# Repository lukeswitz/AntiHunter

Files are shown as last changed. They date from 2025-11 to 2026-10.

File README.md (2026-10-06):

<p align="center">
  AntiHunter Command Center Logo
</p>

<div align="center">





</br>






</div>

<div align="center">
  <h3 align="center">DIGI Detection Node Firmware</h3>
  <h4><a href="https://lectronz.com/stores/antihunter">Get one</a> • <a href="https://lukeswitz.github.io/AntiHunter/">Flash from your browser</a> • <a href="#quick-start">Quick start</a> • <a href="#hardware">DIY</a> • <a href="docs/README.md">Docs</a></h4>
  
  <strong>Companion C2: <a href="https://github.com/TheRealSirHaXalot/AntiHunter-Command-Control-PRO">Command Center</a></strong>

  
  
  [Website](https://rootdowndigital.com/antihunter)  • [Privacy Policy](https://rootdowndigital.com/privacy)

</div>

---

## What is AntiHunter?

***A digital and physical tripwire for your perimeter and RF environment. No subscription, data is yours.***

The name comes from counter-surveillance: phones, trackers, and drones give themselves away by transmitting, and AntiHunter listens for them. It doesn't jam or send attack frames.

Use it at home, on a fence line, at an event, or off the grid on battery and LoRa. It needs no internet, and scan results and detections save to its SD card. One node works on its own. Add more and they share alerts over the mesh, control all at once from the AHCC, and can locate a device together.

<p align="center">
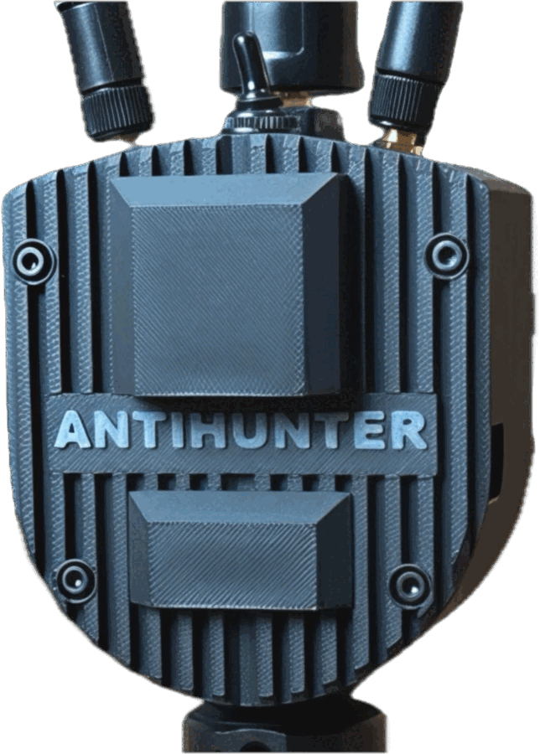
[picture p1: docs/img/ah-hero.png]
AntiHunter node
  
</p>

<p align="center"><i>Featured in Seeed Studio <a href="https://www.seeedstudio.com/blog/2026/01/29/best-xiao-projects/">Best 20 XIAO Projects in 2025</a>.</i></p>

> [!TIP]
> **New to AntiHunter?** [Start Here](docs/README.md) has setup order, decisions, troubleshooting, and every guide and manual.

---

## Table of Contents

1. [Quick start](#quick-start)
2. [What it detects](#what-it-detects)
3. [Using a node](#using-a-node)
4. [Mesh networking](#mesh-networking)
5. [Hardware](#hardware)
6. [Build & flash](#build--flash)
7. [Configuration](#configuration)
8. [System architecture](#system-architecture)
9. [Reference](#reference)
10. [Legal](#license)

---

## Quick start

> The **[Assembly Manual](hw/Prototype_STL_Files/Antihunter-DIGINODE-AssemblyManual.pdf)** covers the full build. The **[Operator's Guide](docs/AntiHunter-Operators-Guide.pdf)** walks through each step in more detail

**1. Attach all three antennas before powering on.**
- SMA or U.FL, see [how to attach depending on tier](#deployment-steps-by-tier)

**2. Flash AntiHunter.**
- Open the [Web Flasher](https://lukeswitz.github.io/AntiHunter/) in Chrome or Edge on a desktop.
- Pick **Full** or **Headless** ([which one?](#full-vs-headless)), pick **Stable** or **Beta**, plug in the ESP32-S3, and select **Connect & Flash**.

The flasher asks whether to erase the device first. Erase to clear saved settings. To flash from a terminal, see [Build & flash](#build--flash).

**3. Connect to the node.**
- Full: join the `Antihunter` Wi-Fi network (password `antihunt3r123`) and open http://192.168.4.1.
- Headless: open a serial monitor at 115200 baud.

**4. Set up the Meshtastic radio.**
- Set the LoRa region, and check the serial settings. See [Radio setup](#radio-setup).

**5. Lock it down.**

- Change the AP name and password under RF Settings. Every unit ships with the same published defaults, so anyone can join an unchanged node.
- Set the node ID in the web UI, or with `CONFIG_NODEID` over mesh.
- On the radio, set the region and a new BLE pairing pin: `python3 scripts/meshtastic_config.py --region US --pin 481920` (use your region and your own 6-digit pin). Then in the Meshtastic app, under Channels, make your own encrypted channel primary and turn the public channel off.
- Set your erase key. Wipe is off until you do. See [Secure data destruction](#secure-data-destruction).
- For covert work, run Headless, which has no access point, and turn off the radio's screen, LED, and Bluetooth with the radio plugged in on its own USB: `python3 scripts/meshtastic_config.py --screen off --led off --ble off`
- Privacy Mode hides MACs, SSIDs, and GPS in the web UI only. Exported logs and SD files still contain them, and GPS coordinates identify places. Check files before posting them.
- Passive reception differs from interception, and the rules differ by country. Scan only where you have authority. See the [legal disclaimer](#legal-disclaimer).

**6. Run a scan.**
Pick a feature from [What it detects](#what-it-detects). Each one shows how to start it.

---

## What it detects

| Feature | What it does | Start it over mesh |
|---|---|---|
| [**Target scan**](#target-scan) | Alerts when the node hears a MAC, vendor prefix, or SSID on the watchlist | `SCAN_START:2:300` |
| [**Baseline anomaly**](#detection-baseline-anomaly) | Learns which devices are normally present, then reports new, gone, returning, and changed ones | `BASELINE_START:300` |
| [**Device discovery**](#recon-device-discovery) | Lists nearby access points and BLE devices with RSSI, channel, and name | `DEVICE_SCAN_START:2:300` |
| [**Probe request scanner**](#recon-probe-request-scanner) | Lists the network names Wi-Fi devices ask for | `PROBE_START:2:300` |
| [**Randomized MAC tracer**](#recon-randomized-mac-tracer-experimental) *(experimental)* | Groups a device's changing MACs into one identity | `RANDOMIZATION_START:2:300` |
| [**Drone Remote ID**](#recon-drone-remote-id) | Drone ID, position, flight data, and operator location | `DRONE_START:300` |
| [**Deauth detection**](#detection-deauth) | Logs deauth and disassociation frames and flags floods | `DEAUTH_START:300` |
| [**Sentinel**](#detection-sentinel-beta) *(Beta)* | Detects Wi-Fi attacks in progress and names the tool when it recognizes one | `SENTINEL_ON` |
| [**CSI motion**](#detection-csi-motion-beta) *(Beta)* | Detects movement from changes in Wi-Fi signals between nearby devices and the node | `CSI_MOTION_START:0:FOREVER` |
| [**Packet capture**](#capture-packet-capture) | Writes Wi-Fi or BLE to SD as a pcap that Wireshark opens | `PCAP_START:0:300:0` |
| [**Triangulation**](#locate-triangulation-experimental) *(experimental)* | Three or more nodes with a GPS fix estimate a device's location from RSSI | `TRIANGULATE_START:<MAC>:60` |
| [**Tamper response**](#field-controls) | Starts a scan, or wipes the node, when someone moves it | `VIBSCAN_SET` |
| [**Scheduling**](#field-controls) | Runs any Scan tab scan at a set time, once or repeating, up to 8 entries | `SCHED_ADD` |

Put `@ALL ` in front of a command for every node, or `@AH01 ` for one node. **(Beta)** features exist only in the Beta firmware. **(experimental)** features exist in every firmware but may give inaccurate results.

> [!NOTE]
> **Shared mesh parameters**
> - Mode: `0` Wi-Fi, `1` BLE, `2` both. Duration is in seconds. Add `:FOREVER` to run until `@ALL STOP`
> - RSSI floor: default −95 dBm, set with `@ALL CONFIG_RSSI:-80`. Baseline uses its own RSSI setting. Triangulation and packet capture ignore the floor
> - Channels: scans that hop use the channel list (`@ALL CONFIG_CHANNELS:1..11`). Drone detection stays on channel 6. Target scan on Full scans all channels

---

### Target scan

Keep a watchlist of MAC addresses (full or vendor prefix) and SSIDs. On each scan pass, the node checks what it heard against the list and alerts on a match, in the web UI and over the mesh.

<p align="center">
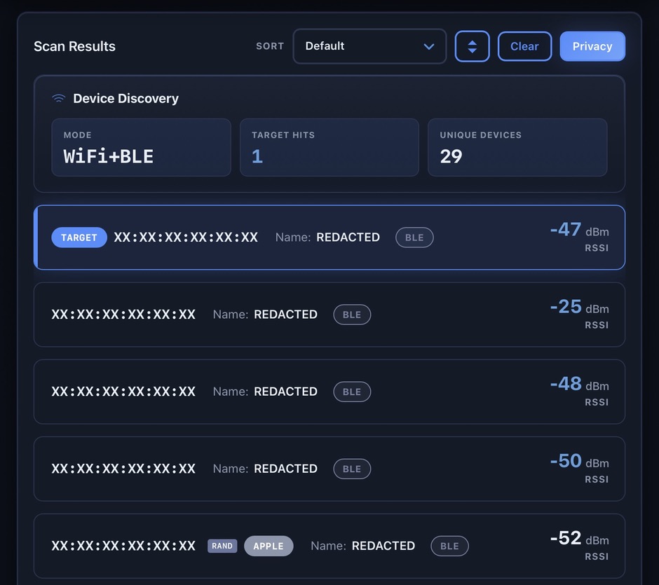
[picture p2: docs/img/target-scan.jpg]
Target Scan
  
</p>

**Start**
- Web UI: add entries under Targets, then Scan tab → Target Scan → **Start Scan**
- Mesh: `@ALL SCAN_START:2:300` scans Wi-Fi + BLE for 300 s
- Mesh: `@ALL CONFIG_TARGETS:AA:BB:CC:DD:EE:FF|T-00A3|MyNetwork` replaces the watchlist with those three entries

**Operational notes**
- Full matches access points (BSSID or SSID) from active Wi-Fi scans, and BLE devices. Headless also sniffs Wi-Fi frames while hopping channels
- It ignores devices on the [allowlist](#field-controls)
- Each hit is logged to SD with radio, MAC, RSSI, channel, name, and GPS
- Each target gets at most one mesh alert per 30 s, unless its RSSI changes by 5 dB or more or the node's GPS position moves

---

### Recon: Device discovery

Lists nearby Wi-Fi access points and BLE devices (up to 200 of each): MAC, SSID, signal strength, name, and channel.

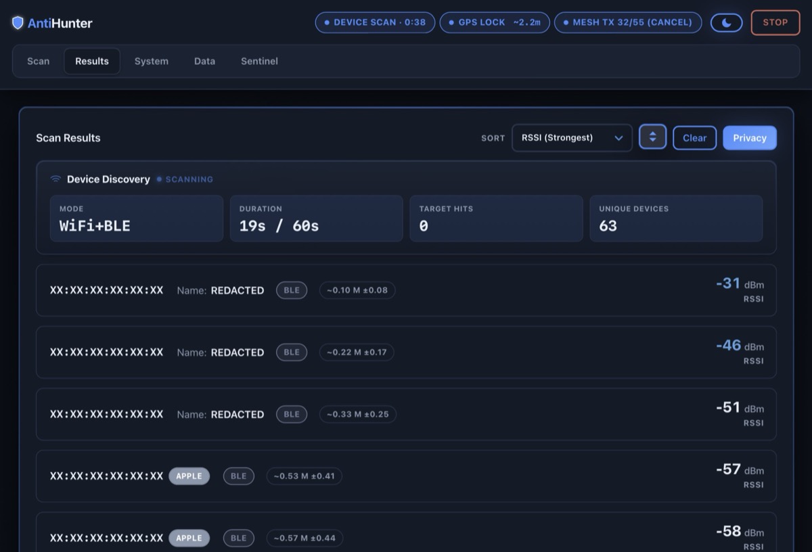
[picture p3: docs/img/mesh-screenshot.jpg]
Mesh scan results


**Start**
- Web UI: Scan tab → Device Discovery → **Start Scan**
- Mesh: `@ALL DEVICE_SCAN_START:2:300:+PROBE` scans Wi-Fi + BLE for 300 s and collects probe requests

**Operational notes**
- It finds access points with a periodic all-channel scan (set by Wi-Fi Scan Interval), and picks up more from beacons while hopping channels between scans
- Tick **Capture Probes** to collect probe requests at the same time. They go into the probe database with MAC, vendor, RSSI, SSIDs, and a randomized-MAC flag
- To skip MACs already sent over the mesh in the last N seconds, use `@ALL CONFIG_DEDUP_TTL:300` (see [Cross-scan dedup](#cross-scan-dedup))

---

### Recon: Probe request scanner

Wi-Fi devices send probe requests that name the networks they want to join. This scanner records the network names each device asks for.

<p align="center">
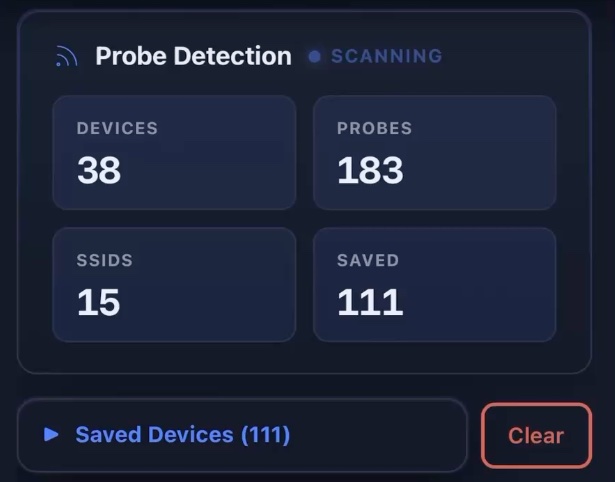
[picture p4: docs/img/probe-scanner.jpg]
Probe Request Scanner
  
</p>

**Start**
- Web UI: Scan tab → Probe Request Scanner → **Start Scan**
- Mesh: `@ALL PROBE_START:2:300:+ALL` runs for 300 s. Stop it with `@ALL PROBE_STOP`

**Operational notes**
- **Ghost SSIDs:** if the node hears no probe response for a network name, it marks the name with a `~` prefix
- **Frames to watchlist devices:** it also flags management frames (other than probes and beacons) addressed to a watchlist MAC
- `+ALL` sends every probe to the mesh. Without it, only watchlist hits go to the mesh. The node keeps every probe locally either way
- Vendor names come from a built-in list of the 400 largest IEEE-registered vendors. Randomized MACs are flagged
- BLE mode adds BLE devices to the list. BLE has no probe requests

---

### Recon: Randomized MAC tracer (experimental)

Modern phones change their MAC address to avoid tracking. The tracer scores how alike two MACs are. It compares MAC prefix, information elements and their order, timing, signal pattern, and sequence numbers. Close matches become one identity with a confidence score and an ID (`T-XXXX`) saved to SD.

<p align="center">
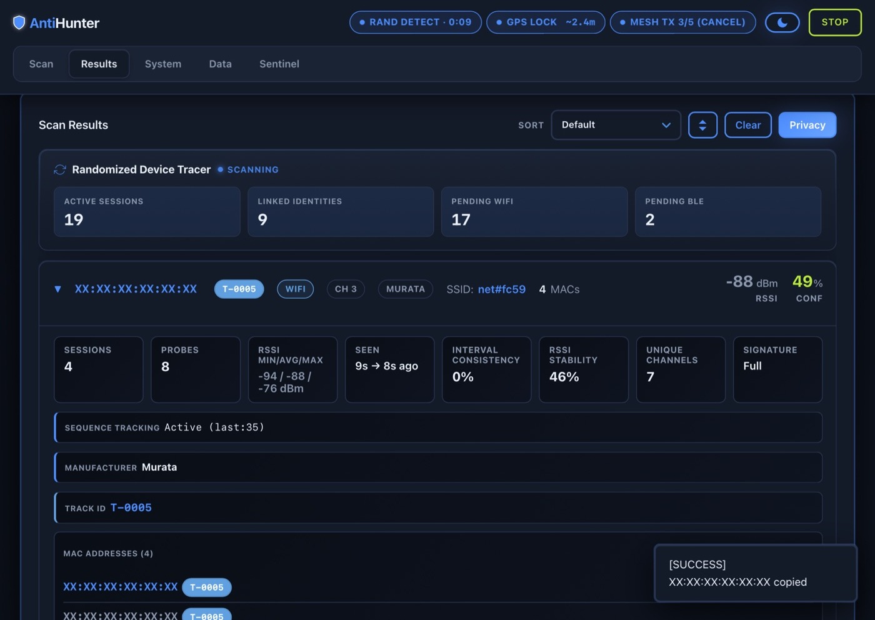
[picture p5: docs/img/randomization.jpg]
Randomized MAC Tracer
  
</p>

**Start**
- Web UI: Scan tab → Randomized MAC Tracer → **Start Scan**
- Mesh: `@ALL RANDOMIZATION_START:2:300` traces Wi-Fi + BLE for 300 s

**Operational notes**
- It tracks up to 256 devices at once. Past that, it drops the one not seen for longest
- It flags devices that also send from their real (global) MAC
- Press the Privacy button to hide MACs, GPS, and SSIDs before taking screenshots

---

### Recon: Drone Remote ID

Detects drones broadcasting Remote ID under the FAA and EASA rules, and reports drone ID, operator location, and flight data to the mesh and to `/drones.jsonl` on SD.

<p align="center">
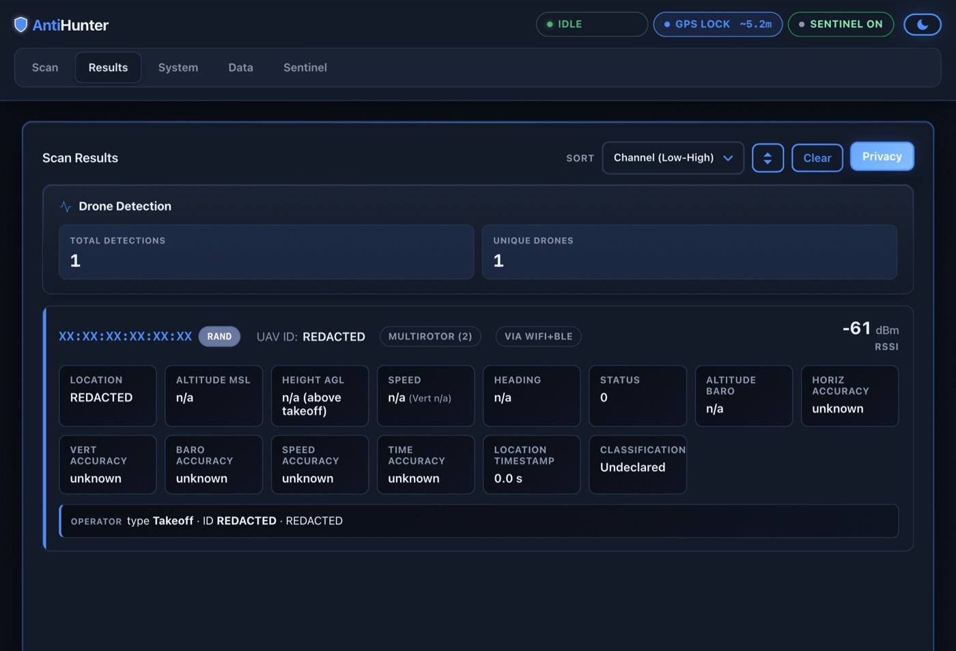
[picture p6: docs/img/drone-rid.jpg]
Drone RID Detection
  
</p>

**Start**
- Web UI: Scan tab → Drone RID Detection → **Start Scan**
- Mesh: `@ALL DRONE_START:300` watches for 300 s. `@ALL DRONE_START:0:FOREVER` runs until `@ALL STOP`

**Operational notes**
- Wi-Fi: ODID/ASTM F3411 in NAN action frames and beacons. The node stays on channel 6 during a drone scan
- BLE: legacy advertising, service UUID `0xFFFA`. BLE 5 long-range advertising isn't received
- It also reads French drone ID
- When a drone sends both a serial number and a CAA registration ID, the node reports the serial number

---

### Detection: Baseline anomaly

Learns which access points and BLE devices are normally present, then reports devices that are new, gone, back again, or whose signal changed by more than the RSSI variation setting (default 20 dB).

<p align="center">
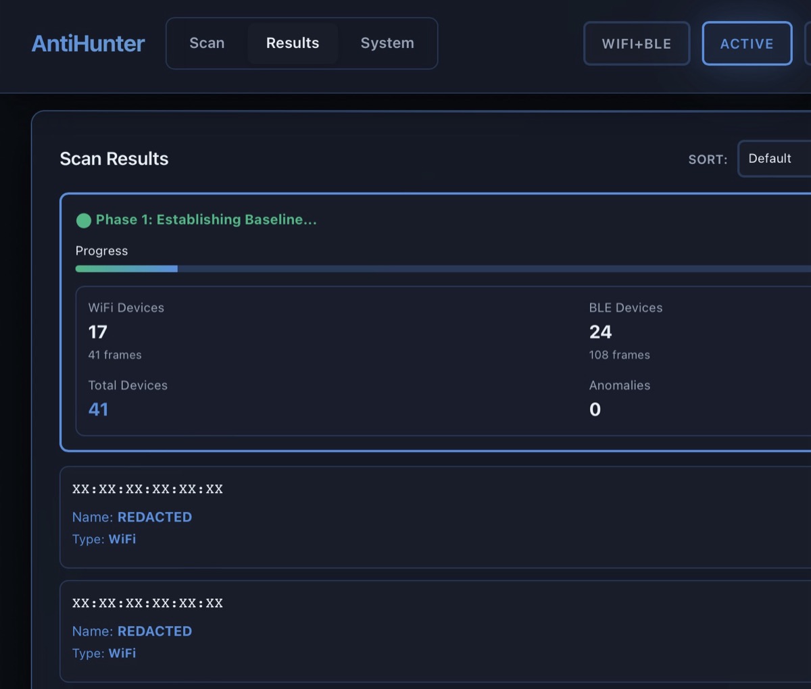
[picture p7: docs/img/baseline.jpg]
Baseline Anomaly Detection

</p>

**Start**
- Web UI: Scan tab → Baseline Anomaly Sniffer → pick the learning time (5, 10, or 15 min) → **Start Scan**
- Mesh: `@ALL BASELINE_START:300` monitors for 300 s after the learning phase. The learning time comes from the web UI setting (default 5 min)
- Check progress: `@ALL BASELINE_STATUS`

**Operational notes**
- **Watch for changes from now** - splits the learning phase into before and after a moment you pick. Send it while the node is still learning: press **Watch for changes from now** (Full), or send `@ALL BASELINE_WATCH`. The node replies `BASELINE_ACK:WATCHING`, or `BASELINE_ACK:NOT_RUNNING` if no baseline scan is running

  | Result | Meaning |
  |--------|---------|
  | New | Heard only after you pressed it |
  | Gone | Heard only before |
  | Moving closer / away | Heard both times, signal changed by 20 dB or more |

  Full shows it in Results. Headless prints the list to serial when the scan ends and sends `BASELINE_WATCH: New=<n> Gone=<n> Moved=<n> Both=<n>` over mesh
- With an SD card, the baseline survives a reboot. Recent devices stay in memory, and the node moves the rest to SD
- Baseline uses its own RSSI threshold (default −60 dBm), not the global RSSI floor

---

### Detection: Deauth

Watches for deauthentication and disassociation frames, which knock devices off Wi-Fi.

**Start**
- Web UI: Scan tab → Deauth Detection → **Start Scan**
- Mesh: `@ALL DEAUTH_START:300` watches for 300 s

**Operational notes**
- It alerts on any broadcast deauth, and on 10 deauths to one client within 10 s, tagged `[BROADCAST]` or `[TARGETED]`
- It flags a `DEAUTH_FLOOD` at 20 deauths from one source within 10 s
- Each alert shows the source and destination written in the frame, RSSI, channel, and reason code. An attacker can fake the source address

---

### Detection: Sentinel (Beta)

> [!IMPORTANT]
> To use Sentinel, flash the **Beta** firmware.

Once you start it, Sentinel listens for Wi-Fi attack frames in the background and pauses while another scan runs. It matches frame patterns and behavior, such as deauth floods, beacon spam, evil twin APs, PMKID requests, and someone knocking a client off to force a WPA handshake.

**Tools it names:** Marauder, MDK4, ESP Deauther, aireplay-ng, bettercap, hcxdumptool, Bruce, Pwnagotchi

<p align="center">
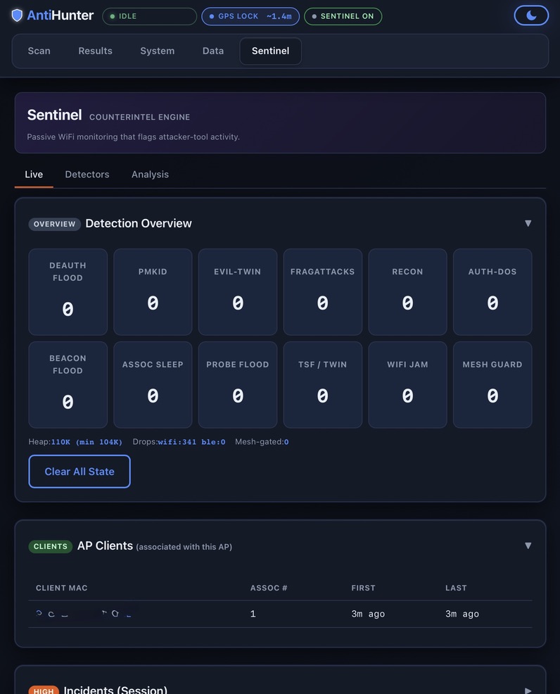
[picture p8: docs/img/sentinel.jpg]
Sentinel
  
</p>

**Start**
- Web UI: Sentinel tab → Start
- Mesh: `@ALL SENTINEL_ON` / `@ALL SENTINEL_OFF`
- Start at power-on: `@ALL SENTINEL_BOOT:1`, or set it in the Flasher or Configurator. Off by default

**Settings**
- Turn a detector group on or off: `@ALL GROUP:dos:on` (`dos`, `rogue`, `recon`, `physical`, `mesh`, `all`). Deauth, beacon flood, and auth flood detection are always on
- Hop channels or stay on one: `@ALL SENTINEL_MODE:scan` or `:defend`. Headless has no AP to stay on, so use `scan`
- Fine-tune: `@AH01 DETECT_CFG:{"pmkid":true}`
- The Web Flasher's **Sentinel & Detectors** section sets the same options at flash time. Anything left on *Default* keeps the firmware setting

**Operational notes**
- Sentinel writes each detection to serial and SD. With the mesh on and that detector's broadcast flag set, it also sends it to other nodes, rate-limited
- When Sentinel confirms an attack, it can start a follow-up: triangulate, packet capture, device discovery, probe sweep, or drone RID. They run one at a time, and detection pauses while they do
- Karma bait is the only detector that transmits. While on, it sends one bait probe request every 8 s, plus one when a suspect AP is first seen. Off by default. Turn it on with `GROUP:rogue:on`
- Per-detector logs on SD start fresh at each boot so counts begin at zero. The full history stays in `/incidents.jsonl`

<details>
<summary>Detectors, outputs, and test coverage</summary>

| Group | Detectors | How they're caught |
|---|---|---|
| **DoS** | Deauth flood, deauth forge, broadcast deauth, AP-targeted deauth, beacon flood, auth flood, assoc-sleep, SAE DoS | Fixed Marauder seqCtrl, reason 7 with duration 0x013A, sawtooth sequence numbers, alternating deauth/disassoc, and deauth rate. Impersonation bursts. 40+ distinct nearby BSSIDs beaconing within 10 s, plus known static beacon templates. Open-system auth flood. Assoc-req PM-bit floods. SAE commit floods (algo 3 / txn 1). Reasons 1/2/6/7 alone never alert. Reason 14, or reason 2 with fixed seqCtrl 0xFFF0, alerts on its own |
| **Rogue AP** | Evil-twin, OWE abuse, Karma / MANA | Another BSSID beaconing the node's own SSID. A new-vendor BSSID reusing a learned SSID. TSF restarts and known beacon-forgery templates. OWE-transition downgrade. Bait probe answered by an AP that never beacons that SSID |
| **Recon** | PMKID harvest, probe flood, forced handshake | Orphaned-M1 / KDE PMKID solicitation. Probes with fixed seq 0x0001, 40+ distinct MACs probing one SSID within 5 s, or probe-rate floods. A WPA 4-way handshake completed right after a deauth burst, meaning someone knocked a client off to capture it. Sentinel ignores handshakes without a deauth burst |
| **Physical** | FragAttacks, TSF / multi-channel twin, Wi-Fi interference | Fragment packet-number gaps and mixed encrypted/plaintext fragments (CVE-2020-26146/26147, off by default). Same BSSID on ≥2 channels within 5s. Per-channel PDR-vs-RSSI collapse (CRC-fail flood) |
| **Mesh disruption** | Self-spoof, channel flood, command audit | Own node-id seen inbound. Inbound rate DoS. Logs every inbound mesh command (lines starting with `@`) with the radio id that sent it, even when this detector is off. The log is an **audit trail**, not an alert: on a shared channel an injected command looks like a normal one, so the node records the source |

- **Phone hotspots:** the crypto and beacon detectors skip locally administered BSSIDs, which phone hotspots use. Flood detectors don't, because real floods spoof them
- **Output:** `[DETECT]` serial lines, `.jsonl` files on SD (some detectors share a file), `/incidents.jsonl`, and a mesh broadcast so other nodes can confirm
- **AP clients:** devices that join the node's own AP, with MAC, join count, and first/last seen. *AP Clients* panel, `GET /api/apclients.json`
- **Mesh command audit:** every incoming command and its sender, including commands meant for other nodes. *Mesh Commands* panel, `GET /api/mesh_cmd.jsonl`
- **Mesh labels:** the [mesh command reference](docs/mesh-commands.md) lists the labels Sentinel sends, for log parsers and C2, under *Sentinel label reference*
- **Tested against:** airgeddon, aireplay-ng, bettercap, wifite, mdk4, angryoxide, eaphammer, hostapd-mana, wifipumpkin3, hcxdumptool, purpose-built test scripts, and common consumer ESP32 attack firmware
- **Confirmed on hardware** against those tools: deauth (flood/forge/AP-targeted), beacon flood, auth flood, assoc-sleep, SAE DoS, karma, evil-twin, probe flood, forced handshake
- **Experimental:** OWE abuse, PMKID harvest, FragAttacks, TSF multi-channel twin, Wi-Fi interference, mesh disruption
- **Behavioral fallbacks** (still work when a tool changes its frame template): SSID-rotate forge, behavioral probe-flood, EAPOL-capture bait, broadcast deauth bursts

</details>

---

### Detection: CSI motion (Beta)

Tells you when something moves nearby, even through walls. The web UI marks it as indoor only. It triggers on changes in the Wi-Fi signal, not on presence.

<p align="center">
  CSI Motion
</p>

**How it works.** Wi-Fi signals bounce around a room. When a person moves, the bounces change. The node listens to the Wi-Fi routers around it, plus phones if you include randomized-MAC devices. It alerts when their signals change together, as set by the sensitivity below. It needs ongoing Wi-Fi traffic to measure.

**Start**
- Web UI: Scan tab → CSI Motion Detection → **Start Scan**
- Mesh: `@ALL CSI_MOTION_START:0:FOREVER`. The [mesh command reference](docs/mesh-commands.md) lists the CSI commands

**Pick a sensitivity**
- **Low** (default): fewest false alarms. Two devices must see the movement.
- **Medium**: more sensitive. Two devices, or one device seeing a change 4× the trigger.
- **High**: most sensitive. Same as Medium with a lower trigger and a shorter wait. Expect false alarms.

<details>
<summary>All CSI settings (Scan tab → CSI Motion Detection)</summary>

**Sensitivity** and the mesh alert limit sit at the top. The rest are under **Advanced**.

| Setting | What it means | Default |
|---|---|---|
| Min. seconds between mesh motion alerts | Wait at least this long between motion alerts sent over mesh. 0 sends every alert | 0 |
| Channel | Wi-Fi channel to listen on. 0 picks one automatically | 0 |
| Movement needed before alerting | Seconds of movement within the last minute before an alert | 8 s |
| Stillness before all-clear | Seconds a single device's signal must stay quiet before it stops counting as moving. The room all-clear comes later | 5 s |
| Devices that must agree | How many devices must see the movement at the same time | 2 |
| Trigger level | Lower catches smaller movement | set by sensitivity |
| Packets in a row before alerting | Consecutive readings above the trigger before a device counts as moving | 3 |
| Listen only, never transmit | The node never sends probes. Turn off only if it sees too little Wi-Fi | On |
| Include randomized-MAC devices | Also listen to phones and watches, not just routers | On |

</details>

**False alarms with nobody there?** Turn on **Per-packet score to serial**, watch the `sig` numbers while the room is empty, and set Trigger level just above the highest one.

> [!WARNING]
> **This mode can transmit if you let it.** Off by default. If you turn off **Listen only, never transmit**, the node sends Wi-Fi probe requests when it hears too little traffic to measure. Anyone nearby can see them. Check local rules before turning it on.

---

### Capture: Packet capture

Records raw traffic to SD as a standard pcap that Wireshark opens.

<p align="center">
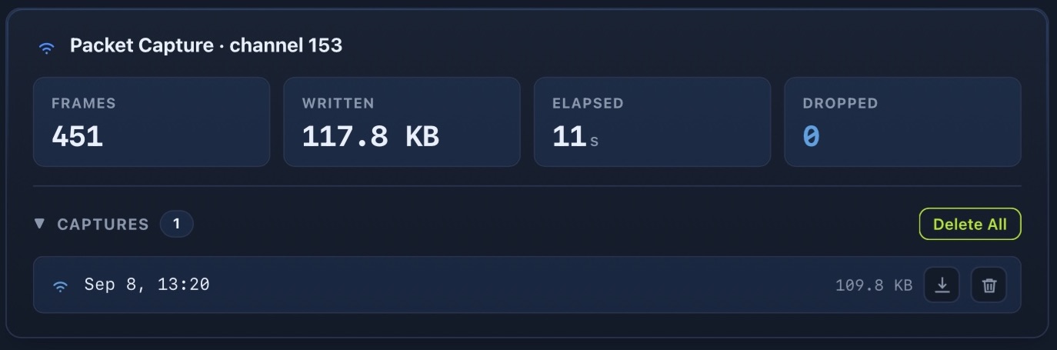
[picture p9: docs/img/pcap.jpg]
Packet capture
  
</p>

**Start**
- Web UI: Scan tab → Packet Capture → **Start Capture**
- Mesh: `@ALL PCAP_START:0:300:0:CH1,6,11` captures Wi-Fi for 300 s on 2.4 GHz channels 1, 6, and 11
- Fields, in order: radio (`0` Wi-Fi, `1` BLE), duration in seconds (required, no `FOREVER`), band (`0` 2.4 GHz, `1` 5 GHz, `2` both; 5 GHz on C5 only), and an optional `:CH` list
- Stop: `@ALL PCAP_STOP` stops the capture and any other running scan. File size cap: `@ALL PCAP_LIMITS:150` (8-300 MB)

**Operational notes**
- Wi-Fi frames carry a radiotap header with channel and RSSI, plus the rate on legacy frames and the MCS index on 802.11n frames. Both bands on C5
- BLE saves the raw HCI events the Bluetooth controller reports, link type 187. HCI has no RF channel field, so the capture shows no channel
- It sweeps the RF Settings channels, or a channel list and dwell set under Advanced. There's an optional management-frames-only filter
- The Scan tab lists captures to download or delete. You can't delete the file in progress
- A Sentinel attack response can also start a capture. The node prunes automatic (`auto_`) captures to stay under a size budget and keep free space. It never prunes manual ones

> [!WARNING]
> Stop a capture before cutting power. The node flushes the file as it writes, but cutting power mid-write can leave it truncated.

---

### Locate: Triangulation (experimental)

Nodes listen for the same device at once. Each records RSSI and its own GPS position, and the mesh combines the results (weighted trilateration with Kalman filtering) into a location estimate. A position needs at least three nodes with a GPS fix. With two, the results only compare GPS distance with RSSI.

**Start**
- Mesh: `@AH01 TRIANGULATE_START:AA:BB:CC:DD:EE:FF:60`. AH01 coordinates a 60 s run for that MAC with the other nodes on the mesh
- Optional `:rfEnv` picks the environment from the table below (`0` Open Sky to `4` Industrial). Optional `:wifiPwr:blePwr` are distance multipliers (0.1 to 5.0)
- Result: `@AH01 TRIANGULATE_RESULTS`. Stop: `@ALL TRIANGULATE_STOP`

**Operational notes**
- It reports GPS coordinates, confidence, estimated error in meters, and average HDOP, and sends a Google Maps link over the mesh
- It ignores readings of −95 dBm or weaker

<details>
<summary>RF environment calibration</summary>

Path loss model: `distance = 10^((RSSI0 - RSSI) / (10 * n))`

| Environment | Wi-Fi n | BLE n | Wi-Fi RSSI0 | BLE RSSI0 | Use Case |
|---|---|---|---|---|---|
| Open Sky | 2.0 | 2.0 | -23 dBm | -60 dBm | Clear LOS, minimal obstruction |
| Suburban | 2.7 | 2.5 | -24 dBm | -62 dBm | Light foliage, scattered buildings |
| Indoor | 3.2 | 2.9 | -25 dBm | -65 dBm | Typical indoor, some walls |
| Indoor Dense | 4.0 | 3.5 | -27 dBm | -69 dBm | Office spaces, many partitions |
| Industrial | 4.8 | 4.0 | -30 dBm | -73 dBm | Heavy obstruction, machinery |

</details>

---

## Using a node

### Full vs Headless

Both builds share the detectors and scan engine. Full adds a Wi-Fi access point with the web UI and [API](docs/api-reference.md). Headless never starts the access point.

| | Full | Headless |
|---|---|---|
| Control | Web UI and API over its own AP, plus serial and mesh | Serial and mesh |
| Wi-Fi discovery | Active all-channel sweep plus promiscuous capture on Device Scan, Target Scan, Baseline, and Triangulation | Same sweep, without Full's handling for clients joined to its AP |
| Results | Results tab in the browser, saved to `/last_results.txt` on SD | `/last_results.txt` on SD |
| Device database | `/devicedb.jsonl` | `/devicedb.jsonl` on Beta, not in Stable |
| Scheduling | Scan tab and `SCHED_ADD` | Not available |
| Fleet roster | Fleet card on the System tab, and `/api/mesh` | Not tracked |
| RF footprint | AP beacons, unless hidden-network is on | No AP |

### Web UI

The web UI has four tabs: **Scan**, **Results**, **System**, and **Data** (plus **Sentinel** on Beta). On the Scan tab, pick the scan, the radio, and how long, then select **Start Scan**. Results show on the Results tab and save to SD. **Schedule this scan** runs the current scan at a set time.

<p align="center">
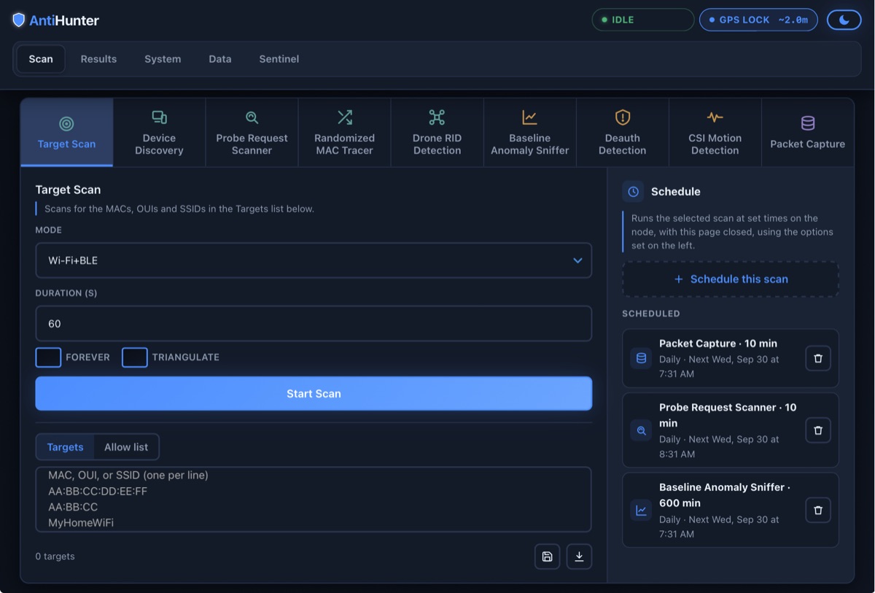
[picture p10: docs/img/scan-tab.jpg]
AntiHunter Scan tab

</p>

The **System** tab holds the node-wide settings. Its **Fleet** card lists the nodes and mesh radios this node has heard. The **Data** tab is the Data Explorer for findings, device logs, and scan data.

<details>
<summary>System tab cards and screenshots</summary>

<p align="center">
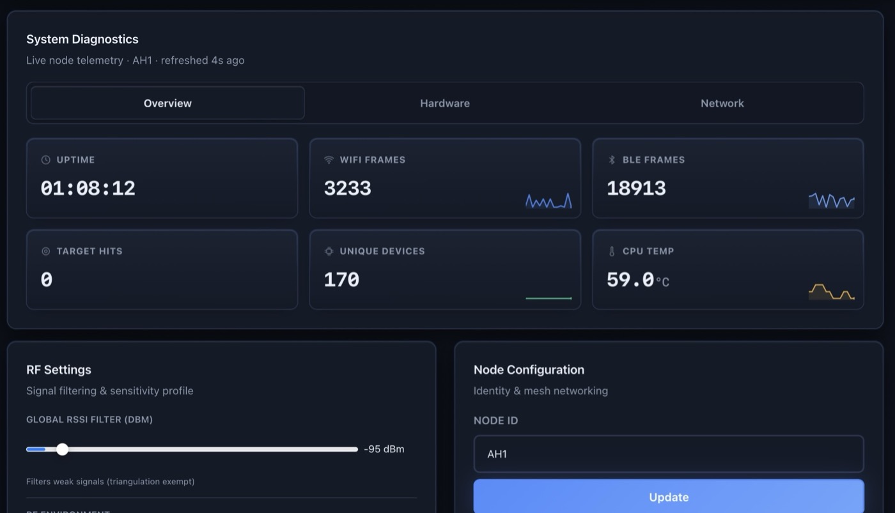
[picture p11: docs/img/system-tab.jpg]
System tab
  
</p>

| Card | What it holds |
|---|---|
| **System Diagnostics** | Three subtabs, all fed from `GET /diag`. **Overview** - uptime, Wi-Fi and BLE frame counts, target hits, unique devices, CPU temperature. **Hardware** - last reset and previous uptime, results restored, free and minimum-free internal heap, scan stack headroom, SD card, GPS, RTC, and vibration sensor. **Network** - AP address, mesh state, Wi-Fi channels |
| **Fleet** | Live roster of nodes and radios with mode, uptime, temperature, hits, and GPS. Ping the fleet or clear the list |
| **RF Settings** | Global RSSI filter and RF environment (Open Sky to Industrial, used for distance estimates). Scan preset (Relaxed, Balanced, Aggressive, Custom). Wi-Fi channel dwell, scan interval, and channel list. BLE scan duration and interval. Also holds the **Wi-Fi Access Point** section: SSID, password, WPA2/WPA3 or WPA2 only, and hidden network |
| **Node Configuration** | Node ID, mesh on/off, status heartbeat, mesh send interval, mesh dedup TTL, and session dedup |
| **Sensor Alerts** | Vibration sensing and what it triggers |
| **Secure Data Destruction** | Erase key, setup and erase delays, vibration count and window, cooldown |
| **Factory Wipe** | Clears settings and stored data back to defaults |
| **Battery Saver Mode** | Stops scans and turns BLE off, drops the CPU to 80 MHz with light sleep, and polls GPS once a minute. Mesh commands, heartbeats, and vibration alerts keep working |
| **Accent Colors** | Recolors the destructive controls and Sentinel banners. Stored in the browser |

Settings

<p align="center">
 Fleet viewer
</p>

</details>

### Field controls

- **Allowlist** - devices that Target Scan and Baseline ignore. Scan tab → **Allow list** tab next to Targets, one MAC per line.
- **Privacy Mode** - the Privacy button (Results, System, and Data tabs) hides MACs, GPS, and SSIDs in the web UI for screenshots. Exported files keep them.
- **Vibration trigger** - starts a scan when the node is moved. Full: System tab → Sensor Alerts. Both builds, over mesh, `VIBSCAN_SET:<on>:<scan>:<secs>:<cooldown>`:

  | Part | Value |
  |------|-------|
  | on | `1` on, `0` off |
  | scan | `1` device discovery, `2` probe, `3` randomized MAC tracer, `4` target, `5` drone, `6` deauth, `7` baseline, `8` packet capture |
  | secs | Scan length in seconds. `0` runs until `STOP` |
  | cooldown | Seconds to wait before the next trigger, 5-86400 |

  Examples:
  - `@AH01 VIBSCAN_SET:1:2:60:300` - probe scan for 60 s when moved, then at most once per 5 min
  - `@AH01 VIBSCAN_SET:0:0:0` - turns it off
- **Scheduled scans** - Full: Scan tab → **Schedule this scan**. Both builds, over mesh, `SCHED_ADD:<start>|<repeat>|<scan>|<options>`:

  | Part | Value |
  |------|-------|
  | start | Node local time, `YYYY-MM-DDTHH:MM` |
  | repeat | Seconds between runs. `0` = once, `86400` = daily. Minimum `600` |
  | scan | `/scan` (list scan), `/sniffer` (device discovery), `/drone` |
  | options | `secs=<duration>`, plus `mode=0` Wi-Fi, `1` BLE, `2` both for `/scan` |

  Examples:
  - `@AH01 SCHED_ADD:2026-10-07T21:00|86400|/scan|mode=2&secs=600` - Wi-Fi + BLE list scan, 10 min, daily at 21:00
  - `@AH01 SCHED_ADD:2026-10-07T06:00|0|/drone|secs=300` - drone scan once, 5 min
  - `@AH01 SCHED_LIST` - replies with the count, prints entries to serial
  - `@AH01 SCHED_DEL:1` - deletes entry 1

  Headless runs entries only once its clock is set, from GPS or `SETTIME:<unix seconds>` on USB serial.
- **Battery Saver** - stops Wi-Fi/BLE scanning, drops the CPU to 80 MHz, enables light sleep, and polls GPS once a minute. The mesh stays connected and sends a heartbeat. `@AH01 BATTERY_SAVER_START:10` starts it with a heartbeat every 10 min (1-30), `@AH01 BATTERY_SAVER_STOP` ends it.
- **Hidden SoftAP** - the access point stops broadcasting its name. It doesn't keep anyone out. System → RF Settings → Wi-Fi Access Point → **Hidden network**.
- **SD Repair** - lets the node rebuild an SD card it can't mount. Off by default, and rebuilding erases the card. System tab, or over mesh: `@AH01 SD_REPAIR:ON`, `:OFF`, or `:NOW` to rebuild immediately.

The [mesh command reference](docs/mesh-commands.md) lists every parameter.

### Secure data destruction

Wipe the node's data if someone moves it, or on command.

Wipe is off until you set your own erase key (8+ characters, no `:`).

**Set your key**
- Full: System → Secure Data Destruction. The current key is your AP password (change the default first). Or over mesh: `@AH01 CONFIG_ERASE_PSK:<new key>:<AP password>`
- Headless: the **Erase key** field in the web flasher

**Wipe**
- Web UI: enter your key, press **WIPE NOW**
- Mesh: `@AH01 ERASE_FORCE:<your key>`

**Change your key:** `@AH01 CONFIG_ERASE_PSK:<new key>:<current key>`

5 wrong keys lock erase commands for 10 minutes. The key travels over your mesh channel, so use your own encrypted channel.

- **Auto-erase on tamper:** off by default. After the setup delay, **Vibrations required** vibrations within the **Detection window** start the erase countdown. Cancel with `@AH01 ERASE_CANCEL:<your key>`
- **Decoy file:** after the wipe, the node erases its settings and SD files, then writes `/weather-air-feed.txt` with a weather-monitor error message

> [!WARNING]
> A wipe is permanent. You can't undo it.

<details>
<summary>Auto-erase settings</summary>

| Parameter | Range | Description |
|---|---|---|
| Setup delay | 30s - 10min | Grace period before auto-erase activates |
| Erase delay | 10-300s | Countdown before destruction |
| Cooldown period | 1-60min in the web UI, 5-60min over mesh | Shortest time between tamper attempts |
| Vibrations required | 2-5 | Vibrations needed to start the countdown |
| Detection window | 5-60s in the web UI, 10-60s over mesh | Time window for counting vibrations |

1. Turn on auto-erase in the web UI with a setup delay
2. Place the node and leave during the setup delay
3. Watch the mesh for tamper alerts

</details>

---

## Mesh networking

The mesh is optional. A single node works fully on its own. With a mesh, you control nodes by sending text messages from any Meshtastic app on the node's channel:

- `@ALL COMMAND` goes to every node, `@AH01 COMMAND` to one. Node IDs are 2-5 letters or digits
- Replies and alerts come back on the same channel, public or encrypted
- Alerts go out at most one per send interval (default 3 s, set under Node Configuration). Device lists go out every 2.2 s. Triangulation messages skip the interval
- The node strips emoji and non-ASCII from sender names and still runs the command. It ignores a radio whose short name matches its own node ID as an echo, so keep them different

The [mesh command reference](docs/mesh-commands.md) lists the commands, parameters, and alert formats.

### Radio setup

The radio needs four settings: **Serial** module enabled, mode **TEXTMSG**, baud **115200**, and the RX/TX pins for your board - `19 RX / 20 TX` on Heltec V3, `10 RX / 9 TX` on T114. It also needs a LoRa region. With no region it receives but never transmits.

Soldered Core and Assembled radios come on the latest stable Meshtastic with the serial settings done, screen off after 1s, LED off, and Bluetooth on with the default pin. The region ships UNSET and the channel ships as the public default, so set those yourself. Bare PCB and Parts Kit builds flash stable Meshtastic and set everything.

Pick one way:

- **Phone:** pair the radio in the [Meshtastic app](https://meshtastic.org/docs/software/), set Module Settings → Serial, then LoRa → Region
- **Browser:** the [Meshtastic web client](https://meshtastic.org/docs/software/) over USB from Chrome or Edge
- **Script:** plug in the radio on its own USB and run:

```bash
pip3 install 'meshtastic[cli]' pyserial
python3 scripts/meshtastic_config.py
```

With no arguments the script prints the current settings and opens a menu. With flags, it applies all of them in one call, then reads the radio back and prints the settings before and after.

<details>
<summary>Script options and examples</summary>

```
options:
  --port PORT           serial port (auto-detected if omitted)
  --board {heltec-v3,t114}
                        board type, sets the serial-module pins (default heltec-v3)
  --screen on|off|SECS  'off' blanks after 1s, 'on' stays lit, or give seconds
  --led {on,off}        status LED heartbeat
  --ble {on,off}        Bluetooth on or off
  --pin NNNNNN|none|random
                        BLE pairing: 6-digit fixed pin, 'none', or 'random'
  --serial {on,off}     AntiHunter serial module (TEXTMSG, 115200, board pins)
  --region REGION       LoRa region, e.g. US. UNSET means receive only
```

```bash
python3 scripts/meshtastic_config.py                     # print current settings
python3 scripts/meshtastic_config.py --serial on         # node link, pins per --board
python3 scripts/meshtastic_config.py --region US         # UNSET = RX only, no TX
python3 scripts/meshtastic_config.py --pin 481920 --screen off --led off
python3 scripts/meshtastic_config.py --board t114 --serial on --ble off
```

</details>

### Control from a Meshtastic client

Commands and alerts are ordinary Meshtastic text messages, so anything that reaches the radio reaches the node:

- **Meshtastic app** - pair [any client](https://meshtastic.org/docs/software/) over Bluetooth, Wi-Fi, or USB and send `@node COMMAND` from anywhere in mesh range. You need no AP and no Command Center. [Quick chat](https://meshtastic.org/docs/software/android/user/messages-and-channels/) puts your usual commands on a button.
- **TAK / ATAK** - set the radio's role to `TAK`, install the [Meshtastic ATAK plugin](https://meshtastic.org/docs/software/integrations/integrations-atak-plugin/) for your ATAK version, and leave the Meshtastic app running. CoT then travels over the mesh, and node alerts still arrive as text. `TAK_TRACKER` sends the radio's own position without ATAK running.
- **MQTT** - a Meshtastic [MQTT gateway node](https://meshtastic.org/docs/software/integrations/mqtt/) forwards mesh traffic to a broker for logging, Home Assistant, or Node-RED.

### Reaching a node you cannot hear

You don't need line of sight to every node. Nodes between you and it relay for you - [3 hops by default, 7 max](https://meshtastic.org/docs/configuration/radio/lora/).

A standalone Meshtastic radio in the `ROUTER` or `REPEATER` [role](https://meshtastic.org/docs/configuration/radio/device/) extends range further. AntiHunter radios stay on the default `CLIENT` role.

### Cross-scan dedup

Repeated scans of the same place would resend the same devices over the mesh. To save airtime, the node skips `DEVICE:` messages for a MAC it already sent within a set time. The default is 5 minutes. Change it with `@ALL CONFIG_DEDUP_TTL:N` (seconds, `0` turns it off).

<details>
<summary>Dedup details</summary>

| Setting | Effect |
|---|---|
| `meshDedupTtl = 0` (off) | Every scan sends every device |
| `meshDedupTtl = 300` (5 min, default) | Skips a MAC sent in the last 5 min |
| `meshDedupTtl = 3600` (1 hr max) | Sends each MAC at most once an hour |

Dedup applies only to the `DEVICE:` rows of Device discovery. The node always sends triangulation (`T_F:/T_C:/T_D:`), anomaly alerts (`ANOMALY:`, `DEVICE_DISAPPEARED:`), drone alerts (`DRONE:`, `DRONE_LOST:`), attack alerts (`DEAUTH_FLOOD:`, `ATTACK:`), summaries (`SCAN_DONE:`, `DEAUTH_DONE:`, `BASELINE_DONE:`), and identities (`IDENTITY:`).

`SCAN_DONE` reports `U` (unique MACs seen), `TX` (MACs sent this scan), and `DUP` (MACs skipped by dedup in the final pass).

Set it in the web UI (System tab → Node Configuration → Mesh Dedup TTL, shown once mesh is on), with `POST /mesh-dedup-ttl` and form field `ttl=N`, or with `@ALL CONFIG_DEDUP_TTL:N`. `POST /mesh-dedup-clear` clears the cache so the node sends every MAC again.

</details>

<details>
<summary>How mesh sending works</summary>

Scans only queue messages and finish immediately. A background task (`meshTxTask`) sends them through a token-bucket rate limiter (`SerialRateLimiter`: 1000-byte burst, refilled at 400 B/s), and sends device rows one frame every 2.2 s. Three priority queues hold 256 messages - CTRL 16, EVENT 32, BULK 208 - sent in that order, so a `STOP` never waits behind a device list. The node packs device rows into frames up to 230 B, under Meshtastic's 237 B limit.

- A new scan never waits for the last scan's messages to finish sending
- `STOP` (web or mesh) clears the queue
- The header badge `Mesh TX K/N` shows sending progress and hides when the queue empties

</details>

---

## Hardware

Buy a node from the [store](https://lectronz.com/stores/antihunter), or build your own from the parts below.

AntiHunter hardware

> [!IMPORTANT]
> Use a regulated 5V power supply. Unregulated batteries cause voltage instability. A 2A fast-blow inline fuse on the battery line adds protection.

### Deployment steps by tier

No tier comes with AntiHunter firmware installed. That's for integrity and regulatory reasons. You flash it yourself (Quick start, step 2).

| Tier | What ships | What you supply |
|---|---|---|
| **Bare PCB** ([note](docs/note-tier4-bare-pcb.pdf)) | One unpopulated 82mm board | Everything: source the [BOM](https://github.com/lukeswitz/AntiHunter/blob/beta/hw/Prototype_STL_Files/BOM-Links.md), solder per the [assembly manual](https://github.com/lukeswitz/AntiHunter/blob/main/hw/Prototype_STL_Files/Antihunter-DIGINODE-AssemblyManual.pdf), flash and configure Meshtastic on the radio, fit a FAT32 SD card |
| **Soldered Core PCB** ([note](docs/note-tier3-populated-pcb.pdf)) | A fully populated PCB: XIAO ESP32-S3, Heltec LoRa radio, GPS, RTC, vibration sensor, SD reader, 8GB card fitted, radio flashed and serial-configured. Factory U.FL whip antennas only | Optional: enclosure, regulated 5V power, external antennas |
| **Parts Kit** ([note](docs/note-tier2-parts-kit.pdf)) | Every BOM part except the GPS antenna and 18650 cells, loose. PCB, modules, 8GB card, enclosure, and TPU seals. 6dBi 2.4GHz and 6dBi LoRa antennas, U.FL→SMA pigtails, and bulkheads. Fan, thermal switch, power switch, waterproof USB-C panel jack, UPS board, and fasteners. Nothing soldered, nothing flashed | Soldering and assembly per the manual, Meshtastic on the radio, two 18650 cells, active GPS antenna |
| **Assembled** ([note](docs/note-tier1-assembled.pdf)) | Built, sealed, and bench-tested. 8GB card fitted, GPS helix antenna, radio flashed and serial-configured | Two 18650 cells |

### Core components

- **Seeed XIAO ESP32-S3** (at least 8MB flash), or **XIAO ESP32-C5** for 2.4 + 5 GHz on the same board - [C5 page](docs/ESP32-C5.md) (testing)
- **Meshtastic board**: Heltec v3.2 (recommended) or T114. Alternatives in [discussions](https://github.com/lukeswitz/AntiHunter/discussions)
- **GPS, SD card, vibration, and RTC modules**

### Assembling the PCB

- [Operator's Guide](https://github.com/lukeswitz/AntiHunter/blob/main/docs/AntiHunter-Operators-Guide.pdf) - unboxing, antennas, flashing, mesh setup, deployment
- Illustrated [assembly manual](https://github.com/lukeswitz/AntiHunter/blob/main/hw/Prototype_STL_Files/Antihunter-DIGINODE-AssemblyManual.pdf)
- PCB [welcome letter](https://github.com/lukeswitz/AntiHunter/blob/beta/hw/Prototype_STL_Files/ahwelcome.txt)
- BOM parts [links & images](https://github.com/lukeswitz/AntiHunter/blob/beta/hw/Prototype_STL_Files/BOM-Links.md)

<details>
<summary>Bill of Materials</summary>

**Core components**
- 1 × DIGI PCB (82mm)
- 1 × Seeed Studio XIAO ESP32-S3
- 1 × Heltec Wi-Fi LoRa 32 V3.2 (T114 also works, V3.2 preferred)
- 1 × ATGM336H GPS Module
- 1 × Micro SD SDHC TF Card Adapter Reader Module
- 1 × SD Card (FAT32, 8GB shipped with every built tier, 32GB+ not recommended)
- 1 × SW-420 Vibration Sensor
- 1 × DS3231 Real Time Clock Module

**Connectors and fasteners**
- 5 × JST 2.54 2-Pin Terminals
- 10 × M3 Mounting Inserts
- 4 × M2 Mounting Inserts (power board)
- 2 × M3 × 15mm Brass Standoffs
- 1 × 1/4" Tripod Insert
- 2 × JST Power Male Cable (switch, power board)
- 8 × M3 × 4-6mm Flat Top Screws (for enclosure lids, max 6mm heads)
- 6 × M3 × 4-6mm Screws (for PCB and front/rear covers)
- 4 × M2 × 4-6mm Screws (for power board, or M3 × 4-6mm straight into the plastic without inserts)
- 2-4 × M2.5 13-15mm Screws (for fan)

**Antennas and cabling**
- 3 × U.FL to SMA Pigtail Cable (SMA bulkhead, 10cm)
- 1 × 6dBi Antenna 2.4GHz (Wi-Fi/BLE)
- 1 × 6dBi Antenna LoRa (by region: 868MHz EU, 915MHz US, 923MHz Asia)
- 1 × Active GPS Antenna (L1, SMA)

**Power and thermal**
- 1 × 30mm 5V Fan (7-10mm), JST 2.54
- 1 × 3-Pin Mini On/Off Switch
- 1 × KSD9700 Normally Open Thermal Wire Sensor (30-40C)
- 1 × Type-C Female Chassis Jack, waterproof (2-pin, 22 AWG leads, 14mm panel nut, dust cap)
- 1 × Type-C 15W 3A 5V Fast Charge UPS Power Supply
  (2S 18650 Charger Module DC-DC Step Up Booster Converter, 88 × 41 × 22mm)
- 2 × 18650 cells, protected flat-top (no tier includes them)

**Enclosure**
- 1 × Weatherproof Enclosure (3D printable)
  - STL files: [hw folder](https://github.com/lukeswitz/AntiHunter/tree/main/hw/Prototype_STL_Files)
- 1 × TPU Seal Kit (housing, USB-C, GPS antenna)

**Fan notes**
- The sticker side isn't always the exhaust side. Run the fan for a second and feel which way it blows before you screw it down. Assembled units ship with the fan set to exhaust.
- Shorting the two THERMO pins bypasses the thermal switch and runs the fan whenever the node has power.

</details>

<details>
<summary>Pinout reference</summary>

XIAO ESP32S3 [Pin Diagram](https://camo.githubusercontent.com/29816f5888cbba2564bd0e0add96cd723a730cb65c81e48aa891f0f9c20471cd/68747470733a2f2f66696c65732e736565656473747564696f2e636f6d2f77696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)

> Pin assignments may change. Check them against your board revision.

| Function | GPIO | Description |
|---|---|---|
| Vibration Sensor | 2 | SW-420 tamper detection (interrupt) |
| RTC SDA | 3 | DS3231 I2C data |
| RTC SCL | 6 | DS3231 I2C clock |
| GPS RX | 44 | NMEA data receive |
| GPS TX | 43 | GPS transmit (unused) |
| SD CS | 1 | SD card chip select |
| SD SCK | 7 | SPI clock |
| SD MISO | 8 | SPI MISO |
| SD MOSI | 9 | SPI MOSI |
| Mesh RX | 4 | Meshtastic UART receive |
| Mesh TX | 5 | Meshtastic UART transmit |

</details>

---

## Build & flash

The [Web Flasher](https://lukeswitz.github.io/AntiHunter/) is the easiest way. Use these to flash from a terminal or build from source.

### CLI flash

```bash
curl -fsSL -o flashAntihunter.sh https://raw.githubusercontent.com/lukeswitz/AntiHunter/beta/Dist/flashAntihunter.sh
chmod +x flashAntihunter.sh
./flashAntihunter.sh
```

The script asks for a release channel: Stable (from `main`), Beta (from `beta`), or Experimental (ESP32-C5 and RadarNode test builds). Then it asks which firmware. `-c` sets device parameters during flashing, `-e` erases flash first, `-l` lists available firmware.

### Build from source

You need PlatformIO, Git, and a USB cable. VS Code with the PlatformIO extension helps but isn't required.

```bash
git clone https://github.com/lukeswitz/AntiHunter.git
cd AntiHunter
pio device list                                    # list connected devices
```

Flash one of the two builds:

```bash
pio run -e AntiHunter-full -t upload               # Full: web UI on its own AP
pio run -e AntiHunter-headless -t upload           # Headless: serial + mesh only
```

Watch the serial output:

```bash
pio device monitor -e AntiHunter-full
```

To start from a blank chip, erase it. This removes saved settings and the firmware, so upload again afterward.

```bash
pio run -e AntiHunter-full -t erase
```

**Build environments:**
- `AntiHunter-full` builds `Antihunter/full/src`: web UI on its own AP (ESPAsyncWebServer + AsyncTCP). `AntiHunter-headless` builds `Antihunter/headless/src`: serial and mesh only, no web libraries. The two are separate source trees.
- ESP32-C5 (2.4 + 5 GHz, testing): `AntiHunter-c5-full` / `-c5-headless` on the `feat/c5` branch - see the [ESP32-C5 page](docs/ESP32-C5.md).
- RadarNode (24GHz radar, experimental): flash it from the web flasher's **Experimental** channel - see the [RadarNode page](docs/RADARNODE.md).

---

## Configuration

### RF scan presets

Set under System → RF Settings. The presets only change scan timing and the RSSI threshold.

| Preset | Wi-Fi Chan Time | Wi-Fi Scan Int | BLE Scan Int | BLE Scan Dur | RSSI Threshold | UI label |
|---|---|---|---|---|---|---|
| Relaxed | 300ms | 5000ms | 6000ms | 3000ms | −80 dBm | Relaxed (Quiet) |
| Balanced | 160ms | 3000ms | 4000ms | 2000ms | −95 dBm | Balanced (Default) |
| Aggressive | 110ms | 1500ms | 2000ms | 1000ms | −100 dBm | Aggressive (Fast) |
| Custom | User-defined | User-defined | User-defined | User-defined | User-defined | Custom |

<details>
<summary>What each setting does</summary>

- **Wi-Fi Channel Time**: how long the node listens on each channel (110-300ms in the web UI). Shorter covers channels faster and spends less time on each.
- **Wi-Fi Scan Interval**: how often the all-channel AP scan runs (1000-10000ms). Between scans, the node catches devices while hopping channels.
- **BLE Scan Interval**: time between BLE scans (1000-10000ms).
- **BLE Scan Duration**: how long each BLE scan listens (1000-5000ms). The scan loop waits for the BLE scan to finish before moving on. The presets set BLE Scan Duration to half the BLE Scan Interval.
- **RSSI Threshold**: ignore anything weaker than this (−100 to −10 dBm). Triangulation ignores this filter.
- **Wi-Fi Channels**: a list (1,6,11) or a range (1..14). Default 1-11, the 2.4 GHz channels allowed in the United States.

</details>

---

## System architecture

One node works on its own. Add more and they share one Meshtastic mesh: every node hears every alert, any Meshtastic app can control them, and they can locate a device together. The [Command Center](https://github.com/TheRealSirHaXalot/AntiHunter-Command-Control-PRO) collects data from every node onto a live map.

<p align="center">
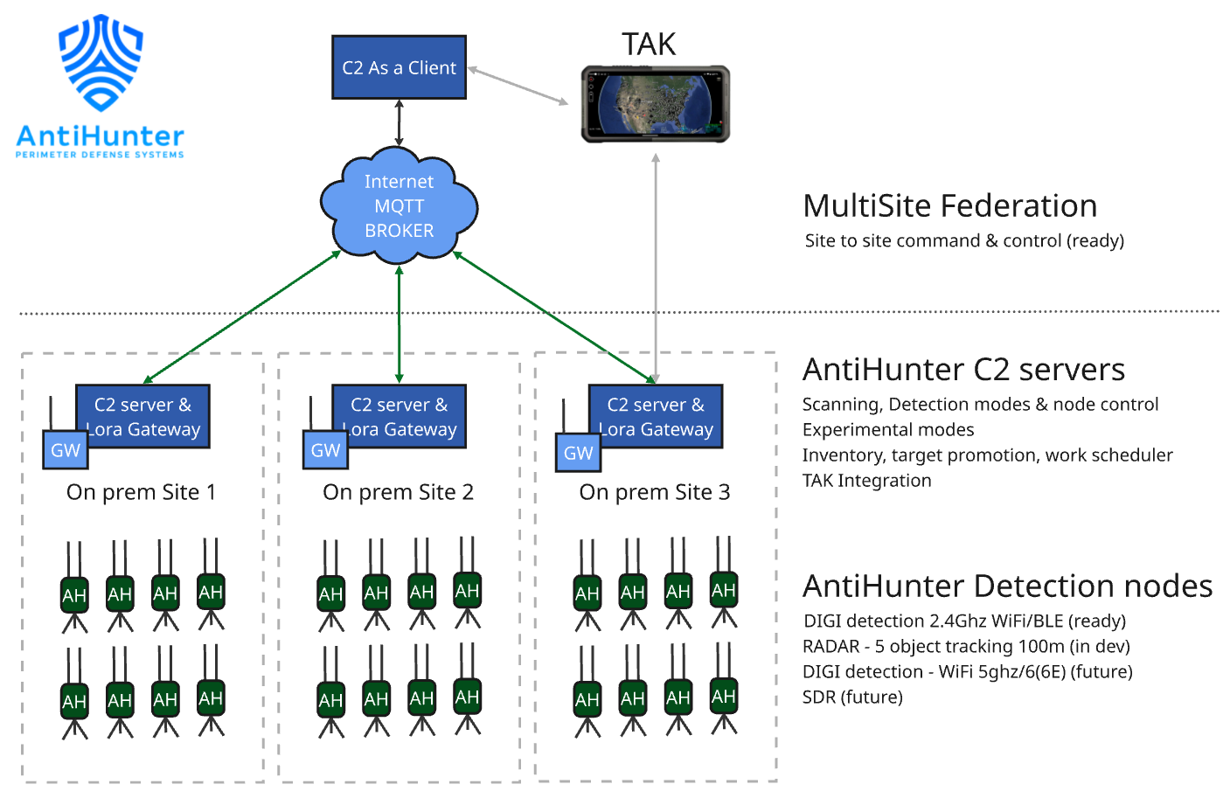
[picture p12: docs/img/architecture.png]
System Architecture
  
</p>

Three node types use the same PCB and mesh:

| | Board | Sensor | Firmware | Status |
|---|---|---|---|---|
| **DIGI** | ESP32-S3 | Wi-Fi + BLE, 2.4 GHz | `AntiHunter-full` / `-headless` | stable |
| **[DIGI C5](docs/ESP32-C5.md)** | ESP32-C5 | Wi-Fi + BLE, 2.4 **and** 5 GHz | `AntiHunter-c5-full` / `-c5-headless` | testing |
| **[RadarNode](docs/RADARNODE.md)** | ESP32-C5 | 24GHz radar, Wi-Fi/BLE on trigger | web flasher, Experimental | experimental |

The C5 drops into the S3's place on the same board and adds 5 GHz. A RadarNode spots a moving target on radar, then sweeps Wi-Fi and BLE to record the devices present at that moment. Its `STATUS` reply carries `TYPE:RADAR`, so the RadarNode UI and Command Center can tell node types apart. You flash both from the [web flasher](https://lukeswitz.github.io/AntiHunter/) under the **Experimental** channel, which asks you to confirm they're test builds.

---

## Reference

- [Start Here](docs/README.md) - setup order, decisions, troubleshooting, and every guide and manual
- [Operator's Guide](docs/AntiHunter-Operators-Guide.pdf) - unboxing to deployment, with a printable quick-reference card

### Mesh commands

[docs/mesh-commands.md](docs/mesh-commands.md) - mesh commands with parameters, examples, and alert formats.

### API reference

[docs/api-reference.md](docs/api-reference.md) - the Full firmware's HTTP endpoints.

## Contributing

Ask questions and share builds in [Discussions](https://github.com/lukeswitz/AntiHunter/discussions) or on [Discord](https://discord.gg/AYFzUurfmh). Report bugs in [Issues](https://github.com/lukeswitz/AntiHunter/issues). Pull requests for code and docs are welcome.

## Acknowledgments

Original concept and hardware design by @TheRealSirHaXalot.

This project includes code from [opendroneid-core-c](https://github.com/opendroneid/opendroneid-core-c), licensed under the Apache License 2.0. Copyright © Intel Corporation and OpenDroneID contributors

## License

Firmware: [GNU Affero General Public License v3.0](LICENSE). Hardware and documentation: as stated in their files.

## Legal disclaimer

<details>
<summary>Full Disclaimer</summary>

```
# Legal Disclaimer

AntiHunter ("AH", the "Project") comprises open-source firmware, source code, hardware designs, and associated documentation distributed for lawful, authorized defensive use only. You may operate the Project solely on infrastructure, networks, devices, radio spectrum, and datasets that you own or for which you hold explicit, written permission to assess. By downloading, compiling, flashing, assembling, energizing, or otherwise using the Project you agree to the following conditions:

- **Authorization & intent.** Use is limited to security research, blue-team training, regulatory-compliant monitoring, event security, network auditing, and other defensive activities. Offensive operations, targeted surveillance, stalking, harassment, or tracking of individuals without their informed consent are strictly prohibited. Detection, correlation, and triangulation capabilities are provided to characterize an environment you are authorized to assess, not to identify or follow persons.

- **Radio & telecommunications compliance.** You are responsible for abiding by every jurisdictional regulation governing radio frequency use, including FCC Part 15 and Part 97, CE/RED, Ofcom, and equivalent national rules; LoRa/ISM band allocations, power limits, and duty-cycle restrictions; and any licensing conditions applicable to your operating class. LoRa firmware is region-locked (868 MHz EU / 915 MHz US / 923 MHz Asia); operating a build outside its intended regulatory region may be unlawful. You must not use the Project to cause harmful interference or to interfere with authorized radio communications.

- **Interception & wiretap law.** Passive reception of radio emissions is regulated separately from network access in many jurisdictions. Depending on your location and the mode in use, capturing, storing, decoding, or disclosing frame contents, payloads, or identifiers may implicate the U.S. Wiretap Act (18 U.S.C. § 2511), the Electronic Communications Privacy Act, state two-party-consent statutes, the UK Investigatory Powers Act, or equivalent law. Determine the lawfulness of each capture mode in your jurisdiction before enabling it.

- **Privacy & data protection.** MAC addresses, device identifiers, probe request contents, BLE advertisements, and Remote ID broadcasts may constitute personal data under GDPR, UK GDPR, CCPA/CPRA, ePrivacy, and similar regimes. Collect telemetry only with a lawful basis. Obtain consent where required, minimize collection, apply retention and destruction schedules that match applicable law, and honor data-subject rights. The maintainers do not process, receive, or host your data.

- **Drone Remote ID.** Reception of broadcast Remote ID is permitted in most jurisdictions, but using Remote ID data to locate, approach, confront, or interfere with an aircraft or its operator may violate aviation, harassment, or anti-stalking law, including 18 U.S.C. § 32. Remote ID reception is not an authorization to act on what you receive.

- **Computer misuse laws.** Scanning, probing, or accessing third-party networks without permission may violate the Computer Fraud and Abuse Act, the UK Computer Misuse Act, EU Directive 2013/40, or similar statutes. Always obtain written authorization before interfacing with systems you do not control.

- **Export & sanctions.** You must ensure distribution and use complies with the U.S. EAR (including controls applicable to cryptographic and telemetry functionality), EU dual-use regulations, applicable sanctions regimes, and any contractual restrictions. The maintainers make no export classification representations and grant no export approvals.

- **Hardware, assembly & safety.** Kits, bare PCBs, and assembled units are supplied for use by persons competent in electronics assembly and operation. You are responsible for correct assembly, soldering, ESD control, antenna selection and attachment, and supply of regulated 5 V power. Operating the transceiver without a properly matched antenna may damage the hardware. Lithium cells are not supplied; sourcing, protection circuitry, charging, storage, transport, and disposal of any battery are your responsibility and carry fire and injury risk. The hardware is not certified for, and must not be used in, life-safety, medical, aviation, automotive, industrial-control, or other applications where failure could result in death, injury, or environmental damage. It is not a substitute for a certified security, alarm, or life-safety system, and detection results are advisory only, subject to false positives and false negatives.

- **Units, kits, and builds supplied by the maintainers.** These terms apply in full to units the maintainers assembled, kits and bare boards they shipped, firmware flashed with tools they published, and builds produced by following their documentation, BOM, wiring diagrams, or flashing instructions. Assembly, sale, or instruction by the maintainers creates no warranty, no certification, no fitness-for-purpose representation, and no assumption of responsibility for how a unit is later configured, deployed, or used. Once the unit is in your hands, operation and compliance are yours alone. Flashing the firmware - by the web flasher, the shell script, or any other means - is acceptance of these terms.

- **Experimental features.** Modes designated beta or experimental - including Sentinel, Triangulation, and MAC Randomization Correlation - are unvalidated, may produce inaccurate or misleading output, and must not be relied upon for operational, evidentiary, investigative, or safety decisions.

- **Operational safeguards.** Run the Project on hardened, access-controlled infrastructure. You are responsible for segregation of duties, credential management, network isolation of nodes and mesh links, and preventing unauthorized access to captured telemetry or command functions.

- **Forks and modifications.** The firmware is licensed under the GNU Affero General Public License v3.0; hardware and documentation are licensed as stated in their respective files. If you fork, redistribute, modify, manufacture, or resell the Project, you are solely responsible for supporting your derivative work, for its regulatory compliance and certification, and for any representations you make about it. The original authors and contributors are not liable for defects or legal issues introduced by third-party changes, packaging, integrations, or manufacture.

## No Warranty / Limitation of Liability

THE PROJECT - INCLUDING SOFTWARE, FIRMWARE, HARDWARE DESIGNS, AND DOCUMENTATION - IS PROVIDED "AS IS" AND "AS AVAILABLE," WITHOUT WARRANTY OF ANY KIND, EXPRESS OR IMPLIED, INCLUDING BUT NOT LIMITED TO WARRANTIES OF MERCHANTABILITY, FITNESS FOR A PARTICULAR PURPOSE, TITLE, NON-INFRINGEMENT, ACCURACY, DETECTION EFFICACY, OR UNINTERRUPTED OPERATION. THIS DISCLAIMER SUPPLEMENTS AND DOES NOT LIMIT THE WARRANTY DISCLAIMER AND LIABILITY LIMITATION SET OUT IN SECTIONS 15 THROUGH 17 OF THE GNU AFFERO GENERAL PUBLIC LICENSE V3.0.

TO THE MAXIMUM EXTENT PERMITTED BY LAW, THE AUTHORS, DEVELOPERS, MAINTAINERS, AND CONTRIBUTORS SHALL NOT BE LIABLE FOR ANY DIRECT, INDIRECT, INCIDENTAL, SPECIAL, EXEMPLARY, PUNITIVE, OR CONSEQUENTIAL DAMAGES (INCLUDING, WITHOUT LIMITATION, LOSS OF DATA, PROFITS, GOODWILL, EQUIPMENT, OR BUSINESS INTERRUPTION, OR DAMAGES ARISING FROM FAILURE TO DETECT, FALSE DETECTION, OR REGULATORY ENFORCEMENT ACTION) ARISING FROM OR RELATED TO YOUR USE OF THE PROJECT, EVEN IF ADVISED OF THE POSSIBILITY OF SUCH DAMAGES. WHERE LIABILITY CANNOT BE FULLY DISCLAIMED, TOTAL AGGREGATE LIABILITY SHALL NOT EXCEED THE GREATER OF (A) THE AMOUNT PAID, IF ANY, FOR THE COPY OR UNIT THAT GAVE RISE TO THE CLAIM OR (B) USD $0.

NOTHING IN THIS DISCLAIMER EXCLUDES OR LIMITS LIABILITY THAT CANNOT LAWFULLY BE EXCLUDED OR LIMITED, INCLUDING LIABILITY FOR DEATH OR PERSONAL INJURY CAUSED BY NEGLIGENCE, FOR FRAUD, OR ANY NON-EXCLUDABLE STATUTORY CONSUMER RIGHTS. SOME JURISDICTIONS DO NOT ALLOW THE EXCLUSION OF IMPLIED WARRANTIES OR THE LIMITATION OF INCIDENTAL OR CONSEQUENTIAL DAMAGES, SO SOME OF THE ABOVE MAY NOT APPLY TO YOU.

## Responsibility for Compliance

You alone are responsible for ensuring your build, deployment, and operation comply with all applicable laws, regulations, licenses, permits, equipment authorizations, organizational policies, and third-party rights. No advice or information, whether oral or written, obtained from the Project, its maintainers, or its community channels creates any warranty or obligation not expressly stated in this disclaimer. Continued use signifies your agreement to indemnify and hold harmless the authors, developers, maintainers, and contributors from claims arising out of or related to your activities with the Project.

If you do not agree to these terms, do not build, flash, assemble, deploy, or operate AntiHunter.
```

</details>

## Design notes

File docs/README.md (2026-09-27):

# Start Here
- **[Read the Documentation](https://github.com/lukeswitz/AntiHunter/tree/main)** - everything there is to know about this project
- **[Operator's Guide](https://lukeswitz.github.io/AntiHunter/operators-guide/operators-guide.html)** — the node, from the box to the field. [PDF](AntiHunter-Operators-Guide.pdf)
- **[Assembly Manual](../hw/Prototype_STL_Files/Antihunter-DIGINODE-AssemblyManual.pdf)** — soldering, SD card prep, connectors, printed enclosure
- **Tier notes** — the sheet in the box: [Assembled](note-tier1-assembled.pdf) · [Parts Kit](note-tier2-parts-kit.pdf) · [Populated PCB](note-tier3-populated-pcb.pdf) · [Bare PCB](note-tier4-bare-pcb.pdf)

---

## Before you power anything

1. **Regulated 5 V only.** USB, a bench supply, a DC-DC regulator or the UPS board. Unregulated input permanently damages the modules, and under 4.5 V is unstable.
2. **Never power the LoRa radio without its antenna.** Transmitting into an open port can kill the PA. Fit the antenna or the U.FL pigtail first.
3. **One USB cable at a time.** The ESP32 and the radio share the PCB rails; with both plugged in, one back-feeds the other.

Flashing needs a **data** USB-C cable and Chrome or Edge on a desktop. Charge-only cables will not flash. Other browsers cannot talk to serial ports.

---

## Pick your path

### Assembled node or Populated PCB

The radio is already flashed and serial-configured. You do not redo that.

1. Fit the antennas — [§2](https://lukeswitz.github.io/AntiHunter/operators-guide/operators-guide.html#s2)
2. Flash AntiHunter, Full to start with — [web flasher](https://lukeswitz.github.io/AntiHunter/)
3. Change the AP credentials
4. Set your LoRa region, pairing pin and encrypted channel — [Radio Setup](../README.md#radio-setup)
5. Carry on at [Setup order](#setup-order-for-a-new-node)

### Parts Kit or Bare PCB

Nothing is soldered, nothing is flashed.

1. Check the box against [what your tier ships](../README.md#deployment-steps-by-tier)
2. Bare PCB only: source the parts — [BOM](../hw/Prototype_STL_Files/BOM-Links.md)
3. Solder it — [assembly manual](../hw/Prototype_STL_Files/Antihunter-DIGINODE-AssemblyManual.pdf)
4. Print an [enclosure](../hw/Prototype_STL_Files/README.md) if you want one
5. Flash Meshtastic on the radio at [flasher.meshtastic.org](https://flasher.meshtastic.org), then set SERIAL enabled, TEXTMSG, 115200, pins 19RX/20TX on Heltec V3 or 10RX/9TX on T114. [`meshtastic_config.py`](../scripts/meshtastic_config.py) does all of it
6. Carry on at [Setup order](#setup-order-for-a-new-node)

---

### Bare XIAO ESP32-S3, no PCB

The firmware expects the full module set: LoRa radio, GPS, RTC, SD reader, vibration sensor. Breadboard them to the same pins if you are not using the PCB.

Pinout: [Appendix A](https://lukeswitz.github.io/AntiHunter/operators-guide/operators-guide.html#appendix-a), or [Hardware](../README.md#hardware). Parts: [BOM](../hw/Prototype_STL_Files/BOM-Links.md).

### Building from source

PlatformIO environments: [Build & Flash](../README.md#build-from-source). Read [CONTRIBUTING](../CONTRIBUTING.md) and the [CLA](../CLA.md) before a PR.

---

### Several nodes

Give every node its own ID and put them all on the same encrypted channel. They relay for each other, 3 hops by default — [reaching a node you cannot hear](../README.md#reaching-a-node-you-cannot-hear). Aggregate the fleet with the [Command Center](https://github.com/TheRealSirHaXalot/AntiHunter-Command-Control-PRO) — install steps in [§12](https://lukeswitz.github.io/AntiHunter/operators-guide/operators-guide.html#s12).

---

## Setup order for a new node

| # | Step | Where |
|---|---|---|
| 1 | Fit the antennas — 2.4 GHz to the XIAO, LoRa to the radio, GPS to the GPS module | [§2](https://lukeswitz.github.io/AntiHunter/operators-guide/operators-guide.html#s2) |
| 2 | Flash AntiHunter, Full to start with | [Web flasher](https://lukeswitz.github.io/AntiHunter/) · [CLI](../README.md#cli-flash) |
| 3 | Change the AP credentials — the defaults are published in this repo | RF Settings in the web UI |
| 4 | Set the radio's LoRa region — it defaults to UNSET and receives without ever transmitting | [Radio Setup](../README.md#radio-setup) |
| 5 | Create your own encrypted channel, make it primary, disable the public one | [Radio Setup](../README.md#radio-setup) |
| 6 | Set the node ID — it prefixes every mesh message the node sends. The clock needs nothing: the RTC is set at flash time and disciplined by GPS | Web UI, or `@AH01 CONFIG_NODEID:GATE1` · [§8.2](https://lukeswitz.github.io/AntiHunter/operators-guide/operators-guide.html#s8-2) |
| 7 | Confirm the SD card mounts and GPS gets a fix outdoors | [§4](https://lukeswitz.github.io/AntiHunter/operators-guide/operators-guide.html#s4) |
| 8 | Tune the vibration trimpot in place, on the real mount | [§10.2](https://lukeswitz.github.io/AntiHunter/operators-guide/operators-guide.html#s10-2) |
| 9 | Verify `@NODEID STATUS` answers over the mesh | [Mesh Commands](../README.md#mesh-commands) |
| 10 | Seal and deploy | [§13](https://lukeswitz.github.io/AntiHunter/operators-guide/operators-guide.html#s13) |

---

## Decisions

| Question | Answer |
|---|---|
| **Full or Headless?** | Same detectors, same scan engine, same mesh commands. Full hosts the Wi-Fi AP with the web UI and API, and beacons continuously. Headless is serial and mesh only, never beacons. Start on Full, reflash to Headless before a quiet deployment. [Details](../README.md#full-vs-headless) |
| **Stable or Beta?** | Stable (`main`) for field deployments. Beta (`beta`) for new features first, Sentinel among them. [Release notes](release-notes/notes.md) |
| **S3 or C5?** | ESP32-S3 is the stable build. The [ESP32-C5](https://github.com/lukeswitz/AntiHunter/blob/beta/docs/ESP32-C5.md) is a drop-in on the same pads and adds 5 GHz, under the flasher's Experimental channel while it is in testing. [RadarNode](https://github.com/lukeswitz/AntiHunter/blob/beta/docs/RADARNODE.md) pairs a 24 GHz radar with the same mesh. |
| **Do I need the Meshtastic radio?** | Not for scanning. Without it, you control one node from its own AP or over serial, standing next to it. With it, you send commands and get detections over LoRa from anywhere in mesh range, across as many nodes as you deploy. |
| **Which SD card?** | FAT32, under 32 GB. Every tier except Bare PCB ships with an 8 GB card fitted. |
| **How do I update?** | Re-run the flasher on the same channel with *Erase Device* unticked. Settings are in NVS and mirrored to the SD card, so they survive. Read the release notes first. |

---

## Ten commands to know

Send these as text messages from any Meshtastic client on your channel.

```
@ALL STATUS                        which nodes answer
@ALL STOP                          stop everything
@AH01 CONFIG_NODEID:GATE1          name a node
@ALL CONFIG_TARGETS:AA:BB:CC|MyWiFi   set the watchlist
@ALL SCAN_START:2:600:1..11        watchlist scan, 10 minutes
@ALL DEVICE_SCAN_START:2:300       survey everything nearby
@ALL BASELINE_START:900            learn the site's normal devices
@ALL SENTINEL_ON                   attacker-tool detection (Beta)
@ALL DRONE_START:0                 drone watch until stopped
@AH01 BATTERY_SAVER_START:10       idle, mesh stays up
```

Every command, every reply label: [Mesh Commands](../README.md#mesh-commands). Over HTTP instead: [API Reference](../README.md#api-reference).

---

## Something is wrong

| Symptom | Usual cause | Fix |
|---|---|---|
| No `Antihunter` Wi-Fi network | Headless is flashed, or the AP name and password were changed | Check over serial which build is running. Reflash Full if you need the UI |
| Web UI will not load | Not on the node's own AP, or the browser forced https | Join the AP, open `http://192.168.4.1` exactly |
| Flashing fails, or no serial port appears | Charge-only cable, a serial monitor holding the port, both USB ports connected, or the wrong browser | Data cable, close other serial tools, unplug the radio, use Chrome or Edge |
| SD card not detected | Not FAT32, 32 GB or larger, or not seated | Reformat FAT32 on a card under 32 GB |
| No GPS fix | Antenna not connected, or no sky view | Check the U.FL or SMA, go outdoors, give it time. The module runs hot while searching |
| Nothing arrives over the mesh | Region UNSET so the radio is receive-only, serial module off, wrong pins, or nodes on different channels or keys | Re-run [`meshtastic_config.py`](../scripts/meshtastic_config.py) and print the settings. Every node needs the same channel and key |
| A node hears commands but never answers | Its region is unset, so it cannot transmit | Set its region |
| Node scans forever | A scan was started with `:FOREVER` or duration 0 | `@ALL STOP`, or Stop in the UI |
| Settings gone after flashing | *Erase Device* was ticked | Reconfigure. NVS mirrors to SD and self-heals, but a deliberate erase clears it |
| Constant vibration alerts | Trimpot too sensitive, or a resonant mount | Retune in place ([§10.2](https://lukeswitz.github.io/AntiHunter/operators-guide/operators-guide.html#s10-2)), pad the mount |
| Detections with no coordinates | No valid GPS fix at that moment | Expected. Position is attached only when the fix is valid |

Full symptom table, factory reset and what to include in a bug report: [§14](https://lukeswitz.github.io/AntiHunter/operators-guide/operators-guide.html#s14). Then [Discussions](https://github.com/lukeswitz/AntiHunter/discussions) or [Discord](https://discord.gg/AYFzUurfmh). Scrub coordinates and MAC addresses from anything you paste.

---

## Everything else

**Hardware** — [assembly manual](../hw/Prototype_STL_Files/Antihunter-DIGINODE-AssemblyManual.pdf) · [BOM links](../hw/Prototype_STL_Files/BOM-Links.md) · [enclosures and STLs](../hw/Prototype_STL_Files/README.md) · [welcome letter](../hw/Prototype_STL_Files/ahwelcome.txt) · [what each tier ships](../README.md#deployment-steps-by-tier) · tier notes: [Assembled](note-tier1-assembled.pdf) · [Parts Kit](note-tier2-parts-kit.pdf) · [Populated PCB](note-tier3-populated-pcb.pdf) · [Bare PCB](note-tier4-bare-pcb.pdf)

**Firmware** — [web flasher](https://lukeswitz.github.io/AntiHunter/) · [CLI flasher](../Dist/flashAntihunter.sh) · [build from source](../README.md#build-from-source) · [releases](https://github.com/lukeswitz/AntiHunter/releases) · [release notes](release-notes/notes.md)

**Operating** — [what it detects](../README.md#what-it-detects) · [scan presets](../README.md#rf-scan-presets) · [field controls](../README.md#field-controls) · [secure data destruction](../README.md#secure-data-destruction) · [mesh networking](../README.md#mesh-networking) · [Command Center](https://github.com/TheRealSirHaXalot/AntiHunter-Command-Control-PRO)

**Scripts** — [`meshtastic_config.py`](../scripts/meshtastic_config.py) hardens a radio: screen, LED, pairing pin, serial module, region

**Project** — [Discord](https://discord.gg/AYFzUurfmh) · [Discussions](https://github.com/lukeswitz/AntiHunter/discussions) · [store](https://lectronz.com/stores/antihunter) · [website](https://rootdowndigital.com/antihunter) · [contributing](../CONTRIBUTING.md) · [CLA](../CLA.md) · [security policy](../SECURITY.md) · [license](../LICENSE) · [legal disclaimer](../README.md#legal-disclaimer)

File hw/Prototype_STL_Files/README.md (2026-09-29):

# Enclosure Prototypes

3D-printable enclosures for AntiHunter nodes. Parts list: [BOM-Links.md](BOM-Links.md). Assembly: [Antihunter-DIGINODE-AssemblyManual.pdf](Antihunter-DIGINODE-AssemblyManual.pdf).

| Enclosure | Folder | Power | Credit |
|---|---|---|---|
| [AH Case v2](#ah-case-v2) | `AH-DIGINODE-v2/` | UPS board or DIY 2S 18650 | @TheRealSirHaxAlot |
| [Puck Case](#puck-case) | `AHPuckCase/` | USB-C | @nitekry |

## AH Case v2

Field deployment case with external GPS.

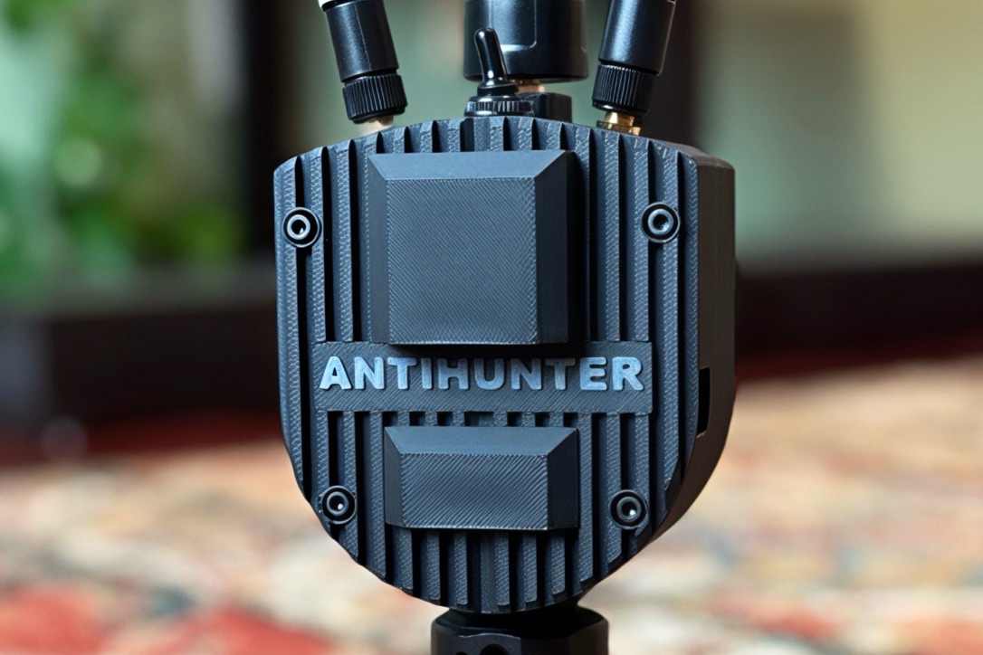
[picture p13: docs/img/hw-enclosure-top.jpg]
Enclosure top
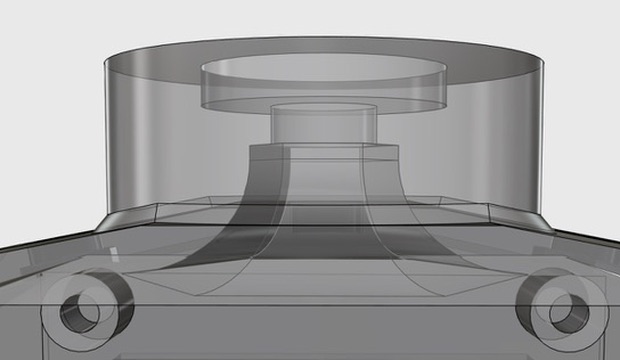
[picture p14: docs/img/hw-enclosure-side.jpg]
Enclosure side
 

### Features

- Holds a UPS board, with fast-charge or side-charge battery housing
- Runs without the rear power housing for a compact dev build
- TPU seals for the housing, GPS antenna, USB-C port and GPS SMA
- Front cover with open or hidden fan
- Base takes 1/4"-20 UNC heat-set inserts
- Assembly uses M3 heat-set inserts and 2x 15 mm standoffs

### Files

| Part | File |
|---|---|
| Back cover | `BackCover.stl` |
| Front cover, open fan | `FrontCover-Open-Fan.stl` |
| Front cover, hidden fan | `FrontCover-Hidden-Fan.stl` |
| Battery enclosure bracket | `universalbracket-for-battery-enclousure.stl` |
| Fast-charge main housing | `FastCharge enlosure/Main-Housing-USBFast-Version.stl` |
| Fast-charge battery housing | `FastCharge enlosure/Battery-Housing-USBFast-with-side-hole.stl`, `…-no-side-hole.stl` |
| Side-charge main housing | `SideCharge enclosure/Main-Housing-SideCharge-Version.stl` |
| Side-charge battery housing | `SideCharge enclosure/Battery-Housing-SideCharge.stl` |

### Extensions

| Folder | Parts |
|---|---|
| `Extentions/MOUNTS` | Universal bracket, with or without battery |
| `Extentions/RadarMOD` | Radar housing (fat, slim) and radar front |
| `Extentions/SEALS` | TPU seals: battery housing, front housing, ESP USB plug, GPS, radar |
| `Extentions/SOLAR` | 115x85 mm solar panel frame and leg |

## Puck Case

Slim case with a snap-fit, vented lid.

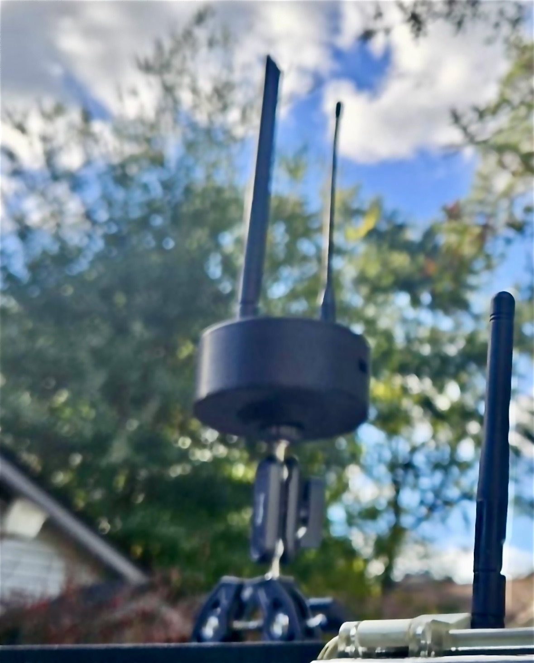
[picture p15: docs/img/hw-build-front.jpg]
Build front
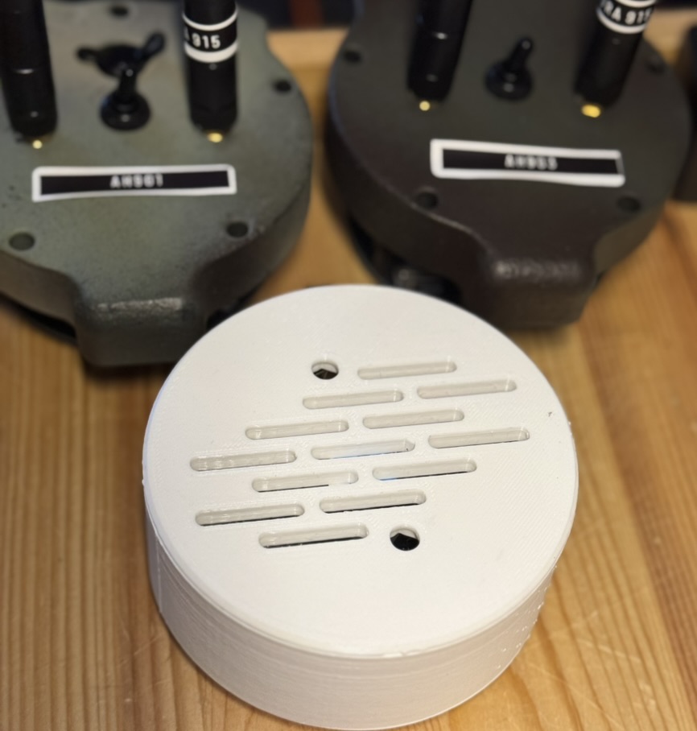
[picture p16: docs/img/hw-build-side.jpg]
Build side
 

- USB-C port access
- SMA bulkheads recessed in the lid
- Base takes 1/4"-20 UNC heat-set inserts
- Files: `puck_body.stl`, `puck_top.stl`, `puck_bottom.stl`

## Disclaimer

```
These 3D printable enclosure files are provided "AS IS" without warranty of any kind. AntiHunter maintainers and contributors assume no liability for any damages, injuries, losses, or legal consequences arising from the use of these files. Users are solely responsible for regulatory compliance, material selection, print quality, hardware compatibility, and all outcomes of use.
```

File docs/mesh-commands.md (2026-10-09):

# Mesh Commands

Full command reference for controlling a node over the Meshtastic mesh.
Back to the [README](../README.md).

Timestamps show local time from the GPS fix. Without a GPS lock they show UTC. Node IDs: 2-5 alphanumeric characters (A-Z, 0-9), no spaces.

> [!TIP]
> `@ALL` broadcasts to all nodes. Replace with a node ID for targeted commands.

### Core

| Command | Does | Parameters | Example |
|---|---|---|---|
| `STATUS` | Report mode, scan state, hits, temp, uptime, GPS; then `STATUS_BOOT: reset= prevUp= restored= sdMountFail= sdRetry=` | None | `@ALL STATUS` |
| `STOP` | Stop everything running, including a pending attack response | None | `@ALL STOP` |
| `MESH_TX_CANCEL` | Drop queued mesh event and bulk traffic; the running scan and triangulation control traffic continue. ACK `MESH_TX_CANCEL_ACK:EMPTY` when nothing was queued | None | `@ALL MESH_TX_CANCEL` |

### Configuration

| Command | Does | Parameters | Example |
|---|---|---|---|
| `CONFIG_TARGETS` | Set the watchlist | Pipe-delimited MACs, OUIs, SSIDs | `@ALL CONFIG_TARGETS:AA:BB:CC:DD:EE:FF\|11:22:33\|MyNetwork` |
| `CONFIG_NODEID` | Rename the node | 2-5 alphanumeric | `@AH01 CONFIG_NODEID:AH02` |
| `CONFIG_RSSI` | Set the RSSI floor | -128 to -10 | `@ALL CONFIG_RSSI:-80` |
| `CONFIG_CHANNELS` | Set the channels to sweep | Comma-separated or a range | `@ALL CONFIG_CHANNELS:1..11` |
| `CONFIG_DEDUP_TTL` | Set cross-scan MAC dedup | Seconds 0-3600, 0 disables | `@ALL CONFIG_DEDUP_TTL:300` |
| `CONFIG_SESSION_DEDUP` | Toggle per-session dedup | `0`/`1` | `@ALL CONFIG_SESSION_DEDUP:1` |
| `MESH_DEDUP_CLEAR` | Clear the dedup cache | None | `@ALL MESH_DEDUP_CLEAR` |

### Scanning

| Command | Does | Parameters | Example |
|---|---|---|---|
| `SCAN_START` | Hunt the watchlist | `mode:secs:channels[:FOREVER]` | `@ALL SCAN_START:2:300:1..11` |
| `DEVICE_SCAN_START` | List everything in range | `mode:secs[:FOREVER[:+PROBE]]` | `@ALL DEVICE_SCAN_START:2:300:+PROBE` |
| `BASELINE_START` | Learn the area, then flag changes | `duration[:FOREVER]`, min 60s | `@ALL BASELINE_START:300` |
| `BASELINE_STATUS` | Report baseline progress | None | `@ALL BASELINE_STATUS` |
| `BASELINE_WATCH` | Compare devices heard before and after this moment: new, gone, moving closer/away. Send during the learning phase. Replies `BASELINE_ACK:WATCHING` or `NOT_RUNNING` | None | `@ALL BASELINE_WATCH` |
| `DRONE_START` | Watch for drone Remote ID | `secs[:FOREVER]` | `@ALL DRONE_START:300` |
| `DEAUTH_START` | Watch for deauth attacks | `secs[:FOREVER]` | `@ALL DEAUTH_START:300` |
| `RANDOMIZATION_START` | Link randomized MACs to devices | `mode:secs[:FOREVER]` | `@ALL RANDOMIZATION_START:2:300` |
| `PROBE_START` / `PROBE_STOP` | Collect probe requests | `mode:secs[:FOREVER][:+ALL]` | `@ALL PROBE_START:2:300:+ALL` |
| `PCAP_START` / `PCAP_STOP` | Record traffic to SD as pcap | `radio:secs:band[:CH<list>]` | `@ALL PCAP_START:0:300:0:CH1,6,11` |
| `PCAP_LIMITS` | Set or read the file size cap | `[MB]`, 8-300 | `@ALL PCAP_LIMITS:150` |
| `PCAP_AUTO` | Set or read the auto-capture SD budget and free-space floor | `[budgetMB,floorMB]` | `@AH01 PCAP_AUTO:512,64` |
| `PCAP_DELETE_ALL` | Delete every capture on SD; replies the count | None | `@AH01 PCAP_DELETE_ALL` |
| `SD_REPAIR` | Rebuild an unmountable SD card; erases it | `ON\|OFF\|NOW` | `@ALL SD_REPAIR:ON` |
| `SCHED_ADD` | Schedule a scan | `<local YYYY-MM-DDTHH:MM>\|<repeat secs>\|<scan>\|<options>`; scan `/scan`, `/sniffer` or `/drone`; repeat `0` once, else 600+ | `@ALL SCHED_ADD:2026-09-30T02:00\|86400\|/scan\|mode=2&secs=600` |
| `SCHED_LIST` | Print scheduled scans to serial, reply with the count | None | `@AH01 SCHED_LIST` |
| `SCHED_DEL` | Delete a scan by its `SCHED_LIST` number | `<n>` | `@AH01 SCHED_DEL:1` |

> [!WARNING]
> Stop a capture before cutting power or resetting the node. FAT has no power-fail
> protection, so an interruption mid-write can leave the SD card unreadable until it is
> reformatted, and the node then runs with no storage at all. `SD_REPAIR:ON` lets a node
> rebuild its own card, which recovers most cases but not all, and erases the card.

The `+PROBE` flag on `DEVICE_SCAN_START` enables probe request capture during device scans, populating the probe database alongside normal device discovery.

### Sentinel (Beta version only)

These commands are only present on Beta firmware. On Stable they are not recognized.

| Command | Does | Parameters | Example |
|---|---|---|---|
| `SENTINEL_ON` / `SENTINEL_OFF` | Start or stop Sentinel | None | `@ALL SENTINEL_ON` |
| `SENTINEL_STATUS` | Report Sentinel state | None | `@AH01 SENTINEL_STATUS` |
| `SENTINEL_MODE` | Pin a channel or hop | `defend` or `scan` | `@ALL SENTINEL_MODE:scan` |
| `SENTINEL_BOOT` | Auto-start at power-on | `1`/`0` | `@ALL SENTINEL_BOOT:1` |
| `GROUP` | Toggle a detector group | `<name>:<on\|off>` | `@ALL GROUP:dos:on` |
| `DETECT_CFG` | Set detector tunables | `<json>`, ≤180 chars | `@AH01 DETECT_CFG:{"pmkid":true}` |
| `DETECT_CFG_GET` | Dump the config to serial | None | `@AH01 DETECT_CFG_GET` |
| `INCIDENTS` | Dump the incident log | `[:<1-200>]` | `@AH01 INCIDENTS:50` |
| `INCIDENTS_CLEAR` | Clear the incident log | None | `@ALL INCIDENTS_CLEAR` |
| `ATTACKER_TRILAT` | Triangulate a confirmed attacker | `1`/`0`/`on`/`off` | `@ALL ATTACKER_TRILAT:1` |
| `ATTACKER_TRILAT_STATUS` | Report that setting | None | `@AH01 ATTACKER_TRILAT_STATUS` |
| `DETECT_JSON` | Dump a detector's list to serial | `karma\|pg\|tsf\|hshk\|pwna\|tof\|hunts\|pcap\|pcaps` | `@AH01 DETECT_JSON:pwna` |
| `DETECT_CLEAR` | Clear a detector's list | same names | `@AH01 DETECT_CLEAR:tsf` |
| `DETECT_COUNTS` | Entry count per detector, pending attack responses | None | `@AH01 DETECT_COUNTS` |
| `DETECT_VERBOSE` | Per-frame detector logging on serial | `ON\|OFF` | `@AH01 DETECT_VERBOSE:ON` |
| `QUORUM` | Nodes that must agree before an alert | `<type>,<n>` | `@ALL QUORUM:PMKID,2` |
| `KARMA_ON` / `KARMA_OFF` | Karma detector; transmits bait probes to confirm a suspect AP | None | `@AH01 KARMA_ON` |
| `HUNT_COOLDOWN` | Gap between attacker hunts | ms | `@ALL HUNT_COOLDOWN:60000` |
| `TOF_PING` | Time-of-flight ping | `[:<node>]`, all if omitted | `@AH01 TOF_PING:AH02` |
| `ATTACK_RESPONSE_CANCEL` | Drop a pending attack response | None | `@ALL ATTACK_RESPONSE_CANCEL` |

`GROUP` members: `dos` = eviltwin, sae, assoc_sleep · `rogue` = eviltwin, owe, karma · `recon` = pmkid, probe_flood, hshk · `physical` = frag, tsf, jam · `mesh` = mesh_guard · `all` = every member listed here.

`DETECT_CFG` sets the rest: `ssid_confusion`, `pwna`, `csa_quiet`, `rid_spoof`, `bloom_gossip`, `ble_malformed`, the 15 `mesh_*` emit toggles and the numeric thresholds. `DETECT_CFG_GET` prints every key to serial. `GROUP` and `DETECT_CFG` write to NVS. Deauth, beacon and auth detection have no toggle.

Headless has no SoftAP. `defend` pins to whatever channel the radio last used, so use `scan`.

### CSI Motion (Beta version only)

| Command | Does | Parameters | Example |
|---|---|---|---|
| `CSI_MOTION_START` | Start detection | `secs[:FOREVER][:CH<n>][:TELEM][:RAW][:GAP<s>][:LISTEN_ONLY\|ALLOW_TRANSMIT][:MGMTONLY\|MGMTDATA][:SOLICIT<ms>]` | `@ALL CSI_MOTION_START:600:GAP60` |
| `CSI_CFG` | Tune detection; tokens combine | `SENSITIVITY=`, `MIN_MOTION=`, `CLEAR_AFTER=`, `SPOTS=`, `BROADCAST=`, `ALLOW_RANDOM=`, `CH=` | `@ALL CSI_CFG:SENSITIVITY=LOW:BROADCAST=OFF` |
| `CSI_EXCLUDE` | Ignore one MAC until reboot | MAC or `NONE` | `@AH01 CSI_EXCLUDE:NONE` |
| `CSI_STATUS` | Links, channel, settings | None | `@AH01 CSI_STATUS` |
| `CSI_JSON` | Same as JSON | None | `@AH01 CSI_JSON` |
| `CSI_RECAL` | Clear a saved threshold; use the preset | None | `@ALL CSI_RECAL` |

`CSI_CFG` tokens: `SENSITIVITY=LOW|MEDIUM|HIGH|<number>` · `MIN_MOTION=<s>` · `CLEAR_AFTER=<s>` · `SPOTS=<n>` (default 2) · `BROADCAST=ON|OFF` (default OFF; ON probes quiet devices) · `ALLOW_RANDOM=ON|OFF` (default ON) · `CH=<n>` (`0` lets it choose).

On the first CSI start after boot each node sends `<NODE>: CSI_PEER:<AP MAC>`. Nodes that hear it ignore that MAC for CSI until reboot and answer with their own `CSI_PEER` the first time they hear a MAC. If the channel survey picks a channel whose best access point is a peer node, the survey runs again.

### Other Beta and C5 commands

| Command | Does | Parameters | Example |
|---|---|---|---|
| `DEVICE_DB_CLEAR` | Clear the discovered-device DB (headless, Beta and C5) | None | `@AH01 DEVICE_DB_CLEAR` |
| `CONFIG_BAND` | Wi-Fi band (C5 only) | `0` 2.4 GHz, `1` 5 GHz, `2` both | `@AH01 CONFIG_BAND:2` |

<details>
<summary>Triangulation Commands</summary>

| Command | Does | Parameters | Example |
|---|---|---|---|
| `TRIANGULATE_START` | Locate a MAC across nodes | `target:duration[:rfEnv[:wifiPwr:blePwr]]` | `@AH01 TRIANGULATE_START:AA:BB:CC:DD:EE:FF:60:2:1.0:1.0` |
| `TRIANGULATE_STOP` | Stop it | None | `@ALL TRIANGULATE_STOP` |
| `TRIANGULATE_RESULTS` | Report the fix | None | `@AH01 TRIANGULATE_RESULTS` |

</details>

<details>
<summary>Security Commands</summary>

| Command | Does | Parameters | Example |
|---|---|---|---|
| `ERASE_FORCE` | Wipe now | `<key>` | `@AH02 ERASE_FORCE:<key>` |
| `ERASE_CANCEL` | Abort a pending wipe | `<key>` | `@AH01 ERASE_CANCEL:<key>` |
| `AUTOERASE_ENABLE` | Wipe if the node is moved | `setup:erase:vibs:window:cooldown:key` | `@AH01 AUTOERASE_ENABLE:60:30:3:30:300:<key>` |
| `AUTOERASE_DISABLE` | Turn that off | `<key>` | `@AH01 AUTOERASE_DISABLE:<key>` |
| `AUTOERASE_STATUS` | Report auto-erase state | None | `@AH01 AUTOERASE_STATUS` |
| `VIBRATION_ON` / `VIBRATION_OFF` | Enable the movement sensor | None | `@AH01 VIBRATION_ON` |
| `VIBRATION_STATUS` | Report sensor state | None | `@AH01 VIBRATION_STATUS` |
| `VIBSCAN_SET` | Start a scan when moved | `en:mode:dur[:cooldown[:interrupt]]` | `@AH01 VIBSCAN_SET:1:2:60:60` |
| `VIBSCAN_STATUS` | Report that setting | None | `@AH01 VIBSCAN_STATUS` |
| `CONFIG_ERASE_PSK` | Set or change the erase key | `<new>:<current>`. 8+ chars, no `:`. Current is the AP password until you set one | `@AH01 CONFIG_ERASE_PSK:myS3cretKey:<current>` |
| `FACTORY_RESET` | Reset one node | `<FULL\|CONFIG\|DATA>:<key>` | `@AH01 FACTORY_RESET:FULL:<key>` |

`VIBSCAN_SET` modes: 0 off, 1 all-device, 2 probe-req, 3 rand-MAC, 4 list, 5 drone, 6 deauth, 7 baseline, 8 packet capture. Duration 0 runs until stopped, cooldown 5-86400s. Skipped if a scan is already running or in battery saver.

`VIBSCAN_SET` `interrupt` `1` lets the triggered scan stop a scheduled scan, which resumes afterward.

Erase commands reply `ERASE_ACK:SET_KEY_FIRST` until you set your own key. 5 wrong keys lock them for 10 minutes. `CONFIG_ERASE_PSK` replies `SET`, `DENIED`, or `INVALID` (bad key format).

`CONFIG_TARGETS`: separate entries with `|`. Hex identity IDs such as `T-00A3` are accepted.

</details>

<details>
<summary>Battery Saver Commands</summary>

| Command | Does | Parameters | Example |
|---|---|---|---|
| `BATTERY_SAVER_START` | Drop to low power | `interval_minutes` 1-30 | `@AH01 BATTERY_SAVER_START:10` |
| `BATTERY_SAVER_STOP` | Return to normal | None | `@AH01 BATTERY_SAVER_STOP` |
| `BATTERY_SAVER_STATUS` | Report power state | None | `@AH01 BATTERY_SAVER_STATUS` |

Stops Wi-Fi/BLE scanning, reduces CPU to 80MHz, sends a heartbeat every interval. Mesh UART stays active. Heartbeat format:

```
NODE_ID: HEARTBEAT: Temp:XXC GPS:lat,lon Battery:SAVER
```

</details>

<details>
<summary>Heartbeat Commands</summary>

Periodic status broadcast over mesh. **Disabled by default.**

| Command | Does | Parameters | Example |
|---|---|---|---|
| `HB_ON` / `HB_OFF` | Toggle the heartbeat | None | `@AH01 HB_ON` |
| `HB_INTERVAL` | Set how often it sends | `minutes` 1-60 | `@AH01 HB_INTERVAL:10` |

Format: `NODE_ID: Time:YYYY-MM-DD_HH:MM:SS Temp:XX.XC [GPS:lat,lon]`

</details>

<details>
<summary>Alert Message Formats</summary>

| Alert Type | Format |
|---|---|
| Target Detected | `NODE_ID: Target: MAC RSSI:N Type:WiFi\|BLE [Name:name] [GPS=lat,lon] [V=vendor]` - `V=` is the first word of the OUI vendor, omitted for randomized or unknown MACs |
| Baseline Anomaly | `NODE_ID: ANOMALY-NEW: TYPE MAC RSSI:N [Name:name]` · `NODE_ID: ANOMALY-RETURN: TYPE MAC RSSI:NdBm [Name:name]` · `NODE_ID: ANOMALY-RSSI: TYPE MAC Old:NdBm New:NdBm Delta:NdBm` · `NODE_ID: ANOMALY: TYPE MAC RSSI:N reason [N:name]` |
| Deauth Attack | `NODE_ID: ATTACK: DEAUTH\|DISASSOC [BROADCAST\|TARGETED] SRC:MAC DST:MAC RSSI:dBm CH:N R:reason [GPS:lat,lon]` |
| Drone Detected | `NODE_ID: DRONE: MAC ID:uavId R-dBm [GPS:lat,lon] [ALT:m] [SPD:m/s] [OP:lat,lon]` - sent once per appearance, Wi-Fi and BLE alike. Telemetry fields are dropped if the line would exceed the mesh MTU. A drone that stays in range is never re-announced; one that returns after going stale is re-announced at most once per 120s |
| Drone Lost | `NODE_ID: DRONE_LOST: MAC [ID:uavId] AGE:secs` - sent once, 120s after the last Remote ID beacon. Not repeated while the aircraft stays away, and the Web UI keeps the detection, marked stale |
| Triangulation Data | `NODE_ID: T_D: MAC Hits=N RSSI:N [GPS=lat,lon HDOP=X.X]` - one per participating node per reporting cycle, coordinator included. Slots are assigned by node-ID order, so every node derives the same rotation |
| Triangulation Final | `NODE_ID: T_F: MAC=addr GPS=lat,lon CONF=85.5 UNC=12.3` |
| Triangulation Complete | `NODE_ID: T_C: MAC=addr Nodes=N`, plus ` GPS=lat,lon CONF=pct URL=<maps link>` when trilateration solved |
| Triangulation Cycle Start | `@ALL TRI_CYCLE_START:<ms>:<node,node,...>` - the coordinating node broadcasts it so every node in the run reports in its own slot. Sent by the firmware, not something you issue |
| Probe Watchlist Hit | `NODE_ID: PROBE_HIT MAC [Randomized\|Vendor] RSSI=dBm CH=N [SSID="network" [GHOST]] [DST]` - vendor token omitted entirely when unknown |
| Packet Capture Started | `NODE_ID: PCAP_START: WIFI\|BLE D=secs` |
| Packet Capture Done | `NODE_ID: PCAP_DONE: F=frames B=bytes D=dropped` - `D` counts frames the SD writer could not keep up with |
| Tamper Detected | `NODE_ID: TAMPER_DETECTED: Auto-erase in Xs [GPS:lat,lon]` |
| Status Response | `NODE_ID: STATUS: Mode:TYPE Scan:ACTIVE\|IDLE Hits:N Temp:XX.XC Up:HH:MM:SS [GPS:lat,lon HDOP=X.X]` |

</details>

<details>
<summary>Sentinel label reference (mesh labels and their values)</summary>

Log parsers and C2 must handle all of these. Values are taken from `detect.cpp`; anything not listed here is not emitted.

| Mesh prefix | Payload | Enumerated values |
|---|---|---|
| `DEAUTH_FORGE:<src>:<tool>:<rssi>` | tool tag | **static:** `MARAUDER` (reason=2 + seq=0xFFF0 + dur=0x013A - the template shared by ESP32Marauder, Bruce and Evil-M5Project), `MICHAEL_TKIP` (reason=14). **behavioral:** `MDK4`, `ESP_DEAUTHER`, `AIREPLAY`, `BETTERCAP` |
| `DEAUTH_FLOOD:<src>:<count>:<rssi>` | frame count | - |
| `DEAUTH_AP_TARGETED:<client>:<reason>:<count>` | client + reason code | reason is context only, see the table above |
| `BEACON_FORGE:<bssid>:<reason>:<rssi>` | forgery reason | `FORGE_TSF_STATIC`, `FORGE_BI_1000`, `FORGE_SRC_MCAST`, `FORGE_CSA_FF`, `FORGE_QUIET_ELEM`, `FORGE_SSID_ROTATE`, `FORGE_EVIL_PORTAL`, `FORGE_EVIL_PORTAL_ESP`, `FORGE_KARMA_BRUCE` |
| `BEACON_FLOOD:<rssi>` | - | serial line also carries `tool=<reason>` or `tool=-` |
| `EVILTWIN:<bssid>:<reason>:<rssi>:<ssid>` | twin reason | `SELF_CLONE`, `SELF_CLONE_OPEN`, `SSID_COLLISION`, `TWIN_MULTICH`, `TSF_RESTART` |
| `PROBE_FLOOD:<kind>:<what>:<rssi>` | flood kind | `RANDOMIZED`, `SINGLE_MAC`, `MARAUDER` (probe-request template seq=0x0001, fires on one frame) |
| `PROBE_FLOOD_BEHAVE:<ssid>:src=<n>:<rssi>` / `PROBE_FLOOD_AP:...` | - | - |
| `FRAG:<src>:<reason>` | CVE shape | `PN_GAP` (CVE-2020-26146), `MIXED_PLAIN` (CVE-2020-26147) |
| `HSHK:<bssid>:<sta>:<msg>:<replay>:<rssi>` | usable pair | `M1M2` (challenge), `M1M4`, `M2M3`, `M3M4` (authorized) |
| `PMKID_HARVEST:<src>:<bssid>:<rssi>` | tool | serial adds `tool=HCXDUMPTOOL` when the M1 replay counter is in `[0xF000,0xFFFE]` |
| `PMKID_FORGE:<src>:<bssid>:<rssi>` / `PMKID_FORGE:<src>:FAKE_M1:<rssi>` | forge kind | `FORGE_PMKID` (Marauder `BAD_MSG`, fixed PMKID `11 22 … ff 11`), `FAKE_M1` (zero ANonce; serial tag `ROGUE_M1`) |
| `EAPOL_BAIT:<src>:<sta>:<count>:<rssi>:<confidence>` | confidence | `high` (deauth carried a `DEAUTH_FORGE` tool fingerprint **and** EAPOL followed ≤2 s), `medium` (fingerprinted deauth >2 s, or unfingerprinted deauth with EAPOL ≤1 s). An unfingerprinted deauth followed by EAPOL after >1 s is a normal reassociation and does **not** alert |
| `CSA_SPOOF:<bssid>:<switch_count>` | count | fires at `switch_count ≥ 50`; Marauder hardcodes 255 |
| `QUIET_ABUSE:<bssid>:<duration_tu>` | duration | fires at `≥ 1000` TU; Marauder uses 0xFFFF |
| `KARMA_CAND:<bssid>:<distinct_ssids>` / `KARMA_CONFIRMED:<bssid>:<rssi>` | - | candidate at ≥2 distinct SSIDs on one BSSID / 60 s |
| `AUTH_FLOOD:<bssid>:<distinct_src>:<frames>` | - | open-system (algo 0) only; SAE is `SAE_DOS` |
| `SAE_DOS:<bssid>:<unmatched_commits>` | - | - |
| `JAMMING:<ch>:<pdr_pct>:<err_frames>:<noise_floor_dbm>` | - | per-channel, 1 s window, 60 s cooldown. Fires at `pdr < 30%` with `≥15` error frames whose mean RSSI is `> -70` dBm on a channel that carried a valid frame in the last 30 s. `noise_floor_dbm` is the mean `rx_ctrl.noise_floor` over every frame seen on that channel in the window, `0` when no frame reported one. `/jamming.jsonl` additionally carries `err_snr` = mean error-frame RSSI minus noise floor |
| `ASSOC_SLEEP`, `SSID_CONFUSION`, `OWE_ABUSE`, `PWNAGOTCHI`, `RECON`, `ATTACKER_HUNT` | - | single-reason detectors |

**`R:` deauth/disassoc reason codes** (IEEE 802.11-2020 Table 9-49). The value is reported
as context only - since `c0d710d` the reason code is **not** used to decide whether a frame
is an attack, because 1/2/6/7 are all normal causes. Codes seen in practice:

| Code | Meaning | Typical source |
|---|---|---|
| 1 | Unspecified reason | esp8266_deauther template; generic tools |
| 2 | Previous authentication no longer valid | **Marauder / Bruce / Evil-M5 template** (with `seq=0xFFF0`, `dur=0x013A`) |
| 3 | Deauthenticated, STA leaving | normal client roam/disconnect |
| 4 | Disassociated due to inactivity | normal AP housekeeping |
| 5 | Disassociated, AP out of resources | normal AP under load |
| 6 | Class 2 frame from non-authenticated STA | bettercap; also normal |
| 7 | Class 3 frame from non-associated STA | aireplay-ng (with `dur=0x013A`), GhostESP; also normal AP behavior |
| 8 | STA leaving BSS | normal |
| 14 | Michael MIC failure (TKIP) | `MICHAEL_TKIP` forge tag |

Any other value is passed through verbatim as `Reason code N`.

</details>

---

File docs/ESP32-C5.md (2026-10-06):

# ESP32-C5 DIGI Node

> [!WARNING]
> **Testing phase.** Breadboard the C5 and test it before you solder anything — a C5 soldered into a PCB can only be put back on stable firmware by desoldering it and fitting an ESP32-S3 in its place. The C5 build is on the web flasher's **Experimental** channel; the S3 build on `main`/`beta` is the stable one.

The XIAO ESP32-C5 is a drop-in replacement for the XIAO ESP32-S3 on the same AntiHunter PCB — same footprint, same peripherals, same mesh. It adds dual-band Wi-Fi: the C5 radio is 802.11ax on 2.4 GHz **and** 5 GHz, plus BLE. The S3 is 2.4 GHz only.

Everything the S3 node does — target scan, device scanner, probe scanner, baseline, deauth detection, Sentinel, drone RID, CSI motion, packet capture, triangulation, mesh, SD, GPS, vibration wipe — runs on the C5. The rest of this page covers only what differs.

- [Bands and channels](#bands-and-channels)
- [Pinout](#pinout)
- [Build & Flash](#build--flash)
- [Known limits](#known-limits)

---

## Bands and channels

The node has one radio, so it works on one band at a time. Pick the band and it scans only the channels in that band.

| Band | Setting | Scans |
|---|---|---|
| 2.4 GHz | `0` | channels 1–14 |
| 5 GHz | `1` | channels above 14 |
| both | `2` | everything on your channel list |

If your channel list has nothing in the band you pick, the node adds the usual channels for
that band itself. Edit the list under RF Settings.

Change it in the web interface under RF Settings (the Band row appears only on C5 hardware),
or over mesh with `@<NODE> CONFIG_BAND:<0|1|2>`. Stop any running scan first. The setting is
remembered across reboots.

---

## Pinout

Same pads as the S3 node, different GPIO numbers. No wiring change on an assembled PCB.

| Function | Pad | C5 GPIO | S3 GPIO |
|---|---|---|---|
| Mesh UART RX← | D3 | 7 | 4 |
| Mesh UART TX→ | D4 | 23 | 5 |
| Vibration sensor | D1 | 0 | 2 |
| RTC SDA | D2 | 25 | 3 |
| RTC SCL | D5 | 24 | 6 |
| GPS TX→ | D6 | 11 | 43 |
| GPS RX← | D7 | 12 | 44 |
| SD CS | D0 | 1 | 1 |
| SD SCK | D8 | 8 | 7 |
| SD MISO | D9 | 9 | 8 |
| SD MOSI | D10 | 10 | 9 |

---

## Build & Flash

**Web flasher** — [open it](https://lukeswitz.github.io/AntiHunter/), choose the **Experimental — XIAO ESP32-C5** channel, pick Full or Headless, tick the acknowledgement, then Connect & Flash.

**From source:**

```bash
git clone -b feat/c5 https://github.com/lukeswitz/AntiHunter.git
cd AntiHunter
pio run -e AntiHunter-c5-full -t upload        # web UI build
pio run -e AntiHunter-c5-headless -t upload    # serial + mesh only
```

Board `seeed_xiao_esp32c5`, partitions `Dist/partitions_c5.csv`, platform pioarduino. Post-flash setup is identical to the S3 node.

---

## Known limits

- Experimental build — it does not follow the stable release schedule.
- 5 GHz is for scanning only. The node's own Wi-Fi access point stays on 2.4 GHz.
- Changing band briefly restarts that access point, so a browser connected to the node reconnects.

### Motion detection on a C5

**In testing.** It runs and it detects, but against the same labeled walk-ins in the same
room a C5 separates movement from background less cleanly than an S3. The cause is still
open. Prefer an S3 where detection matters.

The default sensitivity differs from the S3's and is not interchangeable with it: the C5
reads a higher idle level, so an S3 value silences it and a C5 value floods an S3. Each chip
carries its own default.

Set sensitivity from the room: read it empty, read it with someone walking, set between the
two. If they overlap, move the node. `CSI_RECAL` restores the default.

---

## Firmware notes

Developer reference. Chip-level detail, open bugs in Espressif's own code, and the exact
fields the firmware reads. Nothing below is needed to set up or run a node.

### Open upstream issues

Open bugs in Espressif's CSI support on C5/C61, none with a fix:

- [esp-idf#18982](https://github.com/espressif/esp-idf/issues/18982) - the 106-byte
  L-LTF buffer does not match the documented two-signed-bytes-per-subcarrier layout.
  Measured on ch6 with `acquire_csi_force_lltf = 1`, 611 raw records: in every 4-byte group
  bytes 1 and 3 stay in 0-15 (16497 and 15886 samples, no exceptions) while bytes 0 and 2
  span the signed range. The buffer is 12-bit words in 2-byte containers, 26 complex
  subcarriers, and `csiAmplitudesLen` decodes it that way through `csiWord12`.
- [esp-idf#18493](https://github.com/espressif/esp-idf/issues/18493) - CSI IQ buffer
  static on 5 GHz. 2.4 GHz is unaffected; CSI here runs on 2.4 GHz.
- [esp-idf#18118](https://github.com/espressif/esp-idf/issues/18118) - 11g PPDUs return
  unchanging CSI on HE-MAC parts, traced to the closed PHY blob.
  `acquire_csi_force_lltf = 1` is the documented workaround. A capture on 2026-09-09
  collapsed to one distinct 106-byte payload over 887 packets and 22 transmitters, so
  this firmware ran with it off; it is now on, which restricts CSI to L-LTF and keeps a
  link's payload length constant. A 300-packet capture on 2026-09-16 held per-subcarrier
  variation of 0.72 to 1.54, so the payloads differ.
- [esp-idf#14271](https://github.com/espressif/esp-idf/issues/14271) - HT-LTF subcarrier
  order differs from the S3 on HE parts. This is reached: a ch6 capture measured 2.71M
  106-byte L-LTF and 454k 114-byte HT-LTF records, so roughly 14% of traffic arrives as
  HT-LTF. It is contained rather than fixed - each link locks to the first payload
  length it sees and rejects the other format, so a link's scorer never mixes the two
  layouts. The counter is reported as `fmtdrop` in the status line.
- [esp-csi#258](https://github.com/espressif/esp-csi/issues/258) - Espressif publishes a
  chip CSI ranking of `C5 > C6 > C3 ~= S3 > ESP32` and has not said what it measures.

#### Why the C5 ingests more

Measured on ch6, same room, same 15s intervals, no SoftAP client on either board:

| per 15s | DSSS | legacy 11g | HT |
|---|---|---|---|
| S3 | 5983-7279 | 1129 | 3-12 |
| C5 | 5983 | 3020 | 194-666 |

The S3 hears more DSSS, so both radios are getting the same air. Ruled out by measurement:
receiver sensitivity (the gap is widest on the strongest frames), STA and AP bandwidth,
the `esp_wifi_set_protocol` bits (`0x07`, 11N on), the promiscuous filter, and
misclassification (`sig_mode==0` frames all read `aggregation=0`, `mcs=0`). Matches
[esp-idf#736](https://github.com/espressif/esp-idf/issues/736), closed on the grounds that no
11n was in the air - here a C5 12 cm away was decoding hundreds per 15s.

Channel-specific, not a chip verdict: on ch1 the same S3 decoded 10120 HT frames, 15.7% of
its OFDM against the C5's 33.6% on ch6. Why ch6 starved it is unexplained. Let the survey
pick the channel.

### CSI field reference

The decoder relies on four documented properties of the C5 CSI path. Source:
[ESP-IDF v5.5.3, Wi-Fi Driver, ESP32-C5](https://docs.espressif.com/projects/esp-idf/en/stable/esp32c5/api-guides/wifi.html).

- "Each item is stored as two bytes: imaginary part followed by real part." `csiAmplitudesLen`
  reads `buf[k*2]` as imaginary and `buf[k*2+1]` as real for that layout. The measured C5
  L-LTF payload does not match it and takes the 12-bit path; see esp-idf#18982 above.
- "If `first_word_invalid` of `wifi_csi_info_t` is true, it means that the first four bytes
  of CSI data is invalid due to a hardware limitation in ESP32-C5." The decoder skips two
  complex words, four bytes, when the flag is set.
- "If `rx_channel_estimate_info_vld` of `rx_ctrl` field is 1, indicates that the CSI data is
  valid; otherwise, the CSI data is invalid." Counted per packet as `ce=<valid>/<invalid>`
  in the status line; `csiRequireCeVld` gates on it.
- `val_scale_cfg`, `esp_wifi_he_types.h:61`: "value 0-8", set to 0. **Open.** C5 reads far
  quieter than S3, same channel and trigger, 30 min: 1.6% over the line against 21.7%. Looks
  like too few quantization steps, which this field should widen. No documented semantics —
  needs testing, not guessing.
- `lltf_bit_mode`, `esp_wifi_he_types.h:63`: "0 : 12-bit, 1 : 8-bit, default : 12-bit".
  `csiArmCsi` sets 0; the 106-byte L-LTF payload is 12-bit words in 2-byte containers and
  `csiAmplitudesLen` decodes it with `csiWord12` (26 subcarriers). The int8-pair path stays
  for the other buffer lengths.

`CSIR` raw dump lines end with `,L<len>,F<0|1>` - the packet's `ev.len` and `first_word_invalid`.
Without them a capture cannot be decoded correctly, because the values are dumped as a fixed
114-byte buffer while only `len` bytes are valid.

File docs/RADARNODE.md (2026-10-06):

# RadarNode

> [!WARNING]
> **Experimental.** The radar path works — detection, RF enrichment, web UI and mesh all run — but the firmware is unreleased: no branch is published yet, no web-flasher entry, no release binaries. Source link: _(branch not yet pushed)_.

A 24GHz radar node that detects a moving target, then sweeps Wi-Fi and BLE to record which devices were present at that moment. It joins the same LoRa mesh as DIGI nodes and appears in their node lists.

Separate firmware from the DIGI node — different sensor, different app, same PCB and same mesh.

- [How it works](#how-it-works)
- [Hardware](#hardware)
- [Build & Flash](#build--flash)
- [Web UI](#web-ui)
- [Configuration](#configuration)
- [Mesh Commands](#mesh-commands)
- [Mesh Output](#mesh-output)
- [API Reference](#api-reference)

---

## How it works

The radar is the primary sensor and runs continuously. Wi-Fi/BLE scanning is not a separate mode you launch — it is enrichment triggered by the radar.

```
HLK-LD2451 frame  ──►  radarTask
                         │  IDLE ──► TRIGGERED ──► LINGER ──► IDLE
                         │                │
                         │                ├─► detection logged to SD + mesh
                         │                └─► RF sweep (if enabled, past cooldown)
                         ▼                        │
                    traffic baseline              ├─ BLE scan
                                                  └─ Wi-Fi scan (2.4 + 5GHz)
                                                        │
                                                        ▼
                                              candidates scored, top 3 meshed
```

A detection record holds both halves: distance, speed, angle, direction and target class from the radar, plus the Wi-Fi/BLE candidates seen at that instant.

**State machine**

| State | Meaning |
|---|---|
| `IDLE` | No target |
| `TRIGGERED` | Target confirmed, detection recorded |
| `LINGER` | Target lost, holding before returning to idle (default 3 s) |

**Target classes** — `UNKNOWN`, `PERSON`, `VEHICLE`, voted over a 12-frame rolling history rather than per-frame, so one noisy frame cannot flip the class. `PERSON` scores on speeds up to 8 km/h and is weighted up by speed and angle variance (gait); `VEHICLE` scores from 15 km/h up and is weighted up by track stability. Both are scaled by SNR confidence, and `VEHICLE` is suppressed inside 5 m.

**Alarm** — fires only when every gate passes: the target is approaching, within Alarm Distance, at or above Alarm Speed, within `±ANG` of boresight, and of the class selected by `CLS`. Angle and class default to open (90°, any class), so out of the box only distance, speed and direction decide. Both are set over mesh with `RADAR_CONFIG` and persist across reboot.

**Traffic baseline** — learns ambient detection rate and device count over a chosen window, then reports how current activity compares. Radar events feed the detection rate; each RF sweep feeds the device count.

---

## Hardware

XIAO ESP32-C5 on the standard AntiHunter PCB. The HLK-LD2451 takes the RTC's footprint — the RTC is removed on a RadarNode.

| Function | Pin | GPIO | Notes |
|---|---|---|---|
| Mesh UART TX→ | D3 | 7 | to Meshtastic radio RX |
| Mesh UART RX← | D4 | 23 | from Meshtastic radio TX |
| Radar RX← | D2 | 25 | from HLK **TX** — old RTC **Data**/SDA pad |
| Radar TX→ | D5 | 24 | to HLK **RX** — old RTC **Clock**/SCL pad |
| GPS RX← | D7 | 12 | from GPS TX (SoftwareSerial) |
| GPS TX→ | D6 | 11 | to GPS RX |
| SD CS | D0 | 1 | |
| SD SCK | D8 | 8 | |
| SD MISO | D9 | 9 | |
| SD MOSI | D10 | 10 | |

The C5 has two hardware UARTs. Mesh takes UART0 and radar takes UART1, so GPS runs on SoftwareSerial at 9600 — the C5's LP_UART pins are fixed to back pads the XIAO does not break out.

### Wiring the HLK-LD2451

Two wires into the RTC header. Power comes from the fan rail, not from this header:

| RTC header pin | Connect to |
|---|---|
| **Data** (SDA) | HLK **TX** |
| **Clock** (SCL) | HLK **RX** |
| **GND** | leave empty |
| Vcc | leave empty |
| NC | leave empty |

> [!IMPORTANT]
> The HLK-LD2451 needs **5 V at 300 mA or more** — more than the XIAO's 3V3 pin can supply. Its IO is 3.3 V, so the two data lines connect directly with no level shifting.
>
> **Do not take the radar's ground from the RTC header.** A bench supply grounded there does not work. Take both 5 V and ground from the board's fan rail (+/-), jumping the thermal switch to reach it.

Serial at boot confirms the link:

```
[RADAR] Starting sensor RX=GPIO25 TX=GPIO24 @ 115200
[RADAR] after reset -> maxDist=60m dir=2 minSpd=1km/h
```

`maxDist=0 ... (0/1=no-response)` means the sensor is not answering — check TX/RX orientation first, then that power and ground come from the fan rail rather than the RTC header, then whether the 5 V rail holds under load.

---

## Build & Flash

```bash
pio run -e RadarNode-c5 -t upload
```

Or via the Makefile:

```bash
make build-radar     # build
make lint-radar      # cppcheck
```

All environments build on one platform (pioarduino). Mixing in `espressif32@6.x` breaks the build — both platforms claim the `framework-arduinoespressif32` package directory at different versions and overwrite each other.

---

## Web UI

The node hosts its own access point. Connect and browse to `http://192.168.4.1/`.

The default AP name is `RN-` plus the last MAC bytes; SSID and password are changeable in Config. The node ID is `RN` plus four hex digits.

| Panel | Shows |
|---|---|
| Scope | Live PPI sweep — range rings to 100 m, 20° field of view, target track and callout |
| Distance / Speed / Heatmap | Rolling detection history |
| RF Enrichment | Candidates from the last sweep — score, band, MAC, name, manufacturer, signal bars, dBm |
| Traffic Baseline | Learning state and how current activity compares to the learned ambient |
| DiGI Mesh | Nodes seen on the mesh, typed `RADAR` or `DIGI` |
| Detection Log | Per-detection records, expandable to the candidates captured with each |

**Header controls** — theme toggle (light/dark), redaction toggle, Config panel.

**Redaction** replaces MACs with `XX:XX` and device names with `REDACTED` for screenshots. Manufacturer and class labels stay visible, so `Handoff`, `Nearby-Action` and similar remain readable. The setting persists in the browser.

**Column width** — drag the divider between the scope and the results. Double-click resets it.

---

## Configuration

Config panel, or `POST /api/radar/config`. Values persist to NVS.

### Detection

| Setting | Range | Default | Meaning |
|---|---|---|---|
| Max Distance | 1–100 m | 60 | Ignore targets beyond this range |
| Direction | away / towards / both | both | Which way a target must travel to count |
| Min Speed | 0–250 km/h | 1 | Slower targets are ignored |
| Report Delay | 0–255 | 1 | Sensor-side hold before reporting |

### Sensitivity

| Setting | Range | Default | Meaning |
|---|---|---|---|
| Trigger Count | 1–10 | 1 | Consecutive hits before a target is reported |
| SNR Threshold | 0–8 | 4 | Lower triggers more easily |

### Alarm

| Setting | Range | Default |
|---|---|---|
| Alarm Distance | 1–100 m | 50 |
| Alarm Speed | 0–80 m/s | 5 |

### RF Enrichment

| Setting | Range | Default | Meaning |
|---|---|---|---|
| Enabled | on/off | on | Sweep BLE + Wi-Fi on a radar trigger |
| Sweep Cooldown | 0–600 s | 15 | Minimum gap between sweeps |
| Linger | 1–60 s | 3 | Hold TRIGGERED after the last frame |
| RSSI Floor | −100…−30 dBm | −95 | Drop weaker devices — about 100 m line of sight, matching radar range |
| BLE Dwell | 500–10000 ms | 2000 | Listen window per sweep |

**Sweep now** forces a sweep regardless of radar state or cooldown, including when enrichment is off. The serial console does the same on `s`; `d` prints peripheral diagnostics.

---

## Mesh Commands

Addressed as `@ALL <CMD>` or `@<NODEID> <CMD>`.

| Command | Effect | Reply |
|---|---|---|
| `STATUS` | Report state | `STATUS: TYPE:RADAR …` |
| `SCAN_START:<n>` | Force an RF sweep | `SCAN_ACK:STARTED` |
| `STOP` | Stop the running sweep | `STOP_ACK:OK` |
| `BASELINE:START[:secs]` | Start learning (default 300 s, floor 60 s) | `BASELINE:ACK:START:<secs>` |
| `BASELINE:STOP` | Stop learning | `BASELINE:ACK:STOP` |
| `BASELINE:STATUS` | Baseline state as JSON | `BASELINE:STATUS:{…}` |
| `RADAR_CONFIG:DIST=<m> SPD=<m/s> ANG=<deg> CLS=<0-2>` | Set alarm thresholds | `RADAR_CONFIG_ACK:OK …` or `:ERR` |
| `TIME_SYNC_REQ:` | Clock sync | `TIME_SYNC_RESP:<epoch>:0:<micros>:0` |

`RADAR_CONFIG` bounds: `DIST` 0–200 m, `SPD` 0–50 m/s, `ANG` 0–90°, `CLS` 0–2. Out of range returns `RADAR_CONFIG_ACK:ERR Invalid params` and changes nothing.

`ANG` narrows the alarm to targets within `±ANG` of boresight. `CLS` restricts it to one class — `0` any, `1` person, `2` vehicle. Because the class is voted over a rolling history, the first frames of a new track read `UNKNOWN` and will not alarm while `CLS` is non-zero.

---

## Mesh Output

```
<NODEID>: STARTUP: System initialized GPS:<state> TEMP: <c>C / <f>F
<NODEID>: STATUS: TYPE:RADAR RADAR:<state> SCAN:<Y|N> GPS:<state> Temp:<c>C Up:<s> DETS:<n> ALMS:<n>
<NODEID> DET <dist>m <speed>km/h <angle>° <twd|awy> <CLASS>[ ALARM]
<NODEID> SCAN done: <n> WiFi <n> BLE <n> moving
<NODEID> CAND<1-3> <MAC> <rssi>dBm <WiFi|BLE> [label][ mov]
```

`TYPE:RADAR` is how the RadarNode's own mesh list and the Command Center tell a RadarNode from a DIGI node. A peer reporting no `TYPE` field is treated as DIGI. DIGI firmware does not read the field.

At most **three** candidates are sent per detection, ranked by score, to bound mesh traffic.

---

## API Reference

| Method | Endpoint | Purpose |
|---|---|---|
| GET | `/` | Web UI |
| GET | `/api/info` | Node ID, IP, timestamp, GPS state |
| GET | `/api/diag` | Peripheral diagnostics |
| GET | `/api/radar/stats` | Detection and alarm counters |
| GET | `/api/radar/config` | Current configuration |
| POST | `/api/radar/config` | Set configuration |
| POST | `/api/scan` | Force a sweep |
| GET | `/api/events` | Recent detection events |
| GET | `/api/detlog.jsonl` | Detection log, JSON lines |
| DELETE | `/api/detlog` | Clear the detection log |
| GET | `/api/log.csv` | Radar samples as CSV |
| GET | `/api/baseline` | Baseline state |
| POST | `/api/baseline/start` | Start learning — `{"duration":<min>}` |
| POST | `/api/baseline/stop` | Stop learning |
| GET | `/api/mesh` | Known mesh peers |
| POST | `/api/mesh/status-all` | Broadcast `@ALL STATUS` |
| POST | `/api/config` | AP SSID and password |
| POST | `/api/restart` | Reboot |

WebSockets: `/ws` radar samples, `/scanws` sweep results, `/log` console.

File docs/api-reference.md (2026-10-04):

# API Reference

Full HTTP API for the Full firmware's web server.
Back to the [README](../README.md).

> [!NOTE]
> Timestamps show local time from the GPS fix, with daylight saving applied. Without a GPS lock they show UTC. Fields named `epoch` are UTC seconds.

### Core

| Endpoint | Method | Description |
|---|---|---|
| `/` | GET | Web interface |
| `/diag` | GET | System diagnostics |
| `/stop` | GET | Fast-abort every scan/task: aborts in-flight Wi-Fi/BLE scans, stops triangulation, cancels mesh drain. `/diag` reports `Stopping: yes` until the task actually exits |
| `/config` | GET/POST | System configuration (JSON) |
| `/clear-results` | POST | Clear all scan results |

### Scanning

| Endpoint | Method | Description |
|---|---|---|
| `/scan` | POST | Start target scan (`mode`, `secs`, `forever`, `ch`, `triangulate`, `targetMac`). With `triangulate=1`, returns `400` and the reason if triangulation cannot start (bad/empty `targetMac`, debounce, busy task) |
| `/sniffer` | POST | Start detection scan (`detection`, `secs`, `forever`, `randomizationMode`, `probeScanMode`, `captureProbes`) |
| `/drone` | POST | Start drone RID detection (`secs`, `forever`) |
| `/pcap/status` | GET | Capture state (JSON): active, radio, band, channel, frames, bytes, dropped, elapsed, current file, `dualBand`, SD budget/floor/free in MB |
| `/pcap/list` | GET | Captures in `/pcap` (JSON): name, size, and whether that file is still being written |
| `/pcap/download` | GET | Streams a capture. `f=<name>` selects one, omit it for the most recent |
| `/pcap/delete` | POST | Deletes one capture (`f`). Refused while that file is recording |
| `/pcap/delete-all` | POST | Deletes every capture in `/pcap` |
| `/pcap/limits` | POST | Auto-capture pruning (`budgetMB`, `floorMB`), persisted |

### Results

| Endpoint | Method | Description |
|---|---|---|
| `/results` | GET | Latest scan/triangulation results |
| `/sniffer-cache` | GET | Cached device detections |
| `/deauth-results` | GET | Deauth attack logs |
| `/randomization-results` | GET | Randomization correlation results |
| `/drone-results` | GET | Drone detection results |
| `/drone-log` | GET | Drone event log (JSON) |

### Fleet

The **Fleet** tab lists senders heard on the mesh.

**Nodes** - ids matching the node-id rule (2-5 chars, `A-Z0-9`), with mode, scan state, hits, uptime, temp
and GPS from their `STATUS` and heartbeat lines. `type` is `RADAR` on `TYPE:RADAR`, else `DIGI`. Online =
heard within 2 minutes.

**Other Mesh Radios** - every other sender id, including your own paired radio. Tagged `Control` once an
`@` line is seen from it, `Unknown` otherwise. Also shown in the Sentinel tab.

Rosters hold 48 entries in RAM, dropped after 15 minutes unheard. **Ping Nodes** broadcasts `@ALL STATUS`.

| Endpoint | Method | Description |
|---|---|---|
| `/api/mesh` | GET | Fleet roster (JSON: `node`, `peers`, `radios`) |
| `/api/mesh/ping` | POST | Broadcast `@ALL STATUS` |
| `/api/mesh/clear` | POST | Clear both rosters |

### Probe Database

| Endpoint | Method | Description |
|---|---|---|
| `/api/probedb` | GET | Probe database (JSON: mac, vendor, name, SSIDs, RSSI, randomization status) |
| `/api/probedb/clear` | POST | Clear probe database |
| `/api/probes.jsonl` | GET | Stream probe log from SD (JSONL) |

`vendor` is the IEEE OUI-registered organization, resolved from the first 24 bits of the MAC.
`name` is the device's advertised BLE name. Randomized (locally administered) MACs carry no OUI
assignment and resolve to no vendor.

### Device Database

Every device seen by a Device Discovery or target scan is merged into `/devicedb.jsonl` on SD and
survives reboots. Capped at 2000 entries; the least recently seen entry is evicted when full.

| Endpoint | Method | Description |
|---|---|---|
| `/api/devicedb` | GET | All discovered devices (JSON: mac, ble, vendor, name, rssi, ch, sessions, seen, first, last, rand) |
| `/api/devicedb/clear` | POST | Clear device database |

### Data Explorer

The **Data** tab in the web UI provides a searchable, sortable view of all SD-logged scan data. Select a dataset from the dropdown, search across any column, click column headers to sort, and page through results.

| Endpoint | Method | Description |
|---|---|---|
| `/api/deauth.jsonl` | GET | Deauth/disassoc attack log (JSONL) |
| `/api/deauth/clear` | POST | Clear deauth log (RAM + SD) |
| `/api/drones.jsonl` | GET | Drone RID detection log (JSONL) |
| `/api/drones/clear` | POST | Clear drone log (RAM + SD) |
| `/api/vibrations.jsonl` | GET | Vibration/tamper event log (JSONL) |
| `/api/vibrations/clear` | POST | Clear vibration log (SD) |
| `/api/antihunter.log` | GET | System event log (text) |
| `/api/antihunter.log/clear` | POST | Clear system log |

Available datasets: All Discovered Devices, Probe Devices, Probe Events, Deauth Attacks, Drone Detections, Vibration Events, Baseline Stats, Sentinel Incidents, and System Log. All datasets support export (download the raw file) and clear (with confirmation). The headless firmware logs the same data to SD without the web UI, except the device database, which is web-build only.

**Endpoints not listed above.** Each detector keeps its own SD log at `/api/<detector>.jsonl`, and most take a `/api/<detector>/clear` POST. Current detectors: `assoc_sleep`, `ble_attack`, `ble_malformed`, `deauth_ap`, `deauth_flood`, `eapol_bait`, `eviltwin`, `fragattack`, `jamming`, `meshguard`, `owe_abuse`, `pmkid`, `pmkid_forge`, `probe_ap`, `probe_flood`, `sae_dos`, `ssid_confusion`. A few return live JSON instead of a file: `/api/tsf_skew`, `/api/pwnagotchi`, `/api/recon`, `/api/karma`, `/api/handshakes`, `/api/attacker_hunts`. `GET /diag` dumps runtime state. For anything else, the full route list is the set of `server->on(` calls in `Antihunter/full/src/network.cpp`.

<details>
<summary>Configuration Endpoints</summary>

| Endpoint | Method | Description |
|---|---|---|
| `/node-id` | GET/POST | Get/set node ID (2-5 alphanumeric, A-Z 0-9) |
| `/mesh-interval` | GET/POST | Get/set mesh send interval (1500-30000ms) |
| `/save` | POST | Save target configuration |
| `/export` | GET | Export target MAC list |
| `/allowlist-export` | GET | Export allowlist |
| `/allowlist-save` | POST | Save allowlist |
| `/api/time` | POST | Set RTC time from Unix timestamp |

</details>

<details>
<summary>Sentinel / Detection Endpoints</summary>

| Endpoint | Method | Description |
|---|---|---|
| `/api/detect/config` | GET | Current detector config (JSON: every detector enable, mesh-broadcast flag, threshold) |
| `/api/detect/config` | POST | Set detector config. JSON body of `{key:bool/int}` - same keys returned by GET (e.g. `pmkid`, `eviltwin`, `sae`, `karma`, `probe_flood`, `assoc_sleep`, `mesh_*` flags, thresholds). The Web Flasher/Configurator sends these under a nested `detectors` object at flash time. |
| `/api/detect/health` | GET | Detector runtime health (heap, queue depth, drops, per-detector counts) |
| `/api/sentinel/status` | GET | Sentinel running state |
| `/api/sentinel/start` / `/api/sentinel/stop` | POST | Start/stop the Sentinel engine |
| `/api/incidents.json` | GET | Recent incident ring (JSON) |
| `/api/incidents.jsonl` | GET | Full incident log from SD (JSONL) |
| `/api/incidents` | DELETE | Clear all incidents (RAM + SD) |
| `/api/mesh_cmd.jsonl` | GET | Mesh command provenance audit from SD (JSONL: `ts`, `epoch`, `src` radio id, `cmd`) |
| `/api/mesh_cmd` | DELETE | Clear the mesh command audit log |
| `/api/apclients.json` | GET | Stations associated to this node's AP |

Each incident record carries: `ts` (device uptime ms), **`epoch`** (RTC Unix seconds - `0` if RTC unset; used by the Analysis tab to show real timestamps), `node`, `src`, `type`, `raw`.

Persistent boot setting: `sentinelBoot` (bool) in the configurator JSON / NVS pref `sentBoot` - auto-starts the Sentinel at power-on when true.

</details>

<details>
<summary>RF Configuration Endpoints</summary>

| Endpoint | Method | Parameters | Description |
|---|---|---|---|
| `/rf-config` | GET | - | RF config (JSON) |
| `/rf-config` | POST | `preset` (0-2) | Apply preset: 0=Relaxed, 1=Balanced, 2=Aggressive |
| `/rf-config` | POST | `wifiChannelTime`, `wifiScanInterval`, `bleScanInterval`, `bleScanDuration`, `wifiChannels`, `globalRssiThreshold` | Full custom config |
| `/rf-config` | POST | `globalRssiThreshold` (-100 to -10) | RSSI threshold only |
| `/rf-config` | POST | `bandMode` (0-2) | **C5 only.** Band: 0=2.4GHz, 1=5GHz, 2=both. Also returned by GET, and accepted on `/config` GET/POST and in the serial `CONFIG:` JSON |
| `/wifi-config` | GET | - | Wi-Fi AP settings (JSON) |
| `/wifi-config` | POST | `ssid` (1-32), `pass` (8-63 or empty), `auth` (0=WPA2/WPA3, 1=WPA2), `hidden` (0/1) | Update AP credentials and mode (triggers reboot). `hidden=1` stops the SSID beacon; clients must then enter the SSID manually and will probe for it by name, so the network name travels with them. Auth remains the access control |

</details>

<details>
<summary>Baseline Endpoints</summary>

| Endpoint | Method | Description |
|---|---|---|
| `/baseline/status` | GET | Baseline scan status (JSON) |
| `/baseline/stats` | GET | Baseline statistics (JSON) |
| `/baseline/config` | GET/POST | Baseline config (`rssiThreshold`, `baselineDuration`, `ramCacheSize`, `sdMaxDevices`, `absenceThreshold`, `reappearanceWindow`, `rssiChangeDelta`) |
| `/baseline/reset` | POST | Reset baseline |
| `/baseline/mark` | POST | Watch for changes from now; 409 if no baseline is running |

</details>

<details>
<summary>Triangulation Endpoints</summary>

| Endpoint | Method | Description |
|---|---|---|
| `/triangulate/start` | POST | Start (`mac`, `duration`, `rfEnv`, optional `wifiPwr`/`blePwr` 0.1-5.0); `400` + reason if it cannot start |
| `/triangulate/stop` | POST | Stop triangulation |
| `/triangulate/status` | GET | Status (JSON) |
| `/triangulate/results` | GET | Results |
| `/triangulate/nodes` | GET | Connected triangulation nodes |
| `/triangulate/calibrate` | POST | Calibrate path loss (`mac`, `distance`) |

</details>

<details>
<summary>Randomization, Security, and Hardware Endpoints</summary>

**Randomization:**

| Endpoint | Method | Description |
|---|---|---|
| `/randomization/reset` | POST | Reset randomization detection |
| `/randomization/clear-old` | POST | Clear old identities (optional `age`) |
| `/randomization/identities` | GET | Tracked identities (JSON) |

**Security:**

| Endpoint | Method | Description |
|---|---|---|
| `/erase/status` | GET | Erasure status |
| `/erase/request` | POST | Request secure erase (`confirm`=WIPE_ALL_DATA, optional `reason`) |
| `/erase/cancel` | POST | Cancel erase sequence |
| `/secure/status` | GET | Tamper detection status |
| `/secure/abort` | POST | Abort tamper sequence |
| `/config/autoerase` | GET/POST | Auto-erase config |
| `/battery-saver` | GET | Battery saver (`action`=start/stop/status, `interval`) |

**Hardware:**

| Endpoint | Method | Description |
|---|---|---|
| `/gps` | GET | GPS status and location |
| `/sd-status` | GET | SD card status |
| `/drone/status` | GET | Drone detection status (JSON) |
| `/mesh` | POST | Enable/disable mesh |
| `/mesh-test` | GET | Test mesh connectivity |
| `/mesh-hb` | POST | Enable/disable heartbeat (`enabled=true\|false`) |
| `/mesh-hb-interval` | POST | Set heartbeat interval (`interval=1-60` minutes) |
| `/vibration` | POST | Toggle vibration sensor |

</details>

---

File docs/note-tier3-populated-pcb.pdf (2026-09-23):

## AntiHunter

P E R I M E T E R D E F E N S E S Y S T E M S

Tier 3 · Populated PCB

# DIGI Node — Tier 3: Populated PCB

A fully assembled PCB, soldered and bench-tested with its factory antennas. Meshtastic is flashed on the radio, and the radio’s serial link to the node is already configured.

### In the box

- Populated 82 mm PCB with an 8 GB microSD fitted
- Factory U.FL antennas: flat 2.4 GHz film, coiled LoRa whip, ceramic GPS patch
You supply: power over USB or your own regulated 5 V supply, and a housing if you want one.

### Set it up

1. Fit the three U.FL antennas:
- GPS patch → GPS module
- Long black whip → LoRa radio
- Film antenna marked “2.4GHz” → XIAO ESP32-S3
Hold each connector parallel to the board, line up the rims and press straight down until it clicks. Pressing at an angle can crush the socket, and a crushed socket means replacing the module.
2. Flash AntiHunter on the ESP32 over USB with the web flasher at lukeswitz.github.io/AntiHunter. Choose Full for the web UI or Headless for quiet field operation.
3. Set the LoRa region on the radio. The region is UNSET when the unit leaves the bench. Until you set it the radio only receives, and the node will not answer over mesh.
4. Change the radio’s Bluetooth pairing PIN, because every unit leaves the bench with the same one.
5. Make your own encrypted Meshtastic channel the primary channel and turn the public default channel off.
6. Full firmware only: join the Antihunter WiFi AP (password antihunt3r123), open http://192.168.4.1 and change these credentials before doing anything else.

Never power the node without the LoRa antenna attached.

### Power

- Use a regulated 5 V supply only: USB, a bench supply set to 5 V, a proper DC-DC regulator or a UPS board.
- Never wire 18650 cells or an unregulated supply to the PCB.
- The node becomes unstable below 4.5 V.
- Connect one USB cable at a time. The ESP32 and the radio share the power rails.

### Full guide

For each step above in detail, plus antennas, all detectors, the vibration sensor, mesh commands and Command Center, see the Operator’s Guide: github.com/lukeswitz/AntiHunter/blob/main/docs/AntiHunter-Operators-Guide.pdf (https://github.com/lukeswitz/AntiHunter/blob/main/docs/AntiHunter-Operators-Guide.pdf)
- Enclosure STLs, assembly manual: github.com/lukeswitz/AntiHunter, hw folder
- Firmware, docs, issues: github.com/lukeswitz/AntiHunter
- Command Center: github.com/TheRealSirHaXalot/AntiHunter-Command-Control-PRO
AntiHunter DIGI Node | 1 / 1

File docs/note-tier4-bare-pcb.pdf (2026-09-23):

## AntiHunter

P E R I M E T E R D E F E N S E S Y S T E M S

Tier 4 · Bare PCB

# DIGI Node — Tier 4: Bare PCB

In the box: bare AntiHunter DIGI Node PCB.

## Source the parts

The full bill of materials, with part links and photos, is in github.com/lukeswitz/AntiHunter → hw folder → BOM-Links.md. The core parts are:
Function | Part | Function | Part
MCU | XIAO ESP32-S3 | Vibration sensor | SW-420
LoRa radio | Heltec V3.2 or T114 | Storage | Micro SD reader, SD card up to 16 GB formatted FAT32
GPS | ATGM336H | Thermal switch | KSD9700, 40 °C
Real-time clock | DS3231 | External 5 V input | Waterproof Type-C female chassis jack

## Build it

1. Follow the assembly manual from start to finish: github.com/lukeswitz/AntiHunter → hw folder → Antihunter-
DIGINODE-AssemblyManual.pdf
2. Two modules need their headers modified first (manual, page 6):
- The RTC comes with female headers.
- Some tamper sensors come with inverted 90° headers.
3. Fit the SD card before you close the case. The slot cannot be reached once the PCB is mounted.

## Flash it

4. Flash the Heltec V3.2 or T114 with the latest stable Meshtastic from flasher.meshtastic.org, then set up the serial module as below. Without these settings the node and the radio cannot communicate. scripts/ meshtastic_config.py in the repo applies them for you.
Setting | Heltec V3 | T114
Serial module | Enabled | Enabled
Mode | TEXTMSG | TEXTMSG
Baud | 115200 | 115200
RX / TX pins | 19 / 20 | 10 / 9
5. Flash AntiHunter on the ESP32 over USB with the web flasher at lukeswitz.github.io/AntiHunter. Choose Full for the web UI or Headless for quiet field operation.
6. Set the LoRa region and change the Bluetooth pairing PIN. Make your own encrypted channel the primary channel and turn the public default off.
7. Full firmware only: join the Antihunter WiFi AP (password antihunt3r123), open http://192.168.4.1 and change these credentials before doing anything else.

## Power

- Use a regulated 5 V supply only: USB, a bench supply set to 5 V, a proper DC-DC regulator or a UPS board.
- Never wire 18650 cells or an unregulated supply to the PCB.

Never power the node without the LoRa antenna attached. Connect one USB cable at a time: the ESP32 and the radio share the power rails.

## Full guide

For unboxing through deployment, antennas, all detectors, the vibration sensor, mesh commands and Command Center, see the Operator’s Guide: github.com/lukeswitz/AntiHunter/blob/main/docs/AntiHunter-Operators-Guide.pdf
- Firmware, docs, issues: github.com/lukeswitz/AntiHunter
- Command Center: github.com/TheRealSirHaXalot/AntiHunter-Command-Control-PRO
AntiHunter DIGI Node | 1 / 1

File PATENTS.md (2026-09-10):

# Patents

Notice published under 35 U.S.C. § 287(a).

## Pending applications

**AntiHunter DIGI detection node** — assembled units, populated boards, and this firmware.

U.S. provisional patent application **64/151,838**, filed 10 September 2026.
"Transceiver arbitration in a wireless detection node."

## What is claimed

The pending application is directed to:

- Arbitration of a single radio transceiver between a detection function and a triggered
  investigative response, where dissimilar triggering events are reduced to one internal
  command representation, a response is armed in a register, execution is deferred until
  the transceiver is free, one response runs per interval of availability, and an armed
  response is abandoned rather than acted upon once its triggering intelligence is stale.
- Visitation of a radio channel by scan request bearing a home-channel dwell time, so the
  transceiver leaves the channel of an access point service it operates and returns
  without loss of the associated station.

Not every feature of AntiHunter is the subject of the pending application. Nothing here
should be read as a claim to subject matter that is not.

## Relationship to the AGPL

This firmware is distributed under the GNU Affero General Public License v3.0. **Section 11
of that licence grants every recipient of this code a patent licence to the essential
patent claims of the copyright holder that read on the code as conveyed.** That grant is
irrevocable and royalty-free, and this notice does not narrow it.

In plain terms: if you comply with the AGPL, the pending application gives you nothing to
worry about. It exists to address parties who take the methods without taking the licence.

## Contact

devteam@rootdowndigital.com

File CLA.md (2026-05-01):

# AntiHunter Individual Contributor License Agreement (CLA)

Thank you for your interest in contributing to AntiHunter ("the Project"),
maintained by Luke Switzer ("the Maintainer"). This Contributor License
Agreement ("Agreement") documents the rights granted by contributors to the
Maintainer. This is a legally binding document, so please read it carefully
before agreeing.

## 1. Definitions

**"Contribution"** means any original work of authorship, including any
modifications or additions to an existing work, that you intentionally submit
to the Project for inclusion. "Submit" means any form of electronic or written
communication sent to the Project, including but not limited to pull requests,
patches, issues with attached code, and commits pushed to Project repositories.

**"You" (or "Your")** means the individual copyright owner who is making this
Agreement with the Maintainer.

## 2. Grant of Copyright License

You hereby grant to the Maintainer a perpetual, worldwide, non-exclusive,
no-charge, royalty-free, irrevocable copyright license to reproduce, prepare
derivative works of, publicly display, publicly perform, sublicense, and
distribute Your Contributions and such derivative works.

## 3. Grant of Patent License

You hereby grant to the Maintainer a perpetual, worldwide, non-exclusive,
no-charge, royalty-free, irrevocable patent license to make, have made, use,
offer to sell, sell, import, and otherwise transfer Your Contributions, where
such license applies only to those patent claims licensable by You that are
necessarily infringed by Your Contribution(s) alone or by combination of Your
Contribution(s) with the Project.

## 4. Dual-Licensing Right

You acknowledge and agree that the Maintainer may, at their sole discretion,
offer the Project (including Your Contributions) under additional license terms,
including commercial licenses, without further permission from or compensation
to You.

## 5. Representations

You represent that:

- Each Contribution is Your original creation.
- You have the legal authority to enter into this Agreement.
- Your Contribution does not violate any third-party rights.
- If Your employer has rights to intellectual property that You create, You have
  received permission to make the Contribution on behalf of that employer, or
  Your employer has waived such rights.

## 6. "As-Is" Contributions

You provide Your Contributions on an "AS IS" BASIS, WITHOUT WARRANTIES OR
CONDITIONS OF ANY KIND, either express or implied.

## 7. Notification

You agree to notify the Maintainer if You become aware of any facts or
circumstances that would make these representations inaccurate.

---

## How to Sign

Add your name below via pull request, or reply to the relicensing issue/email
with "I agree to the AntiHunter CLA" and your GitHub username.

### Signatories

| GitHub Username | Name | Date |
|---|---|---|
| @lukeswitz | Luke Switzer | 2026-04-30 |

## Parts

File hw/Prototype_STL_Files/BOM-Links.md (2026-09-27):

## DIGI Node — BOM Links
> [!NOTE]
> No affiliate links. These links are for reference only and may change.
>
> Product images are sourced from their respective manufacturers or retailers and remain the property of their owners. They are used here solely for part identification — no ownership or endorsement is implied.

**Link key:** `MFR` manufacturer/OEM · `AMZN` Amazon (US) · `ALI` AliExpress (cheapest, live search) · `ALT` other verified reseller

## AntiHunter DIGI Node — Bill of Materials

Full parts list for a complete node. Which of these come in a bought tier: [Deployment Steps by Tier](https://github.com/lukeswitz/AntiHunter/blob/beta/README.md#deployment-steps-by-tier).

### Core Electronics
| Qty | Part |
|-----|---|
| 1× | DIGI PCB |
| 1× | Seeed XIAO ESP32-S3 (2.4 GHz) |
| 1× | Heltec WiFi LoRa 32 V3.2 |
| 1× | ATGM336H GPS Module |
| 1× | DS3231 RTC Module |
| 1× | SW-420 Vibration Sensor |
| 1× | MicroSD SPI Reader Module |
| 1× | MicroSD Card — 8 GB, FAT32 (32 GB+ not recommended) |

### Power & Enclosure
| Qty | Part |
|-----|---|
| 1× | Type-C 15W 3A 5V UPS (2S 18650) |
| 1× | Type-C Female Chassis Jack — waterproof, 2-pin 22 AWG |
| 1× | 30mm 5V JST Fan (7-10mm)|
| 1× | 3-Pin Mini On/Off Switch (6mm) |
| 2× | JST Power Male Cables (switch, power board) |
| 1× | KSD9700 Thermal Switch — Normally Open, 30–40°C |
| 2× | 18650 Cells — protected, flat-top (not supplied with any tier) |
| 1× | Weatherproof Enclosure |
| 1× | TPU Seal Kit — housing, USB-C, GPS antenna |

### Antennas & Cables
| Qty | Part |
|-----|---|
| 3× | U.FL → SMA Pigtail |
| 1× | 6dBi 2.4GHz Antenna |
| 1× | 6dBi LoRa Antenna |
| 1× | GNSS Antenna — Active L1, SMA |

### Fasteners & Hardware
| Qty | Part |
|-----|---|
| 10× | M3 Heat-Set Inserts |
| 2× | M3×15mm Brass Standoffs |
| 8× + 6× | M3×4-6mm Flat-Top Screws (enclosure lids) + M3×4-6mm Screws (PCB / front-rear covers) |
| 4× | M2 Heat-Set Inserts (power board) |
| 4× | M2×4-6mm Screws (power board) |
| 2–4× | M2.5 13–15mm Screws (fan) |
| 5× | JST 2.54 2-Pin Terminals |
| 1× | 1/4" Tripod Insert |

---

## Core Electronics

| Qty | Part | Image | MFR | AMZN | ALI / ALT |
|:---:|---|:---:|---|---|---|
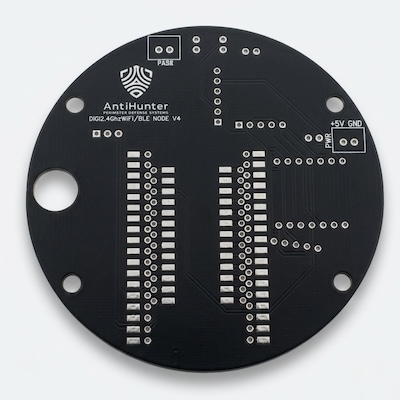
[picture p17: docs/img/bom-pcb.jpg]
pcb
| 1× | **DIGI PCB**  |  | [AntiHunter - Lectronz Store](https://lectronz.com/products/antihunter-diginode-24ghz-wifible-pcb-only) | |
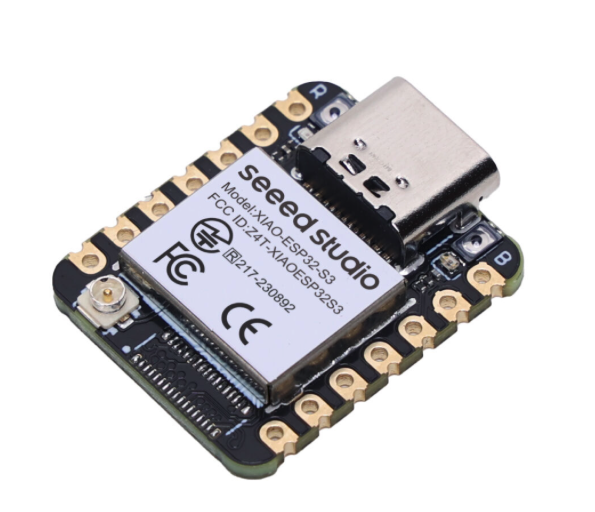
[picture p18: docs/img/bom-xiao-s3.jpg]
 1× | **Seeed XIAO ESP32-S3** (2.4 GHz)<br>*Buy the plain S3 — "Sense" is a different board* |  | [Seeed Studio](https://www.seeedstudio.com/XIAO-ESP32S3-p-5627.html) | [Search](https://www.amazon.com/s?k=Seeed+XIAO+ESP32-S3) | [Search](https://www.aliexpress.com/w/wholesale-XIAO-ESP32-S3.html) |
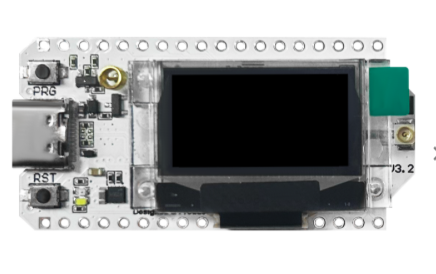
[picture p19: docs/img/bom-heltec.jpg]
| 1× | **Heltec WiFi LoRa 32 V3.2**<br>*T114 alt — V3.2 preferred · Band: 863–870 EU / 902–928 US* |  | [Heltec](https://heltec.org/project/wifi-lora-32-v3/) · [Datasheet](https://resource.heltec.cn/download/WiFi_LoRa_32_V3/HTIT-WB32LA_V3.2.pdf) | [Search](https://www.amazon.com/s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) | [Search](https://www.aliexpress.com/w/wholesale-Heltec-WiFi-LoRa-32-V3.html) |
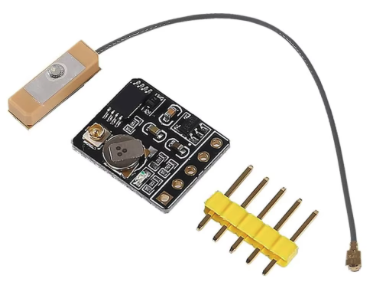
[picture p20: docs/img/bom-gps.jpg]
| 1× | **ATGM336H GPS Module**<br>*AT6558, L1-band, NMEA0183* |  | Commodity (AT6558) | [View](https://www.amazon.com/DWEII-Dual-Mode-Satellite-Positioning-Replacement/dp/B0B68C1W94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) | [Search](https://www.aliexpress.com/w/wholesale-ATGM336H.html) · [ElectroDragon](https://www.electrodragon.com/product/gnss-module-atgm336h/) |
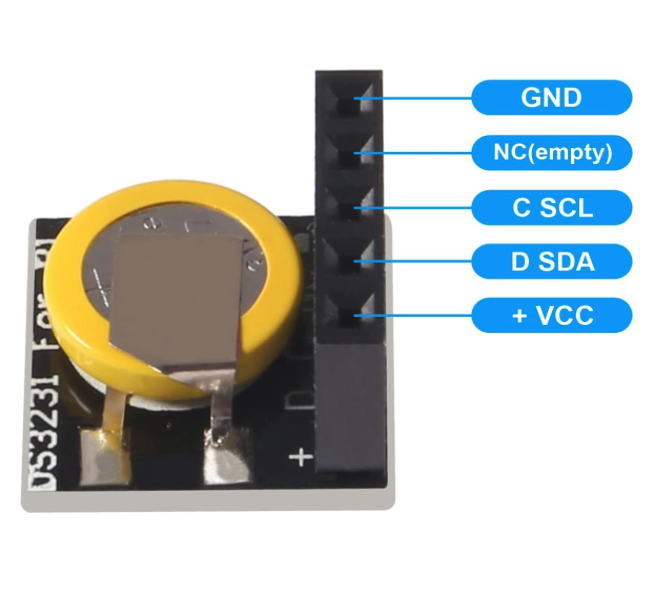
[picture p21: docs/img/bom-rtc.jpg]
| 1× | **DS3231 RTC Module** |  | Analog Devices DS3231 | [View](https://amazon.com/dp/B08X4H3NBR) | [View](https://www.aliexpress.us/item/2251832129568616.html) |
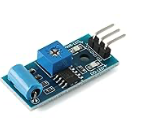
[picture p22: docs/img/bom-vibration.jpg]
| 1× | **SW-420 Vibration Sensor** |  | Commodity | [Search](https://www.amazon.com/s?k=SW-420+vibration+sensor+module) | [Search](https://www.aliexpress.us/w/wholesale-SW%2525252d420.html?spm=a2g0o.productlist.search.0) |
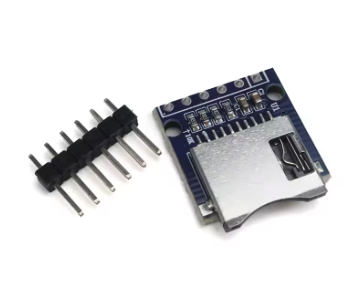
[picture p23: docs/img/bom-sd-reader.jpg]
| 1× | **MicroSD SPI Reader Module** |  | Commodity | *SD Card Module* | [Search](https://www.aliexpress.com/w/wholesale-micro-sd-card-module-spi.html) |
| 1× | **MicroSD Card — 8 GB, FAT32**<br>*SDHC, formats clean to FAT32 · 32 GB+ not recommended* | — | [Micro Center](https://www.microcenter.com/search/search_results.aspx?Ntt=8GB+microSDHC) | [Search](https://www.amazon.com/s?k=8GB+microSDHC+card+multipack) | [Search](https://www.aliexpress.com/w/wholesale-8GB-micro-sd-card.html) |

---

## Power & Enclosure

| Qty | Part | Image | MFR | AMZN | ALI |
|:---:|---|:---:|---|---|-----|
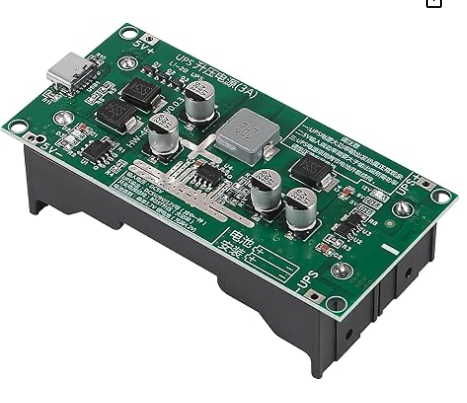
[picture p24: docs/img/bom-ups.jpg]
| 1× | **Type-C 15W 3A 5V UPS** (2S 18650)<br>*Board ID HW-465A · 88×41×22 mm* |  | Commodity (HW-465A) | [DWEII](https://www.amazon.com/dp/B0DCVRXTW8) · [JUZITAO 2-Pack](https://www.amazon.com/dp/B0DNMVSD65) | [Search](https://www.aliexpress.com/w/wholesale-HW-465A-UPS-18650.html) |
| 1× | **Type-C Female Chassis Jack**<br>*Waterproof, 2-pin 22 AWG leads · 14mm panel nut · dust cap · external 5V input* |  | Commodity | [View](https://www.amazon.com/dp/B0CXLZBD2V) | [Search](https://www.aliexpress.com/w/wholesale-type-c-female-panel-mount-2-pin-waterproof.html) |
| 1× | **KSD9700 Normally Open Thermal Switch** 30–40°C close temp| Screenshot 2026-07-25 at 8 31 01 AM | — | [Search](https://www.amazon.com/s?k=KSD9700+40C+normally+open+thermal+switch) | [Search](https://www.aliexpress.com/w/wholesale-KSD9700-40C-NO.html) |
| 1× | **30mm 5V JST Fan** |  | — | [10mm](https://amazon.com/dp/B08R9HFXTN) · [7mm](https://amazon.com/dp/B0CWD6BY6G) | [Search](https://www.aliexpress.com/w/wholesale-30mm-5V-fan.html) |
| 1× | **3-Pin Mini On/Off Switch** (6mm) |  | — | [View](https://www.amazon.com/dp/B07LBNWD52?th=1) | [Search](https://www.aliexpress.com/w/wholesale-mini-switch--waterproof-cap.html) |
| 2× | **JST Power Male Cables**<br>*Switch, power board·  Includes female 2.54 JST socket* |  | — | [View](https://amazon.com/dp/B0D6KSMK1Q) | [View](https://www.aliexpress.us/item/3256809537971085.html) |
| 2× | **18650 Cells**<br>*Protected, flat-top, ~3000 mAh · not supplied with any tier* | — | — | [Search](https://www.amazon.com/s?k=protected+18650+flat+top) | [Search](https://www.aliexpress.com/w/wholesale-protected-18650.html) |
| 1× | **Weatherproof Enclosure**<br>*3D-printed* | — | — | [STLs (Repo)](https://github.com/lukeswitz/AntiHunter/tree/main/hw/Prototype_STL_Files) | — |
| 1× | **TPU Seal Kit**<br>*Housing, USB-C, GPS antenna — grease before fitting* | — | — | [STLs (Repo)](https://github.com/lukeswitz/AntiHunter/tree/main/hw/Prototype_STL_Files) | — |

---

## Antennas

| Qty | Part | Image | AMZN | ALI |
|:---:|---|:---:|---|-----|
| 3× | **U.FL → SMA Pigtail**<br>*10cm, SMA bulkhead — female/jack, see Note 2* |  | [Search](https://www.amazon.com/s?k=U.FL+to+SMA+female+bulkhead+pigtail+10cm) | [Search](https://www.aliexpress.com/w/wholesale-ufl-to-sma-female-bulkhead.html) |
| 1× | **6dBi 2.4GHz Antenna**<br>*Wi-Fi/BLE, SMA* | — | [Search](https://www.amazon.com/s?k=6dBi+2.4GHz+SMA+antenna) | [Search](https://www.aliexpress.com/w/wholesale-6dBi-2.4GHz-SMA-antenna.html) |
| 1× | **6dBi LoRa Antenna**<br>*868 EU / 915 US / 923 Asia, SMA* | — | [Search](https://www.amazon.com/s?k=915MHz+LoRa+antenna+SMA) | [Search](https://www.aliexpress.com/w/wholesale-915MHz-LoRa-antenna.html) |
| 1× | **GNSS Antenna — Active L1, SMA**<br>*1575.42 MHz, 28 dB, 3–5V* |  | [View](https://amazon.com/dp/B0FPKPBW7G) | [Search](https://www.aliexpress.us/w/wholesale-gps-helix-l1-antenna.html) |

---

## Fasteners & Hardware

| Qty | Part | Image | AMZN | ALI |
|:---:|---|:---:|---|-----|
| 10× | **M3 Heat-Set Inserts** |  | [Search](https://www.amazon.com/s?k=M3+heat+set+inserts) | [Search](https://www.aliexpress.com/w/wholesale-M3-heat-set-insert.html) |
| 4× | **M2 Heat-Set Inserts**<br>*Power board, see Note 7* | — | [Search](https://www.amazon.com/s?k=M2+heat+set+inserts) | [Search](https://www.aliexpress.com/w/wholesale-M2-heat-set-insert.html) |
| 2× | **M3×15mm Brass Standoffs**<br>*Male-to-female* |  | [View](https://amazon.com/dp/B07WR5ZD8G) | [Search](https://www.aliexpress.com/w/wholesale-M3-brass-standoff.html) |
| 8× + 6× | **M3×4-6mm Flat-Top Screws** (enclosure lids, max 6mm heads)<br>**+ M3×4-6mm Screws** (PCB / front-rear covers) | — | [Search](https://www.amazon.com/s?k=M3+screw+kit) | [Search](https://www.aliexpress.com/w/wholesale-M3-screw-assortment-kit.html) |
| 4× | **M2×4-6mm Screws** (power board) | — | [Search](https://www.amazon.com/s?k=M2+screw+kit) | [Search](https://www.aliexpress.com/w/wholesale-M2-screw-assortment-kit.html) |
| 2–4× | **M2.5 13–15mm Screws** (fan) | — | [Search](https://www.amazon.com/s?k=M2.5+15mm+screw) | [Search](https://www.aliexpress.com/w/wholesale-M2.5-15mm-screw.html) |
| 5× | **JST 2.54 2-Pin Terminals** |  | [View](https://amazon.com/dp/B0D6KSMK1Q) | [Search](https://www.aliexpress.com/w/wholesale-JST-XH-2.54-2pin.html) |
| 1× | **1/4" Tripod Insert**<br>*1/4-20 threaded* | — | [Search](https://www.amazon.com/s?k=1%2F4-20+threaded+insert+brass) | [Search](https://www.aliexpress.com/w/wholesale-1-4-20-threaded-insert.html) |

---

## Builder Notes — read before ordering

1. **2× 18650 cells are never supplied.** The HW-465A UPS holds two; they do not come with the UPS board or with any tier. Use protected flat-top cells, ~3000 mAh.
2. **SMA gender chain.** GPS/LoRa/Wi-Fi antennas are SMA male; modules are U.FL. Your U.FL→SMA pigtails must be SMA female (jack) bulkheads or the antennas won't thread. Most common ordering mistake on this build.
3. **SD card = FAT32.** Built tiers ship with an 8 GB card. 32 GB and larger are not recommended; 64 GB+ ships exFAT and needs reformatting (untested).
4. **LoRa band must match your region and Heltec board variant** (EU868 / US915 / AS923). Mismatched antenna/board band degrades range.
5. **Check which way the fan blows.** The sticker side is not always the exhaust side. Feel the airflow before you screw it down. Assembled units ship set to exhaust.
6. **Fan full time.** Short the two THERMO pins to bypass the KSD9700.
7. **Power board.** M3 threads straight into the plastic posts. To use inserts instead, melt M2 inserts into those posts and switch to M2 screws.
8. **Fusing the battery line is optional.** A 2A fast-blow inline fuse between the cells and the UPS board adds protection against a cell fault. Not required and not supplied.

> [!IMPORTANT]
>  **RTC and SW modules require a minor pin mod** to seat them in the PCB:

- RTC MODULE
     Usually ships with female headers. Trim and reuse the existing pins,
     or desolder and swap in male pin headers.

- VIBRATION SENSOR
     Sourced units have inverted 90° headers. Heat all three joints and
     bend straight (trim excess), or desolder and replace with standard
     header pins.

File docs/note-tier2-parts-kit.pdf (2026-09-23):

## AntiHunter

P E R I M E T E R D E F E N S E S Y S T E M S

Tier 2 · Complete parts kit

# DIGI Node — Tier 2: Complete Parts Kit

Contains every part needed to build a finished node, as delivered by the suppliers. Nothing is soldered and nothing is flashed.

## In the box

Group | Contents
Electronics | Bare 82 mm PCB, all modules and headers, 8 GB microSD
Enclosure | Printed enclosure, TPU seals, all hardware and wiring
RF | WiFi and LoRa SMA antennas, U.FL pigtails and bulkheads, passive ceramic GPS antenna
Power and cooling | Fan, thermal switch, power switch, waterproof USB-C panel jack, UPS charger board, JST
terminals and cables
You supply: two flat-top 18650 batteries, an active GPS SMA antenna and soldering tools.

## Build it

1. Follow the assembly manual from start to finish. It has photographed steps for soldering, connectors, the enclosure, the SD card and power wiring. github.com/lukeswitz/AntiHunter → hw folder → Antihunter-DIGINODE-
AssemblyManual.pdf
2. Two modules need their headers modified first (manual, page 6):
- The RTC comes with female headers.
- Some tamper sensors come with inverted 90° headers.
3. Fit the SD card before you close the case. The slot cannot be reached once the PCB is mounted.

## Flash it

4. Flash the Heltec V3.2 or T114 with the latest stable Meshtastic from flasher.meshtastic.org, then set up the serial module as below. Without these settings the node and the radio cannot communicate. scripts/ meshtastic_config.py in the repo applies them for you.
Setting | Heltec V3 | T114
Serial module | Enabled | Enabled
Mode | TEXTMSG | TEXTMSG
Baud | 115200 | 115200
RX / TX pins | 19 / 20 | 10 / 9
5. Flash AntiHunter on the ESP32 over USB with the web flasher at lukeswitz.github.io/AntiHunter. Choose Full for the web UI or Headless for quiet field operation.
6. Set the LoRa region and change the Bluetooth pairing PIN. Make your own encrypted channel the primary channel and turn the public default off.
7. Full firmware only: join the Antihunter WiFi AP (password antihunt3r123), open http://192.168.4.1 and change these credentials before doing anything else.

## Power

- Use a regulated 5 V supply only, from USB or the UPS board. Never wire cells or an unregulated supply to the PCB.
- A 2 A fast-blow fuse in the battery line is recommended. It is not included.

Connect one USB cable at a time. The ESP32 and the radio share the power rails.

## Full guide

For unboxing through deployment, antennas, all detectors, the vibration sensor, mesh commands and Command Center, see the Operator’s Guide: github.com/lukeswitz/AntiHunter/blob/main/docs/AntiHunter-Operators-Guide.pdf
- Firmware, docs, issues: github.com/lukeswitz/AntiHunter
- Command Center: github.com/TheRealSirHaXalot/AntiHunter-Command-Control-PRO
AntiHunter DIGI Node | 1 / 1

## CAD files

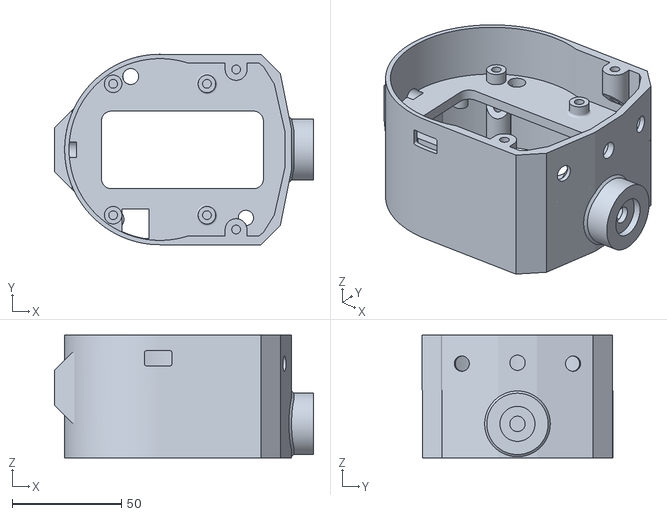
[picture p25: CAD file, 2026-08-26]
hw/Prototype_STL_Files/AH-DIGINODE-v2/SideCharge enclosure/FullSideChargeHousing.stl
118.3 x 87.0 x 56.0

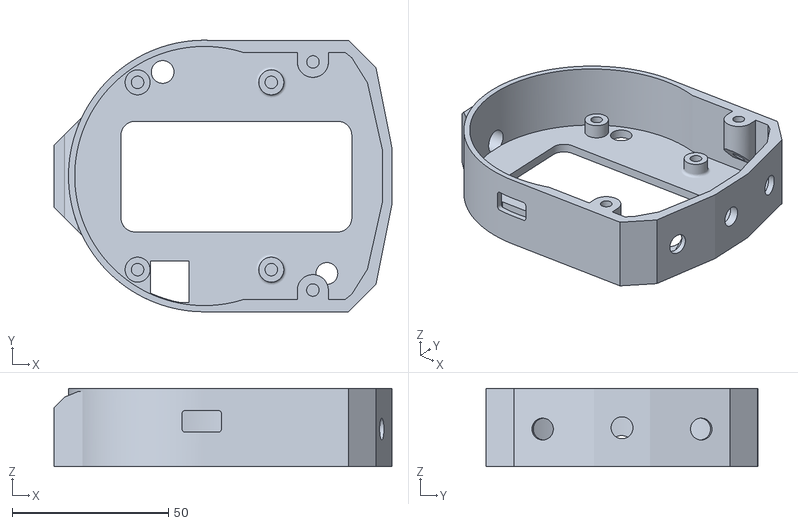
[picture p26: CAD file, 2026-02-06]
hw/Prototype_STL_Files/AH-DIGINODE-v2/FastCharge enlosure/Main-Housing-USBFast-Version.stl
108.3 x 87.0 x 25.0

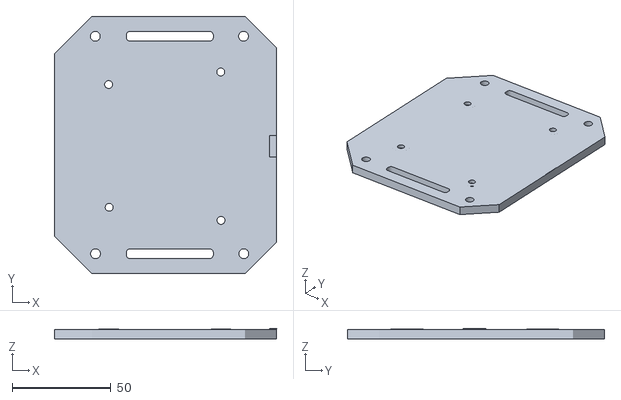
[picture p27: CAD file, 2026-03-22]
hw/Prototype_STL_Files/AH-DIGINODE-v2/Extentions/MOUNTS/Universal-Bracket-Battery.stl
112.5 x 130.0 x 5.24

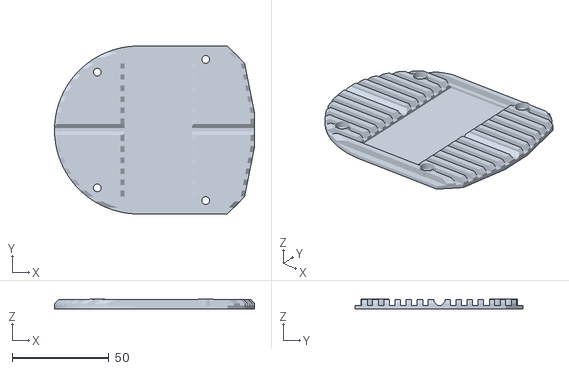
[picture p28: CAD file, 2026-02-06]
hw/Prototype_STL_Files/AH-DIGINODE-v2/Extentions/RadarMOD/Radar-front.stl
103.6 x 87.0 x 4.95

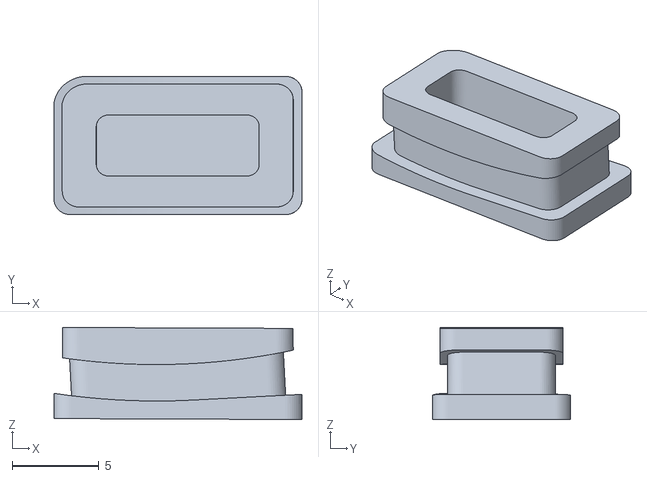
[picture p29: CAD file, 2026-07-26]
hw/Prototype_STL_Files/AH-DIGINODE-v2/Extentions/SEALS/ESP-USB-TPU-PLUG-SEAL.stl
14.3 x 7.96 x 5.29

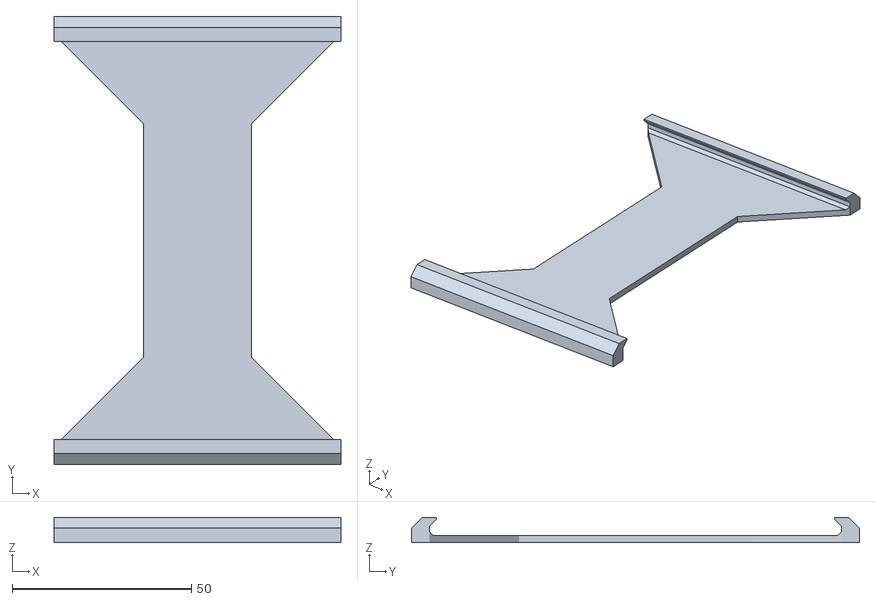
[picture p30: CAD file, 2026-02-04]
hw/Prototype_STL_Files/AH-DIGINODE-v2/Extentions/SOLAR/115x85mm-solar-mount-frame.stl
80.0 x 125.0 x 7.00

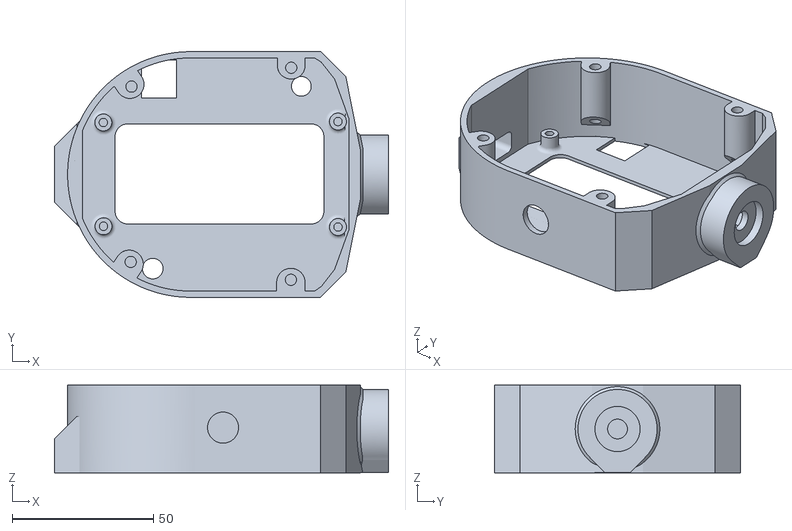
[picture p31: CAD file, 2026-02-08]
hw/Prototype_STL_Files/AH-DIGINODE-v2/FastCharge enlosure/Battery-Housing-USBFast-with-side-hole.stl
118.3 x 87.0 x 31.0

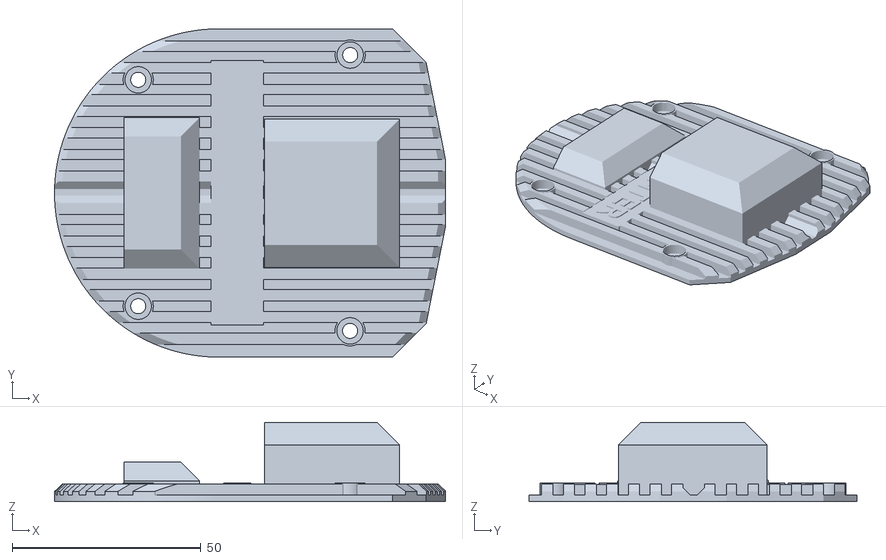
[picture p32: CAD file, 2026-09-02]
hw/Prototype_STL_Files/AH-DIGINODE-v2/FrontCover-Hidden-Fan-10mm.stl
103.6 x 87.0 x 21.0

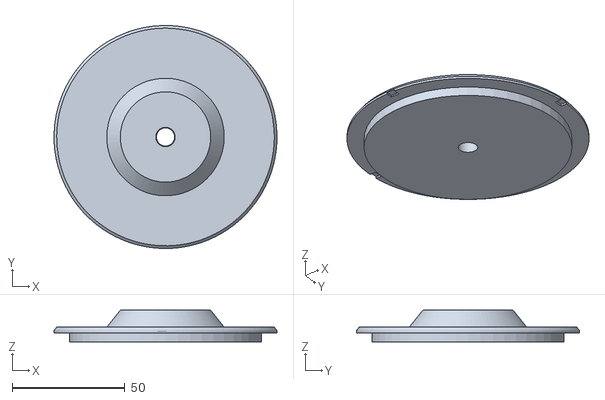
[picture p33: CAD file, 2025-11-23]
hw/Prototype_STL_Files/AHPuckCase/puck_bottom.stl
98.7 x 98.7 x 14.0

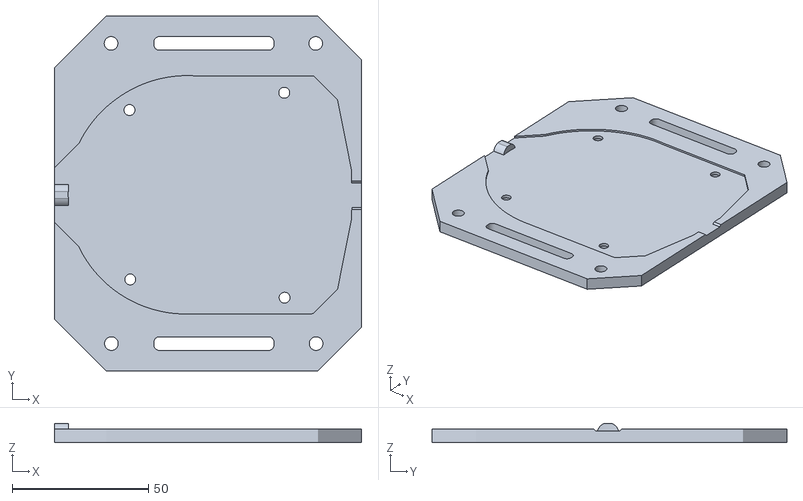
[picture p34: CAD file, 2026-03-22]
hw/Prototype_STL_Files/AH-DIGINODE-v2/Extentions/MOUNTS/Universal-Bracket-No-Battery.stl
112.5 x 130.0 x 7.00

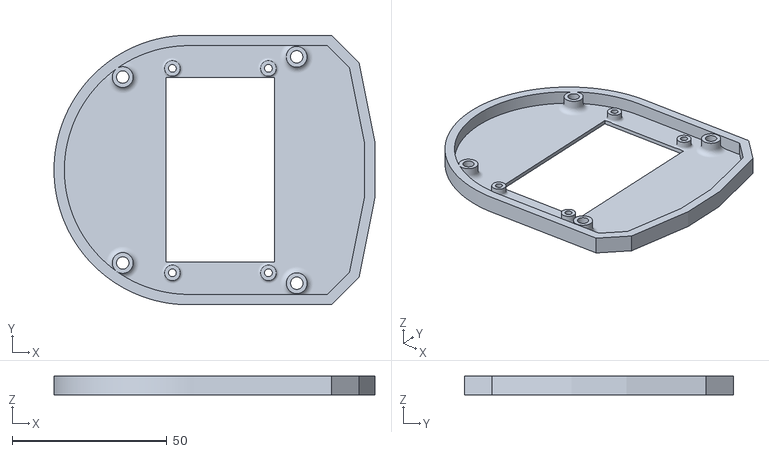
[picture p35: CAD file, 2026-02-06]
hw/Prototype_STL_Files/AH-DIGINODE-v2/Extentions/RadarMOD/Radar-extention-housing-slim.stl
103.6 x 87.0 x 6.00

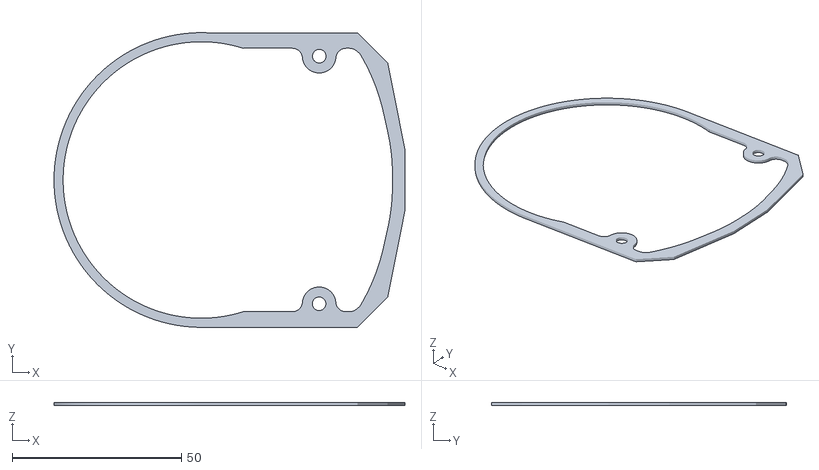
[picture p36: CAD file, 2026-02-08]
hw/Prototype_STL_Files/AH-DIGINODE-v2/Extentions/SEALS/FrontHousing-SEAL.stl
103.6 x 87.0 x 1.00

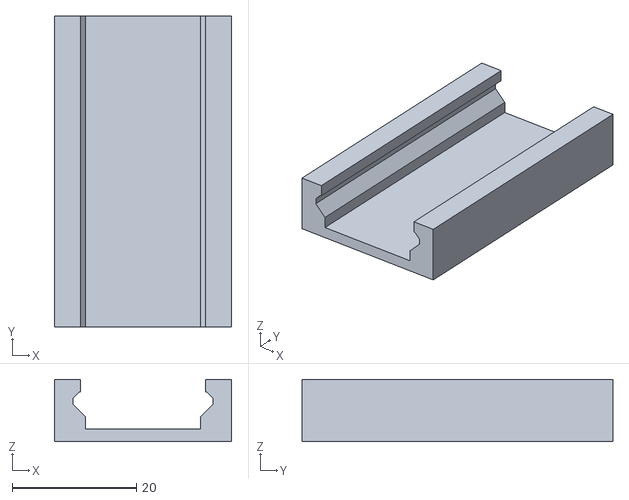
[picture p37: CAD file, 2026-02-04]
hw/Prototype_STL_Files/AH-DIGINODE-v2/Extentions/SOLAR/115x85mm-solar-mount-leg.stl
28.5 x 50.0 x 10.0

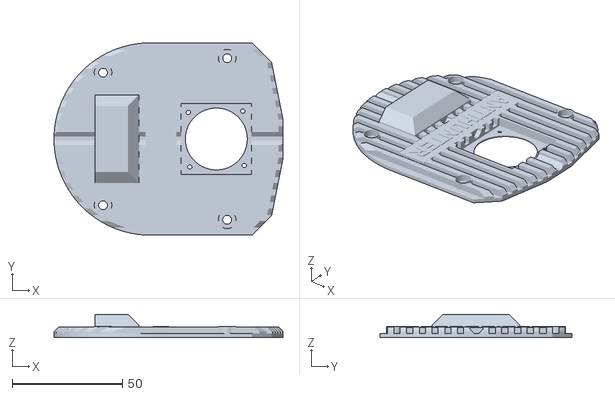
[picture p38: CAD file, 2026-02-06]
hw/Prototype_STL_Files/AH-DIGINODE-v2/FrontCover-Open-Fan.stl
103.6 x 87.0 x 10.5

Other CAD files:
hw/Prototype_STL_Files/AH-DIGINODE-v2/SideCharge enclosure/Main-Housing-SideCharge-Version.stl
hw/Prototype_STL_Files/AH-DIGINODE-v2/SideCharge enclosure/One-Piece-Housing-SideCharge-Version.stl
hw/Prototype_STL_Files/AH-DIGINODE-v2/FastCharge enlosure/Battery-Housing-USBFast-no-side-hole.stl
hw/Prototype_STL_Files/AHPuckCase/puck_top.stl
hw/Prototype_STL_Files/AH-DIGINODE-v2/BackCover.stl
hw/Prototype_STL_Files/AH-DIGINODE-v2/Extentions/RadarMOD/Radar-extention-housing-fat.stl
hw/Prototype_STL_Files/AH-DIGINODE-v2/Extentions/SEALS/BatteryHousing-SEAL.stl
hw/Prototype_STL_Files/AH-DIGINODE-v2/Extentions/SEALS/GPS-TPU-SEAL.stl
hw/Prototype_STL_Files/AH-DIGINODE-v2/Extentions/SEALS/Radar-SEAL.stl
hw/Prototype_STL_Files/AH-DIGINODE-v2/FrontCover-Hidden-Fan.stl
hw/Prototype_STL_Files/AH-DIGINODE-v2/SideCharge enclosure/Battery-Housing-SideCharge.stl
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

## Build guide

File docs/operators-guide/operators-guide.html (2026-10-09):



# ANTIHUNTERDIGI NODE

Operator's Guide: from the box to the field

Covers all four tiers: Fully Assembled Unit · Complete Parts Kit · Populated PCB · Bare PCB

Guide revision 1.1 · 4 October 2026 · Firmware v1.0.4 · Written for the current Stable and Beta firmware channels
github.com/lukeswitz/AntiHunter · Web flasher: lukeswitz.github.io/AntiHunter

## Hello, operator

Welcome to AntiHunter. This node is a self-contained Wi-Fi, Bluetooth and LoRa mesh sensor. It runs everything on the device: no cloud, no account, no server needed. It is fully open source. Read the firmware, write your own mesh commands, wire it into your own IDS. Make it yours.

This guide takes you from opening the box to a tuned node in the field, whichever tier you bought. Sections that only apply to one tier are marked. Everything else applies to every node.

Read before applying power: three rules

1. Regulated 5 V only. Power the PCB from USB, a bench supply set to 5 V, a proper DC-DC regulator, or the UPS board. Never connect 18650 cells, a battery pack, or a vehicle supply directly to the board. Unregulated input permanently damages the modules. Voltages under 4.5 V cause instability.

2. Never power the LoRa radio without its antenna. Transmitting into an open port can destroy the radio's PA. Fit the LoRa antenna, or the U.FL pigtail plus antenna, before the node is energised.

3. One USB cable at a time. The ESP32 and the Meshtastic radio share the PCB's power rails. With both USB ports plugged in, one board back-feeds the other. Plug in one board, do your work, unplug it, then plug in the other.

### What you are holding

Tier | What is in the box | What you still have to do
1 · Fully Assembled Unit | Built, soldered, tested and ready to deploy. 8 GB SD card fitted. Active GPS helix antenna. SMA antennas. Meshtastic flashed on the radio with the serial link configured. | Fit two 18650 cells, screw on the antennas (§2), flash AntiHunter (§5), set the radio region and channel (§7).
2 · Complete Parts Kit | Every part on the bill of materials, unassembled, as it comes from the supplier. Passive GPS antenna. Nothing is soldered and nothing is flashed. | Solder and assemble it (§3), flash Meshtastic on the radio (§7.1), then flash AntiHunter (§5) and configure.
3 · Populated PCB | A fully assembled PCB. Core modules soldered, bench-tested, 8 GB SD card fitted. Factory U.FL antennas. Meshtastic flashed on the radio with the serial link configured. | Attach the antennas (§2), supply power over USB or 18650s, build the housing if you want one, flash AntiHunter (§5), set the radio region and channel (§7).
4 · Bare PCB | One 82 mm board, unpopulated. | Source the BOM, solder the modules, flash Meshtastic on the radio, fit an SD card, then follow this guide from §3.

Tiers 1 and 3: the radio is already done

On the Fully Assembled Unit and the Populated PCB, the Meshtastic radio ships flashed with the latest stable firmware and the serial link to the node already configured: TEXTMSG mode, 115200 baud, on the correct pins for the board. You do not need to redo that. You do still need to set your LoRa region and create your own encrypted channel. See §7.

On the Complete Parts Kit and the Bare PCB you flash the radio yourself first. §7.1 has the settings. The ESP32 ships empty on every tier, so you always flash AntiHunter yourself and know exactly what is on it.

### Contents

1 Unboxing and inventoryTier checklists, tools you supply, power and thermal

2 AntennasU.FL seating, SMA fitting, which port is which

3 AssemblyTiers 2 and 4: where the assembly manual takes over

4 First power-onBoot signs, SD card, GPS, real-time clock

5 Flashing the firmwareFull vs Headless, three flashing methods

6 Staying up to dateRelease channels, GitHub notifications, rollback

7 Mesh radio setupRegion, encrypted channel, quiet-ops settings

8 First configurationCredentials, node ID, scan presets, privacy

9 Using the nodeEvery detector, what it finds, how to run it, scheduling

10 Vibration sensor and tamperHow it works, tuning the trimpot, auto-erase

11 Mesh command referenceEverything you can send from a phone

12 Command Center (C2)Quick install, first login, connecting a radio

13 DeploymentSiting, sealing, mounting, power budget

14 Maintenance and troubleshootingSymptom tables, factory reset, getting help

15 Legal and safetyAuthorization, radio law, privacy, disclaimer

A–E AppendicesPinout, BOM, defaults, glossary, quick-reference card

## 1Unboxing and inventory

Open the box on a clean, static-safe surface. Check what arrived against your tier before you power anything.

### 1.1 Tier checklists

Tier 1: Fully Assembled Unit

- Node built, soldered and bench-tested
- 8 GB SD card fitted
- Active GPS helix antenna
- 2.4 GHz Wi-Fi/BLE SMA antenna
- LoRa SMA antenna for your region
- Meshtastic flashed on the radio, serial link configured

Tier 2: Complete Parts Kit

Every part needed to build a finished node. Nothing is soldered and nothing is flashed. The two 18650 cells are the only thing you supply.

- Bare 82 mm PCB
- XIAO ESP32-S3
- Heltec V3.2 LoRa radio (or T114)
- ATGM336H GPS module
- DS3231 RTC module
- SW-420 vibration sensor
- Micro SD reader module
- 8 GB SD card
- Pin headers for every module
- 3D-printed enclosure: main PCB housing, battery housing, front cover, back cover
- TPU seals for the housing, GPS and USB-C port
- 3× U.FL-to-SMA pigtail cables
- SMA bulkheads
- 2.4 GHz Wi-Fi/BLE antenna, 6 dBi
- LoRa antenna for your region
- Passive ceramic GPS antenna, the one supplied with the GPS module
- 30 mm 5 V fan with JST lead
- KSD9700 normally-open thermal switch, 40 °C
- 3-pin mini on/off switch with rubber cover
- Waterproof Type-C female chassis jack, 2-pin 22 AWG leads, panel nut and dust cap
- Type-C 15 W 3 A 5 V UPS charger board, dual 18650
- 6× JST 2.54 2-pin terminals
- 3× JST power male cables for the switch, thermal switch and power board
- M3 heat-set inserts, plus 4× M2 for the power board
- M3×4-6mm screws for the PCB and enclosure lids, M2×4-6mm for the power board
- 2× M2.5 screws, supplied with the fan
- 2× 15 mm brass standoffs
- ¼"-20 tripod insert

Tier 3: Populated PCB

A fully assembled PCB, bench-tested, on its factory antennas. No enclosure and no power source.

- PCB with XIAO ESP32-S3, Heltec V3.2 LoRa radio (or T114), ATGM336H GPS, DS3231 RTC, SW-420 vibration sensor and SD reader soldered
- 8 GB SD card fitted
- Factory U.FL antennas: flat 2.4 GHz film, coiled LoRa whip, ceramic GPS patch
- Meshtastic flashed on the radio, serial link configured

Tier 4: Bare PCB

- One 82 mm AntiHunter DIGI NODE PCB, unpopulated

Everything else comes from the bill of materials in Appendix B, including the Meshtastic radio, which you flash yourself.

### 1.2 What you supply

- Power. Tiers 1 and 2 take two 18650 cells in the UPS board. Tier 3 runs from USB or from your own regulated 5 V supply. Cells are never supplied on any tier.
- 18650 cells. Brand new, same brand, same capacity, never mixed old with new. Sourcing, charging, storage and disposal are your responsibility.
- A micro SD card, only on the Bare PCB tier. Every other tier ships with an 8 GB card. A replacement must be FAT32, and 32 GB or larger is not recommended.
- A USB-C data cable. Charge-only cables will not flash the board.
- A computer running Chrome or Edge for the web flasher, or a terminal for the CLI installer.
- Soldering tools on tiers 2 and 4: temperature-controlled iron, fine solder, flux, tweezers, small Phillips and hex drivers, heat-resistant surface.



The bare 82 mm board.



XIAO ESP32-S3.



Heltec V3.2 LoRa radio.



ATGM336H GPS module.



DS3231 real-time clock.



SW-420 vibration sensor. Note the trimpot.



Micro SD reader module.

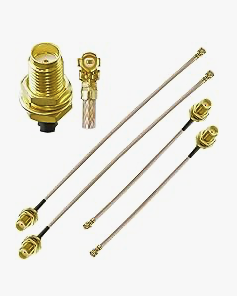
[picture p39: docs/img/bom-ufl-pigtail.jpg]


U.FL-to-SMA pigtail.



5 V UPS charger board.

### 1.3 Power

The node draws roughly 160 mA idle and 600 mA while actively scanning. Inside the enclosure the UPS board provides the regulated 5 V and the cells are never connected to the PCB directly. Outside the enclosure, use a USB-C adapter, a bench supply set to 5.0 V on the 5 V input, or a proper DC-DC regulator.

Power rules

Do not connect batteries directly. Do not exceed 5 V. Do not use unregulated sources. A fuse in the battery line is recommended, a 2 A fast-blow in series with the switch wiring, but one is not supplied with any tier.

### 1.4 Thermal

The ESP32 runs warm under load and the GPS module gets noticeably hot while it searches for satellites. Both are normal. Neither the fan nor the thermal switch is required for the node to work.

- The 30 mm fan plugs into the FAN JST output.
- The sticker side is not always the exhaust side. Run the fan for a second and feel which way it blows before you screw it down. The Fully Assembled Unit ships with the fan set to exhaust.
- The KSD9700 normally-open thermal switch, 40 °C, wires to the THERMO JST and switches the fan on when the enclosure heats up.
- To run the fan continuously instead, jump the THERMO input or supply 5 V straight to the fan port.

## 2Antennas

More nodes are damaged fitting antennas than in any other step. The U.FL connectors are small, fragile and unforgiving of a crooked press. Take your time here.

### 2.1 Which antenna goes where

Antenna | U.FL set (tiers 2 and 3) | SMA set (tiers 1 and 2) | Connects to
2.4 GHz Wi-Fi / BLE | Flat black film antenna, printed 2.4G | Shorter of the two rubber ducks, 6 dBi | The U.FL socket on the XIAO ESP32-S3, or its SMA bulkhead
LoRa (region specific) | Coiled black whip | Longer duck, marked 868 MHz (EU), 915 MHz (US) or 923 MHz (Asia) | The U.FL socket on the Heltec / T114 radio, or its SMA bulkhead
GPS | Passive ceramic patch, supplied with the GPS module | Active helix, Fully Assembled Unit only | The U.FL socket on the GPS module, or the SMA bulkhead in the battery housing



The factory U.FL antenna set beside the sockets each one belongs to: ceramic GPS patch, coiled LoRa whip (915 MHz shown, yours matches your region), flat 2.4 GHz film antenna. The GPS module carries the GPS socket, the Heltec carries LoRa, the XIAO carries 2.4 GHz Wi-Fi and BLE.

Pick an orientation and keep it

On an enclosed build, decide which bulkhead carries LoRa and which carries Wi-Fi, then wire every node you build the same way. It does not matter which you choose. It matters that a spare antenna always fits the port you expect in the field.

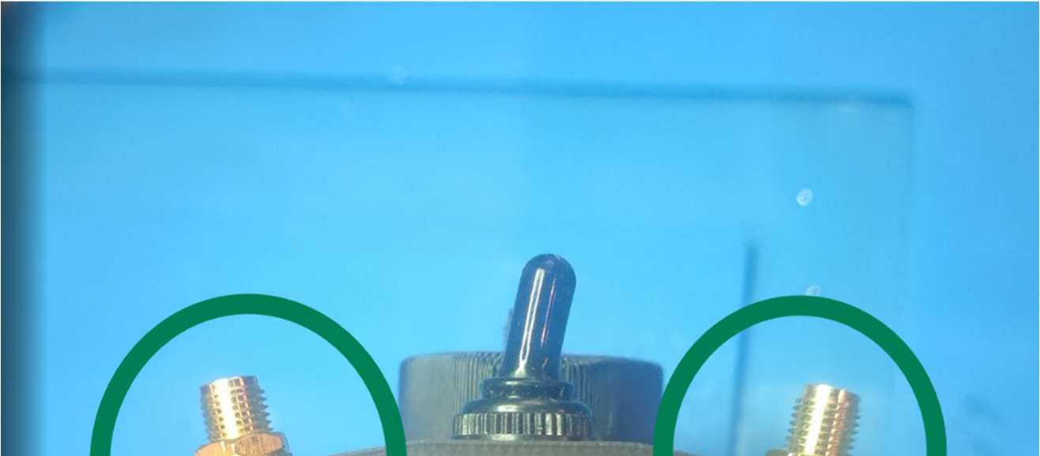
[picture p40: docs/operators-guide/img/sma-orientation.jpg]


The two SMA bulkheads with the power switch centered between them.

Match your antennas across nodes

When you build more than one node, use the same antenna type and the same cable length on all of them. Triangulation and any other multi-node distance estimate assumes the nodes hear the world the same way. Mismatched antennas skew the result.

### 2.2 Fitting a U.FL / IPX pigtail (tiers 2 and 3)

The pigtail's tiny snap connector mates with the socket on each module. It seats with an audible, tactile click.

1. Identify each pigtail and the socket it belongs to. Route the cable before you connect it, not after.
2. Hold the connector parallel to the board and align its rim concentrically over the socket. Look at it from the side: the two rims must be perfectly stacked.
3. Press straight down with a fingertip or the flat of a plastic tool until it clicks.
4. Tug the cable gently to confirm it is home. If it lifts off, it never seated.

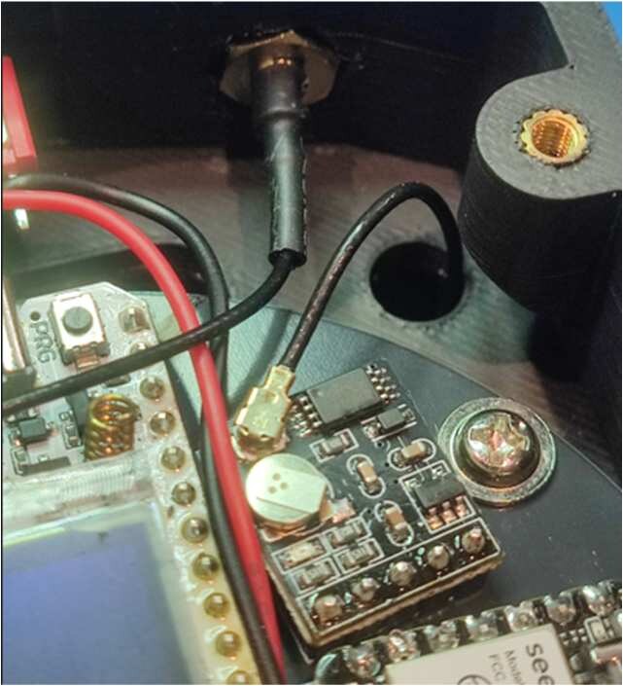
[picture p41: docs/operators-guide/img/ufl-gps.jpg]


GPS module, connector facing up.

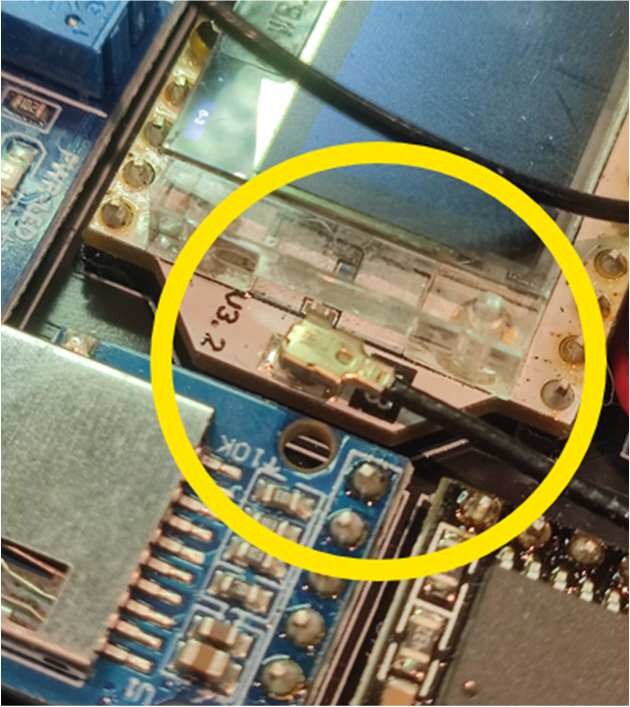
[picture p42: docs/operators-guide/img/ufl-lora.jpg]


LoRa radio, socket circled.



XIAO ESP32-S3, Wi-Fi/BLE socket.

U.FL: do not

- Do not press at an angle.
- Do not force a connector that will not click.
- Do not pull the cable to remove one. Lift the connector body straight up, or use a U.FL removal tool.
- Do not reseat one repeatedly. The contacts wear out.
- Misalignment damage is permanent. A crushed socket means a new module.

### 2.3 Fitting SMA antennas (tiers 1 and 2)

1. Check the bulkhead is tight in the shell. The nut and washer go on the outside, and the bulkhead should not rotate when you turn an antenna onto it.
2. Start the thread by hand, straight on. Never cross-thread it.
3. Turn until finger-tight, then no more than an eighth of a turn. Do not use pliers.
4. Fold the duck upright once fitted. Antennas work best vertical.

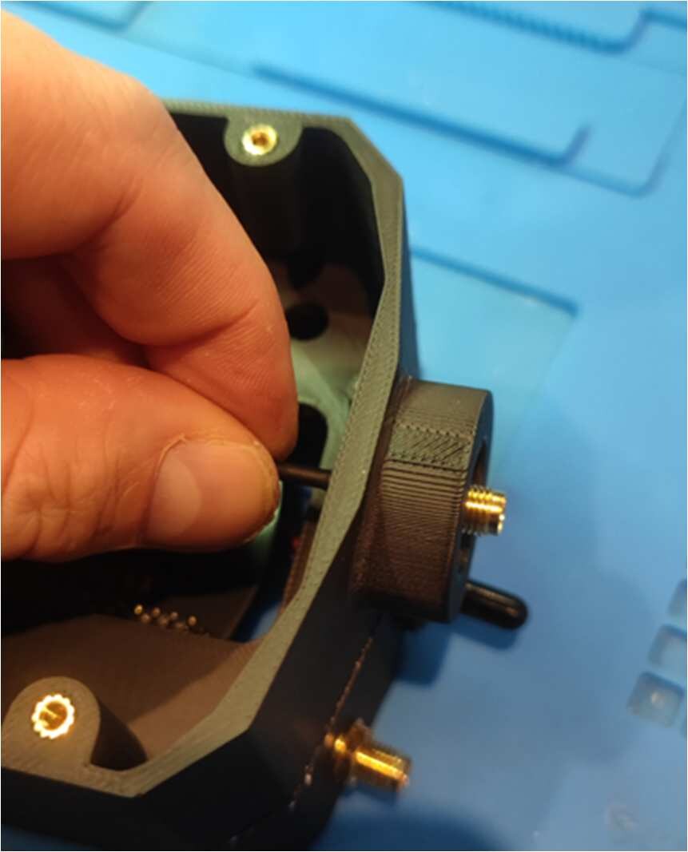
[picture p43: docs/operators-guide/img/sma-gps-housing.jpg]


GPS SMA female fitted into the battery housing, secured from outside with washer and nut.

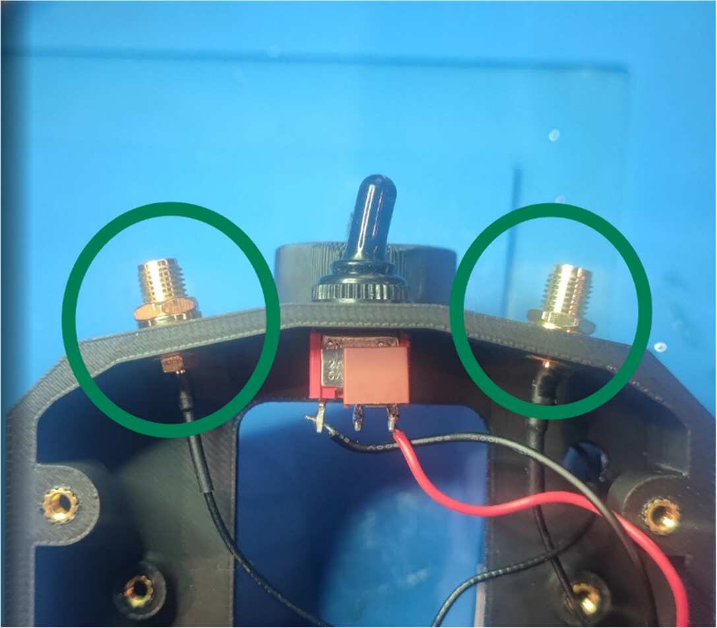
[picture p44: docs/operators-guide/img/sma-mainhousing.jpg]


Wi-Fi SMA (female, left) and LoRa SMA (male, right) in the main housing.

Wet conditions

A smear of silicone grease on the SMA threads and on the TPU seals keeps water out and makes the antennas easier to remove later.

## 3Assembly (tiers 2 and 4)

Tiers 1 and 3 arrive soldered. Skip to §4.

Build from the assembly manual, not from here

The Complete Parts Kit and the Bare PCB are built with the illustrated assembly manual, which covers soldering, connectors, the enclosure, the SD card and the power wiring in photographed steps. This guide does not repeat it.

hw/Prototype_STL_Files/Antihunter-DIGINODE-AssemblyManual.pdf
github.com/lukeswitz/AntiHunter, in the hw folder

Work through it end to end, then come back here at §4 to power the node up for the first time.

## 4First power-on

### 4.1 What a healthy boot looks like

Connect a USB-C cable to the ESP32 only, remembering one USB at a time, and open a serial monitor at 115200 baud. On boot the firmware prints its banner and version, then the results of its hardware checks: SD card, GPS, RTC, vibration sensor. Any module that failed to initialize says so by name.

If you flashed the Full firmware, a Wi-Fi access point named Antihunter also appears within a few seconds.

### 4.2 Confirming the hardware

Every subsystem reports into the diagnostics text, visible in the web UI's System tab, over serial, and in the reply to a mesh STATUS command. Check for:

- SD card. Mounted and writable. If it is missing, the node still scans but nothing is logged.
- GPS. Reports a fix once it has one. Give it a clear view of the sky; indoors it may never lock. Detections carry coordinates only when the fix is valid.
- RTC. Supplies the timestamps on every log line and export.
- Vibration sensor. Shows Standby, or Active with the time of the last movement.

### 4.3 The clock

Nothing to do. The DS3231 is set when you flash the firmware, and GPS disciplines it again on every fix. Its coin cell keeps it running across power cycles. The clock keeps UTC. Logs, capture file names, results and heartbeats show local time, with daylight saving, once a GPS fix places the node in a known zone: Hawaii, Alaska, Arizona, Saskatchewan, US/Canada Pacific, Mountain, Central and Eastern, UK/Ireland, Central Europe, Eastern Europe. Elsewhere, and until the first fix after boot, they show UTC.

Order of operations

Flash the firmware first (§5), then set the clock and configure the radio. A fresh flash with "Erase Device" ticked clears saved settings, so do it before you spend time configuring.

## 5Flashing the firmware

The ESP32 ships empty on every tier. You choose the build and put it on yourself.

### 5.1 Full or Headless?

Same firmware, same detectors, same mesh commands, same scan engine. The difference is whether the node hosts a Wi-Fi access point.

| Full | Headless
Control | Web UI and HTTP API over its own AP, plus serial and mesh | Serial and mesh only
RF footprint | The AP beacons continuously, so the node is discoverable as a Wi-Fi network | Never beacons
Results | Rendered as cards in the web UI's Results tab, and served plain over the API like every other endpoint. Written to the SD card as well | Written to /last_results.txt on the SD card
Logging | Identical. Both builds write results, the probe database, vibration events, sentinel incidents and scan logs to the SD card
Device database | /devicedb.jsonl, which is what the Data Explorer browses | Not written
Best for | Bench work, first setup, anything where you want the UI | Covert and long-term field deployments

Start with Full while you learn the device. Reflash to Headless before a quiet deployment. It takes two minutes and your settings live on the SD card.

### 5.2 Release channels

Channel | Source | Use it when
Stable | main branch | Default. Field deployments.
Beta | beta branch | New features first, with the risk that implies.
Experimental | ESP32-C5 builds (2.4 + 5 GHz) and RadarNode | Only on C5 hardware. The flasher asks you to acknowledge these are test builds.

### 5.3 Method A: web flasher (recommended)

1. Open lukeswitz.github.io/AntiHunter in Chrome or Edge on a desktop. Other browsers cannot talk to serial ports.
2. Choose Full or Headless, and a release channel.
3. Plug the ESP32 in with a data cable, nothing else connected to the board.
4. Click Connect & Flash and pick the port.
5. Optionally set your device parameters before flashing. The Sentinel & Detectors panel configures the whole detection engine: start-on-boot, radio mode, every detector toggle, mesh flags, thresholds. Anything left on Default keeps the firmware's own setting.

Erase Device

Tick it when upgrading from firmware older than v0.9.2, or when you want to clear saved settings. Otherwise leave it off. Settings persist in NVS and are mirrored to the SD card, and self-heal if they are corrupted.

### 5.4 Method B: command line

curl -fsSL -o flashAntihunter.sh \
  https://raw.githubusercontent.com/lukeswitz/AntiHunter/main/Dist/flashAntihunter.sh
chmod +x flashAntihunter.sh
./flashAntihunter.sh

The script asks for a release channel, then Full or Headless. Flags: -c configure device parameters during the flash, -e erase flash first, -l list available firmware.

### 5.5 Method C: build from source

git clone https://github.com/lukeswitz/AntiHunter.git
cd AntiHunter
pio device list                                # find the port
pio run -e AntiHunter-full -t upload           # web UI build
pio run -e AntiHunter-headless -t upload       # serial + mesh build
pio device monitor -e AntiHunter-full          # watch it boot
pio run -e AntiHunter-full -t erase -t upload  # clean flash

Environments: AntiHunter-full and AntiHunter-headless for the ESP32-S3; AntiHunter-c5-full and AntiHunter-c5-headless for the ESP32-C5 on the feat/c5 branch; RadarNode-c5 for the 24 GHz radar node.

### 5.6 Verifying the flash

- The serial monitor prints the banner and firmware version at boot.
- Full build: the Antihunter access point appears.
- Connect to it, password antihunt3r123, and open http://192.168.4.1. Note http, not https.

Do this before anything else

The default AP name and password are published in the documentation. Until you change them in RF Settings, treat the node as an open door. §8.1.

### 5.7 Board variants

The XIAO ESP32-C5 is a drop-in replacement for the S3 on the same board, with the same pads and peripherals, and it adds 5 GHz scanning. Those builds are in testing and live under the flasher's Experimental channel. The RadarNode variant pairs a 24 GHz radar with the same mesh: it detects a moving target, then sweeps Wi-Fi and BLE to record which devices were present at that moment.

## 6Staying up to date

### 6.1 Where updates come from

Firmware is built and published by CI when a release is tagged. The web flasher always serves the current build for the channel you pick, so re-running the flasher is the update. Nothing on the node phones home or updates itself.

### 6.2 Getting notified

1. Open github.com/lukeswitz/AntiHunter and sign in.
2. Click Watch → Custom → tick Releases → Apply. You now get an email or notification for every release, without the noise of every commit.
3. Read the release notes before flashing: docs/release-notes/notes-stable.md and notes-beta.md in the repository, and on each release page.

Discussions and issues on the same repository are where behavior changes, hardware alternatives and field reports get talked through.

### 6.3 Updating a deployed node

1. Bring it in, or reach it over USB in place.
2. Re-run the web flasher or the CLI script on the same channel. Leave Erase Device unticked to keep your settings.
3. Reconnect and check the version, then confirm your targets, node ID and detector settings survived.

Settings live in NVS and are mirrored to the SD card, so they normally survive an update. Watchlists, results and databases live on the SD card and are untouched by flashing.

### 6.4 Rolling back

Flash the other channel, or check out an earlier tag and build from source with PlatformIO. If a downgrade behaves strangely, erase and flash clean, then reconfigure.

Fleet discipline

Run one firmware version across a mesh. Mixed versions can differ in the mesh message formats they emit and what your Command Center is able to parse.

## 7Mesh radio setup

The LoRa mesh gives you long-range control and alerting with no infrastructure. It is entirely optional, since a single node works standalone, but it is what turns several nodes into a system.



A device scan sending its results over the mesh. The header badge tracks the transmit queue draining at the LoRa airtime cap, 32 of 55 rows sent, and Privacy Mode has blanked the addresses.

### 7.1 Flashing and linking the radio

Tiers 1 and 3: already done. On the Fully Assembled Unit and the Populated PCB the radio arrives on the latest stable Meshtastic with the serial link to the node set: TEXTMSG mode, 115200 baud, on the right pins for the board (19 RX / 20 TX on Heltec V3, 10 RX / 9 TX on T114). The screen is set to blank after 1 s and the status LED is off. Verify it if you like; do not redo it.

Tiers 2 and 4: you flash it. The Complete Parts Kit and the Bare PCB include no flashed firmware at all. Connect the Heltec V3.2 (preferred) or T114 on its own USB and flash the latest stable Meshtastic from flasher.meshtastic.org. Then set the serial module, either in the Meshtastic app or web client, or with the script in §7.2:

Setting | Value
Serial module | Enabled
Mode | TEXTMSG
Baud | 115200
Pins, Heltec V3 | 19 RX / 20 TX
Pins, T114 | 10 RX / 9 TX

Without this the node and the radio cannot talk, and no mesh command will ever reach the node.

Three things every radio needs, whatever tier you bought

- LoRa region. Defaults to UNSET. The radio receives but will not transmit until you set it (§7.2).
- Bluetooth pairing PIN. Every unit has the same default pin. Change it, or turn BLE off.
- Channel. Defaults to the public channel. Make your own encrypted channel primary and turn the public one off (§7.3).

### 7.2 What you must set: region

The LoRa region is not set at the factory, and an UNSET region makes the radio receive-only: it hears the mesh but never transmits. Set the region for the country you are in. It determines the frequency band and the legal power and duty-cycle limits.

Plug the radio in on its own USB, not the ESP32, and run:

pip3 install 'meshtastic[cli]' pyserial
python3 scripts/meshtastic_config.py

With no arguments it prints the current settings and opens an interactive menu. Non-interactive equivalent:

python3 scripts/meshtastic_config.py --serial on --board heltec-v3 \
    --screen off --led off --ble off --region US

Option | What it does
--port | Serial port, auto-detected if omitted
--board heltec-v3 | t114 | Sets the serial-module pins for your board
--region | LoRa region, e.g. US. UNSET means receive only
--serial on | off | The node link: TEXTMSG at 115200 on the board's pins
--screen on | off | SECS | off blanks after 1 s, or give a timeout in seconds
--led on | off | Status LED heartbeat
--ble on | off | Bluetooth radio
--pin NNNNNN | none | random | BLE pairing: fixed 6-digit PIN, none, or random

The same settings can be applied from the Meshtastic phone app or web client if you prefer.

### 7.3 Your own encrypted channel

Meshtastic defaults to a public channel whose key is published. Anything you send on it, commands, detections and coordinates alike, is readable by anyone in radio range running stock firmware. Before you deploy:

1. In the Meshtastic app, create a new channel with a generated key and give it a name of your own.
2. Make it the primary channel.
3. Turn the public default channel off.
4. Share the channel to your other nodes and to your phone by QR code or channel URL. Every node in your mesh must carry the same channel.

The factory preset is not private

A node left on the default channel broadcasts its detections, its position and its command traffic to anyone listening. Changing the channel is the single most important mesh setting you will touch.

### 7.4 Quiet-ops settings

- Screen off and LED off removes the visual signature and saves power. Physically removing the Heltec screen saves more.
- BLE off on the radio removes its Bluetooth signature. Set a pairing PIN first if you intend to turn it back on later.
- Headless firmware on the node gives no Wi-Fi AP at all.

### 7.5 Addressing and node IDs

- Node IDs are 2 to 5 alphanumeric characters, A-Z and 0-9, no spaces. Give every node a distinct one.
- @ALL COMMAND broadcasts to every node. @AH01 COMMAND targets one.
- Outbound messages are rate-limited to protect airtime: roughly 167 bytes per second sustained, with device rows packed into frames of up to 230 bytes.

### 7.6 Reaching the mesh from a phone, TAK or MQTT

Commands and detections are ordinary Meshtastic text messages, so anything that talks to the mesh talks to your nodes:

- Phone. Pair the radio to the Meshtastic app over Bluetooth or Wi-Fi and send @node COMMAND messages from anywhere in mesh range. No AP, no server.
- TAK / ATAK. The Meshtastic ATAK plugin and TAK server integration bridge the whole mesh, node traffic included.
- MQTT. A Meshtastic MQTT gateway node forwards mesh traffic to a broker for logging, Home Assistant or Node-RED.

These are Meshtastic features. Nothing AntiHunter-specific is needed on the receiving end.

## 8First configuration

Ten minutes on the bench before the node ever leaves the building.

### 8.1 Change the credentials

- AP SSID and password. The defaults Antihunter and antihunt3r123 are published. Change both under RF Settings.
- Hidden network. Off by default. Turn it on under RF Settings and the node stops beaconing its SSID, so the AP does not appear in a scan of the area. It is not access control. A hidden SSID forces the client to send directed probe requests carrying the network name, so the phone or laptop you connect with advertises that name everywhere it goes afterwards. The WPA2/WPA3 passphrase is still what keeps people out. The node reboots on save and you type the SSID by hand to reconnect.
- Erase key. Authorizes every wipe, abort, auto-erase change and factory reset. 8 to 64 characters, no :. Erase commands are refused (ERASE_ACK:SET_KEY_FIRST) until you set one: in the web UI, in the flasher (erasePSK), or with @AH01 CONFIG_ERASE_PSK:<new>:<current>. Full: until a key is set, <current> is the AP password, once it is changed from the default. Headless: set it in the flasher. Record it; the node never prints it.
- Meshtastic BLE pairing PIN. Set a fixed PIN or turn BLE off entirely.

### 8.2 Identity

- Node ID. Set it in the web UI or with @AH01 CONFIG_NODEID:AH02. It prefixes every mesh message the node sends, so make it meaningful.
- Clock. See §4.3. Timestamps are local time once GPS fixes the zone, UTC before that.

### 8.3 Scan presets

Presets set the whole timing profile in one click. Start on Balanced.

Preset | Wi-Fi chan time | Wi-Fi scan int | BLE scan int | BLE scan dur | RSSI | Use case
Relaxed | 300 ms | 5000 ms | 6000 ms | 3000 ms | −80 dBm | Low power
Balanced | 160 ms | 3000 ms | 4000 ms | 2000 ms | −95 dBm | General use (default)
Aggressive | 110 ms | 1500 ms | 2000 ms | 1000 ms | −100 dBm | Fast detection, high coverage
Custom | User-defined | | | | | Fine-tuned

#### What each parameter does

- Wi-Fi channel time, 50 to 300 ms. Dwell per channel. It must clear the ~100 ms beacon interval to catch every AP on a channel. Shorter covers the band faster but risks missing beacons.
- Wi-Fi scan interval, 1000 to 10000 ms. How often the all-channel AP discovery scan runs. Between scans the node captures frames passively while hopping.
- BLE scan interval, 1000 to 10000 ms. Time between BLE cycles.
- BLE scan duration, 1000 to 5000 ms. Active BLE scanning per cycle.
- RSSI threshold, −100 to −10 dBm. Global signal filter. Triangulation ignores it.
- Wi-Fi channels. Comma-separated, 1,6,11, or a range, 1..14. Default is 1 to 11.

One radio, two jobs

Wi-Fi and BLE share a single 2.4 GHz radio and the scan loop is single-threaded. A BLE scan holds the radio for its full duration, and Wi-Fi capture is off-air for that time. BLE scan duration is literally the fraction of each cycle Wi-Fi is dark. The presets split it evenly by setting BLE duration to half the BLE interval.

### 8.4 Field controls worth knowing now

- Privacy Mode. One click blanks MACs, SSIDs and GPS in the web UI for screenshots and demos. Exports and SD data are not redacted. Scrub those separately.
- Allowlist. A global list of devices to ignore across every scan mode. Put your own kit on it.
- Battery Saver. Stops Wi-Fi and BLE scanning, drops the CPU to 80 MHz and sends a heartbeat (temperature, GPS) every interval. Mesh stays up. Start it with @AH01 BATTERY_SAVER_START:10.
- Accent Colors. In the System tab. Sets the color of the destructive controls — STOP, the wipe buttons, Clear, error toasts and danger badges — of the Sentinel banners and of the movement hit color. The choice is held in the browser, so a second phone or laptop keeps its own, and the node is not written to.
- Fleet (System tab, full). Lists the nodes and mesh radios heard on your channel. Ping Nodes sends @ALL STATUS so every node answers; Clear empties the list.
- Mesh dedup TTL. Suppresses re-broadcasting a MAC already sent within the window, default 300 s, max 3600. Saves airtime on repeated scans of the same environment. Never applied to alerts, drone events or triangulation.

### 8.5 Where settings live

Configuration is written to NVS on the ESP32 and mirrored to the SD card, so it survives reboots and normal reflashes, and self-heals if a copy is corrupted. Ticking Erase Device at flash time wipes NVS deliberately.

## 9Using the node

Every capability runs on the node itself and reports to the web UI, the mesh and the Command Center alike. One scan mode runs at a time.



The Scan tab on the Full firmware: pick a scan in the top row, set its options on the left, schedule it on the right. Every scan also runs from a mesh command.

### 9.1 Target Scan

A watchlist scan. Load MAC addresses, OUI prefixes, the first three bytes of a MAC so a whole vendor, or SSIDs, and get an instant mesh alert when one is seen.

@ALL CONFIG_TARGETS:AA:BB:CC:DD:EE:FF|11:22:33|MyNetwork
@ALL SCAN_START:2:300:1..11     # mode 0=Wi-Fi 1=BLE 2=both : seconds : channels

Alert: NODE: Target: MAC RSSI:dBm Type:WiFi|BLE [Name:name] [GPS=lat,lon] [V=vendor]. V= is the first word of the vendor name, sent when the MAC is not randomized.

In the web UI a target card shows Getting closer or Moving away when its signal has clearly risen or fallen over recent sightings. Nothing shows while the signal holds steady, or before the target has been seen four times.

### 9.2 Device Scanner

Captures everything nearby, Wi-Fi and BLE, with RSSI, channel and names. This is your baseline survey tool. Run it first at any new site to see what normal looks like.

@ALL DEVICE_SCAN_START:2:300:+PROBE   # +PROBE also fills the probe database

What a BLE device is (full firmware). Device, Target and Baseline results show a badge naming what the device advertises: an Apple service (AirDrop, Handoff, AirPods, Find My, iPhone activity state), or a class and vendor read from its Bluetooth service or company ID, for example Wearable-Garmin, Tag-Tile, Vehicle-Tesla, Drone-RemoteID. The text results carry it as C=. Wi-Fi devices with a fixed MAC show their vendor from the MAC prefix instead.

### 9.3 Probe Request Scanner

Passive sniffing of the probe requests devices emit while looking for networks they know. It reveals the SSIDs a device is searching for, which is often more identifying than the device itself.

@ALL PROBE_START:2:300:+ALL     # +ALL broadcasts every probe, not just watchlist hits

Hits: NODE: PROBE_HIT MAC [Randomized|Vendor] RSSI=dBm CH=N [SSID="net" [GHOST]]

Ghost SSID detection flags a probed SSID with no matching AP responding nearby: a network the device remembers but that is not here.

### 9.4 Baseline Anomaly Detection

Learn, then alert. The node observes a site for a set period and records what belongs there. Afterwards it reports what is new, what has gone, and what has changed signal.

@ALL BASELINE_START:300        # minimum 60s; add :FOREVER to run indefinitely
@ALL BASELINE_STATUS

Alerts: ANOMALY-NEW, ANOMALY-RETURN, ANOMALY-RSSI, DEVICE_DISAPPEARED.

Watch for changes from now. While a baseline runs, press the button (full firmware) or send @ALL BASELINE_WATCH. The node replies BASELINE_ACK:WATCHING, or BASELINE_ACK:NOT_RUNNING if no baseline is running. When the baseline ends, it reports what is new here, what is gone, and what moved closer or away since that moment. Full firmware shows this in a Since section in Results. Headless prints the device list to serial and sends BASELINE_WATCH: New=<n> Gone=<n> Moved=<n> Both=<n> over mesh. Use it when you leave a site and want to see what changed while you were away.



Target scan results (§9.1).



Probe detection: devices, probes, SSIDs and saved records (§9.3).



Baseline learning phase: device counts and the anomaly total (§9.4).

### 9.5 MAC Randomization Correlation

Modern phones rotate their MAC address to defeat tracking. This mode links rotating MACs back to one persistent identity using behavioral signatures, and reports the identity rather than the address.

@ALL RANDOMIZATION_START:2:300

Emits IDENTITY: messages. Treat the output as an investigative lead, not proof. This is an experimental mode.

### 9.6 Deauth Attack Detection

Real-time detection of deauthentication and disassociation frames, with the source tracked.

@ALL DEAUTH_START:300

Alert: NODE: ATTACK: DEAUTH|DISASSOC [BROADCAST|TARGETED] SRC:MAC DST:MAC RSSI:dBm CH:N R:reason. The IEEE reason code is reported as context only: codes 1, 2, 6 and 7 all occur in normal traffic, so the firmware does not use the code to decide whether a frame is an attack.

### 9.7 Sentinel counter-intelligence (beta)

Passive detection of attacker tooling, not just attacks: deauth, beacon, auth and association floods, SAE denial of service, karma and evil-twin access points, probe floods, and handshake or PMKID capture attempts. Where a frame carries a recognizable template, Sentinel names the tool behind it.

@ALL SENTINEL_ON
@ALL SENTINEL_MODE:scan        # hop the configured channels
@ALL SENTINEL_BOOT:1           # start automatically on boot
@ALL GROUP:dos:on              # enable a detector group
@AH01 SENTINEL_STATUS
@AH01 INCIDENTS:50             # dump the incident log to serial

Group | Detectors
dos | eviltwin, sae, assoc_sleep
rogue | eviltwin, owe, karma
recon | pmkid, probe_flood, hshk
physical | frag, tsf, jam
mesh | mesh_guard
all | every member above

Deauth, beacon and auth detection are always on and have no toggle. SENTINEL_MODE:defend pins one channel. On Headless there is no AP to pin to, so use scan. Sentinel is Wi-Fi only. BLE and drone detection are separate modes.

Karma bait

Karma bait is the only Sentinel detector that transmits: a probe request every 8 seconds to bait a karma AP into responding. It is off by default. Enable it deliberately with GROUP:rogue:on and only where transmitting is appropriate.

#### Acting on a confirmed attack



The Sentinel tab: a live counter per detector, the associated AP clients it has seen, and the session incident log.

The On confirmed attack panel picks what runs when a detector confirms an attack with a source MAC: triangulate, packet capture, device discovery, probe sweep, drone RID, each with its own duration. Only one can hold the radio, so several ticked run in that order, one at a time, as it frees up. The queue is dropped after 15 minutes if the radio never frees.

Same panel sets the auto-capture budget. Captures made this way are auto_ files, pruned oldest-first to stay inside the budget and keep the card's free-space floor. Manual captures are never touched.

A response is a scan

Detection pauses for the duration of each action. On a site that trips often, keep the durations short.

### 9.8 Drone Remote ID

Identifies drones broadcasting Remote ID (ODID / ASTM F3411, and French ID) over both Wi-Fi beacon/NAN and BLE. Reports the serial or CAA registration, position, altitude and speed, and the operator's location when the aircraft broadcasts it.

@ALL DRONE_START:300

DRONE: is sent once per appearance. A drone that stays in range is not re-announced. DRONE_LOST: follows 120 s after the last beacon.

### 9.9 Triangulation

Several nodes each report RSSI for one target MAC, and the coordinator fits a position from the set. Needs at least three nodes with valid GPS fixes and matched antennas.

@AH01 TRIANGULATE_START:AA:BB:CC:DD:EE:FF:60:2:1.0:1.0
@AH01 TRIANGULATE_RESULTS
@ALL TRIANGULATE_STOP

The environment argument sets the path-loss model: 0 open sky, 1 suburban, 2 indoor, 3 dense indoor, 4 industrial. Choosing the wrong one is the usual cause of a distance estimate that looks wrong. Results arrive as T_D: per-node data, T_F: the final fix with confidence and uncertainty, and T_C: complete, with a map link.

### 9.10 CSI Motion Detection (experimental, beta firmware only)

Tells you when someone is moving nearby, even through walls. Indoors only. It notices movement, not someone sitting still.

How it works. Wi-Fi signals bounce around a room. When a person moves, the bounces change. The node listens to the Wi-Fi routers and phones around it and alerts when several of their signals change at once.

Start it: Scan tab → CSI Motion Detection → Start Scan. Over mesh:

@ALL CSI_MOTION_START:0:FOREVER

Pick a sensitivity:

- Low (default): fewest false alarms. Two devices must see the movement.
- Medium: more sensitive. Two devices, or one device seeing a very strong change (4× the trigger).
- High: most sensitive. Same as Medium with a lower trigger and a shorter wait. More false alarms.

Settings (Scan tab → CSI Motion Detection; most are under Advanced):

Setting | What it means | Default
Movement needed before alerting | How long someone must move before you get an alert | 8 s
Stillness before all-clear | How long it must be quiet before the alert clears | 5 s
Devices that must agree | How many devices must see the movement at the same time | 2
Trigger level | Lower catches smaller movement | set by sensitivity
Listen only, never transmit | The node never sends probes. Turn off only if it sees too little Wi-Fi | On
Include randomized-MAC devices | Also listen to phones and watches, not just routers | On
Min. seconds between mesh motion alerts | Wait at least this many seconds between motion alerts sent over mesh | 0 (no limit)

Getting false alarms with nobody there? Turn on "Per-packet score to serial", watch the sig numbers while the room is empty, and set Trigger level just above the highest one.

Can transmit

Off by default. If you turn off "Listen only, never transmit", the node sends Wi-Fi probe requests when there is too little traffic to measure. Anyone nearby can see them. Check local rules before turning it on.

Mesh commands: §11.

### 9.11 Packet Capture

Records raw traffic to SD as a standard pcap. Wi-Fi frames carry a radiotap header with channel, rate and RSSI. BLE captures are written as Bluetooth HCI, link type 187: the controller's own events, unmodified, so Wireshark shows LE Advertising Reports with address, address type, advertising data and RSSI. HCI carries no RF channel, so the capture does not report one.

Scan tab, pick Packet Capture, set radio and duration, press Start Capture. Files land in /pcap and list under the button, each with a download and a delete.

@ALL PCAP_START:0:300:0
@ALL PCAP_STOP

Arguments are radio, seconds, band. Radio 0 Wi-Fi, 1 BLE, one at a time; there is no both, and any other value, including 2, is taken as Wi-Fi. Unlike the mode field of the other scan commands, 2 does not mean both here. Band 0 is 2.4 GHz, 1 is 5 GHz, 2 both; 5 GHz needs a C5. Advanced sets a channel list, dwell, a management-frames-only filter, and the maximum file size.

The mesh reply names the radio that actually started, PCAP_START: WIFI or PCAP_START: BLE. Getting WIFI back from a command you meant as BLE means the radio field was wrong. A capture started by a vibration trigger or a Sentinel attack response is always Wi-Fi on 2.4 GHz; BLE is a manual choice only.

A capture stops on its own when the file reaches the size cap, when free space drops below the floor, or when the card stops accepting writes. The mesh reply carries the reason: R=SIZECAP or R=WRITEFAIL. The cap is 8 to 300 MB, 100 MB by default, set on the Scan tab or over mesh.

@ALL PCAP_LIMITS:150
@ALL PCAP_LIMITS

Captures are large and carry everything

A busy channel fills megabytes per minute. Check free space before a long run, and treat the file as a raw intercept.

Stop the capture before you cut power

FAT has no power-fail protection. Resetting or unplugging a node while a capture is writing can leave the card unreadable until it is reformatted, and the node then runs with no storage at all: no logging, no baseline, no captures. Stop the capture first.

A node can rebuild its own card instead of waiting for someone with a card reader. This is off by default because rebuilding erases everything on the card.

@ALL SD_REPAIR:ON
@ALL SD_REPAIR:NOW
@ALL SD_REPAIR:OFF

NOW repairs once without changing the setting. With repair off, a failed mount says so once a minute and the SD line in Diagnostics shows how many times it has failed.

### 9.12 Scheduling scans

The Schedule panel on the Scan tab runs any scan at set times. The node runs it, so the web page can be closed.

1. Pick the scan in the top row and set its options.
2. Press Schedule this scan.
3. Set Start, Duration in minutes and Repeat, then press Add.

The block keeps the options that were set when you added it. Changing the scan's options later does not change the block. Delete it and add it again instead.

Setting | Values
Start | Date and time in the node's local time, shown with its zone, for example MST
Duration | 1 to 1440 minutes
Repeat | Once, hourly, every 6 hours, every 12 hours, daily, weekly

- Time zone. The node picks its zone from the GPS fix, daylight saving included. Daily and weekly blocks keep the same clock time across a daylight saving change. With no GPS fix, or outside the zone table, times are UTC.
- Busy radio. A block that comes due while another scan holds the radio runs as soon as the radio frees. A repeating block then moves to its next slot. If a mesh command or another start takes the radio at the same moment, the block is not lost; it tries again 5 seconds later.
- Vibration and attack scans. By default they wait for a scheduled scan: a vibration auto-scan is skipped, an attack response runs when the scan ends. Turn on Interrupt scheduled scans in Vibration Auto-Scan (System tab) or in the attack-response panel (Sentinel tab) to let that trigger stop the scheduled scan, run, and then resume the scheduled scan for its remaining time. A resumed Baseline starts its learning phase again. A scheduled block never takes the radio while a vibration or attack scan is waiting for it.
- Over mesh. SCHED_ADD:2026-09-30T02:00|86400|/sniffer|detection=device-scan&deviceScanMode=2&secs=600 adds a daily block. SCHED_LIST prints the blocks to serial, SCHED_DEL:2 deletes the second one.
- Battery Saver. Schedules pause while Battery Saver is on. A block that came due runs once when it ends.
- Limits. 8 blocks. They are kept in NVS and survive reboots.
- Baseline blocks. Adding one saves the baseline settings on the Scan tab to the node, and each run uses the baseline settings saved at that time.

Clock

Schedules need the clock from §4.3. On a node without a working RTC, blocks wait until the web UI is opened once after boot, which gives the node the time.

### 9.13 Reading the results

- SD card, both builds. Scan results in /last_results.txt, the probe database, vibration events in /vibrations.jsonl, packet captures in /pcap, sentinel incidents and the scan logs. Logging does not depend on which firmware you flashed.
- Web UI, Full only. The Results tab renders each scan as cards, and the API serves the same content as plain text.
- Device database, Full only. /devicedb.jsonl is what the Data Explorer browses. Headless does not write it.
- Mesh. Every alert above, plus SCAN_DONE: summaries carrying TX= broadcast and DUP= deduplicated counts.

Exports carry location

SD logs, exports and mesh alerts can all contain GPS coordinates. Review any file before you post it publicly or attach it to a report. Privacy Mode only redacts the live web UI.

## 10Vibration sensor and tamper response

### 10.1 How it works

The SW-420 is a mechanical vibration switch with a comparator and a trimpot on board. It has one job: pull its digital output high when movement exceeds the threshold the trimpot sets. That output goes to GPIO 2 on the ESP32, configured as a pull-down input with a rising-edge interrupt.

When it fires, the firmware:

- Sends a mesh alert if vibration alerts are enabled: NODE: VIBRATION: Movement detected at TIME [GPS:lat,lon]
- Writes a structured event to /vibrations.jsonl on the SD card
- Optionally starts a scan (§10.3)
- Counts toward the tamper auto-erase trigger if that is armed (§10.4)

Alerts are rate-limited to one every 3 seconds, so continuous shaking produces a steady trickle rather than a flood. The System diagnostics show Vibration sensor: Standby or Vibration sensor: Active - Last: TIME (Ns ago).

Turn alerts on and off with @AH01 VIBRATION_ON and VIBRATION_OFF, or the toggle in the web UI's Sensor Alerts card. VIBRATION_STATUS reports the current state.

### 10.2 Tuning the trimpot

The trimpot is the small brass screw on the sensor module. It sets the sensitivity threshold, and the correct setting depends entirely on where the node is mounted. A pole in the wind is not a shelf indoors. Tune it after the node is in its final position, not on the bench.

1. Power the node and watch the sensor's own indicator LED, or open a serial monitor and watch for [VIBRATION] lines.
2. Leave the node completely still. If it is triggering by itself, turn the screw an eighth of a turn at a time in the direction that stops it. Wait several seconds between adjustments. The module reacts slowly.
3. When it is silent at rest, back off slightly further so ambient movement does not set it off.
4. Now tap the enclosure the way a person handling it would. It should fire.
5. If it does not, turn back the other way a fraction at a time until a deliberate tap triggers it but the node at rest does not.
6. Confirm the events actually reached the firmware: the diagnostics timestamp updates, and each event is appended to /vibrations.jsonl.

Tuning by symptom

- Constant false alerts. Too sensitive, or mounted on something resonant. Reduce sensitivity, and consider a foam pad or a stiffer mount.
- Nothing fires even when you shake it. Too insensitive, or the sensor is not seeing GPIO 2. Check the diagnostics line and the solder joints on the sensor header.
- Fires only sometimes. You are on the edge of the threshold. Back it off a fraction toward sensitive.

### 10.3 Vibration auto-scan

Movement can start a scan automatically. This suits a node used as a trip sensor rather than a continuous monitor.

@AH01 VIBSCAN_SET:1:2:60:60:1  # on : mode : secs : cooldown s : interrupt schedule
@AH01 VIBSCAN_STATUS

Mode | Scan started | Mode | Scan started
0 | None | 4 | List scan (targets)
1 | All-device scan | 5 | Drone / Remote ID
2 | Probe-request detect | 6 | Deauth (blue team)
3 | Randomized-MAC detect | 7 | Baseline anomaly
| | 8 | Packet capture to SD

Duration 0 means run until stopped. The trigger is skipped if a scan is already running or the node is in battery saver. Mode 8 writes an auto_ capture, which is subject to the auto-capture budget rather than kept forever.

### 10.4 Tamper auto-erase

The node can destroy its own data when it is moved. This is off by default, and it is permanent and irreversible.

Parameter | Range | What it does
Setup delay | 30 s to 10 min | Grace period after arming, so installing the node does not wipe it
Vibrations required | 2 to 5, default 3 | How many movement events count as tampering
Detection window | 10 to 60 s | The period those events must fall within
Erase delay | 10 to 300 s | Countdown before destruction, your window to cancel
Cooldown | 5 to 60 min | Minimum time between tamper attempts, to blunt false triggers

@AH01 AUTOERASE_ENABLE:60:30:3:30:300:<key>   # setup:erase:vibs:window:cooldown:key
@AH01 AUTOERASE_STATUS
@AH01 AUTOERASE_DISABLE:<key>
@AH01 ERASE_CANCEL:<key>                       # abort a running countdown

During the setup period the node still reports movement, so you can watch the arming from a distance: VIBRATION: Movement in setup mode (active in Ns). When it triggers you get TAMPER_DETECTED: Auto-erase in Xs.

#### Remote erase

Every command marked <key> takes the erase key (§8.1): @AH01 ERASE_FORCE:<key>. 5 wrong keys lock erase commands for 10 min.

To keep the key off the mesh, answer a token instead:

1. Send @AH01 ERASE_REQUEST (one per 20 s). The node replies AH01: ERASE_TOKEN:AH_3F2A91C0_77B0E412_000004D2 Expires:300s.
2. Sign the token: printf '%s' 'AH_3F2A…' | openssl dgst -sha256 -hmac 'yourKey'.
3. Within 300 s send the 64 hex characters, or the first 8, in place of <key>. A token answers once.

In the web UI, enter the key in the Authorization field.

After a wipe the node plants a dummy IoT weather configuration in place of its own, so a recovered device does not obviously read as a sensor.

#### Factory reset

@AH01 FACTORY_RESET:FULL:<key>    # FULL | CONFIG | DATA

Single node only.

Data destruction is irreversible

Test your settings with a node that holds nothing you care about. A wipe cannot be undone, and the countdown is short by design.

## 11Mesh command reference

Send these as ordinary text messages from the Meshtastic app, a Command Center, or any client on your channel. @ALL broadcasts. A node ID targets one node. Times are the node's local time once GPS fixes the zone, UTC before that.

### Core

Command | Description
STATUS | Mode, scan state, hits, temperature, uptime, GPS; then STATUS_BOOT: reset reason, previous uptime, SD faults
STOP | Stop all operations and any pending attack response, flush pending mesh transmissions

### Configuration

Command | Does | Parameters
CONFIG_TARGETS | Set the watchlist | Pipe-delimited MACs, OUIs or SSIDs
CONFIG_NODEID | Rename the node | 2 to 5 alphanumeric characters
CONFIG_RSSI | Set the RSSI floor | −128 to −10
CONFIG_CHANNELS | Set the channels to sweep | List or range, e.g. 1..11
CONFIG_BAND | Pick the band, C5 only | 0 = 2.4 GHz, 1 = 5 GHz, 2 = both
CONFIG_DEDUP_TTL | Set cross-scan MAC dedup | 0 to 3600 s, 0 disables
CONFIG_SESSION_DEDUP | Toggle per-session dedup | 0 or 1
MESH_DEDUP_CLEAR | Clear the dedup cache | None
DEVICE_DB_CLEAR | Clear the discovered-device DB, headless, Beta and C5 | None
CONFIG_ERASE_PSK | Set the erase key | <new>:<current>, 8 to 64 characters, no :; §8.1

### Scanning

Command | Does | Parameters
SCAN_START | Hunt the watchlist | mode:secs:channels[:FOREVER]
DEVICE_SCAN_START | List everything in range | mode:secs[:FOREVER[:+PROBE]]
PROBE_START and PROBE_STOP | Collect probe requests | mode:secs[:FOREVER][:+ALL]
BASELINE_START and BASELINE_STATUS | Learn the area, then flag changes | duration[:FOREVER], min 60 s
BASELINE_WATCH | Watch for changes from now | None; baseline must be running
DRONE_START | Watch for drone Remote ID | secs[:FOREVER]
DEAUTH_START | Watch for deauth attacks | secs[:FOREVER]
RANDOMIZATION_START | Link randomized MACs to devices | mode:secs[:FOREVER]
CSI_MOTION_START | Detect movement in the room, Beta and C5 | secs[:FOREVER][:CH<n>][:TELEM][:RAW][:GAP<s>][:LISTEN_ONLY|ALLOW_TRANSMIT][:MGMTONLY|MGMTDATA][:SOLICIT<ms>]
CSI_CFG | Tune the motion trigger, Beta and C5 | trigger:hold_ms:consec:channel or SENSITIVITY=LOW|MEDIUM|HIGH, MIN_MOTION=, CLEAR_AFTER=, SPOTS=, BROADCAST=ON|OFF, ALLOW_RANDOM=ON|OFF
CSI_STATUS and CSI_JSON | Dump motion state to serial, Beta and C5 | None
CSI_RECAL | Drop a saved trigger, Beta and C5 | None
CSI_EXCLUDE | Ignore one MAC for motion, Beta and C5 | <MAC> or NONE
MESH_TX_CANCEL | Drop queued mesh traffic, keep scanning | None
PCAP_START and PCAP_STOP | Record traffic to SD as pcap | radio:secs:band[:CH<list>]
PCAP_LIMITS | Set or read the capture size cap | [MB], 8 to 300
PCAP_AUTO | Set or read the auto-capture SD budget | [budgetMB,floorMB]
PCAP_DELETE_ALL | Delete every capture on SD | None
SD_REPAIR | Rebuild an unmountable SD card; erases it | ON|OFF|NOW
TRIANGULATE_START | Locate a MAC across nodes | target:duration[:rfEnv[:wifiPwr:blePwr]]
TRIANGULATE_RESULTS and TRIANGULATE_STOP | Report the fix, or stop | None

Mode is 0 Wi-Fi, 1 BLE, 2 both. CH0 or no channel surveys and pins the busiest. PCAP is the exception: its radio field is 0 Wi-Fi / 1 BLE only, one radio per capture, and 2 is taken as Wi-Fi rather than both. PCAP band 0 is 2.4 GHz, 1 is 5 GHz, 2 both; 5 GHz needs a C5.

### Sentinel (Beta and C5)

Command | Does | Parameters
SENTINEL_ON, SENTINEL_OFF, SENTINEL_STATUS | Start, stop, report | None
SENTINEL_MODE | Pin a channel or hop | defend or scan
SENTINEL_BOOT | Auto-start at power-on | 1 or 0
GROUP | Toggle a detector group | <dos|rogue|recon|physical|mesh|all>:<on|off>
DETECT_CFG and DETECT_CFG_GET | Set or dump detector tunables | JSON, 180 characters or fewer
INCIDENTS and INCIDENTS_CLEAR | Dump or clear the incident log | [:1-200]
ATTACKER_TRILAT and ATTACKER_TRILAT_STATUS | Triangulate a confirmed attacker, or report the setting | 1 or 0, off by default
DETECT_JSON and DETECT_CLEAR | Dump a detector's list to serial, or clear it | karma|pg|tsf|hshk|pwna|tof|hunts|pcap|pcaps
DETECT_COUNTS | Entry count per detector, pending attack responses | None
DETECT_VERBOSE | Per-frame detector logging on serial | ON|OFF
QUORUM | Nodes that must agree before an alert | <type>,<n>, e.g. PMKID,2
KARMA_ON and KARMA_OFF | Karma detector; transmits bait probes to confirm a suspect AP | None
HUNT_COOLDOWN | Gap between attacker hunts | ms
TOF_PING | Time-of-flight ping | [:node], all if omitted
ATTACK_RESPONSE_CANCEL | Drop a pending attack response | None

### Security, power and heartbeat

Command | Does | Parameters
ERASE_REQUEST, ERASE_FORCE, ERASE_CANCEL | Token, wipe, abort | None, <key>, <key>; §10.4
AUTOERASE_ENABLE | Wipe if the node is moved | setup:erase:vibs:window:cooldown:key
AUTOERASE_DISABLE and AUTOERASE_STATUS | Turn that off, or report it | <key>, none
VIBRATION_ON, VIBRATION_OFF, VIBRATION_STATUS | Enable, disable, report the sensor | None
VIBSCAN_SET and VIBSCAN_STATUS | Start a scan when moved | en:mode:dur[:cooldown[:interrupt]]
SCHED_ADD, SCHED_LIST, SCHED_DEL | Add, list or delete a schedule block | at|repeat s|path|body, none, block number
FACTORY_RESET | Reset one node | <FULL|CONFIG|DATA>:<key>
BATTERY_SAVER_START | Drop to low power | Minutes, 1 to 30, default 5
BATTERY_SAVER_STOP and BATTERY_SAVER_STATUS | Return to normal, or report | None
HB_ON, HB_OFF, HB_INTERVAL | Periodic status broadcast, off by default | Interval 1 to 60 min

### Ten commands to learn first

@ALL STATUS                          # who is alive, and what are they doing
@ALL STOP                            # stop everything, everywhere
@AH01 CONFIG_NODEID:GATE1            # name a node
@ALL CONFIG_TARGETS:AA:BB:CC|MyWiFi  # set the watchlist
@ALL SCAN_START:2:600:1..11          # 10 min watchlist scan, Wi-Fi + BLE
@ALL DEVICE_SCAN_START:2:300         # survey everything nearby
@ALL BASELINE_START:900              # learn the site for 15 min
@ALL SENTINEL_ON                     # attacker-tool detection
@ALL DRONE_START:0                   # drone watch until stopped
@AH01 BATTERY_SAVER_START:10         # idle a node without losing the mesh

## 12Command Center

One node needs no server. A fleet benefits from one: AntiHunter Command & Control PRO aggregates every node's detections onto a live map, with TAK, MQTT and ADS-B integration and a Sentinel console.



Nodes operate independently and coordinate over the mesh. The Command Center aggregates.

### 12.1 What you need

- A computer to run it on: Linux, macOS or Windows 10/11. It can be the same machine you flash from.
- A Meshtastic radio on USB, joined to your channel, to receive the mesh.
- Node.js 20 or newer and PostgreSQL. The installer puts both in place for you.

### 12.2 Quick install: Linux and macOS

curl -o setup-local.sh \
  https://raw.githubusercontent.com/TheRealSirHaXalot/AntiHunter-Command-Control-PRO/main/scripts/setup-local.sh
chmod +x setup-local.sh
./setup-local.sh

Run it as a normal user, not with sudo. It asks for sudo itself when it needs it. It installs the prerequisites, clones the project, sets up the database, runs the migrations and seeds an admin login. When it finishes, open http://localhost:5173 and log in with the credentials it printed.

### 12.3 Quick install: Windows 10/11

1. Install Git in any PowerShell window, then close it so Git lands on your PATH:

winget install -e --id Git.Git --accept-package-agreements --accept-source-agreements
2. Open PowerShell as Administrator. The installer needs it to install system software.
3. Clone and run the installer:

cd $HOME
git clone https://github.com/TheRealSirHaXalot/AntiHunter-Command-Control-PRO.git
cd AntiHunter-Command-Control-PRO
powershell -ExecutionPolicy Bypass -File scripts\setup-windows.ps1
4. Press Enter to accept the defaults. The first run takes a few minutes. Write down the admin email and password it shows you.
5. Start it with Start-AntiHunter.cmd in the project folder, or pnpm AHCC.
6. Open http://localhost:5173 and log in.

Windows notes

- The firewall prompt on first start: click Cancel if you only use it on this PC, since localhost works either way. To reach it from other devices, click Allow and tick Private only.
- For serial hardware, put SERIAL_DEVICE=COM3, your port from Device Manager → Ports, in apps\backend\.env and restart.
- Do not use WSL. COM ports do not pass through cleanly.

### 12.4 Docker

Needs Docker 25 or newer. If you have no serial adapter at /dev/ttyUSB0, which is every macOS and Windows host, comment out the devices: and group_add: lines under the backend service first, or the container will not start.

git clone https://github.com/TheRealSirHaXalot/AntiHunter-Command-Control-PRO.git
cd AntiHunter-Command-Control-PRO
docker compose up -d --build

Three containers come up: Postgres, the backend on port 3000, and the frontend on http://localhost:8080. The seeded admin defaults to admin@example.com and admin. Logs: docker compose logs -f backend. Stop: docker compose down, adding --volumes to delete the database too.

Change the admin password immediately

The seeded credentials are published in the documentation. Change them at first login, before the server is reachable by anything but you. Enable two-factor authentication and HTTPS if the instance will be reached across a network, and work through the hardening checklist in the project README.

### 12.5 Updating

Use the in-app update page, or git pull in the project folder. Docker: git pull && docker compose up -d --build. The backend re-applies migrations on boot.

### 12.6 Reaching it from anywhere, and alerts to your phone

The Command Center's Remote Connections guide (https://github.com/TheRealSirHaXalot/AntiHunter-Command-Control-PRO/blob/main/docs/INTERNET-CONNECTIVITY.md) walks through each option with a check at every step:

I want to… | Use
Run the map and console from my phone, away from site | Tailscale (private VPN between your own devices)
Let others in without installing an app | Cloudflare Tunnel with an email login
Get a message when a node detects something | Push, Signal, ntfy, Matrix, Discord, IFTTT, Home Assistant, email
See nodes and targets in ATAK, iTAK or WinTAK | TAK bridge
Feed detections to scripts, or link two sites | MQTTS broker and federation

Never forward the Command Center's ports on your router. Set its admin password and two-factor first; the guide starts there.

## 13Deployment

### 13.1 Siting

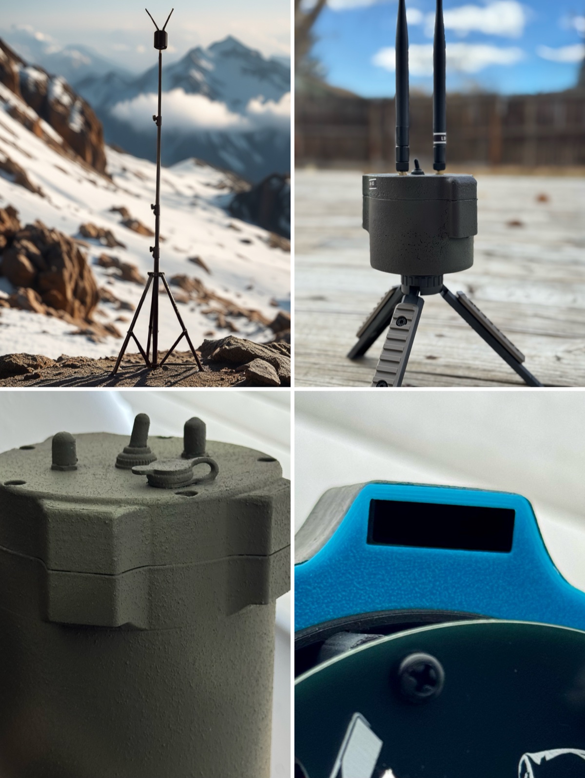
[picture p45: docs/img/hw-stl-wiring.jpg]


Mast, tripod, can and puck builds. The enclosure changes. The node does not.

- Height helps more than power. Get the node above metal, vehicles and crowds. A few metres of elevation beats any antenna change.
- Antennas vertical, and clear of the enclosure's own metalwork and of each other.
- GPS wants sky. The helix or patch needs a clear upward view. Indoors it may never lock, and without a fix your detections carry no coordinates and triangulation cannot run.
- Keep LoRa and Wi-Fi antennas apart as far as the enclosure allows.
- For multi-node triangulation, spread nodes around the area rather than in a line, and give each one a clear GPS fix. Matched antennas on every node.

### 13.2 Sealing and mounting

- Fit the TPU seals for the housing, GPS and USB-C port. Silicone grease on the seals and SMA threads helps in persistent wet.
- No IP rating is claimed for the printed enclosure. Treat it as weather-resistant, not waterproof, and site it accordingly.
- The base takes a ¼"-20 insert for tripods and the universal bracket. STL files for brackets, solar mounts and radar extensions are in the hw/ folder.
- Point the vented lid and fan opening downward or shielded so water does not sit in them.



An enclosed build with the antennas vertical and the switch centered.



Vented lid, SMA bulkheads on top, battery housing below.

### 13.3 Power planning

- Roughly 160 mA idle, 600 mA scanning. Aggressive presets and continuous promiscuous capture sit at the top of that range.
- Battery Saver stops scanning, drops the CPU to 80 MHz and polls GPS once a minute while keeping the mesh alive. That is the right state for a node that only needs to be reachable.
- Solar mount frames are in the STL folder. Feed solar through the UPS board, never directly to the PCB.
- Never use the chassis USB input and the UPS fast-charge input at the same time.

### 13.4 Playbooks

Set-and-forget setups for common situations. Schedule blocks run with the web page closed and survive reboots; set them in the Scan tab (pick the scan, then Schedule this scan) or over mesh with SCHED_ADD (full firmware). Times are the node's local time. Repeat 86400 is daily, 604800 weekly, 0 once.

#### Overnight perimeter watch (home, shop, site)

Learn what belongs, then flag anything new after dark. Pair with Sentinel for attacks on your Wi-Fi.

@AH01 SCHED_ADD:2026-10-05T21:00|86400|/sniffer|detection=baseline&secs=32400   # 9 h, nightly
@AH01 SENTINEL_BOOT:1                     # Beta: attack detection from power-on
@AH01 VIBRATION_ON

You get ANOMALY-NEW for a device that was not there at dusk, and Sentinel alerts for deauth, evil twins and similar attacks.

#### Someone casing the place

The same phone or car showing up on different days is the tell. Run a device scan while they are around, put the MACs you care about on the watchlist, then hunt them on a schedule.

@AH01 DEVICE_SCAN_START:2:600
@ALL CONFIG_TARGETS:AA:BB:CC:DD:EE:FF|11:22:33
@ALL SCAN_START:2:0:1..11:FOREVER                                   # or schedule it:
@AH01 SCHED_ADD:2026-10-05T08:00|86400|/scan|mode=2&secs=36000&ch=1..11

A hit sends Target: MAC RSSI Type Name GPS V=vendor at once; the web UI shows Getting closer or Moving away as it moves.

#### While you are away

Start a baseline when you arrive. When you leave, press Watch for changes from now or send @AH01 BASELINE_WATCH. Back home, the results list what is new, what is gone, and what moved closer.

#### Drones over the property

@AH01 SCHED_ADD:2026-10-05T06:00|86400|/drone|droneScanMode=2&secs=57600   # daylight hours

Each aircraft broadcasting Remote ID is reported once with its ID, position and operator location when sent.

#### Your Wi-Fi is being attacked

Most Wi-Fi attacks start by knocking clients off with deauthentication frames: to capture a handshake, push them onto an evil twin, or just jam. The Deauth scan catches that on every build; run it around the clock.

@AH01 DEAUTH_START:0:FOREVER
@AH01 SCHED_ADD:2026-10-05T00:00|86400|/sniffer|detection=deauth&secs=86400   # or as a daily block
@AH01 SENTINEL_ON                          # Beta: also evil twins, karma, PMKID, floods

Alerts name the source MAC and target. Sentinel can also start triangulation, a capture or a sweep on a confirmed attack (Sentinel tab → On confirmed attack).

#### Unattended in a vehicle or camp

@AH01 VIBSCAN_SET:1:1:300:600              # a bump starts a 5 min device scan
@AH01 BATTERY_SAVER_START:10                # mesh stays reachable between events

#### Several sites, one screen

Run the Command Center (§12) on a machine at one site with a Meshtastic radio on USB. Reach it from your phone over Tailscale and route alerts to Signal or push (§12.6).

### 13.5 Before you walk away

- AP credentials changed, or Headless firmware flashed
- LoRa region set and your own encrypted channel primary, public channel off
- Node ID set and recorded
- Clock set, GPS has a fix
- SD card mounted and writable
- Vibration sensor tuned in its final position
- Auto-erase parameters understood if you armed it, and the erase key recorded somewhere safe
- The node answers @NODEID STATUS over the mesh from where you will be standing
- Antennas tight, seals seated, lid closed

## 14Maintenance and troubleshooting

### 14.1 Symptom table

Symptom | Likely cause | What to do
No Antihunter Wi-Fi network | Headless firmware flashed, or the AP name and password were changed | Check over serial which build is running. Reflash Full if you need the UI.
Web UI will not load | Not connected to the node's own AP, or using https | Join the node's AP, then open http://192.168.4.1 exactly.
Flashing fails or the port never appears | Charge-only USB cable, a serial monitor still holding the port, both USB ports connected, or the wrong browser | Use a data cable, close other serial tools, unplug the radio, use Chrome or Edge.
SD card not detected | Not FAT32, a 32 GB or larger card, or not seated | Reformat FAT32 on a card under 32 GB. Reseating means opening the enclosure.
No GPS fix | Antenna not connected, or no view of the sky | Check the U.FL or SMA connection, move outdoors, give it time. The module runs hot while searching, which is normal.
Nothing arrives over the mesh | Region UNSET so the radio is receive-only, serial module off, wrong pins for the board, or nodes on different channels or keys | Re-run meshtastic_config.py and print the settings. Confirm every node carries the same channel.
Node hears commands but never answers | Region unset on that node, so it cannot transmit | Set its region.
Constant vibration alerts | Trimpot too sensitive, or a resonant mount | Retune in place (§10.2), pad the mount.
Vibration never fires | Trimpot too insensitive, or a bad joint on the sensor header | Retune, check the diagnostics line and the solder joints.
Node scans forever | A scan was started with :FOREVER or duration 0 | @ALL STOP, or the Stop button in the UI.
Settings gone after flashing | Erase Device was ticked | Reconfigure. Settings mirror to the SD card and self-heal, but a deliberate erase clears NVS.
Node hot to the touch | Normal under sustained scanning | Fit the fan and thermal switch, ventilate the enclosure, consider a relaxed preset.
Detections with no coordinates | No valid GPS fix at the time | Expected behavior. Position is only attached when the fix is valid.

### 14.2 Routine maintenance

- Pull the SD card periodically and archive the logs, then clear them, so a lost node carries less.
- Check the cells. A swollen or damaged 18650 is retired immediately, never recharged.
- Re-check antenna tightness and seal condition after any period in the field.
- Reflash on the same channel to pick up fixes. Read the release notes first.

### 14.3 Getting help

Issues and Discussions at github.com/lukeswitz/AntiHunter. A useful report includes: firmware build and channel, Full or Headless, board type, what you did, what you expected, what happened, and the serial output around the failure. Scrub coordinates and MAC addresses from anything you paste. See §15.

## 15Legal and safety

### 15.1 Authorization

AntiHunter is distributed for lawful, authorized defensive use only: security research, blue-team training, compliant monitoring, event security and network auditing. Operate it only on infrastructure, networks, devices, spectrum and datasets you own or have explicit written permission to assess. The detection, correlation and triangulation features exist to characterize an environment you are authorized to assess, not to identify, follow or profile people. Targeted surveillance, stalking, harassment and tracking individuals without informed consent are prohibited.

### 15.2 Radio compliance

You are responsible for every rule governing radio use where you operate: FCC Part 15 and Part 97, CE/RED, Ofcom and their national equivalents; ISM band allocations, power limits and duty cycles; and any licensing conditions for your class of operation. LoRa is region-locked, 868 MHz EU, 915 MHz US, 923 MHz Asia, and running a region outside the one you are in may be unlawful. Never use the node to cause harmful interference.

### 15.3 Interception and privacy

Passive reception of radio emissions is regulated separately from network access in most jurisdictions. Capturing, storing, decoding or disclosing frame contents and identifiers may engage the US Wiretap Act and ECPA, state two-party-consent statutes, the UK Investigatory Powers Act or equivalents. Determine the lawfulness of each capture mode where you are before enabling it.

MAC addresses, probe request contents, BLE advertisements and Remote ID broadcasts may be personal data under GDPR, UK GDPR, CCPA/CPRA and similar regimes. Collect only with a lawful basis, minimize what you keep, set a retention and destruction schedule, and honor data-subject rights. The maintainers never receive, process or host your data.

### 15.4 Drone Remote ID

Receiving broadcast Remote ID is permitted in most places. Using that data to locate, approach, confront or interfere with an aircraft or its operator may violate aviation, harassment or anti-stalking law, including 18 U.S.C. § 32. Reception is not authorization to act.

### 15.5 Hardware and battery safety

Kits, bare boards and assembled units are supplied for people competent in electronics assembly and operation. Correct assembly, ESD control, antenna selection and attachment, and supply of regulated 5 V power are your responsibility. Operating the transceiver without a properly matched antenna can damage the hardware. Lithium cells are never supplied. Sourcing, protection, charging, storage, transport and disposal are yours, and carry fire and injury risk. The hardware is not certified for and must not be used in life-safety, medical, aviation, automotive or industrial-control applications. It is not a substitute for a certified security or alarm system, and its output is advisory only, subject to false positives and false negatives.

### 15.6 Experimental features

Modes marked beta or experimental, including Sentinel, Triangulation and MAC Randomization Correlation, are unvalidated, may produce inaccurate or misleading output, and must not be relied on for operational, evidentiary, investigative or safety decisions.

Disclaimer

THE PROJECT, INCLUDING SOFTWARE, FIRMWARE, HARDWARE DESIGNS AND DOCUMENTATION, IS PROVIDED "AS IS" AND "AS AVAILABLE", WITHOUT WARRANTY OF ANY KIND, EXPRESS OR IMPLIED, INCLUDING WARRANTIES OF MERCHANTABILITY, FITNESS FOR A PARTICULAR PURPOSE, TITLE, NON-INFRINGEMENT, ACCURACY, DETECTION EFFICACY OR UNINTERRUPTED OPERATION. This supplements and does not limit the warranty disclaimer and liability limitation in sections 15 to 17 of the GNU Affero General Public License v3.0.

TO THE MAXIMUM EXTENT PERMITTED BY LAW, THE AUTHORS, DEVELOPERS, MAINTAINERS AND CONTRIBUTORS SHALL NOT BE LIABLE FOR ANY DIRECT, INDIRECT, INCIDENTAL, SPECIAL, EXEMPLARY, PUNITIVE OR CONSEQUENTIAL DAMAGES, including loss of data, profits, goodwill, equipment or business interruption, or damages arising from failure to detect, false detection, or regulatory enforcement action, ARISING FROM OR RELATED TO YOUR USE OF THE PROJECT, EVEN IF ADVISED OF THE POSSIBILITY. Where liability cannot be fully disclaimed, total aggregate liability shall not exceed the greater of the amount paid for the unit giving rise to the claim, or USD $0.

Assembly, sale or instruction by the maintainers creates no warranty, no certification, no fitness-for-purpose representation and no responsibility for how a unit is later configured, deployed or used. Once the unit is in your hands, operation and compliance are yours alone. Flashing the firmware, by web flasher, shell script or any other means, is acceptance of these terms.

Nothing here excludes liability that cannot lawfully be excluded, including for death or personal injury caused by negligence, for fraud, or non-excludable statutory consumer rights. Some jurisdictions do not allow the exclusion of implied warranties or the limitation of incidental or consequential damages, so parts of the above may not apply to you.

You alone are responsible for ensuring your build, deployment and operation comply with all applicable laws, regulations, licenses, permits, equipment authorizations, organizational policies and third-party rights. If you do not agree to these terms, do not build, flash, assemble, deploy or operate AntiHunter.

Full text: Legal Disclaimer in the project README. Firmware is licensed under the GNU AGPL v3.0. Hardware and documentation are licensed as stated in their own files.

## Appendix A · Pinout

XIAO ESP32-S3 on the DIGI NODE board. Pin assignments may change with board revisions. Verify against your revision.

Function | GPIO | Notes
Vibration sensor | 2 | SW-420 tamper detection, rising-edge interrupt, input pull-down
RTC SDA | 3 | DS3231 I²C data
RTC SCL | 6 | DS3231 I²C clock
GPS RX | 44 | NMEA in
GPS TX | 43 | Unused
SD CS | 1 | Chip select
SD SCK | 7 | SPI clock
SD MISO | 8 | SPI MISO
SD MOSI | 9 | SPI MOSI
Mesh RX | 4 | From the Meshtastic radio
Mesh TX | 5 | To the Meshtastic radio

Radio side: serial module in TEXTMSG mode at 115200 baud, pins 19 RX / 20 TX on Heltec V3, 10 RX / 9 TX on T114.

## Appendix B · Bill of materials

#### Core

- 1× AntiHunter DIGI PCB, 82 mm, 2-layer
- 1× Seeed XIAO ESP32-S3, 8 MB flash minimum, or XIAO ESP32-C5 for 2.4 and 5 GHz
- 1× Heltec Wi-Fi LoRa 32 V3.2, T114 also compatible
- 1× ATGM336H GPS module
- 1× DS3231 RTC module
- 1× SW-420 vibration sensor
- 1× micro SD reader module
- 1× SD card, 8 GB supplied on every tier but the Bare PCB. FAT32, 32 GB and larger not recommended
- 1× KSD9700 normally-open thermal switch, 40 °C

#### Connectors and fasteners

- 6× JST 2.54 2-pin terminals
- 3× JST power male cables for the switch, thermal switch and power board
- 10× M3 heat-set inserts
- 4× M2 heat-set inserts for the power board
- 2× M3 15 mm brass standoffs
- M3×4-6mm screws for the PCB and enclosure lids, M2×4-6mm for the power board
- 2× M2.5 screws, supplied with the fan
- 1× ¼"-20 tripod insert

#### Antenna and cabling

- 3× U.FL to SMA pigtail, 10 to 20 cm
- SMA bulkheads
- 1× 6 dBi 2.4 GHz antenna
- 1× 6 dBi LoRa antenna for your region
- 1× GPS antenna. Passive ceramic patch on the kit and populated PCB, active helix on the assembled unit

#### Power and thermal

- 1× 30 mm 5 V fan with JST lead
- 1× 3-pin mini on/off switch
- 1× waterproof Type-C female chassis jack, 2-pin 22 AWG leads, 14 mm panel nut, dust cap
- 1× Type-C 15 W 3 A 5 V UPS board, dual 18650
- 1× 2 A fast-blow fuse, recommended, not supplied
- 2× 18650 cells, protected flat-top, never supplied with any tier

#### Enclosure

- 3D-printed weatherproof enclosure. STLs, seals, brackets and solar mounts in hw/Prototype_STL_Files/

Part links and photographs: hw/Prototype_STL_Files/BOM-Links.md

## Appendix C · Defaults, addresses and files

Item | Default
Wi-Fi AP name | Antihunter | change it
Wi-Fi AP password | antihunt3r123 | change it
Wi-Fi AP hidden | off, SSID beacons | optional, see §8.1 before turning it on
Web UI | http://192.168.4.1 | Full firmware only
Erase key | not set | set it if using erase or factory reset
Meshtastic serial | TEXTMSG, 115200 | pre-configured on tiers 1 and 3, you set it on 2 and 4
LoRa region | UNSET, receive only | set it
Meshtastic channel | public default | replace with your own encrypted channel
Scan preset | Balanced
Wi-Fi channels | 1 to 11
Mesh dedup TTL | 300 s | 0 disables
Vibration alerts | enabled | rate-limited to one per 3 s
Vibrations required for tamper | 3 | range 2 to 5
Auto-erase | disabled
Heartbeat | disabled
Karma bait | off | the only transmitting detector
Attacker auto-triangulation | off
C2 frontend | http://localhost:5173, Docker 8080
C2 seeded admin | admin@example.com and admin | change at first login

#### Files on the SD card

Path | Contents
/last_results.txt | Most recent scan results as text. Written by both builds
/devicedb.jsonl | Device database. Full firmware only, browsed by the Data Explorer
/vibrations.jsonl | Structured vibration events
/pcap/wifi_*.pcap and /pcap/ble_*.pcap | Packet captures you started by hand. Never pruned automatically
/pcap/wifi_auto_*.pcap and /pcap/ble_auto_*.pcap | Captures started by a vibration trigger or a Sentinel attack response. Oldest are deleted to stay inside the budget and keep the card's free-space floor

## Appendix D · Glossary

BSSID | The MAC address of an access point.
OUI | The first three bytes of a MAC address, identifying the manufacturer. Watchlisting an OUI matches a whole vendor.
Probe request | A frame a device sends looking for networks it knows. Reveals remembered SSIDs.
Ghost SSID | A probed network with no matching AP responding nearby.
Evil twin | A rogue AP impersonating a legitimate network to capture clients.
Karma | An AP that answers every probe request, claiming to be whatever a client asks for.
Deauth | A management frame that disconnects a client. Used to force reconnections and capture handshakes.
PMKID | A value in the first EAPOL message that can be captured and cracked offline without a full handshake.
Remote ID | The broadcast identification a drone emits under ASTM F3411 and equivalent rules.
RSSI | Received signal strength, in dBm. Less negative is stronger.
NVS | Non-volatile storage on the ESP32 where settings persist across reboots.
SoftAP | The Wi-Fi access point the Full firmware hosts for its web UI.
U.FL / IPX | The miniature snap-on RF connector on each module.

## Appendix E · Quick reference

Print this page and keep it with the node.

### Never

- Power from anything but a regulated 5 V source
- Power the radio with no LoRa antenna fitted
- Connect both USB ports at once
- Press a U.FL connector at an angle
- Leave the default AP password or the public mesh channel in place

### Addresses

Web UI | http://192.168.4.1, AP Antihunter
Web flasher | lukeswitz.github.io/AntiHunter
Firmware, docs, issues | github.com/lukeswitz/AntiHunter
Command Center | github.com/TheRealSirHaXalot/AntiHunter-Command-Control-PRO
Meshtastic flasher | flasher.meshtastic.org

### Ten commands

@ALL STATUS                          who is alive
@ALL STOP                            stop everything
@AH01 CONFIG_NODEID:GATE1            name a node
@ALL CONFIG_TARGETS:AA:BB:CC|MyWiFi  set the watchlist
@ALL SCAN_START:2:600:1..11          watchlist scan, 10 min
@ALL DEVICE_SCAN_START:2:300         survey everything
@ALL BASELINE_START:900              learn the site
@ALL SENTINEL_ON                     attacker-tool detection
@ALL DRONE_START:0                   drone watch until stopped
@AH01 BATTERY_SAVER_START:10         idle, mesh stays up

### Setup order for a new node

1. Fit the antennas
2. Flash AntiHunter, Full to start with
3. Change the AP credentials
4. Set the radio region
5. Create your encrypted channel and disable the public one
6. Set the node ID and the clock
7. Confirm the SD card and GPS
8. Tune the vibration trimpot in place
9. Verify @NODEID STATUS answers over the mesh
10. Seal and deploy

AntiHunter DIGI NODE Operator's Guide · revision 1.0 · 14 August 2026 · GNU AGPL v3.0 · github.com/lukeswitz/AntiHunter

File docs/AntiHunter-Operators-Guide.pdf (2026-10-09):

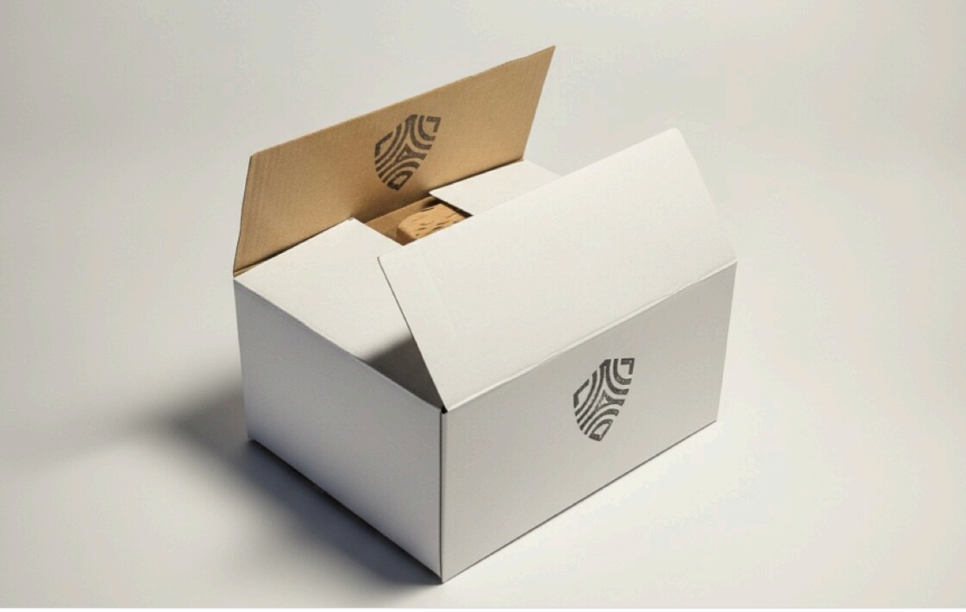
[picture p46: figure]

# ANTIHUNTER DIGI NODE

## Operator's Guide: from the box to the field

Covers all four tiers: Fully Assembled Unit · Complete Parts Kit · Populated PCB · Bare PCB

Guide revision 1.1 · 4 October 2026 · Firmware v1.0.4 · Written for the current Stable and Beta firmware channels github.com/lukeswitz/AntiHunter · Web flasher: lukeswitz.github.io/AntiHunter

# Hello, operator

Welcome to AntiHunter. This node is a self-contained Wi-Fi, Bluetooth and LoRa mesh sensor. It runs everything on the device: no cloud, no account, no server needed. It is fully open source. Read the firmware, write your own mesh commands, wire it into your own IDS. Make it yours.

This guide takes you from opening the box to a tuned node in the field, whichever tier you bought. Sections that only apply to one tier are marked. Everything else applies to every node.

READ BEFORE APPLYING POWER: THREE RULES
1. Regulated 5 V only. Power the PCB from USB, a bench supply set to 5 V, a proper DC-DC regulator, or the UPS board. Never connect 18650 cells, a battery pack, or a vehicle supply directly to the board. Unregulated input permanently damages the modules. Voltages under 4.5 V cause instability.
2. Never power the LoRa radio without its antenna. Transmitting into an open port can destroy the radio's PA. Fit the LoRa antenna, or the U.FL pigtail plus antenna, before the node is energised.
3. One USB cable at a time. The ESP32 and the Meshtastic radio share the PCB's power rails. With both USB ports plugged in, one board back-feeds the other. Plug in one board, do your work, unplug it, then plug in the other.

### What you are holding

Tier | What is in the box | What you still have to do
1 · Fully Assembled Unit | Built, soldered, tested and ready to deploy. 8 GB SD card fitted. Active GPS helix antenna. SMA antennas. Meshtastic flashed on the radio with the serial link configured. | Fit two 18650 cells, screw on the antennas (§2), flash AntiHunter (§5), set the radio region and channel (§7).
2 · Complete Parts Kit | Every part on the bill of materials, unassembled, as it comes from the supplier. Passive GPS antenna. Nothing is soldered and nothing is flashed. | Solder and assemble it (§3), flash Meshtastic on the radio (§7.1), then flash AntiHunter (§5) and configure.
3 · Populated PCB | A fully assembled PCB. Core modules soldered, bench-tested, 8 GB SD card fitted. Factory U.FL antennas. Meshtastic flashed on the radio with the serial link configured. | Attach the antennas (§2), supply power over USB or 18650s, build the housing if you want one, flash AntiHunter (§5), set the radio region and channel (§7).
4 · Bare PCB | One 82 mm board, unpopulated. | Source the BOM, solder the modules, flash Meshtastic on the radio, fit an SD card, then follow this guide from §3.

TIERS 1 AND 3: THE RADIO IS ALREADY DONE
On the Fully Assembled Unit and the Populated PCB, the Meshtastic radio ships flashed with the latest stable firmware and the serial link to the node already configured: TEXTMSG mode, 115200 baud, on the correct pins for the board. You do not need to redo that. You do still need to set your LoRa region and create your own encrypted channel. See §7.

On the Complete Parts Kit and the Bare PCB you flash the radio yourself first. §7.1 has the settings. The ESP32 ships empty on every tier, so you always flash AntiHunter yourself and know exactly what is on it.

### Contents

### 1 Unboxing and inventory

Tier checklists, tools you supply, power and thermal

### 2 Antennas

U.FL seating, SMA fitting, which port is which

### 3 Assembly

Tiers 2 and 4: where the assembly manual takes over

### 4 First power-on

Boot signs, SD card, GPS, real-time clock

### 5 Flashing the firmware

Full vs Headless, three flashing methods

### 6 Staying up to date

Release channels, GitHub notifications, rollback

### 7 Mesh radio setup

Region, encrypted channel, quiet-ops settings

### 8 First configuration

Credentials, node ID, scan presets, privacy

### 9 Using the node

Every detector, what it finds, how to run it, scheduling

### 10 Vibration sensor and tamper

How it works, tuning the trimpot, auto-erase

### 11 Mesh command reference

Everything you can send from a phone

### 12 Command Center (C2)

Quick install, first login, connecting a radio

### 13 Deployment

Siting, sealing, mounting, power budget

### 14 Maintenance and troubleshooting

Symptom tables, factory reset, getting help

### 15 Legal and safety

Authorization, radio law, privacy, disclaimer
A–E Appendices
Pinout, BOM, defaults, glossary, quick-reference card

# 1 Unboxing and inventory

Open the box on a clean, static-safe surface. Check what arrived against your tier before you power anything.

### 1.1 Tier checklists

TIER 1: FULLY ASSEMBLED UNIT
☐ Node built, soldered and bench-tested ☐ 8 GB SD card fitted
☐ Active GPS helix antenna
☐ 2.4 GHz Wi-Fi/BLE SMA antenna
☐ LoRa SMA antenna for your region
☐ Meshtastic flashed on the radio, serial link configured

TIER 2: COMPLETE PARTS KIT
Every part needed to build a finished node. Nothing is soldered and nothing is flashed. The two 18650 cells are the only thing you supply.
☐ Bare 82 mm PCB
☐ XIAO ESP32-S3
☐ Heltec V3.2 LoRa radio (or T114) ☐ ATGM336H GPS module
☐ DS3231 RTC module
☐ SW-420 vibration sensor
☐ Micro SD reader module
☐ 8 GB SD card
☐ Pin headers for every module
☐ 3D-printed enclosure: main PCB housing, battery housing, front cover, back cover ☐ TPU seals for the housing, GPS and USB-C port
☐ 3× U.FL-to-SMA pigtail cables

☐ SMA bulkheads
☐ 2.4 GHz Wi-Fi/BLE antenna, 6 dBi
☐ LoRa antenna for your region
☐ Passive ceramic GPS antenna, the one supplied with the GPS module ☐ 30 mm 5 V fan with JST lead
☐ KSD9700 normally-open thermal switch, 40 °C
☐ 3-pin mini on/off switch with rubber cover
☐ Waterproof Type-C female chassis jack, 2-pin 22 AWG leads, panel nut and dust cap ☐ Type-C 15 W 3 A 5 V UPS charger board, dual 18650
☐ 6× JST 2.54 2-pin terminals
☐ 3× JST power male cables for the switch, thermal switch and power board
☐ M3 heat-set inserts, plus 4× M2 for the power board
☐ M3×4-6mm screws for the PCB and enclosure lids, M2×4-6mm for the power board ☐ 2× M2.5 screws, supplied with the fan
☐ 2× 15 mm brass standoffs
☐ ¼"-20 tripod insert

TIER 3: POPULATED PCB
A fully assembled PCB, bench-tested, on its factory antennas. No enclosure and no power source.

☐ PCB with XIAO ESP32-S3, Heltec V3.2 LoRa radio (or T114), ATGM336H GPS, DS3231 RTC, SW-420 vibration sensor and SD reader soldered
☐ 8 GB SD card fitted
☐ Factory U.FL antennas: flat 2.4 GHz film, coiled LoRa whip, ceramic GPS patch
☐ Meshtastic flashed on the radio, serial link configured

TIER 4: BARE PCB
☐ One 82 mm AntiHunter DIGI NODE PCB, unpopulated

Everything else comes from the bill of materials in Appendix B, including the Meshtastic radio, which you flash yourself.

### 1.2 What you supply

Power. Tiers 1 and 2 take two 18650 cells in the UPS board. Tier 3 runs from USB or from your own regulated 5 V supply. Cells are never supplied on any tier.
18650 cells. Brand new, same brand, same capacity, never mixed old with new. Sourcing, charging, storage and disposal are your responsibility.
A micro SD card, only on the Bare PCB tier. Every other tier ships with an 8 GB card. A replacement must be FAT32, and 32 GB or larger is not recommended.
A USB-C data cable. Charge-only cables will not flash the board.
A computer running Chrome or Edge for the web flasher, or a terminal for the CLI installer.
Soldering tools on tiers 2 and 4: temperature-controlled iron, fine solder, flux, tweezers, small Phillips and hex drivers, heat-resistant surface.

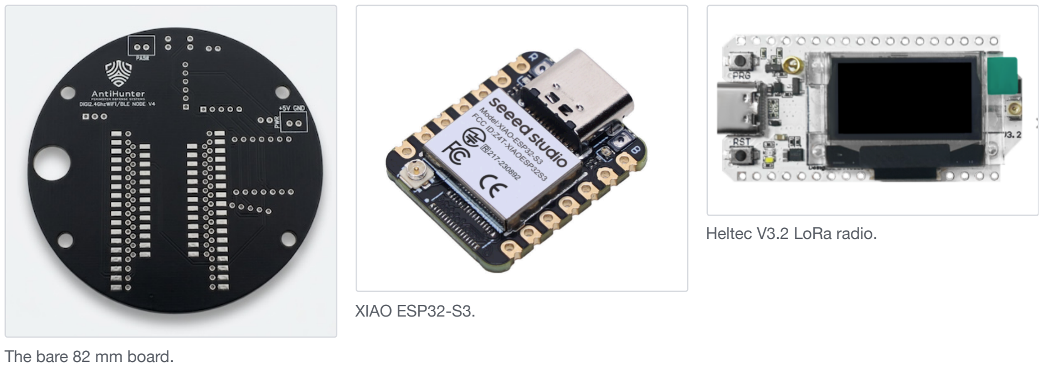
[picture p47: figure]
The bare 82 mm board.; XIAO ESP32-S3.; Heltec V3.2 LoRa radio.
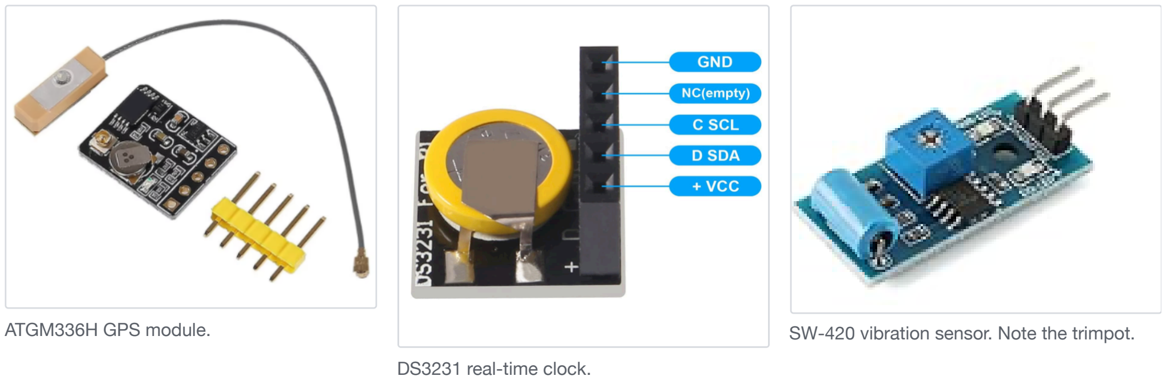
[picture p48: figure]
ATGM336H GPS module.; DS3231 real-time clock.

SW-420 vibration sensor. Note the trimpot.

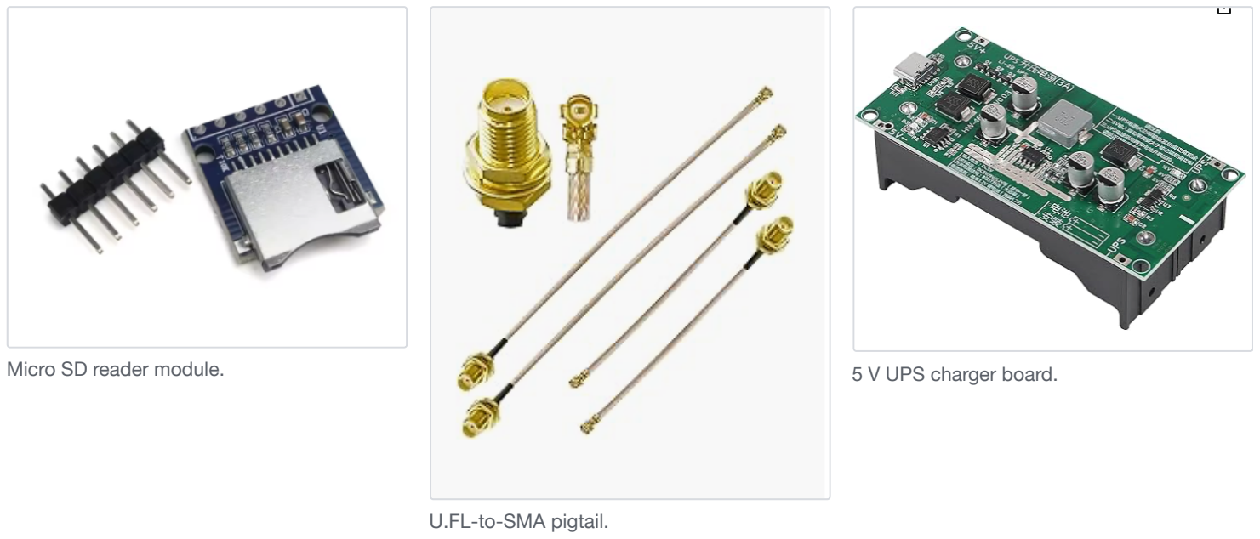
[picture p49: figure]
Micro SD reader module.; U.FL-to-SMA pigtail.; 5 V UPS charger board.

### 1.3 Power

The node draws roughly 160 mA idle and 600 mA while actively scanning. Inside the enclosure the UPS board provides the regulated 5 V and the cells are never connected to the PCB directly. Outside the enclosure, use a USB-C adapter, a bench supply set to 5.0 V on the 5 V input, or a proper DC-DC regulator.

POWER RULES
Do not connect batteries directly. Do not exceed 5 V. Do not use unregulated sources. A fuse in the battery line is recommended, a 2 A fast-blow in series with the switch wiring, but one is not supplied with any tier.

### 1.4 Thermal

The ESP32 runs warm under load and the GPS module gets noticeably hot while it searches for satellites. Both are normal. Neither the fan nor the thermal switch is required for the node to work.

The 30 mm fan plugs into the FAN JST output.
The sticker side is not always the exhaust side. Run the fan for a second and feel which way it blows before you screw it down. The Fully Assembled Unit ships with the fan set to exhaust.
The KSD9700 normally-open thermal switch, 40 °C, wires to the THERMO JST and switches the fan on when the enclosure heats up.
To run the fan continuously instead, jump the THERMO input or supply 5 V straight to the fan port.

# 2 Antennas

More nodes are damaged fitting antennas than in any other step. The U.FL connectors are small, fragile and unforgiving of a crooked press. Take your time here.

### 2.1 Which antenna goes where

Antenna | U.FL set (tiers 2 and 3) | SMA set (tiers 1 and 2) | Connects to
2.4 GHz Wi- Fi / BLE | Flat black film antenna, printed 2.4G | Shorter of the two rubber ducks, 6 dBi | The U.FL socket on the XIAO ESP32- S3, or its SMA bulkhead
LoRa (region specific) | Coiled black whip | Longer duck, marked 868 MHz (EU), 915 MHz (US) or 923 MHz (Asia) | The U.FL socket on the Heltec / T114 radio, or its SMA bulkhead
GPS | Passive ceramic patch, supplied with the GPS module
Active helix, Fully Assembled Unit only

The U.FL socket on the GPS module, or the SMA bulkhead in the battery housing

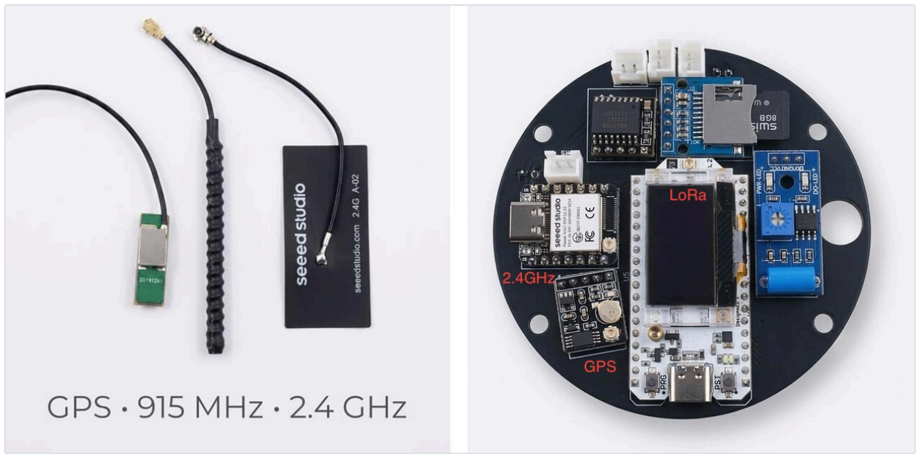
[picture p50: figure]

The factory U.FL antenna set beside the sockets each one belongs to: ceramic GPS patch, coiled LoRa whip (915 MHz shown, yours matches your region), flat 2.4 GHz film antenna. The GPS module carries the GPS socket, the Heltec carries LoRa, the XIAO carries 2.4 GHz Wi-Fi and BLE.

PICK AN ORIENTATION AND KEEP IT
On an enclosed build, decide which bulkhead carries LoRa and which carries Wi-Fi, then wire every node you build the same way. It does not matter which you choose. It matters that a spare antenna always fits the port you expect in the field.

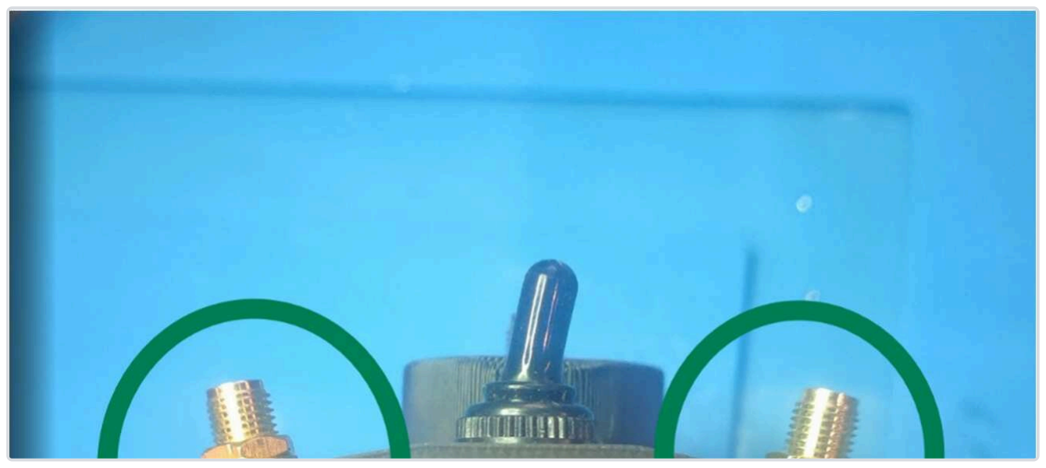
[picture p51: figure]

The two SMA bulkheads with the power switch centered between them.

MATCH YOUR ANTENNAS ACROSS NODES
When you build more than one node, use the same antenna type and the same cable length on all of them. Triangulation and any other multi-node distance estimate assumes the nodes hear the world the same way. Mismatched antennas skew the result.

### 2.2 Fitting a U.FL / IPX pigtail (tiers 2 and 3)

The pigtail's tiny snap connector mates with the socket on each module. It seats with an audible, tactile click.

1. Identify each pigtail and the socket it belongs to. Route the cable before you connect it, not after.
2. Hold the connector parallel to the board and align its rim concentrically over the socket. Look at it from the side: the two rims must be perfectly stacked.
3. Press straight down with a fingertip or the flat of a plastic tool until it clicks.
4. Tug the cable gently to confirm it is home. If it lifts off, it never seated.

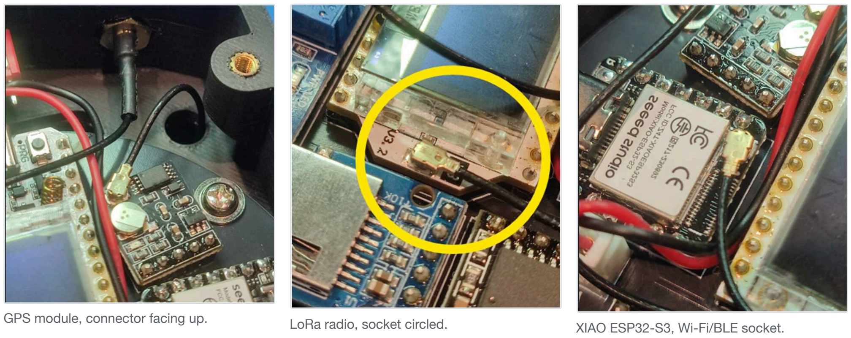
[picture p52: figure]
GPS module, connector facing up.; LoRa radio, socket circled.; XIAO ESP32-S3, Wi-Fi/BLE socket.

U.FL: DO NOT
Do not press at an angle.
Do not force a connector that will not click.
Do not pull the cable to remove one. Lift the connector body straight up, or use a U.FL removal tool. Do not reseat one repeatedly. The contacts wear out.
Misalignment damage is permanent. A crushed socket means a new module.

### 2.3 Fitting SMA antennas (tiers 1 and 2)

1. Check the bulkhead is tight in the shell. The nut and washer go on the outside, and the bulkhead should not rotate when you turn an antenna onto it.
2. Start the thread by hand, straight on. Never cross-thread it.
3. Turn until finger-tight, then no more than an eighth of a turn. Do not use pliers.
4. Fold the duck upright once fitted. Antennas work best vertical.

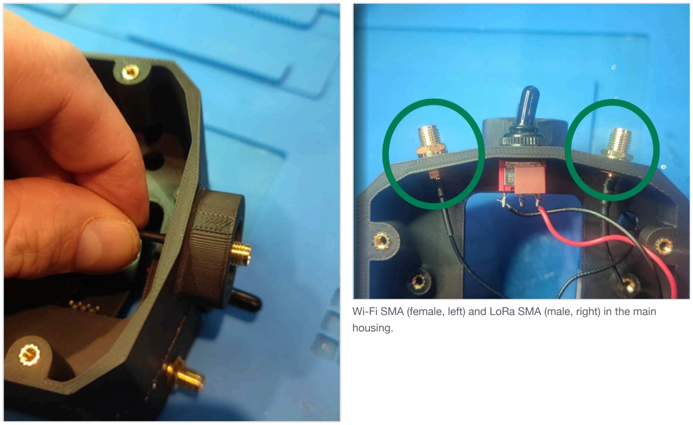
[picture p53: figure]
housing.

GPS SMA female fitted into the battery housing, secured from outside with washer and nut.

Wi-Fi SMA (female, left) and LoRa SMA (male, right) in the main

WET CONDITIONS
A smear of silicone grease on the SMA threads and on the TPU seals keeps water out and makes the antennas easier to remove later.

### 3 Assembly (tiers 2 and 4)

Tiers 1 and 3 arrive soldered. Skip to §4.

BUILD FROM THE ASSEMBLY MANUAL, NOT FROM HERE
The Complete Parts Kit and the Bare PCB are built with the illustrated assembly manual, which covers soldering, connectors, the enclosure, the SD card and the power wiring in photographed steps. This guide does not repeat it.

hw/Prototype_STL_Files/Antihunter-DIGINODE-AssemblyManual.pdf github.com/lukeswitz/AntiHunter, in the hw folder

Work through it end to end, then come back here at §4 to power the node up for the first time.

# 4 First power-on

### 4.1 What a healthy boot looks like

Connect a USB-C cable to the ESP32 only, remembering one USB at a time, and open a serial monitor at 115200 baud. On boot the firmware prints its banner and version, then the results of its hardware checks: SD card, GPS, RTC, vibration sensor. Any module that failed to initialize says so by name.

If you flashed the Full firmware, a Wi-Fi access point named Antihunter also appears within a few seconds.

### 4.2 Confirming the hardware

Every subsystem reports into the diagnostics text, visible in the web UI's System tab, over serial, and in the reply to a mesh STATUS command. Check for:

SD card. Mounted and writable. If it is missing, the node still scans but nothing is logged.
GPS. Reports a fix once it has one. Give it a clear view of the sky; indoors it may never lock. Detections carry coordinates only when the fix is valid.
RTC. Supplies the timestamps on every log line and export.
Vibration sensor. Shows Standby, or Active with the time of the last movement.

### 4.3 The clock

Nothing to do. The DS3231 is set when you flash the firmware, and GPS disciplines it again on every fix. Its coin cell keeps it running across power cycles. The clock keeps UTC. Logs, capture file names, results and heartbeats show local time, with daylight saving, once a GPS fix places the node in a known zone: Hawaii, Alaska, Arizona, Saskatchewan, US/Canada Pacific, Mountain, Central and Eastern, UK/Ireland, Central Europe, Eastern Europe. Elsewhere, and until the first fix after boot, they show UTC.

ORDER OF OPERATIONS
Flash the firmware first (§5), then set the clock and configure the radio. A fresh flash with "Erase Device" ticked clears saved settings, so do it before you spend time configuring.

# 5 Flashing the firmware

The ESP32 ships empty on every tier. You choose the build and put it on yourself.

### 5.1 Full or Headless?

Same firmware, same detectors, same mesh commands, same scan engine. The difference is whether the node hosts a Wi-Fi access point.

| Full | Headless
Control | Web UI and HTTP API over its own AP, plus serial and mesh | Serial and mesh only
RF footprint | The AP beacons continuously, so the node is discoverable as a Wi-Fi network | Never beacons
Results | Rendered as cards in the web UI's Results tab, and served
plain over the API like every other endpoint. Written to the SD card as well

Written to
/last_results.txt on the
SD card
Logging | Identical. Both builds write results, the probe database, vibration events, sentinel incidents and
scan logs to the SD card
Device database | /devicedb.jsonl, which is what the Data Explorer browses | Not written
Best for | Bench work, first setup, anything where you want the UI | Covert and long-term field
deployments

Start with Full while you learn the device. Reflash to Headless before a quiet deployment. It takes two minutes and your settings live on the SD card.

### 5.2 Release channels

Channel | Source | Use it when
Stable | main branch | Default. Field deployments.
Beta | beta branch | New features first, with the risk that implies.

Experimental ESP32-C5 builds (2.4 + 5 GHz) and
RadarNode

Only on C5 hardware. The flasher asks you to acknowledge these are test builds.

### 5.3 Method A: web flasher (recommended)

1. Open lukeswitz.github.io/AntiHunter in Chrome or Edge on a desktop. Other browsers cannot talk to serial ports.
2. Choose Full or Headless, and a release channel.
3. Plug the ESP32 in with a data cable, nothing else connected to the board.
4. Click Connect & Flash and pick the port.
5. Optionally set your device parameters before flashing. The Sentinel & Detectors panel configures the whole detection engine: start-on-boot, radio mode, every detector toggle, mesh flags, thresholds. Anything left on Default keeps the firmware's own setting.

ERASE DEVICE
Tick it when upgrading from firmware older than v0.9.2, or when you want to clear saved settings. Otherwise leave it off. Settings persist in NVS and are mirrored to the SD card, and self-heal if they are corrupted.

### 5.4 Method B: command line

The script asks for a release channel, then Full or Headless. Flags: -c configure device parameters during the flash, -e erase flash first, -l list available firmware.

### 5.5 Method C: build from source

git clone https://github.com/lukeswitz/AntiHunter.git
cd AntiHunter
pio device list | # find the port
pio run -e AntiHunter-full -t upload | # web UI build
pio run -e AntiHunter-headless -t upload | # serial + mesh build
pio device monitor -e AntiHunter-full | # watch it boot
pio run -e AntiHunter-full -t erase -t upload # clean flash

Environments: AntiHunter-full and AntiHunter-headless for the ESP32-S3; AntiHunter-c5-full and AntiHunter-c5-headless for the ESP32-C5 on the feat/c5 branch; RadarNode-c5 for the 24 GHz radar node.

### 5.6 Verifying the flash

The serial monitor prints the banner and firmware version at boot.
Full build: the Antihunter access point appears.
Connect to it, password antihunt3r123, and open http://192.168.4.1. Note http, not https.

DO THIS BEFORE ANYTHING ELSE
The default AP name and password are published in the documentation. Until you change them in RF Settings, treat the node as an open door. §8.1.

### 5.7 Board variants

The XIAO ESP32-C5 is a drop-in replacement for the S3 on the same board, with the same pads and peripherals, and it adds 5 GHz scanning. Those builds are in testing and live under the flasher's Experimental channel. The RadarNode variant pairs a 24 GHz radar with the same mesh: it detects a moving target, then sweeps Wi-Fi and BLE to record which devices were present at that moment.

# 6 Staying up to date

### 6.1 Where updates come from

Firmware is built and published by CI when a release is tagged. The web flasher always serves the current build for the channel you pick, so re-running the flasher is the update. Nothing on the node phones home or updates itself.

### 6.2 Getting notified

1. Open github.com/lukeswitz/AntiHunter and sign in.

2. Click Watch → Custom → tick Releases → Apply. You now get an email or notification for every release, without the noise of every commit.
3. Read the release notes before flashing: docs/release-notes/notes-stable.md and notes-beta.md in the repository, and on each release page.

Discussions and issues on the same repository are where behavior changes, hardware alternatives and field reports get talked through.

### 6.3 Updating a deployed node

1. Bring it in, or reach it over USB in place.
2. Re-run the web flasher or the CLI script on the same channel. Leave Erase Device unticked to keep your settings.
3. Reconnect and check the version, then confirm your targets, node ID and detector settings survived.

Settings live in NVS and are mirrored to the SD card, so they normally survive an update. Watchlists, results and databases live on the SD card and are untouched by flashing.

### 6.4 Rolling back

Flash the other channel, or check out an earlier tag and build from source with PlatformIO. If a downgrade behaves strangely, erase and flash clean, then reconfigure.

FLEET DISCIPLINE
Run one firmware version across a mesh. Mixed versions can differ in the mesh message formats they emit and what your Command Center is able to parse.

# 7 Mesh radio setup

The LoRa mesh gives you long-range control and alerting with no infrastructure. It is entirely optional, since a single node works standalone, but it is what turns several nodes into a system.

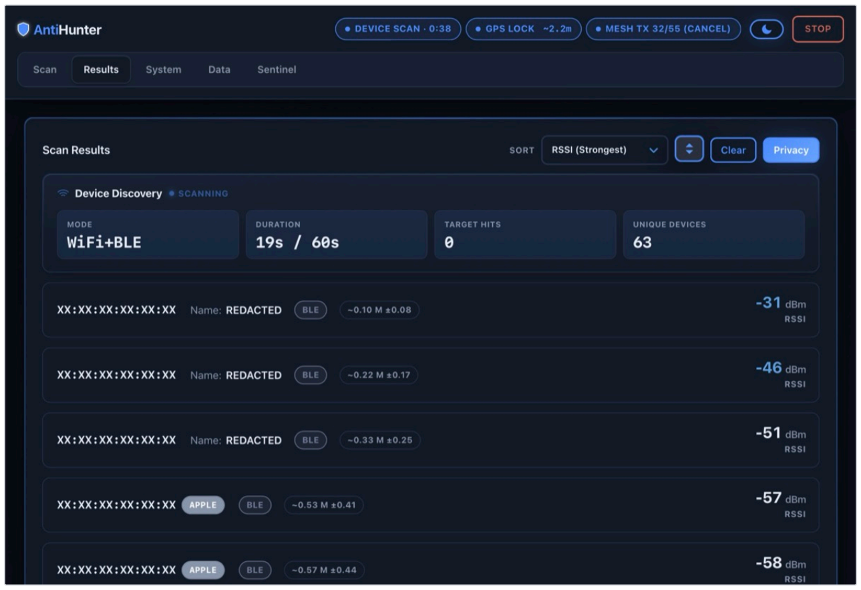
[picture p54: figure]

A device scan sending its results over the mesh. The header badge tracks the transmit queue draining at the LoRa airtime cap, 32 of 55 rows sent, and Privacy Mode has blanked the addresses.

### 7.1 Flashing and linking the radio

Tiers 1 and 3: already done. On the Fully Assembled Unit and the Populated PCB the radio arrives on the latest stable Meshtastic with the serial link to the node set: TEXTMSG mode, 115200 baud, on the right pins for the board (19 RX / 20 TX on Heltec V3, 10 RX / 9 TX on T114). The screen is set to blank after 1 s and the status LED is off. Verify it if you like; do not redo it.

Tiers 2 and 4: you flash it. The Complete Parts Kit and the Bare PCB include no flashed firmware at all. Connect the Heltec V3.2 (preferred) or T114 on its own USB and flash the latest stable Meshtastic from flasher.meshtastic.org. Then set the serial module, either in the Meshtastic app or web client, or with the script in §7.2:

Setting | Value
Serial module | Enabled
Mode | TEXTMSG
Baud | 115200
Pins, Heltec V3 | 19 RX / 20 TX
Pins, T114 | 10 RX / 9 TX

Without this the node and the radio cannot talk, and no mesh command will ever reach the node.

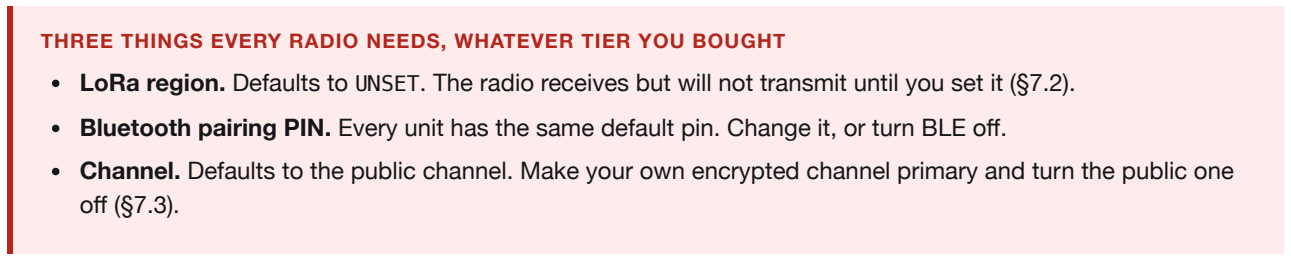
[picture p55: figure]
off (§7.3).

THREE THINGS EVERY RADIO NEEDS, WHATEVER TIER YOU BOUGHT
LoRa region. Defaults to UNSET. The radio receives but will not transmit until you set it (§7.2).
Bluetooth pairing PIN. Every unit has the same default pin. Change it, or turn BLE off.
Channel. Defaults to the public channel. Make your own encrypted channel primary and turn the public one

### 7.2 What you must set: region

The LoRa region is not set at the factory, and an UNSET region makes the radio receive-only: it hears the mesh but never transmits. Set the region for the country you are in. It determines the frequency band and the legal power and duty-cycle limits.

Plug the radio in on its own USB, not the ESP32, and run:

With no arguments it prints the current settings and opens an interactive menu. Non-interactive equivalent:

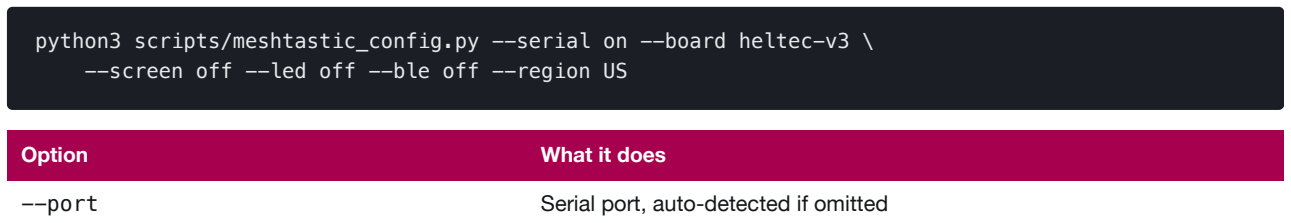
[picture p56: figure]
Option; What it does; --port; Serial port, auto-detected if omitted

python3 scripts/meshtastic_config.py --serial on --board heltec-v3 \
--screen off --led off --ble off --region US
--board heltec-v3 | t114 | Sets the serial-module pins for your board
--region | LoRa region, e.g. US. UNSET means receive only
--serial on | off | The node link: TEXTMSG at 115200 on the board's pins
--screen on | off | SECS | off blanks after 1 s, or give a timeout in seconds
--led on | off | Status LED heartbeat
--ble on | off | Bluetooth radio
--pin NNNNNN | none | random | BLE pairing: fixed 6-digit PIN, none, or random

The same settings can be applied from the Meshtastic phone app or web client if you prefer.

### 7.3 Your own encrypted channel

Meshtastic defaults to a public channel whose key is published. Anything you send on it, commands, detections and coordinates alike, is readable by anyone in radio range running stock firmware. Before you deploy:

1. In the Meshtastic app, create a new channel with a generated key and give it a name of your own.
2. Make it the primary channel.
3. Turn the public default channel off.
4. Share the channel to your other nodes and to your phone by QR code or channel URL. Every node in your mesh must carry the same channel.

THE FACTORY PRESET IS NOT PRIVATE
A node left on the default channel broadcasts its detections, its position and its command traffic to anyone listening. Changing the channel is the single most important mesh setting you will touch.

### 7.4 Quiet-ops settings

Screen off and LED off removes the visual signature and saves power. Physically removing the Heltec screen saves more.
BLE off on the radio removes its Bluetooth signature. Set a pairing PIN first if you intend to turn it back on later. Headless firmware on the node gives no Wi-Fi AP at all.

### 7.5 Addressing and node IDs

Node IDs are 2 to 5 alphanumeric characters, A-Z and 0-9, no spaces. Give every node a distinct one.
@ALL COMMAND broadcasts to every node. @AH01 COMMAND targets one.
Outbound messages are rate-limited to protect airtime: roughly 167 bytes per second sustained, with device rows packed into frames of up to 230 bytes.

### 7.6 Reaching the mesh from a phone, TAK or MQTT

Commands and detections are ordinary Meshtastic text messages, so anything that talks to the mesh talks to your nodes:

Phone. Pair the radio to the Meshtastic app over Bluetooth or Wi-Fi and send @node COMMAND messages from anywhere in mesh range. No AP, no server.
TAK / ATAK. The Meshtastic ATAK plugin and TAK server integration bridge the whole mesh, node traffic included. MQTT. A Meshtastic MQTT gateway node forwards mesh traffic to a broker for logging, Home Assistant or Node-RED.

These are Meshtastic features. Nothing AntiHunter-specific is needed on the receiving end.

# 8 First configuration

Ten minutes on the bench before the node ever leaves the building.

### 8.1 Change the credentials

AP SSID and password. The defaults Antihunter and antihunt3r123 are published. Change both under RF Settings.
Hidden network. Off by default. Turn it on under RF Settings and the node stops beaconing its SSID, so the AP does not appear in a scan of the area. It is not access control. A hidden SSID forces the client to send directed probe requests carrying the network name, so the phone or laptop you connect with advertises that name everywhere it goes afterwards. The WPA2/WPA3 passphrase is still what keeps people out. The node reboots on save and you type the SSID by hand to reconnect.
Erase key. Authorizes every wipe, abort, auto-erase change and factory reset. 8 to 64 characters, no :. Erase commands are refused (ERASE_ACK:SET_KEY_FIRST) until you set one: in the web UI, in the flasher (erasePSK), or with @AH01 CONFIG_ERASE_PSK:<new>:<current>. Full: until a key is set, <current> is the AP password, once it is changed from the default. Headless: set it in the flasher. Record it; the node never prints it.
Meshtastic BLE pairing PIN. Set a fixed PIN or turn BLE off entirely.

### 8.2 Identity

Node ID. Set it in the web UI or with @AH01 CONFIG_NODEID:AH02. It prefixes every mesh message the node sends, so make it meaningful.
Clock. See §4.3. Timestamps are local time once GPS fixes the zone, UTC before that.

### 8.3 Scan presets

Presets set the whole timing profile in one click. Start on Balanced.

Preset | Wi-Fi chan time | Wi-Fi scan int | BLE scan int | BLE scan dur | RSSI | Use case
Relaxed | 300 ms | 5000 ms | 6000 ms | 3000 ms | −80 dBm | Low power
Balanced | 160 ms | 3000 ms | 4000 ms | 2000 ms | −95 dBm | General use (default)
Aggressive | 110 ms | 1500 ms | 2000 ms | 1000 ms | −100 dBm | Fast detection, high coverage
Custom | User-defined | | | | | Fine-tuned

What each parameter does
Wi-Fi channel time, 50 to 300 ms. Dwell per channel. It must clear the ~100 ms beacon interval to catch every AP on a channel. Shorter covers the band faster but risks missing beacons.
Wi-Fi scan interval, 1000 to 10000 ms. How often the all-channel AP discovery scan runs. Between scans the node captures frames passively while hopping.
BLE scan interval, 1000 to 10000 ms. Time between BLE cycles.
BLE scan duration, 1000 to 5000 ms. Active BLE scanning per cycle.
RSSI threshold, −100 to −10 dBm. Global signal filter. Triangulation ignores it. Wi-Fi channels. Comma-separated, 1,6,11, or a range, 1..14. Default is 1 to 11.

ONE RADIO, TWO JOBS
Wi-Fi and BLE share a single 2.4 GHz radio and the scan loop is single-threaded. A BLE scan holds the radio for its full duration, and Wi-Fi capture is off-air for that time. BLE scan duration is literally the fraction of each cycle Wi-Fi is dark. The presets split it evenly by setting BLE duration to half the BLE interval.

### 8.4 Field controls worth knowing now

Privacy Mode. One click blanks MACs, SSIDs and GPS in the web UI for screenshots and demos. Exports and SD data are not redacted. Scrub those separately.
Allowlist. A global list of devices to ignore across every scan mode. Put your own kit on it.
Battery Saver. Stops Wi-Fi and BLE scanning, drops the CPU to 80 MHz and sends a heartbeat (temperature, GPS) every interval. Mesh stays up. Start it with @AH01 BATTERY_SAVER_START:10.
Accent Colors. In the System tab. Sets the color of the destructive controls — STOP, the wipe buttons, Clear, error toasts and danger badges — of the Sentinel banners and of the movement hit color. The choice is held in the browser, so a second phone or laptop keeps its own, and the node is not written to.
Fleet (System tab, full). Lists the nodes and mesh radios heard on your channel. Ping Nodes sends @ALL STATUS so every node answers; Clear empties the list.
Mesh dedup TTL. Suppresses re-broadcasting a MAC already sent within the window, default 300 s, max 3600. Saves airtime on repeated scans of the same environment. Never applied to alerts, drone events or triangulation.

### 8.5 Where settings live

Configuration is written to NVS on the ESP32 and mirrored to the SD card, so it survives reboots and normal reflashes, and self-heals if a copy is corrupted. Ticking Erase Device at flash time wipes NVS deliberately.

# 9 Using the node

Every capability runs on the node itself and reports to the web UI, the mesh and the Command Center alike. One scan mode runs at a time.

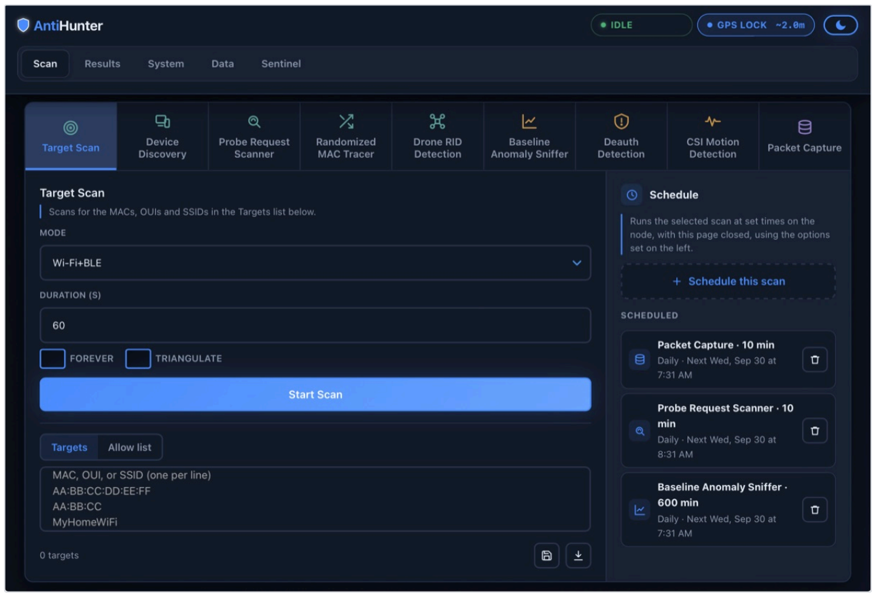
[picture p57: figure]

The Scan tab on the Full firmware: pick a scan in the top row, set its options on the left, schedule it on the right. Every scan also runs from a mesh command.

### 9.1 Target Scan

A watchlist scan. Load MAC addresses, OUI prefixes, the first three bytes of a MAC so a whole vendor, or SSIDs, and get an instant mesh alert when one is seen.

@ALL SCAN_START:2:300:1..11 # mode 0=Wi-Fi 1=BLE 2=both : seconds : channels

Alert: NODE: Target: MAC RSSI:dBm Type:WiFi|BLE [Name:name] [GPS=lat,lon] [V=vendor]. V= is the first word of the vendor name, sent when the MAC is not randomized.

In the web UI a target card shows Getting closer or Moving away when its signal has clearly risen or fallen over recent sightings. Nothing shows while the signal holds steady, or before the target has been seen four times.

### 9.2 Device Scanner

Captures everything nearby, Wi-Fi and BLE, with RSSI, channel and names. This is your baseline survey tool. Run it first at any new site to see what normal looks like.

@ALL DEVICE_SCAN_START:2:300:+PROBE # +PROBE also fills the probe database

What a BLE device is (full firmware). Device, Target and Baseline results show a badge naming what the device advertises: an Apple service (AirDrop, Handoff, AirPods, Find My, iPhone activity state), or a class and vendor read from its Bluetooth service or company ID, for example Wearable-Garmin, Tag-Tile, Vehicle-Tesla, Drone-RemoteID. The text results carry it as C=. Wi-Fi devices with a fixed MAC show their vendor from the MAC prefix instead.

### 9.3 Probe Request Scanner

Passive sniffing of the probe requests devices emit while looking for networks they know. It reveals the SSIDs a device is searching for, which is often more identifying than the device itself.

@ALL PROBE_START:2:300:+ALL # +ALL broadcasts every probe, not just watchlist hits

Hits: NODE: PROBE_HIT MAC [Randomized|Vendor] RSSI=dBm CH=N [SSID="net" [GHOST]]

Ghost SSID detection flags a probed SSID with no matching AP responding nearby: a network the device remembers but that is not here.

### 9.4 Baseline Anomaly Detection

Learn, then alert. The node observes a site for a set period and records what belongs there. Afterwards it reports what is new, what has gone, and what has changed signal.

@ALL BASELINE_START:300 | # minimum 60s; add :FOREVER to run indefinitely

Watch for changes from now. While a baseline runs, press the button (full firmware) or send @ALL BASELINE_WATCH. The node replies BASELINE_ACK:WATCHING, or BASELINE_ACK:NOT_RUNNING if no baseline is running. When the baseline ends, it reports what is new here, what is gone, and what moved closer or away since that moment. Full firmware shows this in a Since section in Results. Headless prints the device list to serial and sends BASELINE_WATCH: New=<n> Gone=<n> Moved=<n> Both=<n> over mesh. Use it when you leave a site and want to see what changed

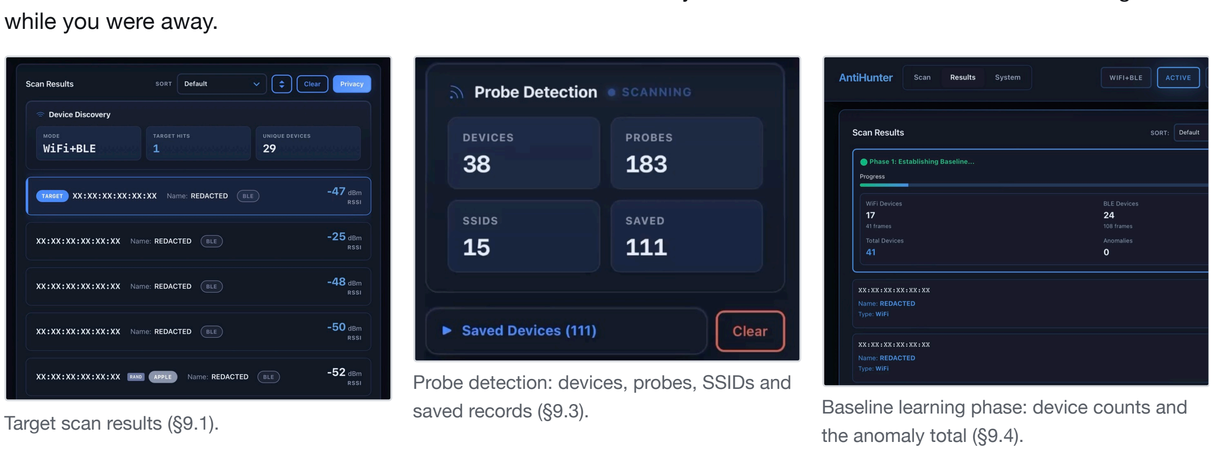
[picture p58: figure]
while you were away.; Target scan results (§9.1).; the anomaly total (§9.4).

Probe detection: devices, probes, SSIDs and
saved records (§9.3). | Baseline learning phase: device counts and

### 9.5 MAC Randomization Correlation

Modern phones rotate their MAC address to defeat tracking. This mode links rotating MACs back to one persistent identity using behavioral signatures, and reports the identity rather than the address.

@ALL RANDOMIZATION_START:2:300

Emits IDENTITY: messages. Treat the output as an investigative lead, not proof. This is an experimental mode.

### 9.6 Deauth Attack Detection

Real-time detection of deauthentication and disassociation frames, with the source tracked.

@ALL DEAUTH_START:300

Alert: NODE: ATTACK: DEAUTH|DISASSOC [BROADCAST|TARGETED] SRC:MAC DST:MAC RSSI:dBm CH:N R:reason. The IEEE reason code is reported as context only: codes 1, 2, 6 and 7 all occur in normal traffic, so the firmware does not use the code to decide whether a frame is an attack.

### 9.7 Sentinel counter-intelligence

Passive detection of attacker tooling, not just attacks: deauth, beacon, auth and association floods, SAE denial of service, karma and evil-twin access points, probe floods, and handshake or PMKID capture attempts. Where a frame carries a recognizable template, Sentinel names the tool behind it.

@ALL SENTINEL_ON
@ALL SENTINEL_MODE:scan | # hop the configured channels
@ALL SENTINEL_BOOT:1 | # start automatically on boot
@ALL GROUP:dos:on | # enable a detector group
@AH01 SENTINEL_STATUS
@AH01 INCIDENTS:50 | # dump the incident log to serial
Group | Detectors
dos | eviltwin, sae, assoc_sleep
rogue | eviltwin, owe, karma
recon | pmkid, probe_flood, hshk
physical | frag, tsf, jam
mesh | mesh_guard
all | every member above

Deauth, beacon and auth detection are always on and have no toggle. SENTINEL_MODE:defend pins one channel. On Headless there is no AP to pin to, so use scan. Sentinel is Wi-Fi only. BLE and drone detection are separate modes.

KARMA BAIT
Karma bait is the only Sentinel detector that transmits: a probe request every 8 seconds to bait a karma AP into responding. It is off by default. Enable it deliberately with GROUP:rogue:on and only where transmitting is appropriate.

(beta)

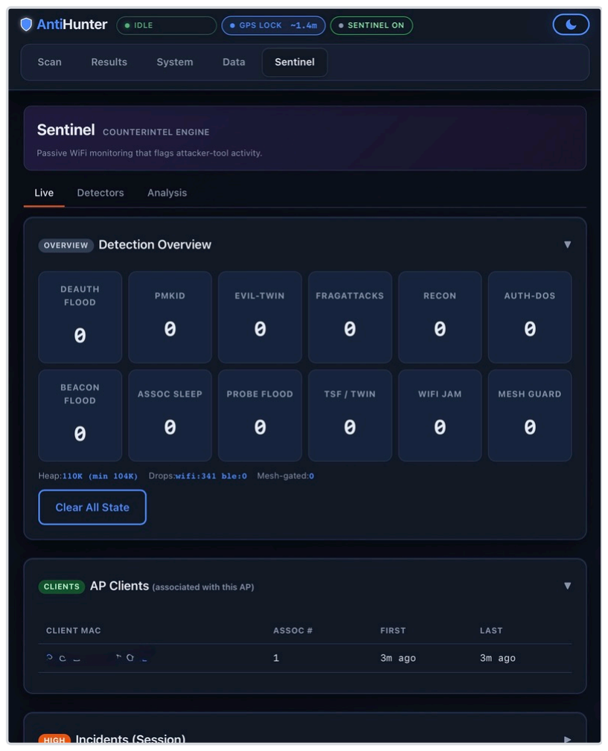
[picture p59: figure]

The Sentinel tab: a live counter per detector, the associated AP clients it has seen, and the session incident log.

Acting on a confirmed attack
The On confirmed attack panel picks what runs when a detector confirms an attack with a source MAC: triangulate, packet capture, device discovery, probe sweep, drone RID, each with its own duration. Only one can hold the radio, so several ticked run in that order, one at a time, as it frees up. The queue is dropped after 15 minutes if the radio never frees.

Same panel sets the auto-capture budget. Captures made this way are auto_ files, pruned oldest-first to stay inside the budget and keep the card's free-space floor. Manual captures are never touched.

A RESPONSE IS A SCAN
Detection pauses for the duration of each action. On a site that trips often, keep the durations short.

### 9.8 Drone Remote ID

Identifies drones broadcasting Remote ID (ODID / ASTM F3411, and French ID) over both Wi-Fi beacon/NAN and BLE. Reports the serial or CAA registration, position, altitude and speed, and the operator's location when the aircraft broadcasts it.

@ALL DRONE_START:300

DRONE: is sent once per appearance. A drone that stays in range is not re-announced. DRONE_LOST: follows 120 s after the last beacon.

### 9.9 Triangulation

Several nodes each report RSSI for one target MAC, and the coordinator fits a position from the set. Needs at least three nodes with valid GPS fixes and matched antennas.

The environment argument sets the path-loss model: 0 open sky, 1 suburban, 2 indoor, 3 dense indoor, 4 industrial. Choosing the wrong one is the usual cause of a distance estimate that looks wrong. Results arrive as T_D: per-node data, T_F: the final fix with confidence and uncertainty, and T_C: complete, with a map link.

### 9.10 CSI Motion Detection

Tells you when someone is moving nearby, even through walls. Indoors only. It notices movement, not someone sitting still.

How it works. Wi-Fi signals bounce around a room. When a person moves, the bounces change. The node listens to the Wi-Fi routers and phones around it and alerts when several of their signals change at once.

Start it: Scan tab → CSI Motion Detection → Start Scan. Over mesh:

@ALL CSI_MOTION_START:0:FOREVER

(experimental, beta | firmware only)

Pick a sensitivity:

Low (default): fewest false alarms. Two devices must see the movement.
Medium: more sensitive. Two devices, or one device seeing a very strong change (4× the trigger). High: most sensitive. Same as Medium with a lower trigger and a shorter wait. More false alarms.

Settings (Scan tab → CSI Motion Detection; most are under Advanced):

Setting | What it means | Default
Movement needed before alerting | How long someone must move before you get an alert | 8 s
Stillness before all-clear | How long it must be quiet before the alert clears | 5 s
Devices that must agree | How many devices must see the movement at the same time | 2
Trigger level | Lower catches smaller movement | set by sensitivity
Listen only, never transmit | The node never sends probes. Turn off only if it sees too little Wi- Fi | On
Include randomized-MAC devices | Also listen to phones and watches, not just routers | On
Min. seconds between mesh motion alerts | Wait at least this many seconds between motion alerts sent over mesh | 0 (no limit)

Getting false alarms with nobody there? Turn on "Per-packet score to serial", watch the sig numbers while the room is empty, and set Trigger level just above the highest one.

CAN TRANSMIT
Off by default. If you turn off "Listen only, never transmit", the node sends Wi-Fi probe requests when there is too little traffic to measure. Anyone nearby can see them. Check local rules before turning it on.

Mesh commands: §11.

### 9.11 Packet Capture

Records raw traffic to SD as a standard pcap. Wi-Fi frames carry a radiotap header with channel, rate and RSSI. BLE captures are written as Bluetooth HCI, link type 187: the controller's own events, unmodified, so Wireshark shows LE Advertising Reports with address, address type, advertising data and RSSI. HCI carries no RF channel, so the capture does not report one.

Scan tab, pick Packet Capture, set radio and duration, press Start Capture. Files land in /pcap and list under the button, each with a download and a delete.

Arguments are radio, seconds, band. Radio 0 Wi-Fi, 1 BLE, one at a time; there is no both, and any other value, including 2, is taken as Wi-Fi. Unlike the mode field of the other scan commands, 2 does not mean both here. Band 0 is 2.4 GHz, 1 is 5 GHz, 2 both; 5 GHz needs a C5. Advanced sets a channel list, dwell, a management-frames-only filter, and the maximum file size.

The mesh reply names the radio that actually started, PCAP_START: WIFI or PCAP_START: BLE. Getting WIFI back from a command you meant as BLE means the radio field was wrong. A capture started by a vibration trigger or a Sentinel attack response is always Wi-Fi on 2.4 GHz; BLE is a manual choice only.

A capture stops on its own when the file reaches the size cap, when free space drops below the floor, or when the card stops accepting writes. The mesh reply carries the reason: R=SIZECAP or R=WRITEFAIL. The cap is 8 to 300 MB, 100 MB by default, set on the Scan tab or over mesh.

CAPTURES ARE LARGE AND CARRY EVERYTHING
A busy channel fills megabytes per minute. Check free space before a long run, and treat the file as a raw intercept.

STOP THE CAPTURE BEFORE YOU CUT POWER
FAT has no power-fail protection. Resetting or unplugging a node while a capture is writing can leave the card unreadable until it is reformatted, and the node then runs with no storage at all: no logging, no baseline, no captures. Stop the capture first.

A node can rebuild its own card instead of waiting for someone with a card reader. This is off by default because rebuilding erases everything on the card.

@ALL SD_REPAIR:ON
@ALL SD_REPAIR:NOW
@ALL SD_REPAIR:OFF

NOW repairs once without changing the setting. With repair off, a failed mount says so once a minute and the SD line in Diagnostics shows how many times it has failed.

### 9.12 Scheduling scans

The Schedule panel on the Scan tab runs any scan at set times. The node runs it, so the web page can be closed.

1. Pick the scan in the top row and set its options.
2. Press Schedule this scan.
3. Set Start, Duration in minutes and Repeat, then press Add.

The block keeps the options that were set when you added it. Changing the scan's options later does not change the block. Delete it and add it again instead.

Setting | Values
Start | Date and time in the node's local time, shown with its zone, for example MST
Duration | 1 to 1440 minutes
Repeat | Once, hourly, every 6 hours, every 12 hours, daily, weekly

Time zone. The node picks its zone from the GPS fix, daylight saving included. Daily and weekly blocks keep the same clock time across a daylight saving change. With no GPS fix, or outside the zone table, times are UTC.
Busy radio. A block that comes due while another scan holds the radio runs as soon as the radio frees. A repeating block then moves to its next slot. If a mesh command or another start takes the radio at the same moment, the block is not lost; it tries again 5 seconds later.
Vibration and attack scans. By default they wait for a scheduled scan: a vibration auto-scan is skipped, an attack response runs when the scan ends. Turn on Interrupt scheduled scans in Vibration Auto-Scan (System tab) or in the attack-response panel (Sentinel tab) to let that trigger stop the scheduled scan, run, and then resume the scheduled scan for its remaining time. A resumed Baseline starts its learning phase again. A scheduled block never takes the radio while a vibration or attack scan is waiting for it.
Over mesh. SCHED_ADD:2026-09-30T02:00|86400|/sniffer|detection=device-scan&deviceScanMode=2&secs=600 adds a daily block. SCHED_LIST prints the blocks to serial, SCHED_DEL:2 deletes the second one.
Battery Saver. Schedules pause while Battery Saver is on. A block that came due runs once when it ends. Limits. 8 blocks. They are kept in NVS and survive reboots.
Baseline blocks. Adding one saves the baseline settings on the Scan tab to the node, and each run uses the baseline settings saved at that time.

CLOCK
Schedules need the clock from §4.3. On a node without a working RTC, blocks wait until the web UI is opened once after boot, which gives the node the time.

### 9.13 Reading the results

SD card, both builds. Scan results in /last_results.txt, the probe database, vibration events in /vibrations.jsonl, packet captures in /pcap, sentinel incidents and the scan logs. Logging does not depend on which firmware you flashed.
Web UI, Full only. The Results tab renders each scan as cards, and the API serves the same content as plain text. Device database, Full only. /devicedb.jsonl is what the Data Explorer browses. Headless does not write it. Mesh. Every alert above, plus SCAN_DONE: summaries carrying TX= broadcast and DUP= deduplicated counts.

EXPORTS CARRY LOCATION
SD logs, exports and mesh alerts can all contain GPS coordinates. Review any file before you post it publicly or attach it to a report. Privacy Mode only redacts the live web UI.

# 10 Vibration sensor and tamper response

### 10.1 How it works

The SW-420 is a mechanical vibration switch with a comparator and a trimpot on board. It has one job: pull its digital output high when movement exceeds the threshold the trimpot sets. That output goes to GPIO 2 on the ESP32, configured as a pull-down input with a rising-edge interrupt.

When it fires, the firmware:

Sends a mesh alert if vibration alerts are enabled: NODE: VIBRATION: Movement detected at TIME [GPS:lat,lon]
Writes a structured event to /vibrations.jsonl on the SD card
Optionally starts a scan (§10.3)
Counts toward the tamper auto-erase trigger if that is armed (§10.4)

Alerts are rate-limited to one every 3 seconds, so continuous shaking produces a steady trickle rather than a flood. The System diagnostics show Vibration sensor: Standby or Vibration sensor: Active - Last: TIME (Ns ago).

Turn alerts on and off with @AH01 VIBRATION_ON and VIBRATION_OFF, or the toggle in the web UI's Sensor Alerts card. VIBRATION_STATUS reports the current state.

### 10.2 Tuning the trimpot

The trimpot is the small brass screw on the sensor module. It sets the sensitivity threshold, and the correct setting depends entirely on where the node is mounted. A pole in the wind is not a shelf indoors. Tune it after the node is in its final position, not on the bench.

1. Power the node and watch the sensor's own indicator LED, or open a serial monitor and watch for [VIBRATION] lines.
2. Leave the node completely still. If it is triggering by itself, turn the screw an eighth of a turn at a time in the direction that stops it. Wait several seconds between adjustments. The module reacts slowly.
3. When it is silent at rest, back off slightly further so ambient movement does not set it off.
4. Now tap the enclosure the way a person handling it would. It should fire.
5. If it does not, turn back the other way a fraction at a time until a deliberate tap triggers it but the node at rest does not.
6. Confirm the events actually reached the firmware: the diagnostics timestamp updates, and each event is appended to /vibrations.jsonl.

TUNING BY SYMPTOM
Constant false alerts. Too sensitive, or mounted on something resonant. Reduce sensitivity, and consider a foam pad or a stiffer mount.
Nothing fires even when you shake it. Too insensitive, or the sensor is not seeing GPIO 2. Check the diagnostics line and the solder joints on the sensor header.
Fires only sometimes. You are on the edge of the threshold. Back it off a fraction toward sensitive.

### 10.3 Vibration auto-scan

Movement can start a scan automatically. This suits a node used as a trip sensor rather than a continuous monitor.

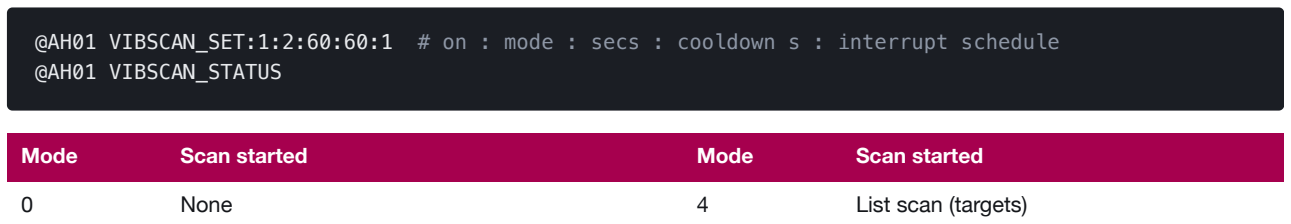
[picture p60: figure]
@AH01 VIBSCAN_STATUS; Mode; Scan started; None; List scan (targets)

@AH01 VIBSCAN_SET:1:2:60:60:1 # on : mode : secs : cooldown s : interrupt schedule

1 | All-device scan | 5 | Drone / Remote ID
2 | Probe-request detect | 6 | Deauth (blue team)
3 | Randomized-MAC detect | 7 | Baseline anomaly
| | 8 | Packet capture to SD

Duration 0 means run until stopped. The trigger is skipped if a scan is already running or the node is in battery saver. Mode 8 writes an auto_ capture, which is subject to the auto-capture budget rather than kept forever.

### 10.4 Tamper auto-erase

The node can destroy its own data when it is moved. This is off by default, and it is permanent and irreversible.

Parameter | Range | What it does
Setup delay | 30 s to 10 min | Grace period after arming, so installing the node does not wipe it
Vibrations required | 2 to 5, default 3 | How many movement events count as tampering

Parameter | Range | What it does
Detection window | 10 to 60 s | The period those events must fall within
Erase delay | 10 to 300 s | Countdown before destruction, your window to cancel
Cooldown | 5 to 60 min | Minimum time between tamper attempts, to blunt false triggers

During the setup period the node still reports movement, so you can watch the arming from a distance: VIBRATION: Movement in setup mode (active in Ns). When it triggers you get TAMPER_DETECTED: Auto-erase in Xs.

Remote erase
Every command marked <key> takes the erase key (§8.1): @AH01 ERASE_FORCE:<key>. 5 wrong keys lock erase commands for 10 min.

To keep the key off the mesh, answer a token instead:

1. Send @AH01 ERASE_REQUEST (one per 20 s). The node replies AH01: ERASE_TOKEN:AH_3F2A91C0_77B0E412_000004D2 Expires:300s.
2. Sign the token: printf '%s' 'AH_3F2A…' | openssl dgst -sha256 -hmac 'yourKey'.
3. Within 300 s send the 64 hex characters, or the first 8, in place of <key>. A token answers once.

In the web UI, enter the key in the Authorization field.

After a wipe the node plants a dummy IoT weather configuration in place of its own, so a recovered device does not obviously read as a sensor.

Factory reset

@AH01 FACTORY_RESET:FULL:<key> # FULL | CONFIG | DATA

Single node only.

DATA DESTRUCTION IS IRREVERSIBLE
Test your settings with a node that holds nothing you care about. A wipe cannot be undone, and the countdown is short by design.

# 11 Mesh command reference

Send these as ordinary text messages from the Meshtastic app, a Command Center, or any client on your channel. @ALL broadcasts. A node ID targets one node. Times are the node's local time once GPS fixes the zone, UTC before that.

### Core

Command | Description
STATUS | Mode, scan state, hits, temperature, uptime, GPS; then STATUS_BOOT: reset
reason, previous uptime, SD faults
STOP | Stop all operations and any pending attack response, flush pending mesh
| transmissions

### Configuration

Command | Does | Parameters
CONFIG_TARGETS | Set the watchlist | Pipe-delimited MACs, OUIs or SSIDs
CONFIG_NODEID | Rename the node | 2 to 5 alphanumeric characters
CONFIG_RSSI | Set the RSSI floor | −128 to −10
CONFIG_CHANNELS | Set the channels to sweep | List or range, e.g. 1..11
CONFIG_BAND | Pick the band, C5 only | 0 = 2.4 GHz, 1 = 5 GHz, 2 = both
CONFIG_DEDUP_TTL | Set cross-scan MAC dedup | 0 to 3600 s, 0 disables
CONFIG_SESSION_DEDUP | Toggle per-session dedup | 0 or 1
MESH_DEDUP_CLEAR | Clear the dedup cache | None
DEVICE_DB_CLEAR | Clear the discovered-device DB, headless, Beta and C5 | None
CONFIG_ERASE_PSK | Set the erase key | <new>:<current>, 8 to 64 characters, no :; §8.1

### Scanning

Command | Does | Parameters
SCAN_START | Hunt the watchlist | mode:secs:channels[:FOREVER]
DEVICE_SCAN_START | List everything in range | mode:secs[:FOREVER[:+PROBE]]
PROBE_START and PROBE_STOP | Collect probe requests | mode:secs[:FOREVER][:+ALL]
BASELINE_START and BASELINE_STATUS | Learn the area, then flag changes | duration[:FOREVER], min 60 s
BASELINE_WATCH | Watch for changes from now | None; baseline must be running
DRONE_START | Watch for drone Remote ID | secs[:FOREVER]
DEAUTH_START | Watch for deauth attacks | secs[:FOREVER]
RANDOMIZATION_START | Link randomized MACs to devices | mode:secs[:FOREVER]
CSI_MOTION_START | Detect movement in the room, Beta and C5 | secs[:FOREVER][:CH<n>][:TELEM][:RAW] [:GAP<s>][:LISTEN_ONLY|ALLOW_TRANSMIT] [:MGMTONLY|MGMTDATA][:SOLICIT<ms>]
CSI_CFG | Tune the motion trigger, Beta and C5 | trigger:hold_ms:consec:channel or SENSITIVITY=LOW|MEDIUM|HIGH, MIN_MOTION=, CLEAR_AFTER=, SPOTS=, BROADCAST=ON|OFF, ALLOW_RANDOM=ON|OFF

Command | Does | Parameters
CSI_STATUS and CSI_JSON | Dump motion state to serial, Beta and C5 | None
CSI_RECAL | Drop a saved trigger, Beta and C5 | None
CSI_EXCLUDE | Ignore one MAC for motion, Beta and C5 | <MAC> or NONE
MESH_TX_CANCEL | Drop queued mesh traffic, keep scanning | None
PCAP_START and PCAP_STOP | Record traffic to SD as pcap | radio:secs:band[:CH<list>]
PCAP_LIMITS | Set or read the capture size cap | [MB], 8 to 300
PCAP_AUTO | Set or read the auto-capture SD budget | [budgetMB,floorMB]
PCAP_DELETE_ALL | Delete every capture on SD | None
SD_REPAIR | Rebuild an unmountable SD card; erases it | ON|OFF|NOW
TRIANGULATE_START | Locate a MAC across nodes | target:duration[:rfEnv[:wifiPwr:blePwr]]
TRIANGULATE_RESULTS and TRIANGULATE_STOP | Report the fix, or stop | None

Mode is 0 Wi-Fi, 1 BLE, 2 both. CH0 or no channel surveys and pins the busiest. PCAP is the exception: its radio field is 0 Wi-Fi / 1 BLE only, one radio per capture, and 2 is taken as Wi-Fi rather than both. PCAP band 0 is 2.4 GHz, 1 is 5 GHz, 2 both; 5 GHz needs a C5.

### Sentinel (Beta and C5)

Command | Does | Parameters
SENTINEL_ON, SENTINEL_OFF, SENTINEL_STATUS | Start, stop, report | None
SENTINEL_MODE | Pin a channel or hop | defend or scan
SENTINEL_BOOT | Auto-start at power-on | 1 or 0
GROUP | Toggle a detector group | <dos|rogue|recon|physical|mesh|all>: <on|off>
DETECT_CFG and DETECT_CFG_GET | Set or dump detector tunables | JSON, 180 characters or fewer
INCIDENTS and INCIDENTS_CLEAR | Dump or clear the incident log | [:1-200]
ATTACKER_TRILAT and ATTACKER_TRILAT_STATUS | Triangulate a confirmed attacker, or report the setting | 1 or 0, off by default
DETECT_JSON and DETECT_CLEAR | Dump a detector's list to serial, or clear it | karma|pg|tsf|hshk|pwna|tof|hunts|pcap|pcaps
DETECT_COUNTS | Entry count per detector, pending attack responses | None
DETECT_VERBOSE | Per-frame detector logging on serial | ON|OFF

Command | Does | Parameters
QUORUM | Nodes that must agree before an alert | <type>,<n>, e.g. PMKID,2
KARMA_ON and KARMA_OFF | Karma detector; transmits bait probes to confirm a suspect AP | None
HUNT_COOLDOWN | Gap between attacker hunts | ms
TOF_PING | Time-of-flight ping | [:node], all if omitted
ATTACK_RESPONSE_CANCEL | Drop a pending attack response | None

### Security, power and heartbeat

Command | Does | Parameters
ERASE_REQUEST, ERASE_FORCE, ERASE_CANCEL | Token, wipe, abort | None, <key>, <key>; §10.4
AUTOERASE_ENABLE | Wipe if the node is moved | setup:erase:vibs:window:cooldown:key
AUTOERASE_DISABLE and AUTOERASE_STATUS | Turn that off, or report it | <key>, none
VIBRATION_ON, VIBRATION_OFF, VIBRATION_STATUS | Enable, disable, report the sensor | None

VIBSCAN_SET and
VIBSCAN_STATUS
| Start a scan when moved | en:mode:dur[:cooldown[:interrupt]]
SCHED_ADD, SCHED_LIST, SCHED_DEL | Add, list or delete a schedule block | at|repeat s|path|body, none, block number
FACTORY_RESET | Reset one node | <FULL|CONFIG|DATA>:<key>
BATTERY_SAVER_START | Drop to low power | Minutes, 1 to 30, default 5
BATTERY_SAVER_STOP and BATTERY_SAVER_STATUS | Return to normal, or report | None
HB_ON, HB_OFF, HB_INTERVAL | Periodic status broadcast, off by default | Interval 1 to 60 min

### Ten commands to learn first

@ALL STATUS | # who is alive, and what are they doing
@ALL STOP | # stop everything, everywhere
@AH01 CONFIG_NODEID:GATE1 | # name a node
@ALL CONFIG_TARGETS:AA:BB:CC|MyWiFi # set the watchlist
@ALL SCAN_START:2:600:1..11 | # 10 min watchlist scan, Wi-Fi + BLE
@ALL DEVICE_SCAN_START:2:300 | # survey everything nearby
@ALL BASELINE_START:900 | # learn the site for 15 min
@ALL SENTINEL_ON | # attacker-tool detection
@ALL DRONE_START:0 | # drone watch until stopped
@AH01 BATTERY_SAVER_START:10 | # idle a node without losing the mesh

# 12 Command Center

One node needs no server. A fleet benefits from one: AntiHunter Command & Control PRO aggregates every node's detections onto a live map, with TAK, MQTT and ADS-B integration and a Sentinel console.

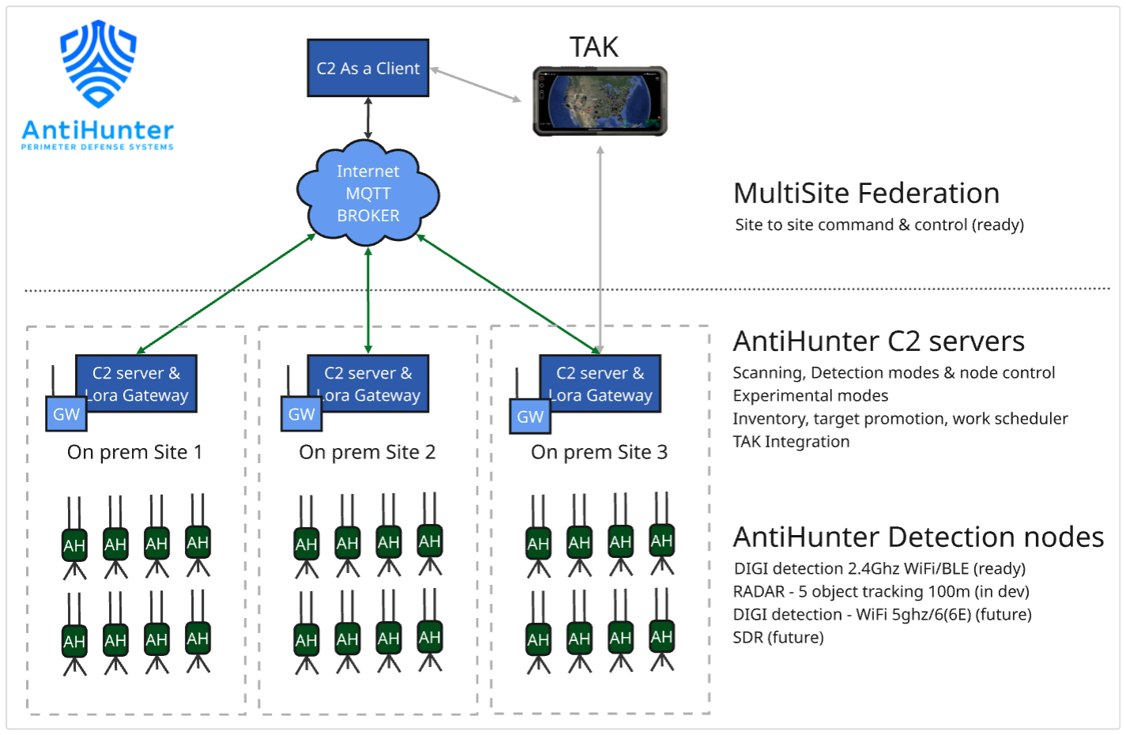
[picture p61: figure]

Nodes operate independently and coordinate over the mesh. The Command Center aggregates.

### 12.1 What you need

A computer to run it on: Linux, macOS or Windows 10/11. It can be the same machine you flash from. A Meshtastic radio on USB, joined to your channel, to receive the mesh.
Node.js 20 or newer and PostgreSQL. The installer puts both in place for you.

### 12.2 Quick install: Linux and macOS

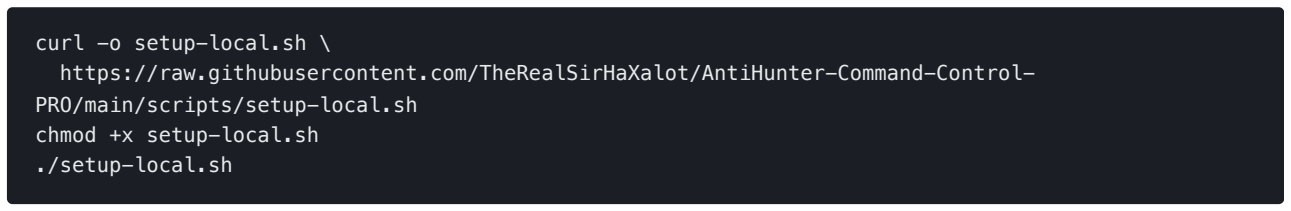
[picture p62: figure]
curl -o setup-local.sh \ https://raw.githubusercontent.com/TheRealSirHaXalot/AntiHunter-Command-Control- PRO/main/scripts/setup-local.sh chmod +x setup-local.sh ./setup-local.sh

Run it as a normal user, not with sudo. It asks for sudo itself when it needs it. It installs the prerequisites, clones the project, sets up the database, runs the migrations and seeds an admin login. When it finishes, open http://localhost:5173 and log in with the credentials it printed.

### 12.3 Quick install: Windows 10/11

1. Install Git in any PowerShell window, then close it so Git lands on your PATH:

winget install -e --id Git.Git --accept-package-agreements --accept-source-agreements

2. Open PowerShell as Administrator. The installer needs it to install system software.
3. Clone and run the installer:
4. Press Enter to accept the defaults. The first run takes a few minutes. Write down the admin email and password it shows you.
5. Start it with Start-AntiHunter.cmd in the project folder, or pnpm AHCC.
6. Open http://localhost:5173 and log in.

WINDOWS NOTES
The firewall prompt on first start: click Cancel if you only use it on this PC, since localhost works either way. To reach it from other devices, click Allow and tick Private only.
For serial hardware, put SERIAL_DEVICE=COM3, your port from Device Manager → Ports, in apps\backend\.env and restart.
Do not use WSL. COM ports do not pass through cleanly.

### 12.4 Docker

Needs Docker 25 or newer. If you have no serial adapter at /dev/ttyUSB0, which is every macOS and Windows host, comment out the devices: and group_add: lines under the backend service first, or the container will not start.

Three containers come up: Postgres, the backend on port 3000, and the frontend on http://localhost:8080. The seeded admin defaults to admin@example.com and admin. Logs: docker compose logs -f backend. Stop: docker compose down, adding --volumes to delete the database too.

CHANGE THE ADMIN PASSWORD IMMEDIATELY
The seeded credentials are published in the documentation. Change them at first login, before the server is reachable by anything but you. Enable two-factor authentication and HTTPS if the instance will be reached across a network, and work through the hardening checklist in the project README.

### 12.5 Updating

Use the in-app update page, or git pull in the project folder. Docker: git pull && docker compose up -d --build. The backend re-applies migrations on boot.
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

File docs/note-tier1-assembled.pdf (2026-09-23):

## AntiHunter

P E R I M E T E R D E F E N S E S Y S T E M S

Tier 1 · Fully assembled unit

# DIGI Node — Tier 1: Fully Assembled Unit

Built, soldered and bench-tested. Meshtastic is flashed on the radio, and the radio’s serial link to the node is already configured.

### In the box

Item | Notes
Assembled node | 8 GB microSD fitted, TPU seals fitted
Active GPS helix antenna | Center SMA
2.4 GHz WiFi/BLE SMA antenna | Left SMA
LoRa SMA antenna for your region (915 MHz US) | Right SMA
Not included: two 18650 batteries. Use flat-top cells of the same brand and capacity.

### Set it up
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

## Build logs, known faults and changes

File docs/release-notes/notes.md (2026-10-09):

# AntiHunter v1.0.5

User-set erase key, headless scheduler and baseline watch, Sentinel detector cards and mesh commands back, results UI rework, fixes.

| Channel | Version | Board | Previous |
|---|---|---|---|
| Stable | v1.0.5 | ESP32-S3 | v1.0.4 (2026-10-04) |
| Beta | v1.0.5-beta1 | ESP32-S3 | v1.0.4-beta1 (2026-10-04) |
| Experimental | v1.0.5-c5exp1 | XIAO ESP32-C5 | v1.0.4-c5exp1 (2026-10-04) |

Items marked **(Beta/C5)** need Sentinel, which Stable builds without (`AH_SENTINEL=0`).

## Erase key (all channels; read before upgrading)

- A wipe needs an erase key you set: web UI, flasher `CONFIG` `erasePSK`, or `CONFIG_ERASE_PSK:<new>:<current>`. Until then erase commands reply `ERASE_ACK:SET_KEY_FIRST`.
- Full: the AP password serves as `<current>` for setting the key, once the AP password is no longer the default. Headless: no key until set in the flasher.
- `ERASE_FORCE`, `ERASE_CANCEL`, `AUTOERASE_*` and `CONFIG_ERASE_PSK` take the key directly. HMAC token answers still work for scripts and C2; each token is valid for one answer.
- One `ERASE_REQUEST` per 20 s. 5 wrong keys lock erase commands for 10 min.
- Keys are 8-64 characters, no `:`. Boot no longer prints the key. A flasher-set key goes to NVS only and is stripped from the SD config.

## New

- Headless: `SCHED_ADD`, `SCHED_LIST`, `SCHED_DEL` scan scheduler and `BASELINE_WATCH`, same as Full.
- Mesh, Full and headless: `STATUS_BOOT:` line after `STATUS` with reset reason, previous uptime, restored results, SD mount failures and write retries.
- Mesh, Full and headless: `PCAP_AUTO[:<budgetMB>,<floorMB>]` sets auto-capture limits; `PCAP_DELETE_ALL` deletes every capture on the SD card.
- Mesh, Full and headless **(Beta/C5)**: `DETECT_JSON:<karma|pg|tsf|hshk|pwna|tof|hunts|pcap|pcaps>`, `DETECT_CLEAR:<name>`, `DETECT_COUNTS`, `DETECT_VERBOSE:ON|OFF`, `TOF_PING[:<node>]`, `KARMA_ON`/`KARMA_OFF`, `HUNT_COOLDOWN:<ms>`, `QUORUM:<type>,<n>`, `ATTACK_RESPONSE_CANCEL`.
- Detection tab **(Beta/C5)**: Pwnagotchi card; Karma bait on/off; hunt cooldown; verbose detector logging; quorum setting; pending attack response with Cancel; link to the raw `/detect` logs.
- System tab: set the RTC from the browser's clock.
- Results: WiFi rows show the advertised auth; target hits are marked by the firmware and listed first; one sorter for all result lists, and the sort menu lists only options that apply; collapsed sections stay closed.
- Target card: Targets and Allow list above the scan options; trend badges Steady and Measuring; Movement toggle in the Forever/Triangulate row.
- Results toolbar is a full-width bar with a mobile grid layout.
- Watchlist accepts hex tracer IDs (`T-00A3`).
- PCAP files carry the radiotap MCS field for HT frames.

## Fixed

- **(Beta/C5)** STOP (web and mesh) cancels a pending attack response. Before, a response armed while a scan ran started its capture after STOP, up to 15 min later.
- **(Beta/C5)** Detection tab: 14 detector cards (RID, recon, Karma, hunts, handshake, probe graph, TSF, beacon forge, PMKID forge, EAPOL bait, probe flood, assoc sleep, jamming, mesh guard, TOF) were missing from the page while their refresh code still ran.
- **(Beta/C5)** `/api/pwnagotchi` returned invalid JSON for a real pwnagotchi; the beacon text is now escaped there and in detector tables.
- Battery saver now lowers the CPU clock to 80 MHz (restores 240 MHz on exit). Before, the clock never changed.
- Headless: boot forensics (previous uptime, restored results) reach the mesh again.
- `CONFIG_TARGETS` over mesh splits on `|`; mesh text has no newlines.
- Auto-erase counts vibrations within the detection window and triggers at the configured count.
- Targets list saves on blur; the block list saves in privacy mode.
- Privacy mode redacts device-scan names and full MACs in the Data tab.
- List scan lines carry a range estimate and always highlight hits; target tokens accept any MAC separator.
- Class table counts device rows only.

## Upgrade

Settings and SD card files survive a flash. Erase commands stay refused until you set an erase key (see above).

All three builds attach to the one v1.0.5 release.
Per channel: `antihunter-<full|headless>-<version>.bin`; C5 uses `.factory.bin`.
Also `bootloader`, `partitions` and `SHA256SUMS` per version.
Builds are reproducible; verify with `shasum -a 256`.

| | Stable | Beta | Experimental (C5) |
|---|---|---|---|
| Web flasher channel | Stable | Beta | Experimental — ESP32-C5 |
| Script channel | 1 | 2 | 3 |
| Branch | `main` | `beta` | `feat/c5` |
| PlatformIO full | `AntiHunter-full` | `AntiHunter-full` | `AntiHunter-c5-full` |
| PlatformIO mesh-only | `AntiHunter-headless` | `AntiHunter-headless` | `AntiHunter-c5-headless` |

**Web flasher**: [lukeswitz.github.io/AntiHunter](https://lukeswitz.github.io/AntiHunter/) in Chrome or Edge.
Pick the channel, then Full or Headless.

**Flasher script** (Python 3, esptool, pyserial), same on every branch:

```bash
curl -fsSL -o flashAntihunter.sh https://raw.githubusercontent.com/lukeswitz/AntiHunter/main/Dist/flashAntihunter.sh
chmod +x flashAntihunter.sh
./flashAntihunter.sh
```

`-c` sets device settings; `-l` lists firmware.

**PlatformIO**: `-t upload` keeps settings and the SD card.

Stable:

```bash
git clone -b main https://github.com/lukeswitz/AntiHunter.git
cd AntiHunter
pio run -e AntiHunter-full -t upload        # web UI
pio run -e AntiHunter-headless -t upload    # mesh only
```

Beta:

```bash
git clone -b beta https://github.com/lukeswitz/AntiHunter.git
cd AntiHunter
pio run -e AntiHunter-full -t upload
pio run -e AntiHunter-headless -t upload
```

Experimental (C5):

```bash
git clone -b feat/c5 https://github.com/lukeswitz/AntiHunter.git
cd AntiHunter
pio run -e AntiHunter-c5-full -t upload
pio run -e AntiHunter-c5-headless -t upload
```

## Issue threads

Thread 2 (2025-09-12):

Feat: Add Configurator

lukeswitz, 2025-09-12:
Nodes need a way to be configured:

- [ ] From AHCC
- [ ] Directly, using meshC2 commands
- [x] From AH WebUI

Granular Settings:
- Set AP name/password
- Wipe SD logs on xxx event, erase flash memory
- Set Node ID
- Set scan targets (MAC/OUI)
- Alert/notification toggles by event including Webhooks for Signal, IFTTT, Matrix, Veilid etc. for AHCC
- Set runtime with graceful shutdown
- Set fan activation temperature
- Toggle GPS redacting from query/alert messages and logging
- more…

lukeswitz, 2025-09-24:
Rethinking this for security

Closed 2025-09-24.

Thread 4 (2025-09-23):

Bug: AP stability

lukeswitz, 2025-09-23:
ESP-IDF STA/AP switching has known issues with bind errors.

Tested multiple ways of network cleanup/restoration. Likely caused from improper promiscuous to AP transfer post-scan

lukeswitz, 2025-09-24:
Deinit wasn’t always clean, stable in 82 tests

Closed 2025-09-24.

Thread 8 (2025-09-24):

Bug: Mesh on PCB

lukeswitz, 2025-09-24:
Need to investigate pins and possible serial data corruption for cause. More information needed

lukeswitz, 2025-09-24:
All set.

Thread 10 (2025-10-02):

[Enhancement] Better user feedback for baseline scan

lukeswitz, 2025-10-02:
### Issue Type

Bug Report

### Description

During monitor phase there is the active button lit up, but needs status for phase 2 as we do in phase 1.

Fixes needed:
- Baseline resets on start scan
- Subsequent scans don’t compound
- BLE scan needs more priority over WiFi
- C2 integration, API endpoints

### Hardware Platform

PCB v1

### Firmware Version

V5 commit 4f7e3716959828bd4072f38ea909b95619cd5dab

Closed 2025-10-02.

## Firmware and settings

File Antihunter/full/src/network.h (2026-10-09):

#pragma once
#include <Arduino.h>
#include <WiFi.h>
#include <ESPAsyncWebServer.h>
#include <Preferences.h>
#include "scanner.h"

// T114 v2 rate limiter for Serial Module
// ~400 B/s sustained, 1 KB burst. Consumer task owns inter-frame pacing via vTaskDelayUntil.
class SerialRateLimiter {
private:
    static const uint32_t MAX_TOKENS = 1000;
    static const uint32_t REFILL_INTERVAL = 1000;
    static const uint32_t TOKENS_PER_REFILL = 400;

    uint32_t tokens;
    unsigned long lastRefill;

public:
    SerialRateLimiter();
    bool canSend(size_t messageLength);
    void consume(size_t messageLength);
    void refillTokens();
    void flush();
    uint32_t available() const { return tokens; }
    static constexpr uint32_t capacity() { return MAX_TOKENS; }
};

// Mesh TX priority classes (Phase 2).
// CONTROL preempts EVENT preempts BULK at drain time, and CONTROL/EVENT may evict back-of-BULK on enqueue-full.
enum MeshPriority : uint8_t {
    PRIO_CONTROL = 0,  // triangulation T_F/T_C/T_D, *_ACK, TRI_*, TRIANGULATE_*
    PRIO_EVENT   = 1,  // ATTACK, DEAUTH, DETECT, EAPOL, HSHK, KARMA, VIBRATION, GPS, RTC_SYNC, STARTUP, Target
    PRIO_BULK    = 2,  // DEVICE, SCAN_DONE, heartbeat, default
    PRIO_DEFAULT = PRIO_BULK,
};

bool sendToSerial1(const String &message, bool canDelay = true);
bool meshEnqueue(const String &msg, bool priority = false);
bool meshEnqueuePrio(const String &msg, MeshPriority prio);
void meshTxFlushQueue();
uint32_t meshTxQueueDepth();
bool meshTxPending();
uint32_t meshMsgUnits(const String &msg);
uint32_t meshTxDroppedCount();
enum ScanMode { SCAN_WIFI, SCAN_BLE, SCAN_BOTH };

constexpr int MAX_MESH_SIZE = 230;  // packs more DEVICE rows/frame; stays under Meshtastic 237B text-payload cap
extern SerialRateLimiter rateLimiter;
extern SemaphoreHandle_t serial1Mutex;
extern std::atomic<bool> g_eraseWipeBusy;
extern AsyncWebServer *server;
extern bool meshEnabled;
extern bool hbEnabled;
extern uint32_t hbInterval;
extern bool vibrationEnabled;
extern volatile uint32_t apScanSuppressUntilMs;

#ifndef AP_SSID
#define AP_SSID "Antihunter"
#endif
#ifndef AP_PASS  
#define AP_PASS "antihunt3r123"
#endif
#ifndef AP_CHANNEL
#define AP_CHANNEL 6
#endif
#ifndef AP_INACTIVE_TIME_SEC
#define AP_INACTIVE_TIME_SEC 3600
#endif
#ifdef ARDUINO_XIAO_ESP32C5
#define DEFAULT_CHANNELS {1,2,3,4,5,6,7,8,9,10,11, 36, 40, 44, 48, 149, 153, 157, 161, 165}
#else
#define DEFAULT_CHANNELS {1,2,3,4,5,6,7,8,9,10,11}
#endif

// Network and Web Server functions
void initializeNetwork();
void initializeMesh();
void startWebServer();

// Mesh communication
void sendMeshNotification(const Hit &hit);
void sendMeshCommand(const String &command);
void processMeshMessage(const String &message);
void meshSplitSender(const String &line, String &sender, String &payload);
void meshFleetObserve(const String &sender, const String &payload);
String meshFleetJson();
void meshFleetClear();
void processUSBToMesh();
void serviceVibrationAutoScan();
void scheduleTick();
int schedAddBlock(const String &at, long period, const String &path, const String &body, String &msg);
bool schedDelLine(const String &del);
String schedListText();
bool schedulerYieldRadio(const char *who);
bool vibAutoScanWaiting();
void setNodeId(const String &id);
String getNodeId();
int fleetSend(String node, String cmd, String &msg);
extern unsigned long meshSendInterval;

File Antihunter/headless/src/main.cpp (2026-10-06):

#include "main.h"
#include "triangulation.h"
#include <SPI.h>
#include <Arduino.h>
#include <Preferences.h>
#include "network.h"
#include "scanner.h"
#include "hardware.h"
#include "detect.h"
#include <SD.h>
#include <TinyGPSPlus.h>
#include <HardwareSerial.h>
#include "esp_wifi.h"
#include "esp_log.h"
#include "esp_heap_caps.h"


Preferences prefs;
ScanMode currentScanMode = SCAN_WIFI;
std::vector<uint8_t> CHANNELS = {1,2,3,4,5,6,7,8,9,10,11};
std::atomic<bool> stopRequested(false);

unsigned long lastRTCUpdate = 0;

TaskHandle_t workerTaskHandle = nullptr;
TaskHandle_t blueTeamTaskHandle = nullptr;
extern std::atomic<bool> scanning;

std::string antihunter::lastResults = "No scan data yet.";
std::mutex antihunter::lastResultsMutex;

void uartForwardTask(void *parameter) {
  static String meshBuffer = "";

  for (;;) {
    String rxChunk = "";
    uint32_t lastRxMicros = 0;
    if (serial1Mutex != nullptr && xSemaphoreTake(serial1Mutex, pdMS_TO_TICKS(10)) == pdTRUE) {
      const size_t MAX_DRAIN_BYTES = 256;
      size_t drained = 0;
      while (Serial1.available() && drained < MAX_DRAIN_BYTES) {
        rxChunk += (char)Serial1.read();
        lastRxMicros = micros();
        drained++;
      }
      xSemaphoreGive(serial1Mutex);
    }

    for (size_t i = 0; i < rxChunk.length(); i++) {
      char c = rxChunk[i];
#if defined(AH_USB_ECHO) && (AH_USB_ECHO)
      Serial.write(c);
#endif

      if (c == '\n' || c == '\r') {
        if (meshBuffer.length() > 0) {
          if (!meshBuffer.startsWith("[")) Serial.printf("[MESH RX] %s\n", meshBuffer.c_str());

          String toProcess, senderId;
          meshSplitSender(meshBuffer, senderId, toProcess);

          mesh_observeInbound(senderId, toProcess);

          if (toProcess.startsWith("TIME_SYNC_REQ:")) {
            processMeshTimeSyncWithDelay(senderId, toProcess, lastRxMicros);
          } else {
            if (toProcess.startsWith("PMKID_HARVEST:") ||
                toProcess.startsWith("EVILTWIN:") ||
                toProcess.startsWith("SAE_DOS:") ||
                toProcess.startsWith("DEAUTH_FLOOD:") ||
                toProcess.startsWith("BEACON_FORGE:") ||
                toProcess.startsWith("PMKID_FORGE:") ||
                toProcess.startsWith("EAPOL_BAIT:") ||
                toProcess.startsWith("PROBE_FLOOD:") ||
                toProcess.startsWith("PROBE_FLOOD_BEHAVE:") ||
                toProcess.startsWith("ASSOC_SLEEP:") ||
                toProcess.startsWith("RECON:") ||
                toProcess.startsWith("RID_CLAIM:") ||
                toProcess.startsWith("RID_RX:") ||
                toProcess.startsWith("BLOOM:") ||
                toProcess.startsWith("CHAN_ASSIGN:") ||
                toProcess.startsWith("FRAG:") ||
                toProcess.startsWith("IDHASH:") ||
                toProcess.startsWith("HSHK:") ||
                toProcess.startsWith("KRACK:") ||
                toProcess.startsWith("ATTACKER_HUNT:") ||
                toProcess.startsWith("PWNAGOTCHI:") ||
                toProcess.startsWith("KARMA_CAND:") ||
                toProcess.startsWith("KARMA_CONFIRMED:") ||
                toProcess.startsWith("BLE_ATTACK:") ||
                toProcess.startsWith("TOF_PING:") ||
                toProcess.startsWith("TOF_PONG:")) {
              detect_processMesh(senderId, toProcess);
            } else {
              processMeshMessage(meshBuffer);
            }
          }

          meshBuffer = "";
        }
      } else {
        meshBuffer += c;
        if (meshBuffer.length() > 1024) {
          meshBuffer = "";
        }
      }
    }
    vTaskDelay(pdMS_TO_TICKS(2));
  }
}

String macFmt6(const uint8_t *m) {
    char b[18];
    snprintf(b, sizeof(b), "%02X:%02X:%02X:%02X:%02X:%02X", 
             m[0], m[1], m[2], m[3], m[4], m[5]);
    return String(b);
}

bool parseMac6(const String &in, uint8_t out[6]) {
    String t;
    for (size_t i = 0; i < in.length(); ++i) {
        char c = in[i];
        if (isxdigit((int)c)) t += (char)toupper(c);
    }
    if (t.length() != 12) return false;
    for (int i = 0; i < 6; i++) {
        out[i] = (uint8_t)strtoul(t.substring(i * 2, i * 2 + 2).c_str(), nullptr, 16);
    }
    return true;
}

inline uint16_t u16(const uint8_t *p) { 
    return (uint16_t)p[0] | ((uint16_t)p[1] << 8); 
}

bool isZeroOrBroadcast(const uint8_t *mac) {
    bool all0 = true, allF = true;
    for (int i = 0; i < 6; i++) {
        if (mac[i] != 0x00) all0 = false;
        if (mac[i] != 0xFF) allF = false;
    }
    return all0 || allF;
}

void parseChannelsCSV(const String &csv) {
    CHANNELS.clear();
    if (csv.indexOf("..") >= 0) {
        int a = csv.substring(0, csv.indexOf("..")).toInt();
        int b = csv.substring(csv.indexOf("..") + 2).toInt();
        for (int ch = a; ch <= b; ch++) {
            if (ch >= 1 && ch <= 14) CHANNELS.push_back((uint8_t)ch);
        }
    } else {
        int start = 0;
        while (start < csv.length()) {
            int comma = csv.indexOf(',', start);
            if (comma < 0) comma = csv.length();
            int ch = csv.substring(start, comma).toInt();
            if (ch >= 1 && ch <= 14) CHANNELS.push_back((uint8_t)ch);
            start = comma + 1;
        }
    }
    if (CHANNELS.empty()) CHANNELS = {1,2,3,4,5,6,7,8,9,10,11};
}

void sendNodeIdUpdate() {
    float esp_temp = temperatureRead();
    String timestamp = getFormattedTimestamp();
    timestamp.replace(" ", "_");

    String nodeMsg = getNodeId() + ": Time:" + timestamp + " Temp:" + String(esp_temp, 1) + "C";

    if (gpsValid) {
        nodeMsg += " GPS:" + String(gpsLat, 6) + "," + String(gpsLon, 6);
    }
    
    if (!triangulationActive && hbEnabled) {
        Serial.println(nodeMsg);
        sendToSerial1(nodeMsg, true);
    }
}

// cppcheck-suppress unusedFunction // Arduino entry point, called by the framework
void setup() {
    delay(1000);
    Serial.begin(115200);
    delay(300);
    // Silence VFS error spam for known-absent optional files (e.g. /littlefs/oui_cat.bin)/gpio
    // esp_log_level_set("vfs_api", ESP_LOG_NONE);
    // esp_log_level_set("gpio", ESP_LOG_NONE);
    Serial.println("\n=== Antihunter [Headless] Boot ===");
    recordBootReason();

    if (psramFound()) {
        heap_caps_malloc_extmem_enable(16);
        Serial.printf("[MEM] PSRAM heap routing on (>16B -> PSRAM). psram_free=%u internal_free=%u\n",
                      (unsigned)ESP.getFreePsram(), (unsigned)heap_caps_get_free_size(MALLOC_CAP_INTERNAL));
    }

    delay(400);
    initializeHardware();
    delay(10);
    initializeDroneDetector();
    delay(20);
    initializeSD();
    logBootRecord();
    if (!wasCleanBoot()) loadResultsSnapshot();

    if (waitForInitialConfig()) {
        delay(1000);
    }

    delay(500);
    loadConfiguration();

    Serial.println("Waiting for mesh device stability...");
    delay(10000);

    initializeNetwork();
    ensureErasePSK();
    delay(500);
    initializeGPS();
    delay(1000);
    initializeRTC();
    delay(500);
    initializeVibrationSensor();
    initializeScanner();

    // Phase 1-3 detect module
    initializeDetect();
    initializeGpsPps(21);
    if (ahCreateResidentTask(detectTask, "DetectTask", 8192, NULL, 3, NULL, 1) != pdPASS)
        Serial.println("[BOOT] ERROR: DetectTask create failed - detection/sentinel inactive");
    {
        uint8_t selfMac[6];
        esp_wifi_get_mac(WIFI_IF_AP, selfMac);
        detect_setSelfApIdentity(selfMac, nullptr);
        Serial.printf("[SENTINEL] self-filter mac=%02X:%02X:%02X:%02X:%02X:%02X\n",
                      selfMac[0],selfMac[1],selfMac[2],selfMac[3],selfMac[4],selfMac[5]);
    }
#if AH_SENTINEL
    if (prefs.getBool("sentBoot", false)) {
        sentinel_setUserEnabled(true);
        Serial.println("[SENTINEL] Boot-enable ON (persisted) — starting sentinel");
    } else {
        Serial.println("[SENTINEL] OFF on boot (enable manually)");
    }
#else
    sentinel_setUserEnabled(false);
    Serial.println("[SENTINEL] Not built into this firmware (stable channel)");
#endif

    if (ahCreateTask(uartForwardTask, "UARTForwardTask", 4096, NULL, 2, NULL, 1) != pdPASS)
        Serial.println("[BOOT] ERROR: UARTForwardTask create failed - mesh RX bridge down");
    delay(120);

    Serial.println("===== ANTIHUNTER DIGINODE v1.0.4 STABLE HEADLESS BOOT COMPLETE =====");
    String currentNodeId = getNodeId();
    Serial.printf("NODE ID: %s\n", currentNodeId.c_str());
    Serial.println("RANDOMIZED MAC: (assigned when WiFi starts — sentinel/scan)");
    delay(2000);
}

// cppcheck-suppress unusedFunction // Arduino entry point, called by the framework
void loop() {
    static unsigned long lastSaveSend = 0;
    static unsigned long lastHbSend = 0;
    static unsigned long lastHeapCheck = 0;

    markUptimeAlive();

    // Handle serial time setting (always process, even in battery saver)
    if (Serial.available()) {
        String cmd = Serial.readStringUntil('\n');
        cmd.trim();
        if (cmd.startsWith("SETTIME:")) {
            time_t epoch = cmd.substring(8).toInt();
            if (epoch > 1609459200 && setRTCTimeFromEpoch(epoch)) {
                Serial.println("OK: RTC set");
            }
        } else if (cmd.length() > 0 && cmd.length() <= MAX_MESH_SIZE) {
            if (!cmd.startsWith("[")) Serial.printf("[USB CMD] %s\n", cmd.c_str());
            processMeshMessage(cmd);
        }
    }

    // Battery saver mode - minimal operations
    if (batterySaverEnabled) {

        // Send periodic heartbeats
        sendBatterySaverHeartbeat();

        // Reduced GPS polling - once per minute in battery saver mode
        static unsigned long lastGPSPollBatterySaver = 0;
        if (millis() - lastGPSPollBatterySaver > 60000) {
            updateGPSLocation();
            lastGPSPollBatterySaver = millis();
        }

        // Check vibration alerts (security feature, keep active)
        checkAndSendVibrationAlert();

        // Tamper detection still active
        if (tamperEraseActive) {
            checkTamperTimeout();
        }

        // Longer delay in battery saver mode for power saving
        vTaskDelay(pdMS_TO_TICKS(500));
        return;
    }

    // Normal operation mode
    static bool s_scanWasBusy = false;
    bool scanBusyNow = scanning.load() || workerTaskHandle || blueTeamTaskHandle || triangulationActive.load();
    if (s_scanWasBusy && !scanBusyNow) {
        sentinel_resumeAfterScan();
    }
    s_scanWasBusy = scanBusyNow;

    static bool s_bleUserWasBusy = false;
    bool bleUserNow = scanning.load() || workerTaskHandle || triangulationActive.load();
    if (s_bleUserWasBusy && !bleUserNow) {
        radioReleaseBLE();
    }
    s_bleUserWasBusy = bleUserNow;

    attack_responsePump();

    if (millis() - lastSaveSend > 600000 && !triangulationActive) {
        saveConfiguration();
        lastSaveSend = millis();
    }

    if (millis() - lastHbSend > hbInterval && !triangulationActive) {
        sendNodeIdUpdate();
        lastHbSend = millis();
    }

    if (millis() - lastRTCUpdate > 1000) {
        if (!triangulationActive) {
            updateRTCTime();
            disciplineRTCFromGPS();
        }
        updateGPSLocation();
        lastRTCUpdate = millis();
    }

    if (tamperEraseActive) {
        checkTamperTimeout();
    }

    processUSBToMesh();
    checkAndSendVibrationAlert();
    serviceVibrationAutoScan();
    scheduleTick();
    saveResultsSnapshot();

    if (millis() - lastHeapCheck > 30000) {
        uint32_t freeHeap = ESP.getFreeHeap();
        Serial.printf("[HEAP] int=%u largest=%u minever=%u psram=%u tasks=%u\n",
                      (unsigned)freeHeap,
                      (unsigned)heap_caps_get_largest_free_block(MALLOC_CAP_INTERNAL | MALLOC_CAP_8BIT),
                      (unsigned)heap_caps_get_minimum_free_size(MALLOC_CAP_INTERNAL),
                      (unsigned)heap_caps_get_free_size(MALLOC_CAP_SPIRAM),
                      (unsigned)uxTaskGetNumberOfTasks());
        if (freeHeap < 25000) {
            Serial.printf("[HEAP] LOW: %u bytes free\n", freeHeap);
        }
        lastHeapCheck = millis();
    }

    vTaskDelay(pdMS_TO_TICKS(100));
}

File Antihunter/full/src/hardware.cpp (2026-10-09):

#include "hardware.h"
#include "network.h"
#include "baseline.h"
#include "triangulation.h"
#include "detect.h"
#include "pcap.h"
#include <Arduino.h>
#include <errno.h>
#include <string.h>
#include <time.h>
#include <Preferences.h>
#include <ArduinoJson.h>
#include <WiFi.h>
#include <SPI.h>
#include <SD.h>
#include <TinyGPSPlus.h>
#include <HardwareSerial.h>
#include <Wire.h>
#include "esp_wifi.h"
#include "mbedtls/md.h"
#include "nvs_flash.h"
#include "esp_pm.h"
#include "esp_sleep.h"
#include "esp_bt.h"
#include "esp_system.h"
#include "esp_heap_caps.h"

extern "C" void *__wrap_nimble_platform_mem_malloc(size_t size) {
    return heap_caps_malloc_prefer(size, 2, MALLOC_CAP_SPIRAM | MALLOC_CAP_8BIT, MALLOC_CAP_INTERNAL | MALLOC_CAP_8BIT);
}

extern "C" void *__wrap_nimble_platform_mem_calloc(size_t n, size_t size) {
    return heap_caps_calloc_prefer(n, size, 2, MALLOC_CAP_SPIRAM | MALLOC_CAP_8BIT, MALLOC_CAP_INTERNAL | MALLOC_CAP_8BIT);
}

extern Preferences prefs;
extern ScanMode currentScanMode;
extern std::vector<uint8_t> CHANNELS;
extern void disciplineRTCFromGPS();

// Preferences::getString() log_e()s on a missing key; gate it so optional keys stay quiet
String prefsGetString(const char *key, const String &defaultValue) {
    if (!prefs.isKey(key)) return defaultValue;
    return prefs.getString(key, defaultValue);
}

// GPS
TinyGPSPlus gps;
HardwareSerial GPS(2);
bool sdAvailable = false;
String lastGPSData = "No GPS data";
float gpsLat = 0.0, gpsLon = 0.0;
static const uint32_t GPS_FIX_MAX_AGE_MS = 20000;
std::atomic<bool> gpsValid{false};
SemaphoreHandle_t gpsMutex = nullptr;
extern bool hbEnabled;
extern uint32_t hbInterval;

// RTC
RTC_DS3231 rtc;
bool rtcAvailable = false;
bool rtcSynced = false;
time_t lastRTCSync = 0;
SemaphoreHandle_t rtcMutex = nullptr;
String rtcTimeString = "RTC not initialized";

// Vibration Sensor
volatile bool vibrationDetected = false;
unsigned long lastVibrationTime = 0;
unsigned long lastVibrationAlert = 0;
const unsigned long VIBRATION_ALERT_INTERVAL = 3000; 

bool vibAutoScanEnabled = false;
uint8_t vibAutoScanMode = 0;
uint16_t vibAutoScanDuration = 60;
uint32_t vibAutoScanCooldownMs = 60000;
volatile bool vibAutoScanPending = false;
bool vibAutoScanPreempt = false;
unsigned long lastVibAutoScanFire = 0;

// Diagnostics & Config
extern std::atomic<bool> scanning;
extern std::atomic<int> totalHits;
extern std::atomic<uint32_t> framesSeen;
extern std::atomic<uint32_t> bleFramesSeen;
extern UniqueMacsSet uniqueMacs;
extern uint32_t lastScanSecs;
extern bool lastScanForever;
extern uint32_t g_curScanEndMs;
extern bool g_curScanForever;
extern String macFmt6(const uint8_t *m);
extern size_t getTargetCount();
extern TaskHandle_t blueTeamTaskHandle;
extern TaskHandle_t workerTaskHandle;
extern std::atomic<bool> triangulationActive;
uint32_t SafeSD::lastCheckTime = 0;
bool SafeSD::lastCheckResult = false;
unsigned long lastSaveTime = 0;
const unsigned long SAVE_DEBOUNCE_MS = 2000;

// Tamper Detection Erase
uint32_t setupDelay = 120000;  // 2 minutes default
uint32_t setupStartTime = 0;
bool inSetupMode = false;
bool tamperEraseActive = false;
uint32_t tamperSequenceStart = 0;
String tamperAuthToken = "";
String erasePSK = "";
bool autoEraseEnabled = false;
uint32_t autoEraseDelay = 30000;
uint32_t autoEraseCooldown = 300000;  // 5 minutes default
static uint32_t lastAutoEraseAttempt = 0;
uint32_t vibrationsRequired = 3;
uint32_t detectionWindow = 20000;
String eraseStatus = "INACTIVE";
bool eraseInProgress = false;

// Battery Saver Mode
bool batterySaverEnabled = false;
uint32_t batterySaverHeartbeatInterval = 300000;  // 5 minutes default
uint32_t lastBatterySaverHeartbeat = 0;

// SD & HW Init

uint32_t SafeSD::sdMountFailures = 0;
uint32_t SafeSD::sdWriteRetries = 0;
uint32_t SafeSD::lastMountLogMs = 0;
bool sdAutoRepair = false;
static uint32_t sdMountedHz = SD_SPI_HZ;

void setSdAutoRepair(bool on) {
    sdAutoRepair = on;
    Preferences p;
    if (p.begin("sd", false)) { p.putBool("autorepair", on); p.end(); }
}

volatile bool sdRepairPending = false;

void serviceSdRepair() {
    if (!sdRepairPending) return;
    sdRepairPending = false;
    const bool prev = sdAutoRepair;
    sdAutoRepair = true;
    const bool ok = sdMountOrRepair();
    sdAutoRepair = prev;
    sdAvailable = ok;
    SafeSD::forceRecheck();
    Serial.printf("[SD] repair from web UI: %s\n", ok ? "mounted" : "failed");
}

void loadSdAutoRepair() {
    Preferences p;
    if (p.begin("sd", true)) { sdAutoRepair = p.getBool("autorepair", false); p.end(); }
}
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

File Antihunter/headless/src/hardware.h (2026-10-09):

#pragma once
#include "scanner.h"
#include "network.h"
#include "main.h"
#include <RTClib.h>
#include <TinyGPSPlus.h>
#include <FS.h>
#include <SD.h>

#ifndef COUNTRY
#define COUNTRY "US"
#endif
#ifndef MESH_RX_PIN
#define MESH_RX_PIN 4    // TO MESH PIN 9/19 T114/V3
#endif
#ifndef MESH_TX_PIN
#define MESH_TX_PIN 5    // TO MESH PIN 10/20 T114/V3
#endif
#ifndef VIBRATION_PIN
#define VIBRATION_PIN 2  // TO SW-420 D0
#endif

// SD Card (SPI)
#define SD_CS_PIN   1    // CS on D0
#define SD_CLK_PIN  7    // CLK on D8
#define SD_MISO_PIN 8    // MISO on D9
#define SD_MOSI_PIN 9    // MOSI on D10
#ifndef SD_SPI_HZ
#define SD_SPI_HZ          16000000
#endif
#define SD_SPI_HZ_SAFE     4000000
#define SD_SPI_HZ_FALLBACK 400000

// GPS (UART)
#define GPS_RX_PIN 44   // GPS RX
#define GPS_TX_PIN 43   // GPS TX

// RTC (I2C)
#define RTC_SDA_PIN 3    // RTC SDA
#define RTC_SCL_PIN 6    // RTC SCL

// Configuration constants
#define CONFIG_FILE "/config.json"
#define CONFIG_TMP_FILE "/config.json.tmp"
#define CONFIG_BAK_FILE "/config.json.bak"
#define CONFIG_BAD_FILE "/config.json.bad"
#define MAX_CONFIG_SIZE 4096

class SafeSD {
private:
    static uint32_t lastCheckTime;
    static bool lastCheckResult;
    static const uint32_t CHECK_INTERVAL_MS = 1000;
    static const uint32_t MOUNT_LOG_INTERVAL_MS = 60000;
    static uint32_t sdMountFailures;
    static uint32_t sdWriteRetries;
    static uint32_t lastMountLogMs;
    static bool checkAvailability();

public:
    static bool isAvailable();
    static fs::File open(const char* path, const char* mode = FILE_READ);
    static bool exists(const char* path);
    static bool remove(const char* path);
    static bool rename(const char* from, const char* to);
    static bool mkdir(const char* path);
    static bool rmdir(const char* path);
    static size_t write(fs::File& file, const uint8_t* data, size_t len);
    static size_t read(fs::File& file, uint8_t* data, size_t len);
    static bool flush(fs::File& file);
    static void forceRecheck();
    static uint32_t mountFailureCount();
    static uint32_t writeRetryCount();
};

// Print wrapper so print/println/printf/serializeJson all go through the retrying write
class SdWriter : public Print {
public:
    explicit SdWriter(fs::File &f) : _f(f) {}
    size_t write(uint8_t c) override { return SafeSD::write(_f, &c, 1); }
    size_t write(const uint8_t *b, size_t n) override { return SafeSD::write(_f, b, n); }
private:
    fs::File &_f;
};

String jsonEscape(const String &in);

// RTC Status
extern RTC_DS3231 rtc;
extern bool rtcAvailable;
extern bool rtcSynced;
extern time_t lastRTCSync;
extern String rtcTimeString;
extern SemaphoreHandle_t rtcMutex;

bool waitForInitialConfig();
void initializeRTC();
void syncRTCFromGPS();
void updateRTCTime();
String getFormattedTimestamp();
time_t getRTCEpoch();
uint32_t getEventTimestamp();
bool setRTCTimeFromEpoch(time_t epoch);
void updateLocalTZFromGPS();
time_t nodeLocalToEpoch(int year, int month, int day, int hour, int minute);
time_t nodeLocalAddDays(time_t epoch, int days);
String nodeLocalString(time_t epoch);

// Sensors and GPS
extern bool sdAvailable;
extern bool sdAutoRepair;
bool sdMountOrRepair();
void setSdAutoRepair(bool on);
void loadSdAutoRepair();
extern std::atomic<bool> gpsValid;
extern float gpsLat, gpsLon;
extern SemaphoreHandle_t gpsMutex;
extern String lastGPSData;
extern HardwareSerial GPS;
extern TinyGPSPlus gps;
extern volatile bool vibrationDetected;
extern unsigned long lastVibrationTime;
extern unsigned long lastVibrationAlert;
extern bool vibAutoScanEnabled;
extern uint8_t vibAutoScanMode;
extern uint16_t vibAutoScanDuration;
extern uint32_t vibAutoScanCooldownMs;
extern volatile bool vibAutoScanPending;
extern unsigned long lastVibAutoScanFire;

void initializeHardware();
void initializeVibrationSensor();
void initializeSD();
void initializeGPS();

void updateSetupModeStatus();
void checkAndSendVibrationAlert();
void updateGPSLocation();
void sendStartupStatus();
void sendGPSLockStatus(bool locked);
void parseChannelsCSV(const String &csv);
void saveTargetsList(const String &txt);
String prefsGetString(const char *key, const String &defaultValue);
extern unsigned long lastSaveTime;
void saveConfiguration();
void loadConfiguration();
void syncSettingsToNVS();
void logToSD(const String &data);
void logEventToSD(const char* path, const String& jsonLine);

#define RESULTS_SNAPSHOT_FILE "/last_results.txt"
#define RESULTS_SNAPSHOT_TMP "/last_results.tmp"
#define RESULTS_SNAPSHOT_INTERVAL_MS 60000
#define RESULTS_SNAPSHOT_MAX_BYTES 16384

void recordBootReason();
void logBootRecord();
void markUptimeAlive();
const char *getResetReasonText();
uint32_t getPrevBootUptimeSec();
bool prevBootUptimeKnown();
bool wasCleanBoot();
bool resultsWereRestored();
void saveResultsSnapshot(bool force = false);
void loadResultsSnapshot();
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

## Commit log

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2025-10-23 Refactors web UI
    Updates the web UI's styling for a cleaner and more responsive design.
    This includes adjustments to font sizes, spacing, colors, and layout for better readability and user experience across different devices. It also updates styling for the scan results to be easier to parse.
    Removes the collapsable card styling as it is no longer needed.
    [network.cpp]
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2025-10-23 add more correlation to MAC de-randomization
    - need to fix device type ID in results
    [randomization.cpp, scanner.cpp]
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2025-10-24 de-randomization differentiation & timing
    fix the timing constants and make global MAC leak detection work
    [randomization.cpp]
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2025-10-24 fix a baseline scan crash condition
    - BLE wasn't being checked for validity before use
    - Cleanup sequence wasn't properly ordered
    - Now everything is defensive with null checks
    [baseline.cpp]
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2025-10-24 webUI fixes
    Added content comparison check: if (currentText !== resultsText) - only updates DOM if results actually changed
    Removed the condition (lastScanningState && !isScanning) from the inner if - now continuously updates during scanning
    Added separate handling for scan-stop event to do final refresh
    Added error logging for debugging
    Results now update every 2 seconds during active scanning without unnecessary DOM manipulation
    [network.cpp]
2025-10-24 fix sorting making results disappear
    Only executes if currentSort is not 'default'
    Iterates through ALL children of resultsElement
    Separates sortable items from preserved elements based on element characteristics
    Clears innerHTML only once
    Restores preserved elements first (headers, summaries)
    Appends sorted items after preserved elements
    Maintains all DOM elements and their event listeners
    [network.cpp]
2025-10-25 adds terminal websocket, mesh interval config
    fixes device scan dynamic updates and other things
    - terminal commented out until more is broadcast, have to decide what to spit out
    [drone_detector.cpp, hardware.cpp, hardware.h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]
2025-10-25 Fix Phase 2 baseline anomaly detection forgetting Phase 1 devices
    Root cause: Phase 2 only checked RAM cache (400 max), missing devices
    evicted to SD in Phase 1. Added LRU cache (200 entries) for SD lookups.
    isDeviceInBaseline() now checks RAM→LRU→SD. Without SD, raises limit
    to 1500 devices.
    [baseline.cpp]
2025-10-25 respect rf settings in baseline scan
    fix frames not counted in phase 2
    [baseline.cpp]
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2025-10-25 Improves baseline scan and UI feedback.
    Adds a stop mechanism to the baseline scan task, ensuring it can be terminated gracefully.
    This also fixes an issue where the UI color for anomalies was not visible.
    Additionally, reduces diagnostic cache time and channel hop time for efficiency.
    [baseline.cpp, hardware.cpp, network.cpp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]
2025-10-25 Enhances UI and Triangulation Results Display
    Adds a "Reset All" button for randomization detection.
    Improves the display of triangulation results on the web interface,
    including detailed node reports, GPS validation, and trilateration
    estimates with confidence levels and uncertainty.
    Fixes a starvation issue in the triangulation task by adding a tiny yield
    to prevent blocking the async TCP.
    [network.cpp, triangulation.cpp]
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2025-10-25 [fix] log changed only to SD baseline
    track modified devices, only flushing those that have changed
    [baseline.cpp]
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2025-10-28 Add SafeSD wrapper with RAM log buffer and NVS config sync
    - Add SafeSD class wrapper for all SD operations with availability checking
    - Implement 100-entry circular RAM buffer for logs when SD unavailable
    - Add automatic log flush to SD when card becomes available
    - Add NVS flash config sync fallback when SD unavailable during saveConfiguration()
    - Replace all direct SD.* calls with SafeSD::* throughout codebase
    - Fix File type to fs::File for proper namespace resolution
    - Add SafeSD::read() wrapper to detect partial reads
    - Prevent crashes from SD card removal during operation"
    [baseline.cpp, hardware.cpp, hardware.h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]
2025-10-28 Add SafeSD wrapper with log buffering and NVS config sync
    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
    [baseline.cpp, hardware.cpp, hardware.h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]
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2025-10-28 Improves mesh network transmission reliability
    Addresses issues with dropped messages in the mesh network by
    implementing rate limiting and message queuing.
    This change introduces a token bucket rate limiter to `sendToSerial1`
    to prevent flooding the serial interface, which was causing some
    messages to be lost. Also, adds delays and flushing to ensure all
    messages have a chance to be transmitted, especially at the end of
    each scan cycle.
    [baseline.cpp, drone_detector.cpp, randomization.cpp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]
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2025-10-29 fix details element arrow animation
    Enhances the visual feedback of the details element by adding a rotation animation to the arrow icon when the element is opened.
    This provides a clearer indication of the element's state change to the user.
    [network.cpp]
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2025-10-29 Unify configurable WiFi channels
    Adds the ability to configure the WiFi channels used for scanning.
    This allows users to specify a range or list of channels
    to scan, improving efficiency and reducing noise by
    focusing on relevant frequencies.
    [hardware.cpp, network.cpp, scanner.cpp]
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2025-11-04 fix: BLE RSSI not averaging in sniffer
    stuck at -128 for device scan from case mismatch
    [scanner.cpp]
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2025-11-08 [persistance] write to NVS and SD
    Save prefs to NVS and SD, with NVS as primary backup if SD fails.
    [hardware.cpp, hardware.h, network.cpp]
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2025-11-16 fix: missing calls from node name enforcement
    - bad merge from the node naming commit
    [hardware.cpp]
2025-11-16 mod: revert test node naming enforcement
    - limits to any alphanumeric ID 2-5 chars
    - will autocorrect if loaded from sd prefs
    [hardware.cpp, network.cpp]
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2025-11-19 fix: baseline fetch in full FW
    When not in baseline mode, the function returns immediately without making any fetch requests
    The polling interval checks the detection mode before attempting to call updateBaselineStatus()
    No fetch errors will occur because no requests are made when baseline is not active
    Console logging is eliminated entirely for non-baseline modes
    [network.cpp]
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2025-11-19 enhance: ensure proper async calls
    - Wrapped error-prone operations in try/catch blocks
    - Added await for dependent async operations (like updateAutoEraseStatus() and updateBaselineStatus())
    [network.cpp]
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2025-11-19 fix: rssi slider and preset overlap
    - uses slider as single source of truth
    - show feedback when rf settings saved of whole config
    [network.cpp]
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2025-11-19 fix: triangulation delegation
    - AP FW was not using initiator, adds target to command def
    [network.cpp]
2025-11-19 fix: NVS initialization and configuration sync issues
    - Add explicit nvs_flash_init() with corruption detection before prefs.begin()
    - Initialize all NVS string keys on first boot to prevent nvs_get_str_len errors
    - Add syncSettingsToNVS() call in saveConfiguration() to actually write to NVS
    - Update syncSettingsToNVS() to include RF config parameters and channels
    - Simplify flash script to always erase and flash bootloader+partitions+app
    - Remove -e flag from script, making full erase the default behavior
    - Require bootloader.bin and partitions.bin for all flashing operations
    Fixes issues where:
    - Users flashing with -e saw "nvs_get_str_len fail maclist not found" errors
    - saveConfiguratio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
    [hardware.cpp]
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2025-11-20 chore: NVS init check robustness
    - field ready as to avoid potential reset loop issues
    [hardware.cpp]
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2025-11-22 chore: unify triangulate mesh command to @ALL
    - fix slot timing based on node count tests
    [scanner.cpp, triangulation.cpp, triangulation.h]
2025-11-22 chore: webUI performance fixes
    Critical Fixes (These were causing the toast delay):
    Removed blocking delay(100) calls - network.cpp:3273 and network.cpp:3499
    These were blocking the AsyncWebServer thread and preventing fast response times
    Impact: ~100-200ms faster response when clicking Start button
    Fixed cache timing mismatch - network.cpp:3164
    Changed tick interval from 2s to 3s to align with cache
    Prevents unnecessary recalculation of diagnostics
    Impact: Eliminates 50% of cache misses
    Backend Optimizations:
    Optimized getDiagnostics() - hardware.cpp:752-868
    Increased cache from 3s to 5s
    Added separate 10s cache for temperature readings
    Impact: Reduces hardware sensor reads by 66%
    Added pag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
    [drone_detector.cpp, hardware.cpp, network.cpp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]
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2025-11-23 fix: consolidate FINAL triang message
    fix a few race conds along the path
    [network.cpp]
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2025-11-24 Improves headless sniffer cache and BLE cleanup
    Optimizes the sniffer cache to prevent memory issues by limiting cache size and adding a TTL.
    Ensures BLE scans are properly stopped when the list scan task ends, resolving a cleanup issue.
    Adds interval variable to control how often the sniffer scan runs.
    [scanner.cpp]
2025-11-25 chore: enforce MAX_MESH_SIZE globally
    - Changed all length() < MAX_MESH_SIZE to length() <= MAX_MESH_SIZE
    - Fixed dangerous snprintf pattern: Removed redundant null terminator assignment: mesh_msg[msg_len] = '\0';
    Changed buffer size check from msg_len < MAX_MESH_SIZE to msg_len <= sizeof(mesh_msg) - 1
    Changed snprintf size from sizeof(mesh_msg) - 1 to sizeof(mesh_msg) (proper usage)
    [baseline.cpp, drone_detector.cpp, network.cpp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]
2025-11-25 add ERASE_REQUEST
    - token request was not available outside AP fw
    - fix BASELINE_STATUS returning active, missing logic
    - update docs
    [network.cpp]
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2025-11-27 NVS autofix/restore changes
    - Tries to auto-repair common corruption (trailing commas, missing })
    - If can't parse after repair:
    - Backs up to config.json.bak (preserves your good SD data)
    - Removes corrupt config.json
    - Doesnt call saveConfiguration() (won't overwrite with bad NVS defaults)
    [hardware.cpp]
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2025-12-01 refactor: Remove orphaned secure erase API endpoints
    - Remove /secure/destruct endpoint (unused, duplicated by /erase/request)
    - Remove /secure/generate-token endpoint (unused, generated tokens on wrong device)
    - Update README API documentation to reflect removed endpoints
    - Clarify /erase/request is for local device only
    - Update security documentation to specify tokens are device-generated via ERASE_REQUEST
    [network.cpp]
2025-12-01 Fix ERASE_REQUEST confusion
    Problem: ERASE_REQUEST was starting the erase countdown immediately, which meant users had to race against the timer after getting the token. This was confusing and dangerous. Solution:
    - ERASE_REQUEST now ONLY generates and returns the token (no countdown)
    - Token is valid for 5 minutes
    - ERASE_FORCE validates the token and executes the erase immediately
    Much clearer and safer workflow
    Changes made:
    - Full firmware - Modified ERASE_REQUEST handler to NOT start countdown
    - Headless firmware - Same fix applied
    New workflow:
    Step 1: @AH02 ERASE_REQUEST
    → Device responds: "AH02: ERASE_TOKEN:AH_12345678... Expires:300s"
    → No countdown started, ju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
    [network.cpp]
2025-12-04 Addresses potential issues in file and identity handling
    Ensures proper file closing in `deleteAllFiles` to prevent resource leaks.
    Adds null termination to `linkedIdentityId` after copying, preventing potential buffer overflows.
    Adds error handling to calibration task creation to prevent memory leaks when the task fails to create.
    These changes improve the overall robustness, security and reliability of the system.
    [hardware.cpp, randomization.cpp, triangulation.cpp]
2025-12-04 Addresses potential issues in file and identity handling
    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
    [hardware.cpp, randomization.cpp, triangulation.cpp]
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2025-12-05 Fix: autoerase in AP FW
    - fix bug where it would not enable via webUI
    - fix POST data to FormData not urlencoded
    - fixed countdown timer calculation using server's time scale, add timer for setup mode countdown
    [network.cpp]
2025-12-05 WebUI: sd card logs and add more diag feedback
    - fix when under 1kb showing 0 in UI
    - add ui for capacity/used
    - show last vibration in webUI
    [hardware.cpp, network.cpp]
2025-12-12 Fix: triangulation mesh final/complete messages
    when not using AP the final messages were not being sent
    [network.cpp, triangulation.cpp, triangulation.h]
2025-12-14 TDoA finalization - clock discipline
    Added to ClockDiscipline struct :
    When RTC gets GPS time, calculate: epochMicros - bootMicros = offset
    Store this offset for fast lookups
    Recalibrate after any large RTC adjustment
    True Unix timestamps with microsecond precision
    Synchronized across all nodes (all using GPS-disciplined RTC)
    Fast - no RTC mutex lock on every timestamp
    Drift-corrected - applies clock drift compensation
    [triangulation.cpp, triangulation.h]
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2026-01-21 fix: serial and mesh token slots
    Added Serial1.flush() after every message (not just priority)
    Added 50ms inter-message delay to prevent UART collisions
    scanner.cpp and scanner.cpp:
    Added new slot management functions (lines 86-132):
    SLOT_GUARD_MS = 200 - Guard time constant
    INTER_MESSAGE_DELAY_MS = 50 - Inter-message delay constant
    getTimeRemainingInSlot() - Returns ms remaining in current slot
    canSendInSlot() - Returns true only if >200ms remaining in slot
    Updated batch transmission loops:
    Changed isMyScanMeshSlot() checks to canSendInSlot()
    Updated slot waiting to use the guard-aware function
    Removed excessive delay(500) calls, using periodic token refill instead
    Added helper lambda wa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
    [network.cpp, scanner.cpp]
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2026-01-25 fix: dual-radio device triangulation
    - would find it as BLE and WiFi and count both, leading to incorrect triangulation results
    - edge case, as only some will use a singular randomized MAC for both radios
    [network.cpp, scanner.cpp]
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2026-02-03 mod: node RTC sync
    - fix drift not being corrected after initial call
    - remove test TDoA code
    [network.cpp, scanner.cpp, triangulation.cpp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]
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2026-03-02 fix: AP slow results and states
    - fixes 5 places that were slowing down results and state logic for webUI. The HW was always fast, i just wrote some bad code.
    - decreases time we wait for new data, which may impact battery- TODO in batt saver mode, or use the headless fw
    [hardware.cpp, network.cpp, scanner.cpp]
2026-03-02 fix: battery saver mode in AP FW
    - initial batt saver, doesn't do much yet
    [hardware.cpp, network.cpp]
2026-03-04 fix: stop behavior blocking AP
    - the wait for device to send mesh backlog was blocking AP
    - fixes a condition in headless where the radio wasn't being closed properly on scan stop
    [network.cpp, scanner.cpp]
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2026-03-18 fix: correct uartForwardTask mutex and sniffer_cb length guard
    - uartForwardTask could give a mutex it didn't hold if the re-acquire timed out. Replaced with read-all-under-mutex into a chunk buffer.
    - sniffer_cb length guard moved before first payload access; was firing after detectDeauthFrame already ran on truncated frames.
    - Applies to full and headless variants
    Bug submitted by @nameearly
    [main.cpp, scanner.cpp]
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2026-03-30 feat: randomization SSID/device/RSSI/CID tracking
    - fix some scan logic preventing quick results in webUI
    - add more data to the results
    [randomization.cpp]
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2026-03-30 feat: new device scan, randomization tracer webUI data
    - added channel sorting
    - marks leaked MAC (anchor) with SSIDs and BLE names/CIDs
    [network.cpp, scanner.cpp]
2026-03-30 feat: new device scan, randomization tracer webUI data
    - fixes results not including names until completion
    - better icons for results header
    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
    [network.cpp, scanner.cpp]
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2026-03-31 fix: baseline false positive protections
    - Bug 1 fixed: history.wasPresent = true now set before return in the new-device anomaly block — device will never fire twice
    - Bug 3 fixed: Sightings guard added — device must be seen 2+ times within a 60s window before "new device" anomaly fires; single probe frames from passing devices are ignored
    - Bug 2 fixed (full only): antihunter::lastResults written every 2s in both phase 1 and phase 2 loops via getBaselineResults() — results now appear in the #r div automatically via tick()
    Phase 1 getBaselineResults() now includes Elapsed: Xs / Ys line
    full/src/network.cpp
    - Bug 4 ditched results button (linked to plain-text /baseline-results page,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
    [baseline.cpp, network.cpp]
2026-04-01 feat: baseline scan results panel
    - appendCacheDeviceLines() helper eliminates the duplicate 14-line loop; both phases call it
    - reserve() before all loops — eliminates repeated heap realloc on ESP32
    - baselineResultsDirty flag —
    getBaselineResults() only rebuilt when cache or anomalies actually changed
    - nextResultsUpdate += 2000 — no more timer drift under load
    - sightings initialized to 0 — sightings guard now actually requires 2 separate checkForAnomalies calls before firing (was firing on first call due to init=1 then immediate increment to 2)
    network.cpp:
    - rssiColorFor() at module scope — removes 3 duplicate inline threshold blocks across parseBaselineResults and parse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
    [baseline.cpp, network.cpp]
2026-04-13 fixes: bughunt, 17 addressed
    - Bugs 1/5 — detectDeauthFrame now queues via xQueueSendFromISR; attack classification + side effects moved to blueTeamTask
    - Bug 2 — processDronePacket no longer called from ISR; droneFrameQueue consumed in droneDetectorTask
    - Bug 3 — correlateAuthFrameToRandomizedSession no longer acquires std::mutex from ISR; authFrameQueue consumed in randomizationDetectionTask
    - Bug 4 — pBLEScan = nullptr before BLEDevice::deinit in snifferScanTask
    High:
    - Bug 6 — cleanupBaselineMemory now removes from lruMap/lruList before erasing from baselineCache
    - Bug 7 — loadBaselineFromSD now populates lruList/lruMap on each device loaded
    - Bug 8 — Shadowed BLE_SC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
    [baseline.cpp, drone_detector.cpp, hardware.cpp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]
2026-04-13 fix: baseline scan results updates, network drop
    - clear out old results when any new is started
    [baseline.cpp, drone_detector.cpp, network.cpp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]
2026-04-13 fix: baseline anomaly updates in results
    - was showing number in scan window, results had latency
    [baseline.cpp]
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2026-04-13 Revert layout: webUI overhaul
    - not ideal, reverted for now until have time for frontend dev
    [network.cpp]
2026-04-13 fix: false positives from NimBLE bug
    - NimBLE periodically returns -8 dBm which was swinging the baseline results
    - guards over a dozen getRSSI calls
    [baseline.cpp, randomization.cpp, scanner.cpp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]
2026-04-14 webUI: new layout, baseline mode fixes
    - fix devices not appearing with phases card
    - make list sortable during all phases
    - fix garbage RSSI values, unsigned promotion bug
    [baseline.cpp, network.cpp]
2026-04-14 baseline scan: fixes & webUI improvements
    - revamp the baseline scan for the new webUI
    - clear out old data on new scans
    - guard radio-busy on headless fw
    [baseline.cpp, network.cpp]
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2026-04-25 Add VIBRATION_ON / VIBRATION_OFF mesh commands
    Vibration TEXTMSG broadcasts had no runtime toggle, so a sensor in a
    moving / vibrating environment flooded the mesh. Mirror the existing
    hbEnabled pattern: a vibrationEnabled bool gating the two TX call sites,
    persisted in NVS under "vibEnabled", controlled by VIBRATION_ON and
    VIBRATION_OFF mesh commands. VIBRATION_STATUS reply is extended to
    include the enabled state ("ENABLED"/"DISABLED" + last vibration age).
    Default is true so devices that pick up the new firmware keep current
    behaviour — operators opt OUT, not IN.
    Detection logic and the local "[VIBRATION] Sending mesh alert: ..."
    USB debug log run unconditionally; only the Serial1 TX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
    [hardware.cpp, network.cpp, network.h]
2026-04-25 fix: complete vibration toggle persistence for both firmware variants
    - Add vibEnabled to SD JSON config write (saveConfiguration) in both full
    and headless so SD backup/restore preserves vibration broadcast state
    - Add vibEnabled to SD JSON config load (loadConfiguration) in both full
    and headless so existing config.json files pick up the setting on boot
    - Remove redundant prefs.putBool from full firmware VIBRATION_ON/OFF
    handlers; saveConfiguration via syncSettingsToNVS already covers it
    (lastSaveTime=0 defeats the 2s debounce)
    - Keep prefs.putBool in headless VIBRATION_ON/OFF and add
    saveConfiguration call alongside it; lastSaveTime is static in
    hardware.cpp so headless needs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
    [hardware.cpp, network.cpp]
2026-04-25 fix: add USB log to setup-mode vibration path
    The first sendToSerial1 site (setup-mode detection) had no
    Serial.printf before the vibrationEnabled gate. When broadcasts
    are disabled, setup-mode vibrations produced zero USB output.
    The issue spec requires USB logging unconditionally at all sites.
    [hardware.cpp]
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2026-04-27 fix: RTC being killed by health check
    fix RTC permanently killed by transient I2C failure. Replaced the destructive rtc.begin() health check with a lightweight I2C read test. If it fails
    [hardware.cpp]
2026-04-27 layout: webUI overhaul, new radio status header
    active state shows blue-pulsing scan type name
    - lots of fixes, 100% less ugly
    [network.cpp]
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2026-04-28 fix: harden PROBE_START +ALL flag from PR #27
    Review of PR #27 (karamble/feat/probe-broadcast-all) found four
    bugs and one missing UI integration. All fixed here.
    Fixes applied:
    - Case-insensitive token parsing: both FOREVER and +ALL now use
    toUpperCase() in full and headless, resolving a divergence where
    headless accepted "forever" but full did not, and neither accepted
    "+all". Mesh protocols should not be case-sensitive.
    - Prevent accidental forever-mode: secs < 1 now clamps to 1 when
    FOREVER flag is not set. Previously secs=0 (from explicit zero,
    malformed input, or toInt() parse failure) silently activated
    forever-mode — dangerous when combined with +ALL.
    - Defensive pr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
    [network.cpp, scanner.cpp]
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2026-05-22 chore: purge BLE attack sniffers, no impact to AH
    - also fixes the coexistence issue
    [detect.cpp, main.cpp, network.cpp]
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2026-05-23 feat: sentinel analysis view
    - use timestamps not simple runtime val
    - rip out the section from data tab, replace the useless details tab in sentinel
    [detect.cpp, main.cpp, network.cpp]
2026-05-23 mod: WPA3 auth, Arduino 2->3.x, PSRAM fix
    - fix gps status on boot
    - platformio.ini — platform bump to pioarduino 55.x (enables WPA3 + PSRAM)
    - hardware.cpp ×2 — GPS HDOP/sat fix
    - main.cpp ×2 — PSRAM routing + heap threshold
    - network.cpp — AP WPA2/WPA3 mixed
    [hardware.cpp, main.cpp, network.cpp]
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
